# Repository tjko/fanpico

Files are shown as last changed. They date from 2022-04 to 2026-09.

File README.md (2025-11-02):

# Fanpico: Programmable PWM (PC) Fan Controller




<p><a href="https://certification.oshwa.org/us002599.html" title="Open Source Hardware Association Certificate">[OSHW] US002599 | Certified open source hardware | oshwa.org/cert</a></p>

Fanpico is a smart PWM (PC) fan controller based around [Raspberry Pi Pico](https://www.raspberrypi.com/documentation/microcontrollers/raspberry-pi-pico.html) (RP2040 MCU). Fanpico operates as standalone controller that can be configured and left running. It does not require any drivers and doesn't care what OS is being used. FanPico is an Open-source hardware (OSHW) project.

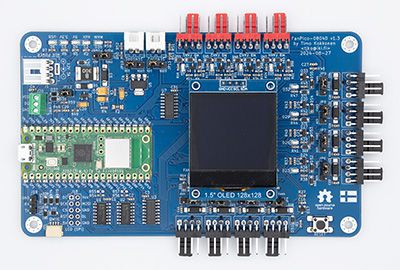
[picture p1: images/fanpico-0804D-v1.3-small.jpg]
FanPico-0804D

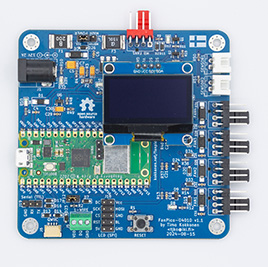
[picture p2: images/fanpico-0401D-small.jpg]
FanPico-0401D


## What is it for?
* Fanpico is for customizing fan "curves" to fine tune how your motherboard controlled fans run.
* Fine tuning fan speeds to easily balance airflow.
* Controlling fan based on temperature sensor input.
* Monitoring fan speeds and behaviour as well as monitoring what exactly motherboard is doing.
* Fanpico works also as standalong controller for other things than a PC, it's been used  controlling fans on 3D printers and on enclosed network equipment racks, etc..

## Features
* Controls up to 8 fans.
* Connect up to 4 motherboard fan outputs.
* Connect up to 2 remote temperature probes (plus onboard "ambient" temperature sensor).
* Support for [1-Wire Temperature sensors](https://github.com/tjko/fanpico/wiki/1%E2%80%90Wire-Temperature-Sensors-with-FanPico) (up to 8 sensors)
* Support for [I2C Temperature sensors](https://github.com/tjko/fanpico/wiki/I2C-Temperature-Sensors-with-FanPico) (up to 8 sensors)
* [OLED](https://github.com/tjko/fanpico/wiki/OLED-(I2C)-Display-Support) and [LCD](https://github.com/tjko/fanpico/wiki/LCD-(SPI)-Panel-Connection) display support (boards where model name ends with "D").
* Can be powered from motherboard fan outputs or using auxiliary power connector (4-Pin Floppy or DC Barrel jack connector).
* Ability to define custom fan "curves" for each fan.
* Ability to provide custom tachometer (fan RPM) output signal back to motherboard.
* Support for Locked Rotor (Alarm) signal fans (allows using regular tachometer fans with system expecting Locked Rotor Alarm fans and vice versa).
* Control fans from any motherboard PWM signal or from temperature sensors.
* OS Independent, no drivers or software needed.
* Configuration stored on the device itself (in the flash memory).
* SCPI "like" programming interface (see [Command Reference](commands.md))
* Monitor each fan and motherboard output signals as well as temperatures.
* [WiFi support](https://github.com/tjko/fanpico/wiki/FanPico-Network-Interface) if opting to mount Pico W on the board.
  * [HTTP server](https://github.com/tjko/fanpico/wiki/Fanpico-HTTP-Server) with TLS (HTTPS) support.
  * [MQTT client](https://github.com/tjko/fanpico/wiki/FanPico-MQTT-Tutorial) with TLS support for logging data and to receive commands.
  * [Home Assistant](https://github.com/tjko/fanpico/wiki/FanPico-Home-Assistant-(MQTT-Discovery)-Support) support using MQTT Discovery feature.
  * Telnet server for configuration and monitoring.
  * [SSH server](https://github.com/tjko/fanpico/wiki/Fanpico-Using-SSH-Server) for configuration and monitoring (experimental).
  * [SNMP Agent](https://github.com/tjko/fanpico/wiki/SNMP-Agent-Usage) for monitoring.

### Interfaces

* Serial "Console". Primary method for configuring/monitoring FanPico units is via (USB) Serial console (some units also have 3.3V TTL Serial connection).
* Desktop application (that polls FanPico using SCPI commands over the console connection): [FanPico Monitor](https://github.com/tjko/fanpico-monitor)
* Web Interface (available when using _Pico W_) over WiFi

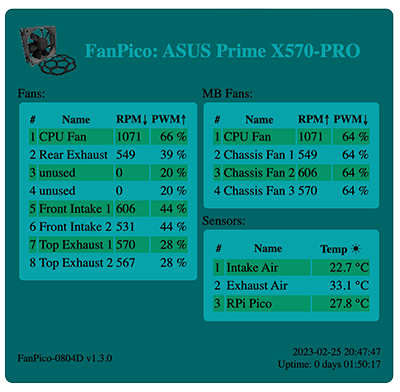
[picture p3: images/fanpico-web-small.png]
FanPico
   

For more documentation check [FanPico Wiki](https://github.com/tjko/fanpico/wiki)

## Sponsors
I would like to thank following sponsors, who have helped FanPico project:

* PCBWay

## Where can I get one?
Currently Fanpico is available as a DIY project.
Check discussion forums for places to purchase Kits or PCBs: [Places to Purchase FanPico](https://github.com/tjko/fanpico/discussions/12)

(Instructions for building the kit are in [FanPico Wiki](https://github.com/tjko/fanpico/wiki))

However, if there is sufficient interest, then ready-made units may be made available for sale.
If you'd be interested in purchasing FanPico pease indicate your interest here: [FanPico Forum](https://github.com/tjko/fanpico/discussions/9)

### DIY Option
You can upload the Kerber files (found under boards directory) to your favorite PCB maker website and get your boards produced in matter of days.
Component list (BOM or bill of materials) is found under boards directory as well along with the electrical schematics.

NOTE, check [discussions forum](https://github.com/tjko/fanpico/discussions/) for giveaways for free PCBs.

### Review Units
If you are member of press (or YouTuber) and would like to review/test Fanpico. Please contact me via email.

## How Can I help?
* Build your own FanPico and provide feedback, suggestions (see discussion forums).
* If you're into electronics new/improved board designs are most welcome.
* If you're into programming:
  - Create cool (desktop) program that allows easily configuring FanPico boards (with ability to "draw" fan curves, etc..) and to monitor Fan statuses.
  - Help improve the firmware.
* If you're into graphics (or web) design:
  - Help create cool (but lightweight) web interface
  - Create better logo for FanPico
* As this is Open (Source) Hardware Project, if you like to build (and sell) assembled boards or DIY kits, you'd be most welcome...
* You can always donate (and get your name added to the Sponsors section, if you so wish).

## Hardware
Fanpico is Open Source Hardware, reference design is provided for the "0804" model (8 fan outputs and 4 motherboard fan inputs), and "0804D" model that adds OLED display support (hence the "D" suffix).

Additional models with different combinations of fan inputs/outputs could be easily designed (takining into account limitations of Raspberry Pi Pico I/O limits). New and improved PCB models/designs are most welcome.

Model "0840D" with (with right-angle connectors and DC power connector):

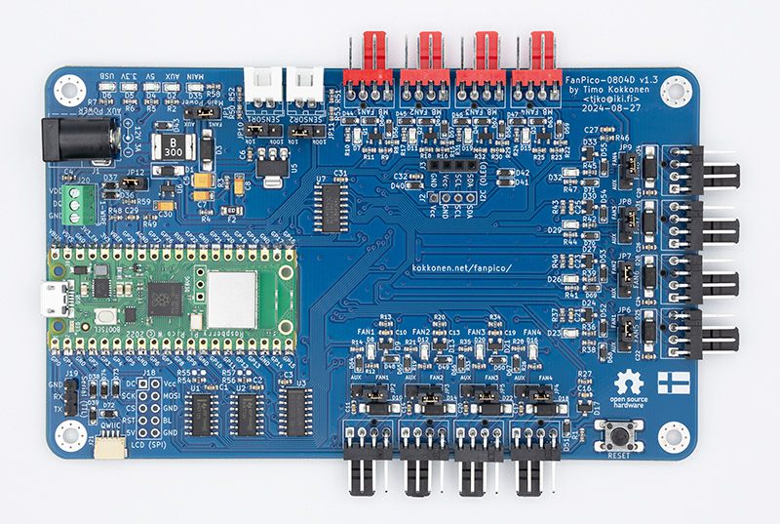
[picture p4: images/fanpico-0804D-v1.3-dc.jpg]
Fanpico-0804D


Model "0804" without display (with straight connectors):

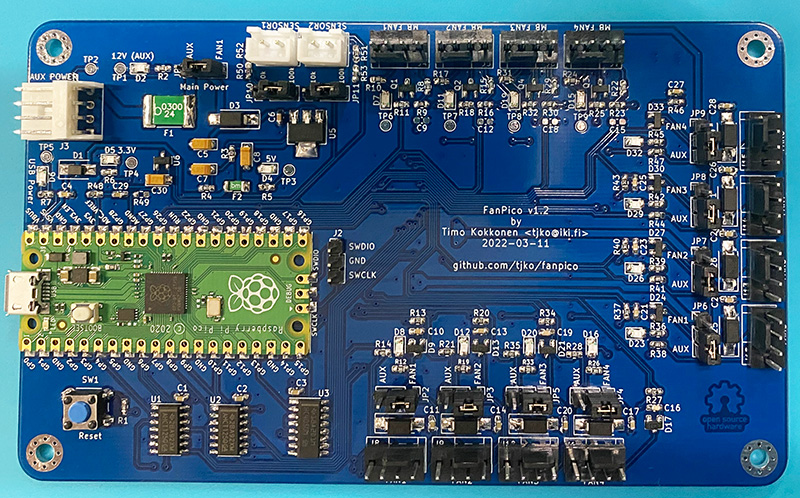
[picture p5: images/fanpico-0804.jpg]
Fanpico-0804


### Hardware Design
Fanpico (reference design) utilizes all available I/O pins on a Raspberry Pi Pico.
* Fan PWM outputs are driven by the Pico's PWM hardware.
* Motherboard Fan PWM inputs are read using Pico's PWM hardware.
* Tacho signal output (for motherboard connectors) is generated using Pico's PIO hardware, providing extremely stable tachometer signal.
* Tacho signal inputs (from fans) are read differently in model 0804 and 0804D:
  - 0804: signals are read using GPIO interrupts, measuring all fans simultaneously by counting number of pulses received over a period of time.
  - 0804D: signals are read through multiplexer measuring one fan at a time, by measuring pulse length.
* Temperature readings are done using ADC, with help of a accurrate 3V voltage reference (LM4040). Any NTC (10k or 100k) thermistors can be used as themperature sensors.
* Each FAN output has jumper to select whether fan gets its power from associated MBFAN connector or from the AUX connector
* There is a jumper to select whether power the Fanpico itself from MBFAN1 or AUX connector.

To help design and test Fanpico couple other projects were born:
* [Tiny PicoProbe](https://github.com/tjko/tiny-picoprobe/) - tiny PicoProbe implementation.
* [Fan Test Adapter](https://github.com/tjko/fan-test-adapter/) - adapter to help simulate motherboard fan outputs.

Projects based on FanPico firmware:
* [BrickPico](https://github.com/tjko/brickpico/) - (LEGO) LED Light Kit Controller.

### Models (PCB designs)
Currently following models are available:

|Model|Fans (Outputs)|MB Fan (Inputs)|External Temperature Sensors|Display|Notes|
|-----|---|---|---|---|-----|
|[FANPICO-0804](boards/fanpico-0804/)|8|4|2|N|First publicly available board (reference design).|
|[FANPICO-0804D](boards/fanpico-0804D/)|8|4|2|Y|Support for OLED (128x64 or 128x128) displays|
|[FANPICO-0401D](boards/fanpico-0401D/)|4|1|2|Y|Adds QWIIC and 1-Wire connectors.|
|[FANPICO-0200](boards/fanpico-0200/)|2|0|2|Y|OLED display supported via QWIIC connector. PCB under development.

(all boards have one additional 'on-board' temperature sensor on the RP2040 MCU itself)

Models ending with "D" have connector to attach OLED display module to see 'real-time' status of fans and temperatures.

OLED panel directly mounted on the PCB:

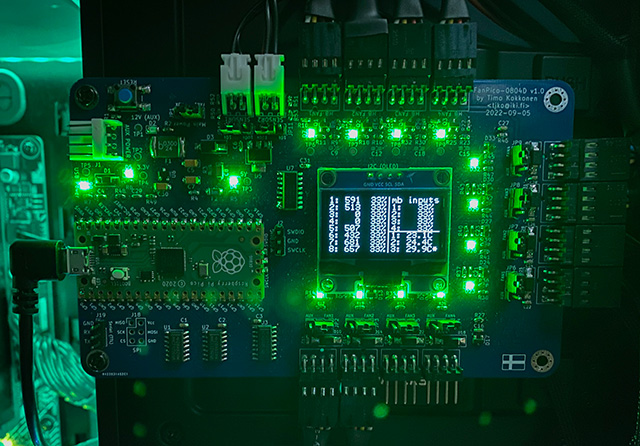
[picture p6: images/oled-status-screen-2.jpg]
FanPico OLED Display


LCD Panel attached via a short cable:

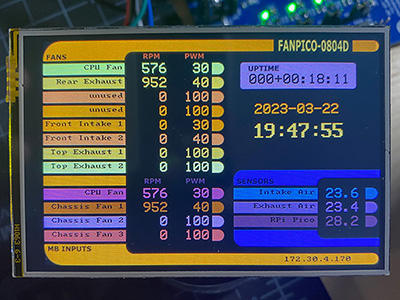
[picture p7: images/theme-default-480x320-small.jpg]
FanPico LCD Display


#### Accessory Boards (PCB designs)
Following accessories are available:

|Model|Info|
|-----|----|
|[OLED-Adapter](boards/oled-adapter/)|Mounting adapter for OLED boards with different pinouts.|
|[Power-Board](boards/power-board/)|Adapter for using high-power fans with FanPico.|

## Firmware
Firmware is developed in C using the Pico SDK. Pre-compiled firmware is released when there is new major features or bug fixes.

Latest pre-compiled firmware image can be found here: [Releases](https://github.com/tjko/fanpico/releases)

To get latest firmware with latest updates/fixes you must compile the firmware from the sources.

### Installing firmware image
Firmware can be installed via the built-in UF2 bootloader on the Raspberry Pi Pico or using the debug header with Picoprobe, etc...

#### Selecting Right Firmware to use
Each release (zip file) contains multiple different firmware files.
Make sure to select firmware for the board you're using and for the pico model ("pico_w" if using Pico W).

Firmware file names have format: fanpico-<board_model>-<pico_model>.uf2
```
fanpico-0401D-pico.uf2
fanpico-0401D-pico_w.uf2
fanpico-0804-pico.uf2
fanpico-0804-pico_w.uf2
fanpico-0804D-pico.uf2
fanpico-0804D-pico_w.uf2
```

#### Upgrading Firmware
Firmware upgrade steps:
* Boot Pico into UF2 bootloader. This can be done in two ways:
  1)  Press and hold "bootsel" button and then press and release "reset" button.
  2)  Issue command: SYS:UPGRADE
* Copy firmware file to the USB mass storage device that appears.
* As soon as firmware copy is complete, Pico will reboot and run the fanpico firmware.

### Building Firmware Images

Raspberry Pi Pico C/C++ SDK is required for compiling the firmware:

#### Requirements / Dependencies
* [Raspberry Pi Pico C/C++ SDK](https://www.raspberrypi.com/documentation/microcontrollers/c_sdk.html)
* [cJSON](https://github.com/DaveGamble/cJSON)
* [pico-lfs](https://github.com/tjko/pico-lfs)
* [ss_oled-lib](https://github.com/tjko/ss_oled-lib)
* [bb_spi_lcd-lib](https://github.com/tjko/bb_spi_lcd-lib)
* [libb64](https://github.com/libb64/libb64)
* [pico-telnetd](https://github.com/tjko/pico-telnetd)
* [pico-1wire-lib](https://github.com/tjko/pico-1wire-lib)
* [pico-sensor-lib](https://github.com/tjko/pico-sensor-lib)
* [wolfSSL](https://github.com/wolfSSL/wolfssl)
* [wolfSSH](https://github.com/wolfSSL/wolfssh)
* [pico-sshd](https://github.com/tjko/pico-sshd)

##### Install Pico SDK
Pico SDK must be installed working before you can compile fanpico.

Instructions on installing Pico SDK see: [Getting started with Raspberry Pi Pico](https://datasheets.raspberrypi.com/pico/getting-started-with-pico.pdf)

(Make sure PICO_SDK_PATH environment variable is set)

##### Downloading sources

Create some directory for building fanpico ('src' used in this example):
```
$ mkdir src
$ cd src
$ git clone https://github.com/tjko/fanpico.git
$ git submodule update --init --recursive
```

##### Building fanpico firmware

To build fanpico firmware, first create a build directory:
```
$ cd fanpico
$ mkdir build
```

Select which board to build firmware for (default is "0804") and which Pico is to be used (default is "pico"):
```
$ cd build
$ cmake -DFANPICO_BOARD=0804D -DPICO_BOARD=pico_w ..
```

Then compile fanpico:
```
$ make -j
```

After successful compile you should see firmware binary in the build directory:
subdirectory:

```
$ ls *.uf2
fanpico.uf2
```

If you have picotool installed you can check the firmware image information:
```
$ picotool info -a fanpico.uf2
File fanpico.uf2 family ID 'rp2040':

Program Information
 name:              fanpico
 version:           1.7.6
 web site:          https://kokkonen.net/fanpico/
 description:       FanPico-0804D - Smart PWM Fan Controller
 features:          USB stdin / stdout
 boot settings:     bootdelay = 0
                    safemode = 0
 binary start:      0x10000000
 binary end:        0x1012edc0
 embedded drive:    0x101c0000-0x10200000 (256K): littlefs

Fixed Pin Information
 0:                 TX (Serial) / MISO (SPI)
 1:                 RX (Serial) / CS (SPI)
 2:                 SDA (I2C) / SCK (SPI)
 3:                 SCL (I2C) / MOSI (SPI)
 4:                 Fan1 PWM signal (output)
 5:                 Fan2 PWM signal (output)
 6:                 Fan3 PWM signal (output)
 7:                 Fan4 PWM signal (output)
 8:                 Fan5 PWM signal (output)
 9:                 Fan6 PWM signal (output)
 10:                Fan7 PWM signal (output)
 11:                Fan8 PWM signal (output)
 12:                MB Fan1 tacho signal (output)
 13:                MB Fan1 PWM signal (input)
 14:                MB Fan2 tacho signal (output)
 15:                MB Fan2 PWM signal (input)
 16:                MB Fan3 tacho signal (output)
 17:                MB Fan3 PWM signal (input)
 18:                MB Fan4 tacho signal (output)
 19:                MB Fan4 PWM signal (input)
 20:                Multiplexer S2 (output)
 21:                Multiplexer S1 (output)
 22:                Multiplexer S0 (output)
 26:                Multiplexer A [tacho signal] (input)
 27:                Temperature Sensor1 (input)
 28:                Temperature Sensor2 (input)

Build Information
 sdk version:       2.1.1
 pico_board:        pico_w
 boot2_name:        boot2_w25q080
 build date:        Jul 10 2025
 build attributes:  Release

Metadata Blocks
 none
```

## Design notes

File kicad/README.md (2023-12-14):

# KiCad Symbols and Footprints used in FanPico PCBs

Non-standard symbols and footprints used in FanPico and BrickPico PCB designs:

- Symbols: fanpico.kicad_sym
- Footprints: FanPico.pretty

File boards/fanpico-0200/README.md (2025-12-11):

# FANPICO-0200 PCB

PCB Size: 81.0mm x 60.0mm

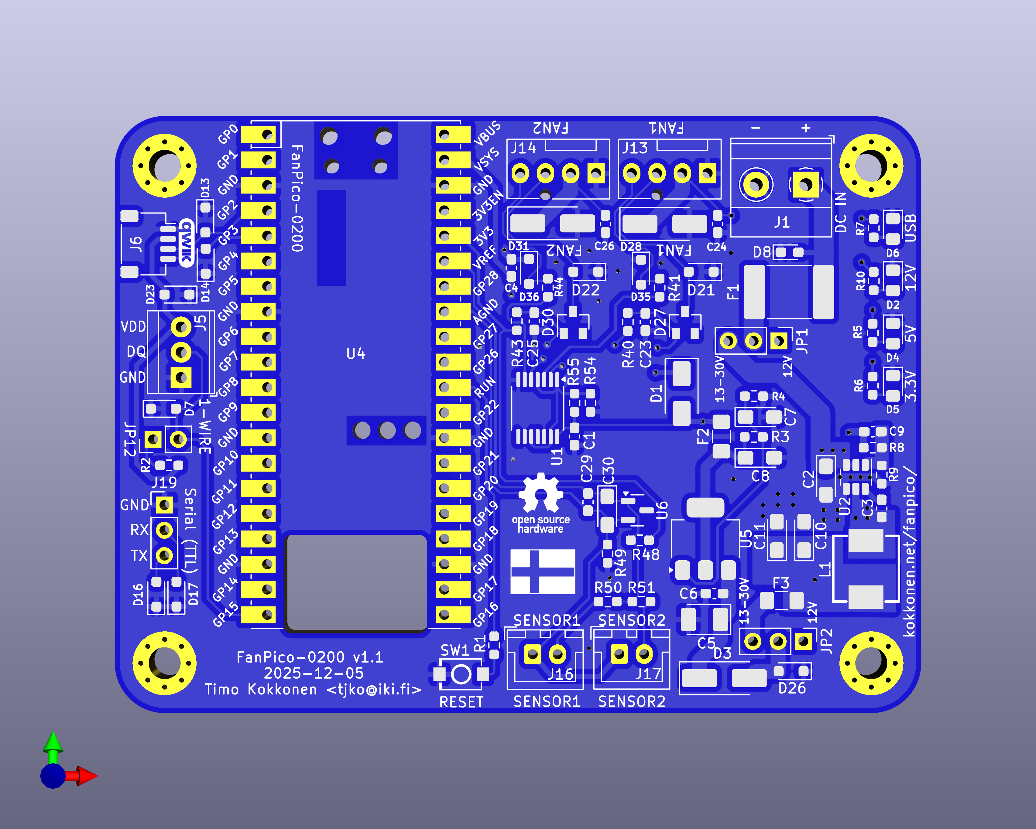
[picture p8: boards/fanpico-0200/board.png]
PCB Render


## Change Log

v1.1
- Add fuse (F3) to prevent pulling too much current through the buck regulator.
- Move sensor connectors footprints (J16 & J17) slightly away from board edge
  to allow better fitment of right angle connectors.

v1.0
- First Prototye

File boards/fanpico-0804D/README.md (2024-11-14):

# FANPICO-0804D PCB

PCB Size: 135mm x 81.5mm

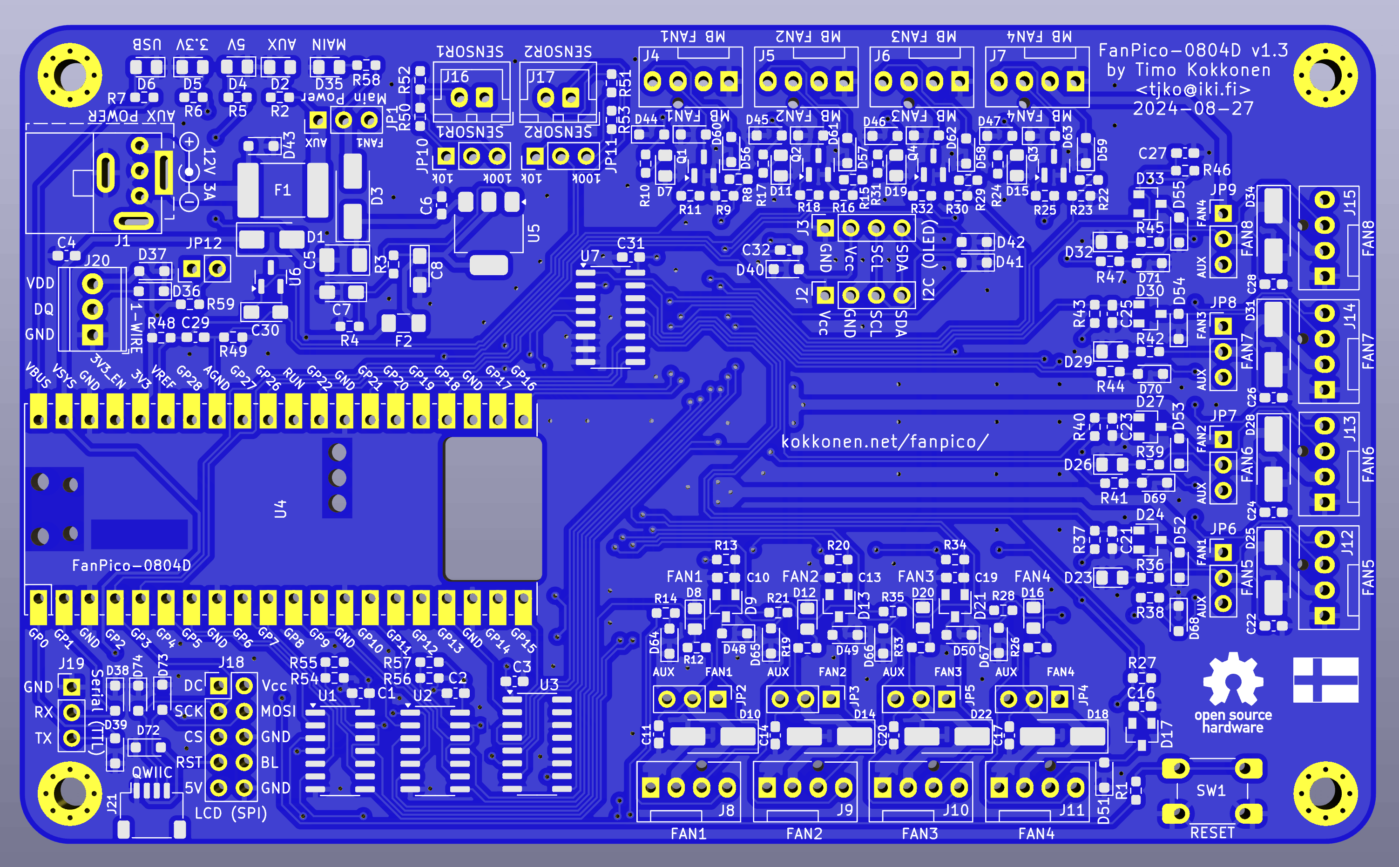
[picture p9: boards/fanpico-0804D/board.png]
PCB Render


## Change Log

v1.3
- Add QWIIC connector (to simplify connecting I2C sensors).
- Add 1-Wire connector
- Change J1 to a combination footprint (allows mounting either Floppy or DC connector).
- Slightly improved ESD protection (TVS diodes added for most connectors)

v1.2c
- Add support for using either SN74AHCT125 or SN74AHCT126 (as U1 and U2).

v1.2b
- C5 was not derated correctly. Replace with 25V part for proper derating.

v1.2
- Add alternate OLED display header with alternate pinout (J2)
- Change J18 header to 2x5 pins (with extra pins often needed for SPI displays)
- Change pull-ups to pull-downs on PWM signal pins on MBFAN inputs.

v1.1
- Add support for direct mounting either Pico or Pico W
- Remove unused footprints
- Fix errata from v1.0
- Errata:
  - JP11 Silkscreen incorrect: 10K and 100K labels should be the otherway around.

v1.0 
- First Prototye
- Based on 0804 v1.3, with added OLED (I2c) display module support
- Errata:
  - U7 pin 7 (VEE) should be grounded.
    Workaround: add solder bridge between pins 7 & 8.

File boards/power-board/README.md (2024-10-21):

# FanPico PowerBoard

PCB Size: 65mm x 65mm

This is a small power injector board for powering high-power fans, that require
too much current to be connected directly into Fan ports on FanPico boards.

Board is meant to sit in between FanPico Fan ports and the high-power fans.

Fan Power Supply (12V) should be connected into one of the power inputs (only on input
should be used at a time). Fans should be connected into "FAN" ports on the board, and
cables connected from "FANCTRL" ports into FanPico (FAN ports) for fan control/monitoring.

Note, "FANCTRL" ports do not have voltage pin connected, so no power is drawn from the fan controller.

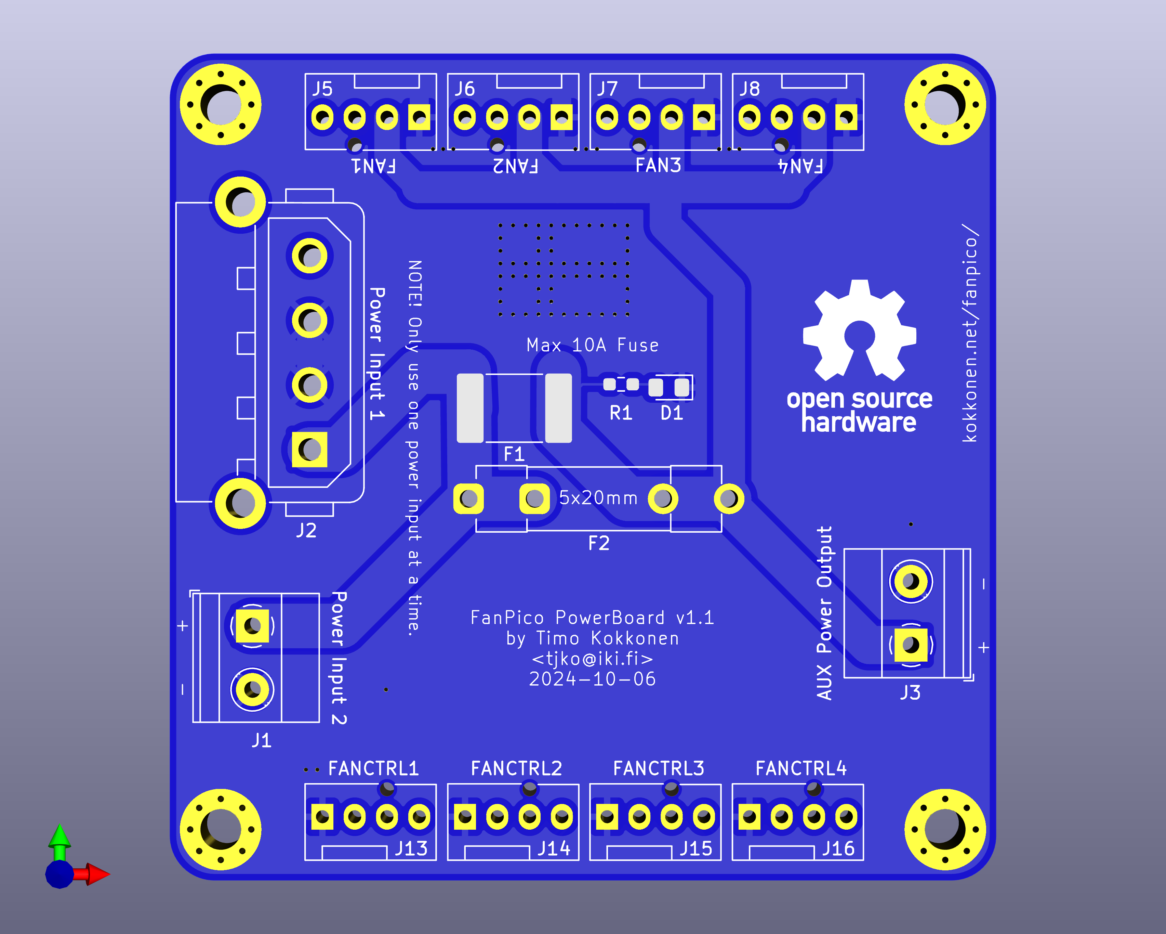
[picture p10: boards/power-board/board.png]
PCB Render


## Assembly note
Install either F1 (polyfuse) or F2 (fuse holder for 5x20mm fuses), not both.

## Manufacturing note
PCB should have at least 2oz copper thickness for adequate current carrying capacity.

## Change Log

- v1.1
  - Make tracks thicker for ground pins on power connectors.
- v1.0 
  - Initial revision.

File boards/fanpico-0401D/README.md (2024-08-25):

# FANPICO-0401D PCB

PCB Size: 82.5mm x 81.5mm

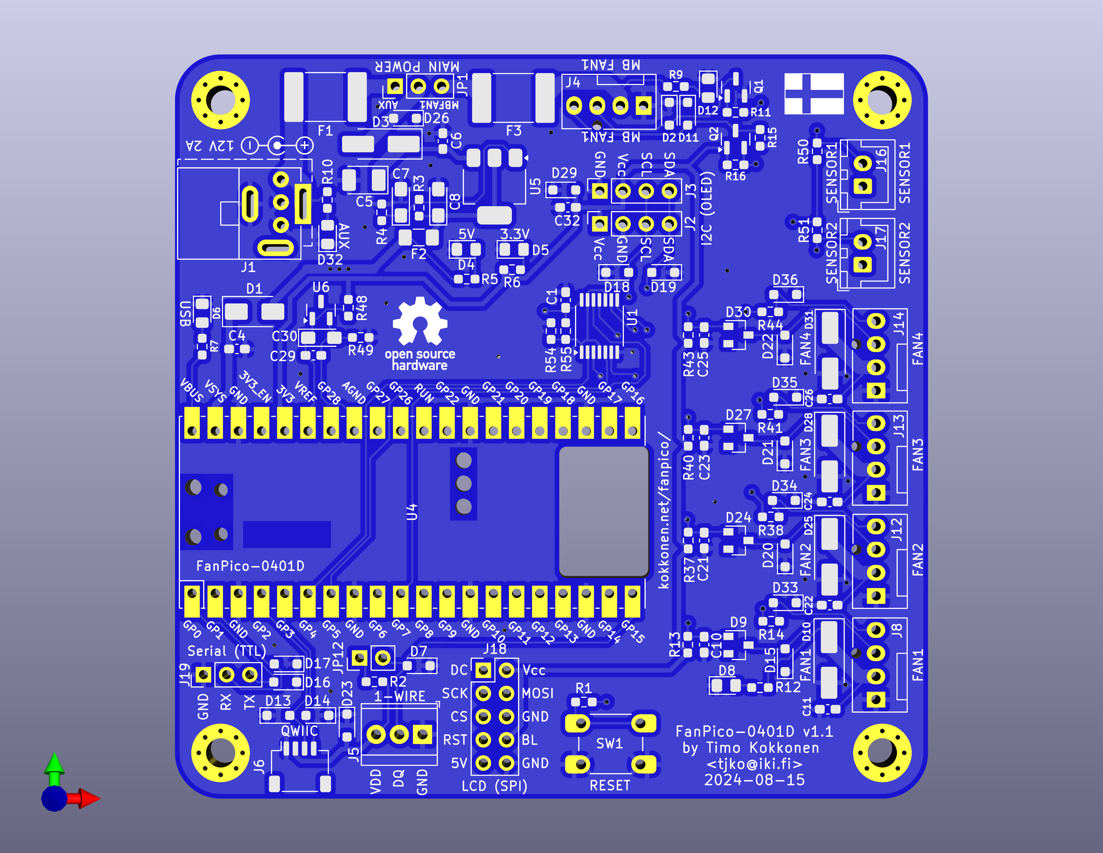
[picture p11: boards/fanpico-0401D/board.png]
PCB Render


## Change Log

v1.1
- Add built-in pull-up for 1-Wire bus (selectable with jumper J12)
- Improved ESD protection
- Change MBFAN1 tachometer input to have pull-down (instead of pull-up)
- Other minor updates

v1.0
- First Prototye
- Based on 0804D v1.2c
- Combination footprint for AUX power connector (4-Pin Floppy and DC Barrel connector)
- New connectors: QWIIC, 1-Wire
- Errata:
  - R8 resistor had incorrect value, use 0 ohm (instead of originally specified 1k ohm).

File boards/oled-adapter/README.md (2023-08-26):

# FanPico-OLED-Adapter

PCB Size: 25mm x 14.5mm

This is small adapter for making it easier to mount larger 1.5" 128x128 pixel OLED modules.

J1 is meant to be connected to FanPico J3 connector, then connecting OLED module to J2 (or J3).

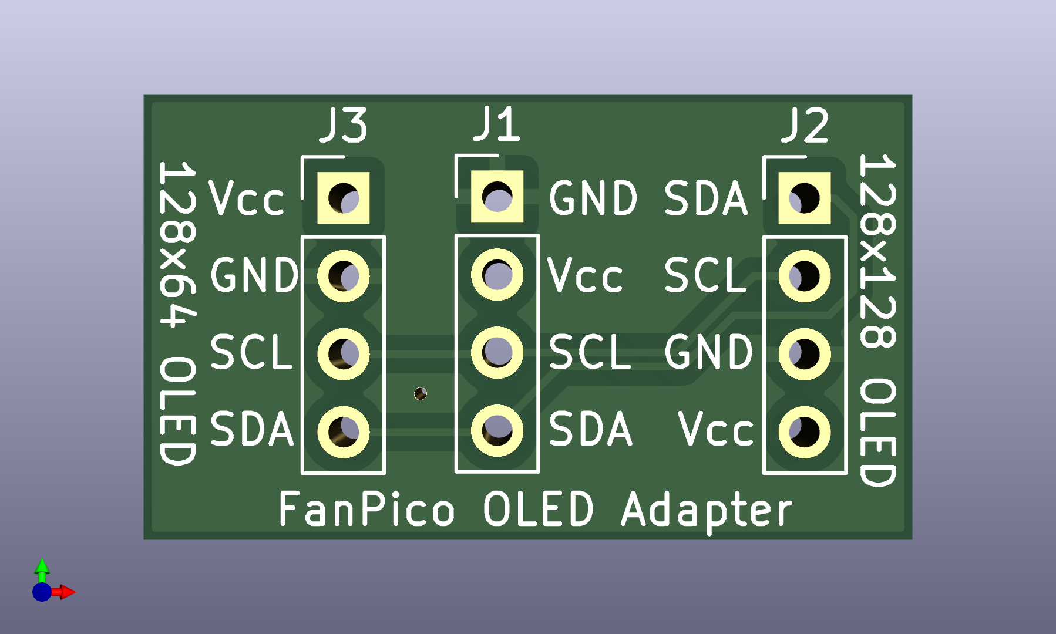
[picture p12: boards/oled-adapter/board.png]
PCB Render


## Change Log

v1.0 
- Initial revision.

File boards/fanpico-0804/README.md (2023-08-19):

# FANPICO-0804 PCB

PCB Size: 135mm x 81.5mm

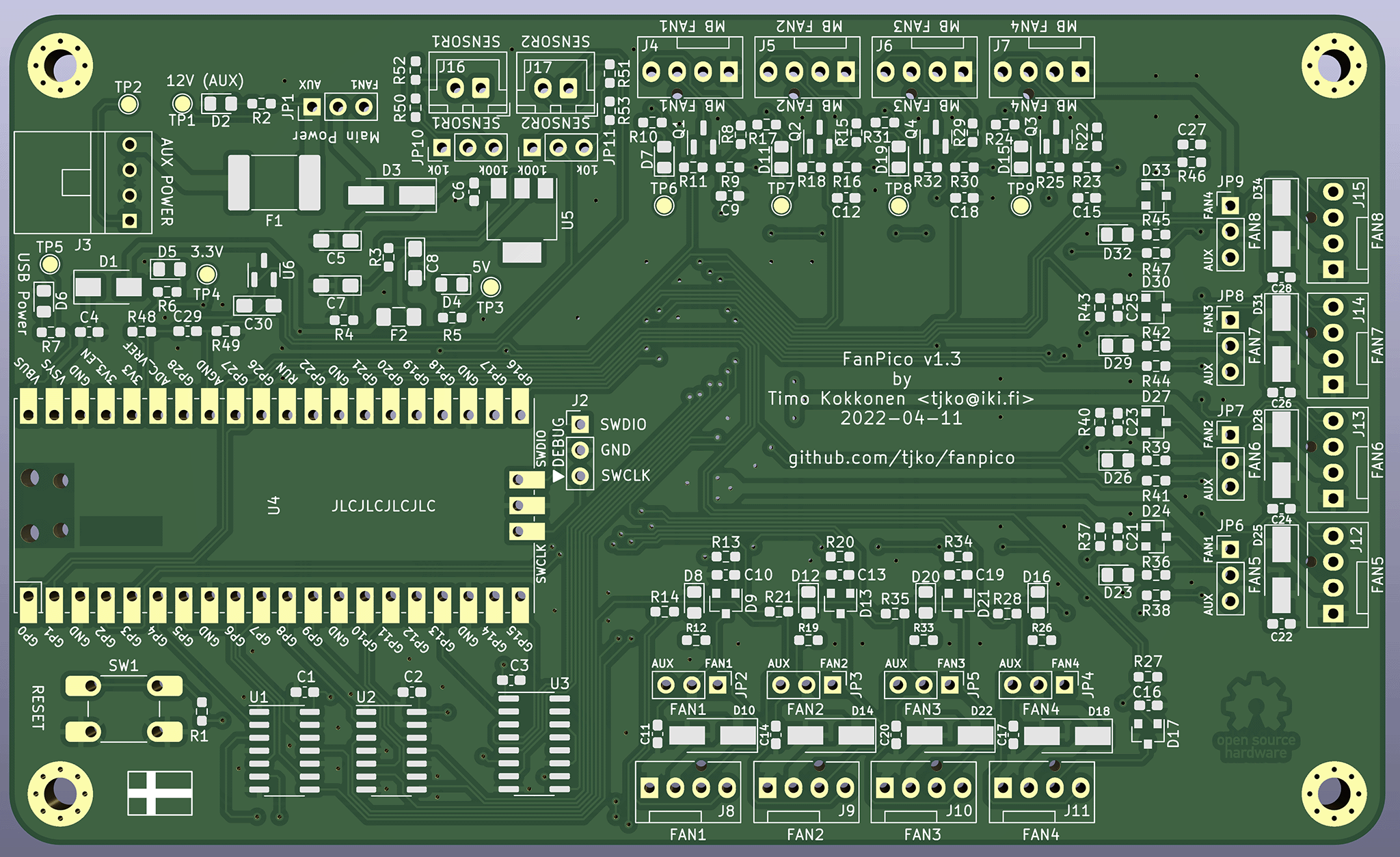
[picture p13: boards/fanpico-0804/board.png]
PCB Render


## Change Log

v1.3
- Rotate fan and temperature sensor connectors 180 degrees to allow use of right-angle connectors
- Fix silksreen labels for JP11 (SENSOR2)
- Update SW1 pad to support both SMD and through-hole 6mm switches.
- Errata:
  - C5 incorrectly derated. Use 25V (or higher) rated tantalum.

v1.2
- Change sensor connectors to JST XH (2.5mm)
- Add jumper to select between 10k / 100k NTC thermistor
- Errata:
  - JP11 (SENSOR2 Thermistor type jumper) silk screen wrong. Workaround is to swap R51 and R53 during assembly.

v1.1
- Add two connectors for Temperature Sensors
- Fixed Floppy Connector pinout
- Remove TTL Serial output

v1.0 
- First Prototye

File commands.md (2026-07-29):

# Fanpico: Command Reference
Fanpico uses "SCPI like" command set. Command syntax should be mostly SCPI and IEE488.2 compliant,
to make it easier to control and configure Fanpico units.

## Command Set
Fanpico supports following commands:

* [*IDN?](#idn)
* [*RST](#rst)
* [CONFigure?](#configure)
* [CONFigure:SAVe](#configuresave)
* [CONFigure:Read?](#configureread)
* [CONFigure:UPLOAD](#configureupload)
* [CONFigure:DELete](#configuredelete)
* [CONFigure:FANx:NAME](#configurefanxname)
* [CONFigure:FANx:NAME?](#configurefanxname-1)
* [CONFigure:FANx:MINpwm](#configurefanxminpwm)
* [CONFigure:FANx:MINpwm?](#configurefanxminpwm-1)
* [CONFigure:FANx:MAXpwm](#configurefanxmaxpwm)
* [CONFigure:FANx:MAXpwm?](#configurefanxmaxpwm-1)
* [CONFigure:FANx:PWMCoeff](#configurefanxpwmcoeff)
* [CONFigure:FANx:PWMCoeff?](#configurefanxpwmcoeff-1)
* [CONFigure:FANx:RPMFactor](#configurefanxrpmfactor)
* [CONFigure:FANx:RPMFactor?](#configurefanxrpmfactor-1)
* [CONFigure:FANx:RPMMOde](#configurefanxrpmmode)
* [CONFigure:FANx:RPMMOde?](#configurefanxrpmmode-1)
* [CONFigure:FANx:SOUrce](#configurefanxsource)
* [CONFigure:FANx:SOUrce?](#configurefanxsource-1)
* [CONFigure:FANx:PWMMap](#configurefanxpwmmap)
* [CONFigure:FANx:PWMMap?](#configurefanxpwmmap-1)
* [CONFigure:FANx:FILTER](#configurefanxfilter)
* [CONFigure:FANx:FILTER?](#configurefanxfilter-1)
* [CONFigure:FANx:HYSTeresis:TACho](#configurefanxhysteresistacho)
* [CONFigure:FANx:HYSTeresis:TACho?](#configurefanxhysteresistacho-1)
* [CONFigure:FANx:HYSTeresis:PWM](#configurefanxhysteresispwm)
* [CONFigure:FANx:HYSTeresis:PWM?](#configurefanxhysteresispwm-1)
* [CONFigure:MBFANx:NAME](#configurembfanxname)
* [CONFigure:MBFANx:NAME?](#configurembfanxname-1)
* [CONFigure:MBFANx:MINrpm](#configurembfanxminrpm)
* [CONFigure:MBFANx:MINrpm?](#configurembfanxminrpm-1)
* [CONFigure:MBFANx:MAXrpm](#configurembfanxmaxrpm)
* [CONFigure:MBFANx:MAXrpm?](#configurembfanxmaxrpm-1)
* [CONFigure:MBFANx:RPMCoeff](#configurembfanxrpmcoeff)
* [CONFigure:MBFANx:RPMCoeff?](#configurembfanxrpmcoeff-1)
* [CONFigure:MBFANx:RPMFactor](#configurembfanxrpmfactor)
* [CONFigure:MBFANx:RPMFactor?](#configurembfanxrpmfactor-1)
* [CONFigure:MBFANx:RPMMOde](#configurembfanxrpmmode)
* [CONFigure:MBFANx:RPMMOde?](#configurembfanxrpmmode-1)
* [CONFigure:MBFANx:SOUrce](#configurembfanxsource)
* [CONFigure:MBFANx:SOUrce?](#configurembfanxsource-1)
* [CONFigure:MBFANx:RPMMap](#configurembfanxrpmmap)
* [CONFigure:MBFANx:RPMMap?](#configurembfanxrpmmap-1)
* [CONFigure:MBFANx:FILTER](#configurembfanxfilter)
* [CONFigure:MBFANx:FILTER?](#configurembfanxfilter-1)
* [CONFigure:SENSORx:NAME](#configuresensorxname)
* [CONFigure:SENSORx:NAME?](#configuresensorxname-1)
* [CONFigure:SENSORx:TEMPOffset](#configuresensorxtempoffset)
* [CONFigure:SENSORx:TEMPOffset?](#configuresensorxtempoffset-1)
* [CONFigure:SENSORx:TEMPCoeff](#configuresensorxtempcoeff)
* [CONFigure:SENSORx:TEMPCoeff?](#configuresensorxtempcoeff-1)
* [CONFigure:SENSORx:TEMPMap](#configuresensorxtempmap)
* [CONFigure:SENSORx:TEMPMap?](#configuresensorxtempmap-1)
* [CONFigure:SENSORx:BETAcoeff](#configuresensorxbetacoeff)
* [CONFigure:SENSORx:BETAcoeff?](#configuresensorxbetacoeff-1)
* [CONFigure:SENSORx:THERmistor](#configuresensorxthermistor)
* [CONFigure:SENSORx:THERmistor?](#configuresensorxthermistor-1)
* [CONFigure:SENSORx:TEMPNominal](#configuresensorxtempnominal)
* [CONFigure:SENSORx:TEMPNominal?](#configuresensorxtempnominal-1)
* [CONFigure:SENSORx:FILTER](#configuresensorxfilter)
* [CONFigure:SENSORx:FILTER?](#configuresensorxfilter-1)
* [CONFigure:VSENSORS?](#configurevsensors)
* [CONFigure:VSENSORS:SOUrces?](#configurevsensorssources)
* [CONFigure:VSENSORx:NAME](#configurevsensorxname)
* [CONFigure:VSENSORx:NAME?](#configurevsensorxname-1)
* [CONFigure:VSENSORx:SOUrce](#configurevsensorxsource)
* [CONFigure:VSENSORx:SOUrce?](#configurevsensorxsource-1)
* [CONFigure:VSENSORx:TEMPMap](#configurevsensorxtempmap)
* [CONFigure:VSENSORx:TEMPMap?](#configurevsensorxtempmap-1)
* [CONFigure:VSENSORx:FILTER](#configurevsensorxfilter)
* [CONFigure:VSENSORx:FILTER?](#configurevsensorxfilter-1)
* [EXIT](#exit)
* [MEASure:Read?](#measureread)
* [MEASure:FANx?](#measurefanx)
* [MEASure:FANx:Read?](#measurefanxread)
* [MEASure:FANx:RPM?](#measurefanxrpm)
* [MEASure:FANx:PWM?](#measurefanxpwm)
* [MEASure:FANx:TACho?](#measurefanxtacho)
* [MEASure:MBFANx?](#measurembfanx)
* [MEASure:MBFANx:Read?](#measurembfanxread)
* [MEASure:MBFANx:RPM?](#measurembfanxrpm)
* [MEASure:MBFANx:PWM?](#measurembfanxpwm)
* [MEASure:MBFANx:TACho?](#measurembfanxtacho)
* [MEASure:SENSORx?](#measuresensorx)
* [MEASure:SENSORx:Read?](#measuresensorxread)
* [MEASure:SENSORx:TEMP?](#measuresensorxtemp)
* [MEASure:VSENSORS?](#measurevsensors)
* [MEASure:VSENSORx?](#measurevsensorx)
* [MEASure:VSENSORx:HUMidity?](#measurevsensorxhumidity)
* [MEASure:VSENSORx:PREssure?](#measurevsensorxpressure)
* [MEASure:VSENSORx:Read?](#measurevsensorxread)
* [MEASure:VSENSORx:TEMP?](#measurevsensorxtemp)
* [Read?](#read)
* [SYStem:ERRor?](#systemerror)
* [SYStem:BOARD?](#systemboard)
* [SYStem:DEBug](#systemdebug)
* [SYStem:DEBug?](#systemdebug-1)
* [SYStem:LOG](#systemlog)
* [SYStem:LOG?](#systemlog-1)
* [SYStem:SYSLOG](#systemsyslog)
* [SYStem:SYSLOG?](#systemsyslog-1)
* [SYStem:DISPlay](#systemdisplay)
* [SYStem:DISPlay?](#systemdisplay)
* [SYStem:DISPlay:LAYOUTR](#systemdisplaylayoutr)
* [SYStem:DISPlay:LAYOUTR?](#systemdisplaylayoutr-1)
* [SYStem:DISPlay:LOGO](#systemdisplaylogo)
* [SYStem:DISPlay:LOGO?](#systemdisplaylogo-1)
* [SYStem:DISPlay:THEMe](#systemdisplaytheme)
* [SYStem:DISPlay:THEMe?](#systemdisplaytheme-1)
* [SYStem:ECHO](#systemecho)
* [SYStem:ECHO?](#systemecho)
* [SYStem:FANS?](#systemfans)
* [SYStem:FLASH?](#systemflash)
* [SYStem:HTTP:SERVer](#systemhttpserver)
* [SYStem:HTTP:SERVer?](#systemhttpserver-1)
* [SYStem:HTTP:PORT](#systemhttpport)
* [SYStem:HTTP:PORT?](#systemhttpport-1)
* [SYStem:HTTP:TLSPORT](#systemhttptlsport)
* [SYStem:HTTP:TLSPORT?](#systemhttptlsport-1)
* [SYStem:HTTP:MASK:FAN](#systemmqttmaskfan)
* [SYStem:HTTP:MASK:FAN?](#systemmqttmaskfan-1)
* [SYStem:HTTP:MASK:MBFAN](#systemmqttmaskmbfan)
* [SYStem:HTTP:MASK:MBFAN?](#systemmqttmaskmbfan-1)
* [SYStem:HTTP:MASK:SENSOR](#systemmqttmasksensor)
* [SYStem:HTTP:MASK:SENSOR?](#systemmqttmasksensor-1)
* [SYStem:HTTP:MASK:VSENSOR](#systemmqttmaskvsensor)
* [SYStem:HTTP:MASK:VSENSOR?](#systemmqttmaskvsensor-1)
* [SYStem:I2C?](#systemi2c)
* [SYStem:I2C:SCAN?](#systemi2cscan)
* [SYStem:I2C:SPEED](#systemi2cspeed)
* [SYStem:I2C:SPEED?](#systemi2cspeed?)
* [SYStem:IFCONFIG?](#systemifconfig)
* [SYStem:LED](#systemled)
* [SYStem:LED?](#systemled-1)
* [SYStem:LFS?](#systemlfs)
* [SYStem:LFS:COPY](#systemlfscopy)
* [SYStem:LFS:DELete](#systemlfsdelete)
* [SYStem:LFS:DIR?](#systemlfsdir)
* [SYStem:LFS:FORMAT](#systemlfsformat)
* [SYStem:LFS:REName](#systemlfsrename)
* [SYStem:MBFANS?](#systemmbfans)
* [SYStem:MEM](#systemmem)
* [SYStem:MEM?](#systemmem-1)
* [SYStem:MQTT:SERVer](#systemmqttserver)
* [SYStem:MQTT:SERVer?](#systemmqttserver-1)
* [SYStem:MQTT:PORT](#systemmqttport)
* [SYStem:MQTT:PORT?](#systemmqttport-1)
* [SYStem:MQTT:USER](#systemmqttuser)
* [SYStem:MQTT:USER?](#systemmqttuser-1)
* [SYStem:MQTT:PASSword](#systemmqttpassword)
* [SYStem:MQTT:PASSword?](#systemmqttpassword-1)
* [SYStem:MQTT:SCPI](#systemmqttscpi)
* [SYStem:MQTT:SCPI?](#systemmqttscpi-1)
* [SYStem:MQTT:TLS](#systemmqtttls)
* [SYStem:MQTT:TLS?](#systemmqtttls-1)
* [SYStem:MQTT:HA:DISCovery](#systemmqtthadiscovery)
* [SYStem:MQTT:HA:DISCcovery?](#systemmqtthadiscovery-1)
* [SYStem:MQTT:INTerval:STATUS](#systemmqttintervalstatus)
* [SYStem:MQTT:INTerval:STATUS?](#systemmqttintervalstatus-1)
* [SYStem:MQTT:INTerval:TEMP](#systemmqttintervaltemp)
* [SYStem:MQTT:INTerval:TEMP?](#systemmqttintervaltemp-1)
* [SYStem:MQTT:INTerval:VSENsor](#systemmqttintervalvsensor)
* [SYStem:MQTT:INTerval:VSENsor?](#systemmqttintervalvsensor-1)
* [SYStem:MQTT:INTerval:RPM](#systemmqttintervalrpm)
* [SYStem:MQTT:INTerval:RPM?](#systemmqttintervalrpm-1)
* [SYStem:MQTT:INTerval:PWM](#systemmqttintervalpwm)
* [SYStem:MQTT:INTerval:PWM?](#systemmqttintervalpwm-1)
* [SYStem:MQTT:MASK:TEMP](#systemmqttmasktemp)
* [SYStem:MQTT:MASK:TEMP?](#systemmqttmasktemp-1)
* [SYStem:MQTT:MASK:VTEMP](#systemmqttmaskvtemp)
* [SYStem:MQTT:MASK:VTEMP?](#systemmqttmaskvtemp-1)
* [SYStem:MQTT:MASK:VHUMidity](#systemmqttmaskvhumidity)
* [SYStem:MQTT:MASK:VHUMidity?](#systemmqttmaskvhumidity-1)
* [SYStem:MQTT:MASK:VPREssure](#systemmqttmaskvpressure)
* [SYStem:MQTT:MASK:VPREssure?](#systemmqttmaskvpressure-1)
* [SYStem:MQTT:MASK:FANRPM](#systemmqttmaskfanrpm)
* [SYStem:MQTT:MASK:FANRPM?](#systemmqttmaskfanrpm-1)
* [SYStem:MQTT:MASK:FANPWM](#systemmqttmaskfanpwm)
* [SYStem:MQTT:MASK:FANPWM?](#systemmqttmaskfanpwm-1)
* [SYStem:MQTT:MASK:MBFANRPM](#systemmqttmaskmbfanrpm)
* [SYStem:MQTT:MASK:MBFANRPM?](#systemmqttmaskmbfanrpm-1)
* [SYStem:MQTT:MASK:MBFANPWM](#systemmqttmaskmbfanpwm)
* [SYStem:MQTT:MASK:MBFANPWM?](#systemmqttmaskmbfanpwm-1)
* [SYStem:MQTT:TOPIC:STATus](#systemmqtttopicstatus)
* [SYStem:MQTT:TOPIC:STATus?](#systemmqtttopicstatus-1)
* [SYStem:MQTT:TOPIC:COMMand](#systemmqtttopiccommand)
* [SYStem:MQTT:TOPIC:COMMand?](#systemmqtttopiccommand-1)
* [SYStem:MQTT:TOPIC:RESPonse](#systemmqtttopicresponse)
* [SYStem:MQTT:TOPIC:RESPonse?](#systemmqttopicresponse-1)
* [SYStem:MQTT:TOPIC:TEMP](#systemmqtttopictemp)
* [SYStem:MQTT:TOPIC:TEMP?](#systemmqttopictemp-1)
* [SYStem:MQTT:TOPIC:VTEMP](#systemmqtttopicvtemp)
* [SYStem:MQTT:TOPIC:VTEMP?](#systemmqttopicvtemp-1)
* [SYStem:MQTT:TOPIC:VHUMidity](#systemmqtttopicvhumidity)
* [SYStem:MQTT:TOPIC:VHUMidity?](#systemmqttopicvhumidity-1)
* [SYStem:MQTT:TOPIC:VPREssure](#systemmqtttopicvpressure)
* [SYStem:MQTT:TOPIC:VPREssure?](#systemmqttopicvpressure-1)
* [SYStem:MQTT:TOPIC:FANRPM](#systemmqtttopicfanrpm)
* [SYStem:MQTT:TOPIC:FANRPM?](#systemmqttopicfanrpm-1)
* [SYStem:MQTT:TOPIC:FANPWM](#systemmqtttopicfanpwm)
* [SYStem:MQTT:TOPIC:FANPWM?](#systemmqttopicfanpwm-1)
* [SYStem:MQTT:TOPIC:MBFANRPM](#systemmqtttopicmbfanrpm)
* [SYStem:MQTT:TOPIC:MBFANRPM?](#systemmqttopicmbfanrpm-1)
* [SYStem:MQTT:TOPIC:MBFANPWM](#systemmqtttopicmbfanpwm)
* [SYStem:MQTT:TOPIC:MBFANPWM?](#systemmqttopicmbfanpwm-1)
* [SYStem:NAME](#systemname)
* [SYStem:NAME?](#systemname-1)
* [SYStem:ONEWIRE](#systemonewire)
* [SYStem:ONEWIRE?](#systemonewire-1)
* [SYStem:ONEWIRE:SENSORS?](#systemonewiresensors)
* [SYStem:SENSORS?](#systemsensors)
* [SYStem:SERIAL](#systemserial)
* [SYStem:SERIAL?](#systemserial-1)
* [SYStem:SNMP:AGENT](#systemsnmpagent)
* [SYStem:SNMP:AGENT?](#systemsnmpagent-1)
* [SYStem:SNMP:COMmunity](#systemsnmpcommunity)
* [SYStem:SNMP:COMmunity?](#systemsnmpcommunity-1)
* [SYStem:SNMP:CONTact](#systemsnmpcontact)
* [SYStem:SNMP:CONTact?](#systemsnmpcontact-1)
* [SYStem:SNMP:LOCAtion](#systemsnmplocation)
* [SYStem:SNMP:LOCAtion?](#systemsnmplocation-1)
* [SYStem:SNMP:WRITecommunity](#systemsnmpwritecommunity)
* [SYStem:SNMP:WRITecommunity?](#systemsnmpwritecommunity-1)
* [SYStem:SNMP:TRAPs:AUTH](#systemsnmptrapsauth)
* [SYStem:SNMP:TRAPs:AUTH?](#systemsnmptrapsauth-1)
* [SYStem:SNMP:TRAPs:COMMunity](#systemsnmptrapscommunity)
* [SYStem:SNMP:TRAPs:COMMunity?](#systemsnmptrapscommunity-1)
* [SYStem:SNMP:TRAPs:DESTination](#systemsnmptrapsdestination)
* [SYStem:SNMP:TRAPs:DESTination?](#systemsnmptrapsdestination-1)
* [SYStem:SPI](#systemspi)
* [SYStem:SPI?](#systemspi-1)
* [SYStem:SSH:SERVer](#systemsshserver)
* [SYStem:SSH:SERVer?](#systemsshserver-1)
* [SYStem:SSH:ACLs](#systemsshacls)
* [SYStem:SSH:ACLs?](#systemsshacls-1)
* [SYStem:SSH:AUTH](#systemsshauth)
* [SYStem:SSH:AUTH?](#systemsshauth-1)
* [SYStem:SSH:PORT](#systemsshport)
* [SYStem:SSH:PORT?](#systemsshport-1)
* [SYStem:SSH:USER](#systemsshuser)
* [SYStem:SSH:USER?](#systemsshuser-1)
* [SYStem:SSH:PASSword](#systemsshpassword)
* [SYStem:SSH:PASSword?](#systemsshpassword-1)
* [SYStem:SSH:KEY?](#systemsshkey)
* [SYStem:SSH:KEY:CREate](#systemsshkeycreate)
* [SYStem:SSH:KEY:DELete](#systemsshkeydelete)
* [SYStem:SSH:KEY:LIST?](#systemsshkeylist)
* [SYStem:SSH:PUBKEY?](#systemsshpubkey)
* [SYStem:SSH:PUBKEY:ADD](#systemsshpubkeyadd)
* [SYStem:SSH:PUBKEY:DELete](#systemsshpubkeydelete)
* [SYStem:SSH:PUBKEY:LIST?](#systemsshpubkeylist)
* [SYStem:TELNET:SERVer](#systemtelnetserver)
* [SYStem:TELNET:SERVer?](#systemtelnetserver-1)
* [SYStem:TELNET:ACLs](#systemtelnetacls)
* [SYStem:TELNET:ACLs?](#systemtelnetacls-1)
* [SYStem:TELNET:AUTH](#systemtelnetauth)
* [SYStem:TELNET:AUTH?](#systemtelnetauth-1)
* [SYStem:TELNET:PORT](#systemtelnetport)
* [SYStem:TELNET:PORT?](#systemtelnetport-1)
* [SYStem:TELNET:RAWmode](#systemtelnetrawmode)
* [SYStem:TELNET:RAWmode?](#systemtelnetrawmode-1)
* [SYStem:TELNET:USER](#systemtelnetuser)
* [SYStem:TELNET:USER?](#systemtelnetuser-1)
* [SYStem:TELNET:PASSword](#systemtelnetpassword)
* [SYStem:TELNET:PASSword?](#systemtelnetpassword-1)
* [SYStem:TIME](#systemtime)
* [SYStem:TIME?](#systemtime-1)
* [SYStem:TIMEZONE](#systemtimezone)
* [SYStem:TIMEZONE?](#systemtimezone-1)
* [SYStem:TLS:CERT](#systemtlscert)
* [SYStem:TLS:CERT?](#systemtlscert-1)
* [SYStem:TLS:PKEY](#systemtlspkey)
* [SYStem:TLS:PKEY?](#systemtlspkey-1)
* [SYStem:UPTIme?](#systemuptime)
* [SYStem:UPGRADE](#systemupgrade)
* [SYStem:VERsion?](#systemversion)
* [SYStem:VREFadc](#systemvrefadc)
* [SYStem:VREFadc?](#systemvrefadc-1)
* [SYStem:VSENSORS?](#systemvsensors)
* [SYStem:WIFI?](#systemwifi)
* [SYStem:WIFI:AUTHmode](#systemwifiauthmode)
* [SYStem:WIFI:AUTHmode?](#systemwifiauthmode-1)
* [SYStem:WIFI:COUntry](#systemwificountry)
* [SYStem:WIFI:COUntry?](#systemwificountry-1)
* [SYStem:WIFI:HOSTname](#systemwifihostname)
* [SYStem:WIFI:HOSTname?](#systemwifihostname-1)
* [SYStem:WIFI:INFO?](#systemwifiinfo)
* [SYStem:WIFI:IPaddress](#systemwifiipaddress)
* [SYStem:WIFI:IPaddress?](#systemwifiipaddress-1)
* [SYStem:WIFI:MODE](#systemwifimode)
* [SYStem:WIFI:MODE?](#systemwifimode-1)
* [SYStem:WIFI:NETMASK](#systemwifinetmask)
* [SYStem:WIFI:NETMASK?](#systemwifinetmask-1)
* [SYStem:WIFI:GATEWAY](#systemwifigateway)
* [SYStem:WIFI:GATEWAY?](#systemwifigateway-1)
* [SYStem:WIFI:DNS](#systemwifidns)
* [SYStem:WIFI:DNS?](#systemwifidns-1)
* [SYStem:WIFI:NTPClient](#systemwifintpclient)
* [SYStem:WIFI:NTPClient?](#systemwifintpclient-1)
* [SYStem:WIFI:NTP](#systemwifintp)
* [SYStem:WIFI:NTP?](#systemwifintp-1)
* [SYStem:WIFI:SYSLOGClient](#systemwifisyslogclient)
* [SYStem:WIFI:SYSLOGClient?](#systemwifisyslogclient-1)
* [SYStem:WIFI:SYSLOG](#systemwifisyslog)
* [SYStem:WIFI:SYSLOG?](#systemwifisyslog-1)
* [SYStem:WIFI:MAC?](#systemwifimac)
* [SYStem:WIFI:REJOIN](#systemwifirejoin)
* [SYStem:WIFI:SSID](#systemwifissid)
* [SYStem:WIFI:SSID?](#systemwifissid-1)
* [SYStem:WIFI:STATus?](#systemwifistatus)
* [SYStem:WIFI:STATS?](#systemwifistats)
* [SYStem:WIFI:PASSword](#systemwifipassword)
* [SYStem:WIFI:PASSword?](#systemwifipassword-1)
* [WHO?](#who)
* [WRIte:VSENSORx](#writevsensorx)

Additionally unit will respond to following standard SCPI commands to provide compatibility in case some program
unconditionally will send these:
* *CLS
* *ESE
* *ESE?
* *ESR?
* *OPC
* *OPC?
* *SRE
* *SRE?
* *STB?
* *TST?
* *WAI

### Common Commands

#### *IDN?
Identify device. This returns string that contains following fields:
```
<manufacturer>,<model number>,<serial number>,<firmware version>
```

Example:
```
*IDN?
TJKO Industries,FANPICO-0804,e660c0d1c768a330,1.0
```

#### *RST
Reset unit. This triggers Fanpico to perform (warm) reboot.

```
*RST
```

### CONFigure:
Commands for configuring the device settings.

#### CONFigure?
  Display current configuration in JSON format.
  Same as CONFigure:Read?

  Example:
  ```
  CONF?
  ```

#### CONFigure:SAVe
Save current configuration into flash memory.

Example:
```
CONF:SAVE
```

#### CONFigure:Read?
Display (backup) current configuration in JSON format.

Example:
```
CONF:READ?
```

#### CONFigure:UPLOAD?
Upload (previous backed up) configuration in JSON format.
This command waits up to 10 seconds for the configuration to be uploaded.

End of configuration is signified by empty line (after end of configuration).
(To cancel uploading configuration, two empty lines can be sent.)

Example:
```
CONF:UPLOAD
Paste FanPico configuration in JSON format:
[Received 5937 bytes]

Clearing config...
Loading config...
[   112.487339][0] Config version: fanpico-config-v1
Configuration successfully loaded.
```

#### CONFigure:DELete
Delete current configuration saved into flash. After unit has been reset it will be using default configuration.

Example:
```
CONF:DEL
*RST
```

### CONFigure:FANx Commands
FANx commands are used to configure specific fan output port.
Where x is a number from 1 to 8.

For example:
```
CONFIGURE:FAN8:NAME Exhaust Fan 2
```

#### CONFigure:FANx:NAME
Set name for fan (output) port.

For example:
```
CONF:FAN1:NAME CPU Fan 1
```

#### CONFigure:FANx:NAME?
Query name of a fan (output) port.

For example:
```
CONF:FAN1:NAME?
CPU Fan 1
```

#### CONFigure:FANx:HYSTeresis:TACho
<mark>new: release v1.6.4</mark>  \
Set the hysteresis threshold for a given tacho fan (output) port. 

For example:
```
CONF:FAN1:HYST:TACHO 1.5
```

#### CONFigure:FANx:HYSTeresis:TACho?
<mark>new: release v1.6.4</mark>  \
Query the hysteresis threshold for a given tacho fan (output) port.

For example:
```
CONF:FAN1:HYST:TACHO?
1.500000
```

#### CONFigure:FANx:HYSTeresis:PWM
<mark>new: release v1.6.4</mark>  \
Set the hysteresis threshold for a given tacho PWM (output) port.

For example:
```
CONF:FAN1:HYST:PWM 2.0
```

#### CONFigure:FANx:HYSTereris:PWM?
<mark>new: release v1.6.4</mark>  \
Query the hysteresis threshold for a given PWM fan (output) port.

For example:
```
CONF:FAN1:HYST:PWM?
2.000000
```

#### CONFigure:FANx:MINpwm
Set absolute minimum PWM duty cycle (%) for given fan port.
This can be used to make sure that fan always sees a minimum
duty cycle (overriding the normal fan signal).

Default: 0 %

Example: Set minimum PWM duty cycle to 20% for FAN1
```
CONF:FAN1:MIN 20
```

#### CONFigure:FANx:MINpwm?
Query current minimum PWM duty cycle (%) configured on a fan port.

Example:
```
CONF:FAN1:MIN?
20
```

#### CONFigure:FANx:MAXpwm
Set absolute maximum PWM duty cycle (%) for given fan port.
This can be used to make sure that fan never sees higher duty cycle
than given value (overriding the normal fan signal).

Default: 100 %

Example: Set maximum PWM duty cycle to 95% for FAN1
```
CONF:FAN1:MAX 95
```

#### CONFigure:FANx:MAXpwm?
Query current maximum PWM duty cycle (%) configured on a fan port.

Example:
```
CONF:FAN1:MAX?
95
```

#### CONFigure:FANx:PWMCoeff
Set scaling factor for the fan PWM (output) signal.
This is applied to the PWM duty cycle before MAXpwm and MINpwm limits are applied.

Default: 1.0

Example: Set FAN6 to run 20% slower than signal its configured to follow.
```
CONF:FAN6:PWMC 0.8
```

#### CONFigure:FANx:PWMCoeff?
Query current PWM duty cycle (%) scaling factor configured on a fan port.

Example:
```
CONF:FAN6:PWMC?
0.8
```

#### CONFigure:FANx:RPMFactor
Set number of pulses fan generates per one revolution.
This is used to calculate RPM measurement based on the Tachometer
signal from the fan.

PC Fans typically send 2 pulses per revolution (per Intel specifications).

Default: 2

Example: Adjust factor for a fan that produces 4 pulses per revolution
```
CONF:FAN1:RPMF 4
```

#### CONFigure:FANx:RPMFactor?
Query current RPM conversion factor configured on a fan port.

Example:
```
CONF:FAN1:RPMF?
4
```

#### CONFigure:FANx:RPMMOde
Configure what type tachometer signal fan is sending.

Supported signal types:

Signal Type|Setting|Notes
-----------|-------|-----
Tachometer|TACHO|Fan is sending normal tachometer pulses to indicate rotation speed.
Locked Rotor (Alarm)|LRA,low_rpm,high_rpm|Parameters indicate mapping from LRA to RPM speeds (corresponding to LOW and HIGH signal received from the fan).

Default: TACHO  (fan sends standard tachometer pulses to indicate rotation speed)

Example: Fan is not sending tachometer signal but Locked Rotor Alam signal (LRA) on tachometer pin (we map HIGH signal to mean 0 RPM and LOW signal to mean 2000 RPM)
```
CONF:FAN1:RPMMODE LRA,2000,0
```

Example: Fan is sending Locked Rotor (Alarm) signal (LRA), where polarity in reversed (LOW signal indicates lockup/failure):
```
CONF:FAN2:RPMMODE LRA,0,2000
```

#### CONFigure:FANx:RPMMOde?
Query current RPM tachometer signal settings for a fan.

Example:
```
CONF:FAN1:RPMMODE?
TACHO
CONF:FAN2:RPMMODE?
LRA,0,2000
```

#### CONFigure:FANx:SOUrce
Configure source for the PWM signal of a fan.

Source types:
* MBFAN (set fan to follow duty cycle from motherboard fan port)
* SENSOR (set fan to follow temperature based duty cycle)
* VSENSOR (set fan to follow temperature based duty cycle)
* FAN (set fan to follow another FAN output duty cycle)
* FIXED (set fan to run on fixed duty cycle)

Defaults:
FAN|SOURCE
---|------
1|MBFAN,1
2|MBFAN,2
3|MBFAN,3
4|MBFAN,4
5|MBFAN,1
6|MBFAN,2
7|MBFAN,3
8|MBFAN,4

Example: Set FAN 5 to follow temperature sensor 2
```
CONF:FAN5:SOURCE SENSOR,2
```

Example: Set FAN 6 to run always at fixed 50% duty cycle (speed)
```
CONF:FAN6:SOURCE FIXED,50
```

#### CONFigure:FANx:SOUrce?
Query current signal source for a fan.

Command returns response in following format:
```
source_type,source_no
```

Example:
```
CONF:FAN1:SOU?
mbfan,1
```

#### CONFigure:FANx:PWMMap
Set mapping (curve) for the PWM duty cycle signal.
This can be used to customize how fan will respond to input signal it receives.

Mapping is specified with up to 32 points (that can be plotted as a curve)
that map the relation of the input signal (x value) to output signal (y value).
Mapping should at minimum include that start and end points of the expected input signal
(typically 0 and 100).

Default mapping is linear (1:1) mapping:
x|y
-|-
0|0
100|100

Example: Configure Fan to run at 20% duty cycle between 0-20% input signal then scale
linearly to 100% by the time input signal reaches 100%
```
CONF:FAN1:PWMMAP 0,20,20,20,100,100
```

Example: Assuming we have "fancy" PWM fan that actually stops spinning on 0% duty cycle.
And we want fan not run until input PWM signal duty cycle is over 30%, and we want fan to reach
full speed by the time 90% duty signal is received.
```
CONF:FAN1:PWMMAP 0,0,30,0,90,100
```

#### CONFigure:FANx:PWMMap?
Display currently active mapping (curve) for the PWM duty signal.

Mapping is displayed as comma separated list of values:
```
x_1,y_1,x_2,y_2,...,x_n,y_n
```

For example:
```
CONF:FAN1:PWMMAP?
0,0,100,100
```

#### CONFigure:FANx:FILTER
Configure filter to be applied for the PWM signal controlling the fan.

Filter|Description|Arguments|Argument Descriptions|Example|Notes
------|-----------|---------|---------------------|-------|-------
none|No Filter|||
lossypeak|Lossy Peak Detector|decay_rate,decay_start_delay|* decay rate [points per second] (valid values: > 0.0)<br>* decay start delay [seconds] (valid values: >= 0.0)|CONF:FAN1:FILTER lossypeak,1.5,15|This can be useful for smoothing out erratic (CPU Fan) PWM signal from motherboard.
sma|Simple Moving Average|window_size|* window size [points] (valid range: 2..32)<br>|CONF:FAN1:FILTER sma,10|This can be useful for filtering temperature sensor signal.

For example:
```
CONF:FAN1:FILTER lossypeak,1.0,30
```

#### CONFigure:FANx:FILTER?
Display currently active (PWM) filter for the fan.

Format: filter,arg_1,arg_2,...arg_n

For example:
```
CONF:FAN1:FILTER?
lossypeak,1.0,30.0
```

### CONFigure:MBFANx Commands
MBFANx commands are used to configure specific motherboard fan input port.
Where x is a number from 1 to 4.

For example:
```
CONF:MBFAN4:NAME Water Pump
```

#### CONFigure:MBFANx:NAME
Set name for motherboard fan (input) port.

For example:
```
CONF:MBFAN1:NAME CPU Fan
```

#### CONFigure:MBFANx:NAME?
Query name of a motherboard fan (input) port.

For example:
```
CONF:MBFAN1:NAME?
CPU Fan
```

#### CONFigure:MBFANx:MINrpm
Set absolute minimum RPM value for given motherboard fan port.
This can be used to make sure motherboard never sees "fan"
running slower than this value (even if fan is not running at all).

Default: 0

Example: Set minimum RPM (sent to motheboard) to be at least 500
```
CONF:MBFAN1:MIN 500
```

#### CONFigure:MBFANx:MINrpm?
Query current minimum RPM value configured on a motherboard fan port.

Example:
```
CONF:MBFAN1:MIN?
500
```

#### CONFigure:MBFANx:MAXrpm
Set absolute maximum value for given motherboard fan port.
This can be used to make sure motherboard never sees "fan"
running ffaster than this value.

Default: 10000

Example: Set maximum RPM value motheboard can see to 3000
```
CONF:MBFAN1:MAX 3000
```

#### CONFigure:MBFANx:MAXrpm?
Query current maximum RPM value configured on a motherboard fan port.

Example:
```
CONF:MBFAN1:MAX?
3000
```

#### CONFigure:MBFANx:RPMCoeff
Set scaling factor for the motherboard fan Tachometer (output) signal.
This is applied to adjust the output RPM (and tachometer signal frequency).

Default: 1.0

Example: Scale the MBFAN4 port Tachometer (RPM) values to be 20% higher than input.
```
CONF:MBFAN4:RPMC 1.2
```

#### CONFigure:MBFANx:RPMCoeff?
Query current TAchometer (RPM) scaling factor configured on a motherboard fan port.

Example:
```
CONF:MBFAN6:RPMC?
1.2
```

#### CONFigure:MBFANx:RPMFactor
Set number of pulses per one revolution in the generated tachometer signal (going out to motherboard).
This is mainly only needed if using Fanpico with something else than PC motherboard, that expects
to see tachometer signal from Fans that produce other than the default 2 pulses per revolution.

Default: 2

Example: Adjust factor for (emulating fan that produces 4 pulses per revolution
```
CONF:MBFAN1:RPMF 4
```

#### CONFigure:MBFANx:RPMFactor?
Query current RPM conversion factor configured on a motherboard fan port.

Example:
```
CONF:MBFAN1:RPMF?
4
```

#### CONFigure:MBFANx:RPMMOde
Configure what type tachometer signal is sent (out) to motherboard.

Supported signal types:

Signal Type|Setting|Notes
-----------|-------|-----
Tachometer|TACHO|Send normal tachometer pulses to indicate rotation speed.
Locked Rotor (Alarm)|LRA,threshold_rpm,locked_signal_level|Send Locked Rotor Alarm signal, when RPM is below threshold RPM speed send the indicated signal (HIGH or LOW).

*NOTE!* When changing RPM Mode for a mbfan (output), system must be reset before change takes effect.

Default: TACHO  (standard tachometer pulses to indicate rotation speed)

Example: Send 'HIGH' Locked Rotor (Alarm) signal (when RPM drops below 200 RPM)
```
CONF:MBFAN1:RPMMODE LRA,200,HIGH
```

Example: Send 'LOW' Locked Rotor (Alarm) signal (when RPM drops below 500 RPM)
```
CONF:MBFAN2:RPMMODE LRA,500,LOW
```

#### CONFigure:FANx:RPMMOde?
Query current RPM tachometer signal settings for a fan.

Example:
```
CONF:FAN1:RPMMODE?
TACHO
CONF:FAN2:RPMMODE?
LRA,0,2000
```

#### CONFigure:MBFANx:SOUrce
Configure source for the Tachometer (RPM) signal for a motheboard fan (output) port.

Source types:

Type|Parameters|Description|Example
----|----------|-----------|------
FAN|n|Return tachometer signal of a specified fan|FAN,1
FIXED|rpm|Return static tachometer signal at specified rpm|FIXED,1500
MIN|n1,n2,...|Return slowest FAN speed acros specified fans|MIN,2,7,8
MAX|n1,n2,...|Return fastest FAN speed acros specified fans|MAX,2,7,8
AVG|n1,n2,...|Return average FAN speed acros specified fans|AVG,2,7,8

Defaults:
MBFAN|SOURCE
---|------
1|FAN,1
2|FAN,2
3|FAN,3
4|FAN,4

Example: Set MBFAN 2 to follow Tachometer signal from FAN8
```
CONF:MBFAN2:SOURCE FAN,8
```

Example: Set MBFAN 4 to see fixed 1500 RPM tachometer signal
```
CONF:MBFAN4:SOURCE FIXED,1500
```

Example: Set MBFAN 1 to return slowest fan speed from FAN1, FAN2, and FAN3
```
CONF:MBFAN1:SOURCE MIN,1,2,3
```

#### CONFigure:MBFANx:SOUrce?
Query current signal source for a motherboar fan (Tachometer output).

Command returns response in following format:
```
source_type,source_no
```

Example:
```
CONF:MBFAN1:SOU?
fan,1
```

#### CONFigure:MBFANx:RPMMap
Set mapping (curve) for the Tachometer (RPM) output signal to motherboard.
This can be used to customize what motherboard sees as the "fan" RPM.

Mapping is specified with up to 32 points (that can be plotted as a curve)
that map the relation of the input signal (x value) to output signal (y value).
Mapping should at minimum include that start and end points of the expected input signal
(typically 0 and 100).

Default mapping is linear (1:1) mapping:
x|y
-|-
0|0
10000|10000

Example: Assuming we have configured FAN1 to only run above 30% PWM signal, but our
motherboard sets alarm when it doesn't detect fan running, we can provide 'fake' 500RPM
speed to the motherboard until fan is actually running at least 500 RPM...
```
CONF:MBFAN1:RPMMAP 0,500,500,500,10000,10000
```

#### CONFigure:MBFANx:RPMMap?
Display currently active mapping (curve) for the tachometer signal sent to motherboard
fan port.

Mapping is displayed as comma separated list of values:
```
x_1,y_1,x_2,y_2,...,x_n,y_n
```

For example:
```
CONF:MBFAN1:RPMMAP?
0,0,10000,10000
```

#### CONFigure:MBFANx:FILTER
Configure filter to be applied to the PWM signal received (from motheboard, etc.)

List of available filters can be found here: [Available Filters](#configurefanfilter)

By default, no filter is applied (filter is set to "none").

Example: Set filter for the input signal to "Lossy Peak Detector", that is often useful
with erratic PWM signals (like CPU Fan control signal on many motherboards).

```
CONF:MBFAN1:FILTER lossypeak,1.5,10
```

#### CONFigure:MBFANx:FILTER?
Display currently active filter for the input PWM signal.

Format: filter,arg_1,arg_2,...arg_n

For example:
```
CONF:MBFAN1:FILTER?
none,
```

### CONFigure:SENSORx Commands
SENSORx commands are used to configure specific (temperature) sensor.
Where x is a number from 1 to 3.

Sensor|Description
------|-----------
1|Thermistor connected to SENSOR1 connector.
2|Thermistor connected to SENSOR2 connector.
3|Internal temperature sensor on RP2040 (can be used for "Ambient" temperature measurementes as RP2040 doesn't heat up significantly).

For example:
```
CONF:SENSOR1:NAME Air Intake
```

#### CONFigure:SENSORx:NAME
Set name for temperature sensor.

For example:
```
CONF:SENSOR1:NAME Air Intake
```

#### CONFigure:SENSORx:NAME?
Query name of a temperature sensor.

For example:
```
CONF:SENSOR1:NAME?
Air Intake
```

#### CONFigure:SENSORx:TEMPOffset
Set offset that is applied to measured temperature.
This can be used as a grude calibration method by setting offset to
the difference of actual temperature vs. what sensor is reporting.

Default: 0.0

For example: Sensor is reporting 2.5 degrees "high", so set offset to -2.5:
```
CONF:SENSOR1:TEMPO -2.5
```

#### CONFigure:SENSORx:TEMPOffset?
Get the current temperature offset configured for the sensor.

For example:
```
CONF:SENSOR1:TEMPO?
-2.5
```

#### CONFigure:SENSORx:TEMPCoeff
Set coefficient that is used to multiply the (raw) temperature sensor reports.
This can be used to correct error in temperature measurements.

Default: 1.0

For example: Sensor is consistently reading 10% higher than actual temperature
```
CONF:SENSOR1:TEMPC 0.9
```

#### CONFigure:SENSORx:TEMPCoeff?
Get the current temperature coefficient configured for the sensor.

For example:
```
CONF:SENSOR1:TEMPC?
0.9
```

#### CONFigure:SENSORx:TEMPMap
Set mapping (curve) for converting temperature to PWM signal duty cycle (%).
This can be used to customize how temperature affects fan speed.

Mapping is specified with up to 32 points (that can be plotted as a curve)
that map the relation of the temperature (x value) to output PWM signal (y value).
Mapping should at minimum include that start and end points of the expected input signal.

Default mapping:
x (Temperature in C)|y (Fan Duty Cycle in %)
-|-
20|0
50|100

Example: Set Fan to start running at 20% duty cycle at 25C and to be full speed at 50C
```
CONF:SENSOR1:TEMPMAP 25,20,50,100
```

#### CONFigure:SENSORx:TEMPMap?
Display currently active mapping (curve) for convertin measured temperature
to PWM duty cycle (%) for the fan output signal.

Mapping is displayed as comma separated list of values:
```
x_1,y_1,x_2,y_2,...,x_n,y_n
```

For example:
```
CONF:SENSOR1:TEMPMAP?
20,0,50,10000
```

#### CONFigure:SENSORx:BETAcoeff
Set beta coefficient of thermistor used to measure temperature.
Typically thermistor beta coefficient is in the range 3000-4000.

Default: 3950

For example:
```
CONF:SENSOR1:BETA 3950
```

#### CONFigure:SENSORx:BETAcoeff?
Get the configured beta coefficient of the thermistor used to measure temperature.

For example:
```
CONF:SENSOR1:BETA?
3950
```

#### CONFigure:SENSORx:THERmistor
Set thermistor nominal resistance at nominal (room) temperature.
Typically this is either 10000 (for 10k thermistors) or 100000 (for 100k thermistors).

Default: 10000

For example: configure 100k thermistor
```
CONF:SENSOR1:THER 100000
```

#### CONFigure:SENSORx:THERmistor?
Get the thermistor nominal resistance at nominal (room) temperature.

For example:
```
CONF:SENSOR1:THER?
100000
```

#### CONFigure:SENSORx:TEMPNominal
Set nominal temperature of the thermistor (in C).
Typically nominal temperature is around room temperature.

Default: 25.0

For example:
```
CONF:SENSOR1:TEMPN 25.0
```

#### CONFigure:SENSORx:TEMPNominal?
Get nominal temperature of the thermistor (in C).

For example:
```
CONF:SENSOR1:TEMPN?
25.0
```

#### CONFigure:SENSORx:FILTER
Configure filter to be applied to the temperature signal received from the sensor.

List of available filters can be found here: [Available Filters](#configurefanfilter)

By default, no filter is applied (filter is set to "none").

Example: Set filter for the input signal to "Simple Moving Average", that can
be useful with noisy readings from temperature sensors.

```
CONF:SENSOR1:FILTER sma,10
```

#### CONFigure:SENSORx:FILTER?
Display currently active filter for the temperature signal received from the sensor.

Format: filter,arg_1,arg_2,...arg_n

For example:
```
CONF:SENSOR1:FILTER?
sma,10
```

#### CONFigure:VSENSORS?

This is same as CONFigure::VSENSORS:SOUrces? command.

#### CONFigure:VSENSORS:SOUrces?
Return virtual sensor (source) configuration information for all
virtual sensors in CSV format.

Format: <vsensor>,<type>,<parameter1>,<parameter2>,...

Example:
```
CONF:VSENSORS:SOURCES?
vsensor1,onewire,22cd991800000020
vsensor2,i2c,0x48,TMP117
vsensor3,i2c,0x37,PCT2075
vsensor4,i2c,0x77,DPS310
vsensor5,i2c,0x76,BMP280
vsensor6,i2c,0x49,ADT7410
vsensor7,i2c,0x38,AHT2x
vsensor8,manual,0.00,30
```

### CONFigure:VSENSORx Commands
VSENSORx (where x is the sensor number) commands are used to configure virtual temperature sensors.
These can be "sensors" that are updated by software, like "CPU Temperature" of host system.
Or these can be be virtual sensors that report value of multiple physical sensors fed through a mathematical formula.

Where x is a number from 1 to 8.

Virtual Sensor Mode|Description
------|-----------
manual|Manually updated (by software) sensor values. For example host CPU Temperature.
max|Maximum temperature of configured source sensors.
min|Minimum temperature of configured source sensors.
avg|Average temperature of configured source sensors.
delta|Temperature delta between readings from two source sensors.
onewire|Reading from digital 1-Wire sensor

#### CONFigure:VSENSORx:NAME
Set name for virtual temperature sensor.

For example:
```
CONF:VSENSOR1:NAME CPU Temperature
```

#### CONFigure:VSENSORx:NAME?
Query name of a virtual temperature sensor.

For example:
```
CONF:VSENSOR1:NAME?
CPU Temperature
```

#### CONFigure:VSENSORx:SOUrce
Configure source for the virtual temperature sensor.

Source types:

MODE|Description|No of Parameters|Parameters
----|-----------|----------------|----------
MANUAL|Temperature updated by external program/driver|2|default_temperature_C,timeout
MAX|Maximum temperatore between source sensors|2+|sensor_a,sensor_b, ...
MIN|Minimum temperature between source sensors|2+|sensor_a,sensor_b, ...
AVG|Average temperature between source sensors|2+|sensor_a,sensor_b, ...
DELTA|Temperature delta between to source sensors|2|sensor_a,sensor_b
ONEWIRE|Temperature reading from digital 1-Wire sensor|1|onewire_address
I2C|Temperature reading from digital I2C sensor|2|i2c_address,sensor_type_or_alias

Note, in "manual" mode if timeout_ms is set to zero, then sensor's temperature reading
will never revert back to default value (if no updates are being received).

Sensor numbering:
 - SENSORS: 1, 2, ...
 - VSENSORS: 101, 102, ...

Supported I2C sensors:

Sensor Type|Aliases|Possible Addresses|Description|Notes
-----------|-------|------------------|-----------|-----
ADT7410||0x48, 0x49, 0x4a, 0x4b|16bit Digital Temperature Sensor, 0.5C accuracy
AHT1x|||AHT1x Series Temperature and Humidity sensors (AHT10, AHT11 ,...)
AHT2x|||AHT2x Series Temperature and Humidity sensors (AHT20, AHT21 ,...)
AM2320||0x5c|Temperature and Humidity Sensor, 0.5C accuracy|Not found when scanning bus. May not work above 100kHz bus speeds.
AS621x|AS6212, AS6214, AS6218||AS621x Series sensors: AS6212 (0.2C), AS6214 (0.4C), AC6218 (0.8C)
BMP180|||16bit, 0.5C accuracy
BMP280||0x76, 0x77|20bit, 0.5C accuracy
DPS310||0x77, 0x76|24bit, 0.5C accuracy
HDC302x|HDC3022, HDC3021, HDC3020|0x44, 0x45, 0x46, 0x47|HDC302x Series Temperature and Humiditysensors
HTS221||0x5f|Temperature and Humidity Sensor
HTU21D||0x40|Temperature and Humidity Sensor, 0.4C accuracy|Not found when scanning bus (SYS:I2C:SCAN?)
HTU31D||0x40, 0x41|Temperature and Humidity Sensor, 0.3C accuracy
LPSxx|LPS22, LPS25, LPS28, LPS33, LPS35|0x5d, 0x5c|LPSxx Series Temperature and Pressure sensors
MCP9808|||Digital Temperature Sensor, 0.5C accuracy
MPL115A2||0x60|Digital Barometer|Temperature sensor not calibrated.
MPL3115A2||0x60|Temperature and Pressure sensor with Altimetry, 1C accuracy
MS5611||0x76, 0x77|Temperature and Pressure Sensor|Not found when scanning bus (SYS:I2C:SCAN?)
MS8607||0x76 and 0x40|Temperature, Humidity and Pressure Sensor|Not found when scanning bus (SYS:I2C:SCAN?), appears as two seprate devices.
PCT2075|||Digital Temperature Sensor, 1C accuracy
SHT3x|SHT30, SHT31, SHT35|0x44, 0x34|SHT3x Series Temperature and Humidity sensors|Not always found when scanning bus (SYS:I2C:SCAN?)
SHT4x|SHT40, SHT41, SHT43, SHT45|0x44|SHT4x Series Temperature and Humidity sensors|Not always found when scanning bus (SYS:I2C:SCAN?)
SHTC3||0x70|Temperature and Humidity sensor, 0.2C accuracy
SI7021||0x40|Temperature and Humidity sensor, 0.4C accuracy
STTS22H||0x38, 0x3c, 0x3e, 0x3f|Temperature Sensor, 0.5C accuracy
TC74|TC74A0|0x48 - 0x4f|Digital Thermal Sensor, 2C accuracy
TMP102||0x48, 0x49, 0x4a, 0x4b|Temperature Sensor, 2C accuracy
TMP117||0x48, 0x49, 0x4a, 0x4b|Temperature Sensor, 0.1C accuracy

Defaults:

Default for all virtual sensors is to be in "MANUAL" mode and revert automatically to 0C
if no temperature update has been received within 30 seconds.

VSENSOR|SOURCE
---|------
1|MANUAL,0,30
...|...

Example: Set VSENSOR1 to report temperature that is updated by external program. And to sensor reading to revert to default value of 99C if no update has been received within 5 seconds.
```
CONF:VSENSOR2:SOURCE manual,99,5
```

Example: Set VSENSOR2 to follow report temperature delta between SENSOR1 and SENSOR2.
```
CONF:VSENSOR2:SOURCE delta,1,2
```

Example: Set VSENSOR3 to report average temperature between SENSOR1, SENSOR2, and VSENSOR1
```
CONF:VSENSOR3:SOURCE avg,1,2,101
```

Example: Set VSENSOR4 to report temperature from 1-Wire sensor with address 2871d86a0000005a:
```
CONF:VSENSOR4:SOURCE onewire,2871d86a0000005a
```

(to get list of currently active 1-Wire sensors use: SYS:ONEWIRE:SENSORS?)

Example: Set VSENSOR5 to report temperature from TMP117 (I2C) sensor with address 0x48:
```
CONF:VSENSOR5:SOURCE i2c,0x48,tmp117
```

(to get list of currently active I2C sensor addresses, use: SYS:I2C:SCAN?)

#### CONFigure:VSENSORx:SOUrce?
Query a virtual temperature sensor configuration (temperature reading source).

Command returns response in following format:
```
mode,parameter,parameter,...
```

Example:
```
CONF:VSENSOR1:SOU?
manual,99.0,5
```

#### CONFigure:VSENSORx:TEMPMap
Set mapping (curve) for converting temperature to PWM signal duty cycle (%).
This can be used to customize how temperature affects fan speed.

Mapping is specified with up to 32 points (that can be plotted as a curve)
that map the relation of the temperature (x value) to output PWM signal (y value).
Mapping should at minimum include that start and end points of the expected input signal.

Default mapping:
x (Temperature in C)|y (Fan Duty Cycle in %)
-|-
20|0
50|100

Example: Set Fan to start running at 20% duty cycle at 25C and to be full speed at 50C
```
CONF:VSENSOR1:TEMPMAP 25,20,50,100
```

#### CONFigure:VSENSORx:TEMPMap?
Display currently active mapping (curve) for convertin measured temperature
to PWM duty cycle (%) for the fan output signal.

Mapping is displayed as comma separated list of values:
```
x_1,y_1,x_2,y_2,...,x_n,y_n
```

For example:
```
CONF:VSENSOR1:TEMPMAP?
20,0,50,10000
```

#### CONFigure:VSENSORx:FILTER
Configure filter to be applied to the temperature signal received from the sensor.

List of available filters can be found here: [Available Filters](#configurefanfilter)

By default, no filter is applied (filter is set to "none").

Example: Set filter for the input signal to "Simple Moving Average", that can
be useful with noisy readings from temperature sensors.

```
CONF:VSENSOR1:FILTER sma,10
```

#### CONFigure:VSENSORx:FILTER?
Display currently active filter for the temperature signal received from the sensor.

Format: filter,arg_1,arg_2,...arg_n

For example:
```
CONF:VENSOR1:FILTER?
sma,10
```

#### EXIT
Disconnect remote connection. This will disconnect active telnet connection.

```
EXIT
```

### MEASure Commands
These commands are for reading (measuring) the current input/output values on Fan and Motherboard Fan ports.

#### MEASure:Read?
This command returns all measurements for all FAN and MBFAN, and SENSOR ports.
(This is same as: Read?)

Response format:
```
mbfan<n>,"<name>",<output rpm>,<output tacho frequency>,<input pwm duty cycle>
...
fan<n>,"<name>",<input rpm>,<input tacho frequency>,<output pwm duty cycle>
...
sensor<n>,"<name>",<temperature>,<pwm duty cycle>
...
vsensor<n>,"<name>",<temperature>,<pwm duty cycle>
```

Example:
```
MEAS:READ?
mbfan1,"CPU Fan",1020,34.00,63.0
mbfan2,"Chassis Fan 1",468,15.60,63.0
mbfan3,"Chassis Fan 2",534,17.80,63.0
mbfan4,"Chassis Fan 3",417,13.90,63.0
fan1,"CPU Fan",1020,34.00,63.0
fan2,"Rear Exhaust",468,15.60,31.5
fan3,"unused",0,0.00,20.0
fan4,"unused",0,0.00,20.0
fan5,"Front Intake 1",534,17.80,35.0
fan6,"Front Intake 2",420,14.00,35.0
fan7,"Top Exhaust 1",417,13.90,22.8
fan8,"Top Exhaust 2",462,15.40,22.8
sensor1,"Intake Air",22.4,7.9
sensor2,"Exhaust Air",30.5,35.0
sensor3,"RPi Pico",26.5,21.8
vsensor1,"CPU Temp",55.0,60.5
vsensor2,"unused",0.0,20.0
vsensor3,"unused",0.0,20.0
vsensor4,"unused",0.0,20.0
vsensor5,"unused",0.0,20.0
vsensor6,"unused",0.0,20.0
vsensor7,"unused",0.0,20.0
vsensor8,"unused",0.0,20.0
```

### MEASure:FANx Commands

#### MEASure:FANx?
Return current fan speed (RPM), tacho meter frequency (Hz), and output PWM signal duty cycle (%) for a fan.

Response format:
```
<duty_cycle>,<frequency>,<rpm>
```

Example:
```
MEAS:FAN1?
42,34.4,1032
```

#### MEASure:FANx:Read?
Return current fan speed (RPM), tacho meter frequency (Hz), and output PWM signal duty cycle (%) for a fan.

This is same as: MEASure:FANx?

Response format:
```
<duty_cycle>,<frequency>,<rpm>
```

Example:
```
MEAS:FAN1:R?
42,34.4,1032
```

#### MEASure:FANx:RPM?
Return current fan speed (RPM).

Example:
```
MEAS:FAN1:RPM?
1032
```

#### MEASure:FANx:PWM?
Return current fan (output) PWM signal duty cycle (%).

Example:
```
MEAS:FAN1:PWM?
42
```

#### MEASure:FANx:TACHo?
Return current fan tachometer (speed) signal frequency (Hz).

Example:
```
MEAS:FAN1:TACH?
34.4
```

### MEASure:MBFANx Commands

#### MEASure:MBFANx?
Return current motherboard fan connector signals. Output fan speed speed (RPM), output tacho meter frequency (Hz), and input PWM signal duty cycle (%) for a mbfan.

Response format:
```
<duty_cycle>,<frequency>,<rpm>
```

Example:
```
MEAS:MBFAN1?
49,34.4,1032
```

#### MEASure:MBFANx:Read?
Return current fan speed (RPM), tacho meter frequency (Hz), and output PWM signal duty cycle (%) for a fan.

This is same as: MEASure:MBFANx?

Response format:
```
<duty_cycle>,<frequency>,<rpm>
```

Example:
```
MEAS:MBFAN1:R?
49,34.4,1032
```

#### MEASure:MBFANx:RPM?
Return current fan speed (RPM) reported out to motherboard.

Example:
```
MEAS:MBFAN1:RPM?
1032
```

#### MEASure:MBFANx:PWM?
Return current fan (input) PWM signal duty cycle (%) received from motherboard.

Example:
```
MEAS:MBFAN1:PWM?
49
```

#### MEASure:MBFANx:TACHo?
Return current fan tachometer (speed) signal frequency (Hz) reported out to motherboard.

Example:
```
MEAS:MBFAN1:TACH?
34.4
```

### MEASure:SENSORx Commands

#### MEASure:SENSORx?
Return current temperature (C) measured by the sensor.

Example:
```
MEAS:SENSOR1?
25
```

#### MEASure:SENSORx:Read?
Return current temperature (C) measured by the sensor.

This is same as: MEASure:SENSORx?

Example:
```
MEAS:SENSOR1:R?
25
```

#### MEASure:SENSORx:TEMP?
Return current temperature (C) measured by the sensor.

This is same as: MEASure:SENSORx?

Example:
```
MEAS:SENSOR1:TEMP?
25
```

#### MEASure:VSENSORS?
Return all measurements for all virtual sensors.

Format: sensor,temperature_C,humidity_%,pressure_hPa

Example:
```
MEAS:VSENSORS?
vsensor1,"vsensor1",24.4,0,0
vsensor2,"vsensor2",24.9,0,0
vsensor3,"vsensor3",24.8,43,0
vsensor4,"vsensor4",26.5,0,997
vsensor5,"vsensor5",25.1,0,991
vsensor6,"vsensor6",0.0,0,0
vsensor7,"vsensor7",0.0,0,0
vsensor8,"vsensor8",0.0,0,0
```

#### MEASure:VENSORx?
Return current temperature (C) measured by the sensor.

Example:
```
MEAS:VSENSOR1?
25
```

#### MEASure:VSENSORx:HUMidity?
Return current humidity (%) measured by the sensor.

Example:
```
MEAS:VSENSOR1:HUM?
45
```

#### MEASure:VSENSORx:PREssure?
Return current pressure (hPa) measured by the sensor.

Example:
```
MEAS:VSENSOR1:PRE?
1013
```

#### MEASure:VSENSORx:Read?
Return current temperature (C) measured by the sensor.

This is same as: MEASure:VSENSORx?

Example:
```
MEAS:VSENSOR1:R?
25
```

#### MEASure:VSENSORx:TEMP?
Return current temperature (C) measured by the sensor.

This is same as: MEASure:VSENSORx?

Example:
```
MEAS:VSENSOR1:TEMP?
25
```

### Read Commands

#### Read?
This command returns all measurements for all FAN and MBFAN, and SENSOR ports.
(This is same as: MEASure:Read?)

Response format:
```
mbfan<n>,"<name>",<output rpm>,<output tacho frequency>,<input pwm duty cycle>
...
fan<n>,"<name>",<input rpm>,<input tacho frequency>,<output pwm duty cycle>
...
sensor<n>,"<name>",<temperature>,<pwm duty cycle>
...
vsensor<n>,"<name>",<temperature>,<pwm duty cycle>
```

Example:
```
mbfan1,"CPU Fan",1020,34.00,63.0
mbfan2,"Chassis Fan 1",468,15.60,63.0
mbfan3,"Chassis Fan 2",534,17.80,63.0
mbfan4,"Chassis Fan 3",417,13.90,63.0
fan1,"CPU Fan",1020,34.00,63.0
fan2,"Rear Exhaust",468,15.60,31.5
fan3,"unused",0,0.00,20.0
fan4,"unused",0,0.00,20.0
fan5,"Front Intake 1",534,17.80,35.0
fan6,"Front Intake 2",420,14.00,35.0
fan7,"Top Exhaust 1",417,13.90,22.8
fan8,"Top Exhaust 2",462,15.40,22.8
sensor1,"Intake Air",22.4,7.9
sensor2,"Exhaust Air",30.5,35.0
sensor3,"RPi Pico",26.5,21.8
vsensor1,"CPU Temp",55.0,60.5
vsensor2,"unused",0.0,20.0
vsensor3,"unused",0.0,20.0
vsensor4,"unused",0.0,20.0
vsensor5,"unused",0.0,20.0
vsensor6,"unused",0.0,20.0
vsensor7,"unused",0.0,20.0
vsensor8,"unused",0.0,20.0
```

### SYStem Commands

#### SYStem:ERRor?
Display status from last command.

Example:
```
SYS:ERR?
0,"No Error"
```

#### SYStem:BOARD?
Display information about FanPico board in use and the Pico module attached.

Example:
```
SYS:BOARD?
Hardware Model: FANPICO-0804D
         Board: pico_w
           MCU: RP2040-B2 @ 200MHz
           RAM: 264KB
         Flash: 2048KB @ 100MHz
 Serial Number: e6614c311b7ca431
```

#### SYStem:DEBug
Set the system debug level. This controls the logging to the console.

Default: 0   (do not log any debug messages)

Example: Enable verbose debug output
```
SYS:DEBUG 2
```

#### SYStem:DEBug?
Display current system debug level.

Example:
```
SYS:DEBUG?
0
```

#### SYStem:LOG
Set the system logging level. This controls the level of logging to the console.

Default: WARNING

Log Levels:

Level|Name
-----|----
0|EMERG
1|ALERT
2|CRIT
3|ERR
4|WARNING
5|NOTICE
6|INFO
7|DEBUG

Example: Enable verbose debug output
```
SYS:LOG DEBUG
```

#### SYStem:LOG?
Display current system logging level.

Example:
```
SYS:LOG?
NOTICE
```

#### SYStem:SYSLOG
Set the syslog logging level. This controls the level of logging to a remote
syslog server.

Default: ERR

Log Levels:

Level|Name
-----|----
0|EMERG
1|ALERT
2|CRIT
3|ERR
4|WARNING
5|NOTICE
6|INFO
7|DEBUG

Example: Enable logging of NOTICE (and lower level) message:
```
SYS:LOG NOTICE
```

#### SYStem:SYSLOG?
Display current syslog logging level.

Example:
```
SYS:SYSLOG?
ERR
```

#### SYStem:DISPlay
Set display (module) parameters as a comma separated list.

This can be used to set display module type if cannot be automatically detected.
Additionally this can be used to set some display parameters like brightness.

Default: default

Currently supported values:

Value|Description|Notes
-----|-----------|-----
default|Use default settings (auto-detect).
none|Disable OLED support|Skips scanning for OLED panel.
128x64|OLED 128x64 module installed.|OLED
128x128|OLED 128x128 module installed.|OLED
132x64|OLED 132x64 installed (some 1.3" 128x64 modules need this setting!)|OLED
flip|Flip display (upside down)|OLED and LCD
invert|Invert display|OLED and LCD
brightness=n|Set display brightness (%) to n (where n=0..100) [default: 50]|OLED
rotate=n|Rotate display n degrees (where n=0, 90, 180, 270) [default: 90]|LCD only
swapcolors|Swap Red and Blue colors (use if colors dont show up correctly)|LCD only
spifreq=n|Set SPI Bus frequency (values < 1000 assumed to be in MHz, values >1000 assumed to be in Hz)  [default: 48 (MHz)]|LCD only
16bit|Use 16bit SPI bus transfers only (needed often for display modules made for Raspberry Pi)|LCD only

Example: 1.3" (SH1106) module installed that doesn't get detected correctly
```
SYS:DISP 132x64
```

Example: Invert display and set brightnes to 30%
```
SYS:DISP default,invert,brightness=30
```

#### SYStem:DISPlay?
Display current display module setting.

Example:
```
SYS:DISP?
132x64,flip,invert,brightness=75
```

#### SYStem:DISPlay:LAYOUTR
Configure (OLED) Display layout for the right side of the screen.

Layout is specified as a comma delimited string describing what to
display on each row (8 rows available if using 128x64 OLEd module, 10 rows available with 128x128 pixel modules).

Syntax: <R1>,<R2>,...<R8>

Where tow specifications can be one of the following:

Type|Description|Notes
----|-----------|-----
Mn|MBFan input n|n=1..4
Sn|Sensor input n|n=1..3
Vn|Virtual Sensor input n|n=1..8
-|Horizontal Line|
Ltext|Line with "text"|Max length 9 characters.

Default: <not set>

When this setting is not set following defaults are used based
on the OLED module size:

Screen Size|Available Rows|Default Configuration
-----------|--------------|---------------------
128x64|8|M1,M2,M3,M4,-,S1,S2,S3
128x128|10|LMB Inputs,M1,M2,M3,M4,-,LSensors,S1,S2,S3

Example: configure custom theme (for 128x64 display):
```
SYS:DISP:LAYOUTR M1,M2,-,S1,S2,S3,V1,V2
```

#### SYStem:DISPlay:LAYOUTR?
Display currently configured (OLED) Display layout for the right side of the screen.

Example:
```
SYS:DISP:THEME?
M1,M2,-,S1,S2,S3,V1,V2
```

#### SYStem:DISPlay:LOGO
Configure (LCD) Display boot logo.

Currently available logos:

Name|Description
----|-----------
default|Default FanPico boot logo.
custom|Custom boot logo (only available if firmware has been compiled with custom logo included).

Example: configure custom logo
```
SYS:DISP:LOGO custom
```

#### SYStem:DISPlay:LOGO?
Display currently configured (LCD) Display boot logo.

Example:
```
SYS:DISP:LOGO?
default
```

#### SYStem:DISPlay:THEMe
Configure (LCD) Display theme to use.

Default: default

Example: configure custom theme
```
SYS:DISP:THEME custom
```

#### SYStem:DISPlay:THEMe?
Display currently configured (LCD) display theme name.

Example:
```
SYS:DISP:THEME?
default
```

#### SYStem:ECHO
Enable or disaple local echo on the console.
This can be useful if interactively programming Fanpico.

Value|Status
-----|------
0|Local Echo disabled.
1|Local Echo enabled.

Default: 0

Example: enable local echo
```
SYS:ECHO 1
```

Example: disable local echo
```
SYS:ECHO 0
```

#### SYStem:ECHO?
Display local echo status:

Example:
```
SYS:ECHO?
0
```

#### SYStem:FANS?
Display number of FAN output ports available.

Example:
```
SYS:FANS?
8
```

### SYStem:FLASH?
Returns information about Pico flash memory usage.

Example:
```
SYS:FLASH?
Flash memory size:                     2097152
Binary size:                           683520
LittleFS size:                         262144
Unused flash memory:                   1151488
```

#### SYStem:HTTP:SERVer
Enable or disable built-in HTTP server that displays status information
about the unit.

Default: ON

Example (disable HTTP server):
```
SYS:HTTP:SERVER OFF
```

#### SYStem:HTTP:SERVer?
Query currently status of HTTP server.

Example:
```
SYS:HTTP:SERVER?
ON
```

#### SYStem:HTTP:PORT
Set web server HTTP port.

Default: 0  (use default HTTP port tcp/80)

Example:
```
SYS:HTTP:PORT 8080
```

#### SYStem:HTTP:PORT?
Query currently set web server (HTTP) port.

If return value is zero (0), then default HTTP port is being used.

Example:
```
SYS:HTTP:PORT?
0
```

#### SYStem:HTTP:TLSPORT
Set web server HTTPS port use for TLS/SSL connections.

Default: 0  (use default HTTPS port tcp/443)

Example:
```
SYS:HTTP:TLSPORT 8443
```

#### SYStem:HTTP:TLSPORT?
Query currently set web server HTTPS port.

If return value is zero (0), then default HTTPS port is being used.

Example:
```
SYS:HTTP:TLSPORT?
0
```

#### SYStem:HTTP:MASK:FAN
Configure which fan ports should be displayed on HTTP server.

Fans can be specified as comma separated list (2,3) or as range (1-3)
or as combination of both.

Default: 1-8    (display all fans)

Example:
```
SYS:HTTP:MASK:FAN 1-4,8
```

#### SYStem:HTTP:MASK:FAN?
Query which fan ports are configured to be displayed on HTTP server.

Example:
```
SYS:HTTP:MASK:FAN?
1-8
```

#### SYStem:HTTP:MASK:MBFAN
Configure which mbfan ports should be displayed on HTTP server.

Fans can be specified as comma separated list (2,3) or as range (1-3)
or as combination of both.

Default: 1-4    (display all mbfans)

Example:
```
SYS:HTTP:MASK:MBFAN 1,3,4
```

#### SYStem:HTTP:MASK:MBFAN?
Query which mbfan ports are configured to be displayed on HTTP server.

Example:
```
SYS:HTTP:MASK:MBFAN?
1,3-4
```

#### SYStem:HTTP:MASK:SENSOR
Configure which temperature sensors should be displayed on HTTP server.

Sensors can be specified as comma separated list (2,3) or as range (1-3)
or as combination of both.

Default: 1-3    (display all sensors)

Example:
```
SYS:HTTP:MASK:SENSOR 1,3
```

#### SYStem:HTTP:MASK:SENSOR?
Query which sensors are configured to be displayed on HTTP server.

Example:
```
SYS:HTTP:MASK:SENSOR?
1,3
```

#### SYStem:HTTP:MASK:VSENSOR
Configure which virtual sensors should be displayed on HTTP server.

Sensors can be specified as comma separated list (1,3,7) or as range (1-3)
or as combination of both.

Default: 1-8    (display all virtual sensors)

Example:
```
SYS:HTTP:MASK:VSENSOR 1-4
```

#### SYStem:HTTP:MASK:VSENSOR?
Query which virtual sensors are configured to be displayed on HTTP server.

Example:
```
SYS:HTTP:MASK:VSENSOR?
1-4
```

### SYStem:I2C?
Returns status if I2C bus is active (available) currently.
Depending on board model I2C may not be available at all
or may only be available if SPI is not active.

Returns:

status|description
------|-----------
0|I2C Bus not available
1|I2C Bus available

Example:
```
SYS:I2C?
1
```

### SYStem:I2C:SCAN?
Scan I2C Bus for active devices.
This returns addresses of any devices found on I2C bus.

Example:
```
SYS:I2C:SCAN??
Scanning I2C Bus... 0x3c
Device(s) found: 1
```

### SYStem:I2C:SPEED
Set speed that I2C bus operates.
Note, change won't take effect until unit is rebooted.

Speed range: 10000 - 3400000
(speeds over 1000000 may not work reliably)

Default: 1000000  (1000 kHz or 1000 kbit/s)

Example:
```
SYS:I2C:SPEED 1000000
CONF:SAVE
```

### SYStem:I2C:SPEED?
Return currently configured I2C bus speed (Hz or bit/s).

Example:
```
SYS:I2C:SPEED?
1000000
```

#### SYStem:IFCONFIG?
Same as [SYStem:WIFI:INFO?](#systemwifiinfo)

#### SYStem:LED
Set system indicator LED operating mode.

Supported modes:

mode|description
----|-----------
0   | LED blinking slowly  [default]
1   | LED on (continuously)
2   | LED off

Default: 0

Example to set LED to be on continuously:
```
SYS:LED 1
```

#### SYStem:LED?
Query current system LED operating mode.

Example:
```
SYS:LED?
0
```

#### SYStem:LFS?
Display information about the LittleFS filesystem in the flash memory.

Example:
```
SYS:LFS?
Filesystem size:                       262144
Filesystem used:                       24576
Filesystem free:                       237568
Number of files:                       3
Number of subdirectories:              0
```

#### SYStem:LFS:COPY
Copy a file on the flash filesystem (littlefs).
If destination file already exists copy will fail.

Parameters: <sourcefile> <destinationfile>

Example:
```
SYS:LFS:COPY fanpico.cfg fanpico-backup.cfg
```

#### SYStem:LFS:DELete
Delete file from the flash filesystem (littlefs).

parameters: <filename>

Example (delete TLS certificate and private key):
```
SYS:LFS:DEL cert.pem
SYS:LFS:DEL key.pem
```

#### SYStem:LFS:DIR?
List contents of the flash filesystem (littlefs).

Example:
```
SYS:LFS:DIR?
Directory: /

.                                                       <DIR>
..                                                      <DIR>
cert.pem                                                 1286
fanpico.cfg                                              7012
key.pem                                                  1709

```

#### SYStem:LFS:FORMAT
Format flash filesystem. This will erase current configuration (including any TLS certificates saved in flash).

Example (format filesystem and save current configuration):
```
SYS:LFS:FORMAT
CONF:SAVE
```

#### SYStem:LFS:REName
Rename a file on the flash filesystem (littlefs).

Parameters: <oldname> <newname>

Example:
```
SYS:LFS:REN fanpico-backup.cfg fanpico.cfg
```

#### SYStem:MBFANS?
Display number of MBFAN input ports available.

Example:
```
SYS:MBFANS?
4
```

### SYStem:MEM
Test how much available (heap) memory system currently has.
This does simple test to try to determine what is the largest
block of heap memory that is currently available as well as
try allocating as many as possible small block of memory to determine
roughly the total available heap memory.

This command takes optional 'blocksize' parameter to specify the memory
block size to use in the tests. Default is 1024 bytes.

Example:
```
SYS:MEM 512
Largest available memory block:        114688 bytes
Total available memory:                111104 bytes (217 x 512bytes)
```

### SYStem:MEM?
Returns information about heap and stack size. As well as information
about current (heap) memory usage as returned by _mallinfo()_ system call.

Note,  _mallinfo()_ does not always "see" all of the available heap memory, unless ```SYS:MEM``` command
has been run first.

Example:
```
SYS:MEM?
Core0 stack size:                      8192
Core1 stack size:                      4096
Heap size:                             136604
mallinfo:
Total non-mmapped bytes (arena):       136604
# of free chunks (ordblks):            2
# of free fastbin blocks (smblks):     0
# of mapped regions (hblks):           0
Bytes in mapped regions (hblkhd):      0
Max. total allocated space (usmblks):  0
Free bytes held in fastbins (fsmblks): 0
Total allocated space (uordblks):      21044
Total free space (fordblks):           115560
Topmost releasable block (keepcost):   114808
```

### SYStem:MQTT Commands
FanPico has MQTT Client that can be configured to publish (send) periodic status
updates to a topic.
Additionally MQTT Client support subscribing to a "command" topic to listen for commands.
This allows remotely controlling BrickPico.

To enable MQTT at minimum server and user must be configured. To explicitly disbable MQTT set server
to empty string.

#### SYStem:MQTT:SERVer
Set MQTT server to connect to. This parameter expects a DNS name as argument.

Default: <empty>   (when this setting is empty string, MQTT is explicitly disabled)

Example (configure MQTT server name):
```
SYS:MQTT:SERVER io.adafruit.com
```

Example (disable MQTT):
```
SYS:MQTT:SERVER
```

#### SYStem:MQTT:SERVer?
Query currently set MQTT server name.

Example:
```
SYS:MQTT:SERVER?
io.adafruit.com
```

#### SYStem:MQTT:PORT
Set MQTT server (TCP) port. This setting is needed when MQTT server is not using standard port.
If this setting is not set (value is left to default "0"), then standard MQTT port is used.

- Secure (TLS) Port = 8883
- Insecure Port = 1883

Default: 0   (when this setting is 0 use default MQTT ports)

Example:
```
SYS:MQTT:PORT 9883
```

#### SYStem:MQTT:PORT?
Query currently set MQTT (TCP) port.

If return value is zero (0), then default MQTT port is being used.

Example:
```
SYS:MQTT:PORT?
0
```

#### SYStem:MQTT:USER
Set MQTT username to use when connecting to MQTT server.

Default: <empty>

Example:
```
SYS:MQTT:USER myusername
```

#### SYStem:MQTT:USER?
Query currently set MQTT username.

Example:
```
SYS:MQTT:USER?
myusername
```

#### SYStem:MQTT:PASS
Set MQTT password to use when connecting to MQTT server.

Default: <empty>

Example:
```
SYS:MQTT:PASS mymqttpassword
```

#### SYStem:MQTT:PASS?
Query currently set MQTT password.

Example:
```
SYS:MQTT:PASS?
mymqttpassword
```

#### SYStem:MQTT:SCPI
Configure if SCPI all commands will be accepted via MQTT.
If this is not enabled then only "WRITE" commands are allowed.

This is potentially "dangerous" feature, so only enable if you understand
the potential risks allowing device to be remotely configured.

Default: OFF

Example:
```
SYS:MQTT:SCPI ON
```

#### SYStem:MQTT:SCPI?
Query whether all SCPI commands are allowed via MQTT.

Example:
```
SYS:MQTT:SCPI?
OFF
```

#### SYStem:MQTT:TLS
Enable/disable use of secure connection mode (TLS/SSL) when connecting to MQTT server.
Default is TLS on to protect MQTT credentials (usename/password).

Default: ON

Example:
```
SYS:MQTT:TLS OFF
```

#### SYStem:MQTT:TLS?
Query whether TLS is enabled or disabled for MQTT.

Example:
```
SYS:MQTT:TLS?
ON
```

#### SYStem:MQTT:HA:DISCovery
Configure Home Assistant MQTT Discovery prefix. This must be set to enable
Home Assistant support/integration in FanPico.

If this is left to empty (string), then Home Assistant support is disabled.

Default: <empty>

Example (enable Home Assistant support using default prefix):
```
SYS:MQTT:HA:DISC homeassistant
```

#### SYStem:MQTT:HA:DISCovery?
Query currently set Home Assistant MQTT Discovery prefix.

Note, if this is empty, then Home Assistant support is disabled.

Example:
```
SYS:MQTT:HA:DISC?
homeassistant
```

#### SYStem:MQTT:INTerval:STATUS
Configure how often unit will publish (send) status message to status topic.
Set this to 0 (seconds) to disable publishing status updates.
Recommended values are 60 (seconds) or higher.

Default: 600  (every 10 minutes)

Example:
```
SYS:MQTT:INT:STATUS 3600
```

#### SYStem:MQTT:INTerval:STATUS?
Query how often unit is setup to publish data to status topic.

Example:
```
SYS:MQTT:INT:STATUS?
3600
```

#### SYStem:MQTT:INTerval:TEMP
Configure how often unit will publish (send) status temperature sensor
status messages.
Set this to 0 (seconds) to disable publishing status updates.
Recommended values are 60 (seconds) or higher.

Default: 0  (disabled)

Example:
```
SYS:MQTT:INT:TEMP 60
```

#### SYStem:MQTT:INTerval:TEMP?
Query how often unit is setup to publish temperature status messages.

Example:
```
SYS:MQTT:INT:TEMP?
60
```

#### SYStem:MQTT:INTerval:VSENsor
Configure how often unit will publish (send) virtual sensor status messages.
Set this to 0 (seconds) to disable publishing status updates.
Recommended values are 60 (seconds) or higher.

Default: 0  (disabled)

Example:
```
SYS:MQTT:INT:VSEN 60
```

#### SYStem:MQTT:INTerval:VSENsor?
Query how often unit is setup to publish virtual sensor status messages.

Example:
```
SYS:MQTT:INT:VSENP?
60
```

#### SYStem:MQTT:INTerval:RPM
Configure how often unit will publish (send) RPM status updates for
fans (and mbfans).

Set this to 0 (seconds) to disable publishing status updates.
Recommended values are 60 (seconds) or higher.

Default: 0  (disabled)

Example:
```
SYS:MQTT:INT:RPM 60
```

#### SYStem:MQTT:INTerval:RPM?
Query how often unit is setup to publish fan/mbfan RPM status messages.

Example:
```
SYS:MQTT:INT:RPM?
60
```

#### SYStem:MQTT:INTerval:PWM
Configure how often unit will publish (send) PWM (duty cycle) status updates for
fans/mbfans.

Set this to 0 (seconds) to disable publishing status updates.
Recommended values are 60 (seconds) or higher.

Default: 0  (disabled)

Example:
```
SYS:MQTT:INT:PWM 60
```

#### SYStem:MQTT:INTerval:PWM?
Query how often unit is setup to publish fan/mbfan PWM (duty cycle) status messages.

Example:
```
SYS:MQTT:INT:PWM?
60
```

#### SYStem:MQTT:MASK:TEMP
Configure which temperature sensors should publish (send) data to MQTT server.

Sensors can be specified as comma separated list (2,3) or as range (1-3)
or as combination of both.

Default: <empty>   (do not publish data from any sensor)

Example:
```
SYS:MQTT:MASK:TEMP 1,3
```

#### SYStem:MQTT:MASK:TEMP?
Query which sensors are configured to publish (send) data to MQTT server.

Example:
```
SYS:MQTT:MASK:TEMP?
1,3
```

#### SYStem:MQTT:MASK:VTEMP
Configure which virtual sensors should publish (send) temperature data to MQTT server.

Sensors can be specified as comma separated list (2,3) or as range (1-3)
or as combination of both.

Default: <empty>   (do not publish data from any sensor)

Example:
```
SYS:MQTT:MASK:VTEMP 1,2,3,4
```

#### SYStem:MQTT:MASK:VTEMP?
Query which virtual sensors are configured to publish (send) temperature data to MQTT server.

Example:
```
SYS:MQTT:MASK:VTEMP?
1-4
```

#### SYStem:MQTT:MASK:VHUMidity
Configure which virtual sensors should publish (send) humidity data to MQTT server.

Sensors can be specified as comma separated list (2,3) or as range (1-3)
or as combination of both.

Default: <empty>   (do not publish data from any sensor)

Example:
```
SYS:MQTT:MASK:VHUM 1,2
```

#### SYStem:MQTT:MASK:VHUMidity?
Query which virtual sensors are configured to publish (send) humidity data to MQTT server.

Example:
```
SYS:MQTT:MASK:VHUM?
1-2
```

#### SYStem:MQTT:MASK:VPREssure
Configure which virtual sensors should publish (send) pressure data to MQTT server.

Sensors can be specified as comma separated list (2,3) or as range (1-3)
or as combination of both.

Default: <empty>   (do not publish data from any sensor)

Example:
```
SYS:MQTT:MASK:VPRE 1,2
```

#### SYStem:MQTT:MASK:VPREssure?
Query which virtual sensors are configured to publish (send) pressure data to MQTT server.

Example:
```
SYS:MQTT:MASK:VPRE?
1-2
```

#### SYStem:MQTT:MASK:FANRPM
Configure which fan ports should publish (send) RPM data to MQTT server.

Ports can be specified as comma separated list (2,3) or as range (1-3)
or as combination of both.

Default: <empty>   (do not publish data from any port)

Example:
```
SYS:MQTT:MASK:FANRPM 1,3,5-8
```

#### SYStem:MQTT:MASK:FANRPM?
Query which fans are configured to publish (send) RPM data to MQTT server.

Example:
```
SYS:MQTT:MASK:FANRPM?
1-8
```

#### SYStem:MQTT:MASK:FANPWM
Configure which fan ports should publish (send) PWM data to MQTT server.

Ports can be specified as comma separated list (2,3) or as range (1-3)
or as combination of both.

Default: <empty>   (do not publish data from any port)

Example:
```
SYS:MQTT:MASK:FANPWM 1-4
```

#### SYStem:MQTT:MASK:FANPWM?
Query which fans are configured to publish (send) PWM data to MQTT server.

Example:
```
SYS:MQTT:MASK:FANPWM?
1-4
```

#### SYStem:MQTT:MASK:MBFANRPM
Configure which mbfan ports should publish (send) RPM data to MQTT server.

Ports can be specified as comma separated list (2,3) or as range (1-3)
or as combination of both.

Default: <empty>   (do not publish data from any port)

Example:
```
SYS:MQTT:MASK:MBFANRPM 1,4
```

#### SYStem:MQTT:MASK:MBFANRPM?
Query which mbfans are configured to publish (send) RPM data to MQTT server.

Example:
```
SYS:MQTT:MASK:MBFANRPM?
1,4
```

#### SYStem:MQTT:MASK:MBFANPWM
Configure which mbfan ports should publish (send) PWM data to MQTT server.

Ports can be specified as comma separated list (2,3) or as range (1-3)
or as combination of both.

Default: <empty>   (do not publish data from any port)

Example:
```
SYS:MQTT:MASK:MBFANPWM 1-2
```

#### SYStem:MQTT:MASK:MBFANPWM?
Query which mbfans are configured to publish (send) PWM data to MQTT server.

Example:
```
SYS:MQTT:MASK:MBFANPWM?
1-2
```

#### SYStem:MQTT:TOPIC:STATus
Configure topic to publish unit status information periodically.
If this is left to empty (string), then no status information is published to MQTT server.

Default: <empty>

Example:
```
SYS:MQTT:TOPIC:STATUS musername/feeds/fanpico1
```

#### SYStem:MQTT:TOPIC:STATus?
Query currently set topic for publishing unit status information to.

Example:
```
SYS:MQTT:TOPIC:STATUS?
myusername/feeds/fanpico1
```

#### SYStem:MQTT:TOPIC:COMMand
Configure topic to subscribe to to wait for commands to control outputs.
If this is left to empty (string), then unit won't subcrible (and accept) any commands from MQTT.

Default: <empty>

Example:
```
SYS:MQTT:TOPIC:COMM musername/feeds/cmd
```

#### SYStem:MQTT:TOPIC:COMMand?
Query currently set topic for subscribing to wait for commands.

Example:
```
SYS:MQTT:TOPIC:COMM?
myusername/feeds/cmd
```

#### SYStem:MQTT:TOPIC:RESPonse
Configure topic to publish responses to commands received from the command topic.
If this is left to empty, then unit won't send response to any commands.

Default: <empty>

Example:
```
SYS:MQTT:TOPIC:RESP musername/feeds/response
```

#### SYStem:MQTT:TOPIC:RESPonse?
Query currently set topic for publishing responses to commands.

Example:
```
SYS:MQTT:TOPIC:RESP?
myusername/feeds/response
```

#### SYStem:MQTT:TOPIC:TEMP
Configure topic template for publishing temperature sensor data to.
If this is left to empty, then unit won't send response to any commands.

This is template string where ```%d``` should be used to mark the port number.

Default: <empty>

Example:
```
SYS:MQTT:TOPIC:TEMP mysername/feeds/temp%d
```

#### SYStem:MQTT:TOPIC:TEMP?
Query currently set topic template for temperature sensor data.

Example:
```
SYS:MQTT:TOPIC:TEMP?
myusername/feeds/temp%d
```

#### SYStem:MQTT:TOPIC:VTEMP
Configure topic template for publishing virtual sensor temperature data to.
If this is left to empty, then unit won't send response to any commands.

This is template string where ```%d``` should be used to mark the port number.

Default: <empty>

Example:
```
SYS:MQTT:TOPIC:VTEMP mysername/feeds/vtemp%d
```

#### SYStem:MQTT:TOPIC:VTEMP?
Query currently set topic template for virtual sensor temperature data.

Example:
```
SYS:MQTT:TOPIC:VTEMP?
myusername/feeds/vtemp%d
```

#### SYStem:MQTT:TOPIC:VHUMidity
Configure topic template for publishing virtual sensor humidity data to.
If this is left to empty, then unit won't send response to any commands.

This is template string where ```%d``` should be used to mark the port number.

Default: <empty>

Example:
```
SYS:MQTT:TOPIC:VHUM mysername/feeds/humidity%d
```

#### SYStem:MQTT:TOPIC:VHUMidity?
Query currently set topic template for virtual sensor humidity data.

Example:
```
SYS:MQTT:TOPIC:VHUM?
myusername/feeds/humidity%d
```

#### SYStem:MQTT:TOPIC:VPREssure
Configure topic template for publishing virtual sensor pressure data to.
If this is left to empty, then unit won't send response to any commands.

This is template string where ```%d``` should be used to mark the port number.

Default: <empty>

Example:
```
SYS:MQTT:TOPIC:VPRE mysername/feeds/pressure%d
```

#### SYStem:MQTT:TOPIC:VPREssure?
Query currently set topic template for virtual sensor pressure data.

Example:
```
SYS:MQTT:TOPIC:VPRE?
myusername/feeds/pressure%d
```

#### SYStem:MQTT:TOPIC:FANRPM
Configure topic template for publishing fan RPM data to.
If this is left to empty, then unit won't send response to any commands.

This is template string where ```%d``` should be used to mark the port number.

Default: <empty>

Example:
```
SYS:MQTT:TOPIC:FANRPM musername/feeds/fanrpm%d
```

#### SYStem:MQTT:TOPIC:FANRPM?
Query currently set topic template for fan RPM data.

Example:
```
SYS:MQTT:TOPIC:FANRPM?
myusername/feeds/fanrpm%d
```

#### SYStem:MQTT:TOPIC:FANPWM
Configure topic template for publishing fan PWM data to.
If this is left to empty, then unit won't send response to any commands.

This is template string where ```%d``` should be used to mark the port number.

Default: <empty>

Example:
```
SYS:MQTT:TOPIC:FANPWM musername/feeds/fanpwm%d
```

#### SYStem:MQTT:TOPIC:FANPWM?
Query currently set topic template for fan PWM data.

Example:
```
SYS:MQTT:TOPIC:FANPWM?
myusername/feeds/fanpwm%d
```

#### SYStem:MQTT:TOPIC:MBFANRPM
Configure topic template for publishing mbfan RPM data to.
If this is left to empty, then unit won't send response to any commands.

This is template string where ```%d``` should be used to mark the port number.

Default: <empty>

Example:
```
SYS:MQTT:TOPIC:MBFANRPM musername/feeds/mbfanrpm%d
```

#### SYStem:MQTT:TOPIC:MBFANRPM?
Query currently set topic template for mbfan RPM data.

Example:
```
SYS:MQTT:TOPIC:MBFANRPM?
myusername/feeds/mbfanrpm%d
```

#### SYStem:MQTT:TOPIC:MBFANPWM
Configure topic template for publishing mbfan PWM data to.
If this is left to empty, then unit won't send response to any commands.

This is template string where ```%d``` should be used to mark the port number.

Default: <empty>

Example:
```
SYS:MQTT:TOPIC:MBFANPWM musername/feeds/mbfanpwm%d
```

#### SYStem:MQTT:TOPIC:MBFANPWM?
Query currently set topic template for mbfan PWM data.

Example:
```
SYS:MQTT:TOPIC:MBFANPWM?
myusername/feeds/mbfanpwm%d
```

#### SYStem:NAME
Set name of the system. (Default: fanpico1)

Example:
```
SYS:NAME HomeServer
```

#### SYStem:NAME?
Get name of the system.

Example:
```
SYS:NAME?
HomeServer
```

#### SYStem:ONEWIRE
<mark>new: release v1.6.4</mark>  \
Enable or disable 1-Wire Bus. This is disabled by default.
Enabling 1-Wire bus allows use of 1-Wire temperature sensors.

Note, unit must be rebooted for the change to take effect.

Example (enable 1-Wire bus):
```
SYS:ONEWIRE ON
```

#### SYStem:ONEWIRE?
<mark>new: release v1.6.4</mark>  \
Return status whether 1-Wire bus is currently enabled or disabled.

Status|Description
------|-----------
ON|Enabled
OFF|Disabled

Example:
```
SYS:ONEWIRE?
OFF
```

#### SYStem:ONEWIRE:SENSORS?
<mark>new: release v1.6.4</mark>  \
Return list of currently active (detected at boot time) 1-Wire bus devices, and last temperature
measurement results.

Output format: <sensor number>,<onewire address>,<temperature>

Example:
```
SYS:ONEWIRE:SENSORS?
1,28821e6a000000cf,23.4
2,2871d86a0000005a,23.0
3,22a275180000003c,23.9
```

#### SYStem:SENSORS?
Display number of (temperature) sensors available.
Last temperature sensor is the internal temperature sensor on the
RP2040.

Example:
```
SYS:SENSORS?
3
```

#### SYStem:SERIAL
Enable or disable TTL Serial Console. This is enabled by default if board has this connector.
Reason to disable this could be to use the second I2C bus that is sharing pins with the UART.

Example (disable serial console):
```
SYS:SERIAL OFF
```

#### SYStem:SERIAL?
Return status of TTL Serial Console.

Status|Description
------|-----------
ON|Enabled
OFF|Disabled

Example:
```
SYS:SERIAL?
ON
```

### SYStem:SNMP Commands

#### SYStem:SNMP:AGENT
Enable or disable SNMP Agent. This is disabled by default.

Example (enable SNMP Agent):
```
SYS:SNMP:AGET ON
CONF:SAVE
*RST
```

#### SYStem:SNMP:AGENT?
Return status of SNMP Agent.

Status|Description
------|-----------
ON|Enabled
OFF|Disabled

Example:
```
SYS:SNMP:AGENT?
ON
```

#### SYStem:SNMP:COMMunity
Set SNMP (read-only) community name. (Default: public)

Example:
```
SYS:SNMP:COMM secret123
```

#### SYStem:SNMP:COMMunity?
Display current SNMP (read-only) community name.

Example:
```
SYS:SNMP:COMM?
public
```

#### SYStem:SNMP:CONTact
Set system contact information (sysContact). (Default is no contact information.)

Example:
```
SYS:SNMP:CONTACT B.O.F.H.
```

#### SYStem:SNMP:CONTact?
Display current SNMP system contact information (sysContact).

Example:
```
SYS:SNMP:CONT?
B.O.F.H.
```

#### SYStem:SNMP:LOCAtion
Set system location information (sysLocation). (Default is no location information.)

Example:
```
SYS:SNMP:LOCA Server Room
```

#### SYStem:SNMP:LOCAtion?
Display current SNMP system location information (sysLocation).

Example:
```
SYS:SNMP:LOCA?
Server Room
```

#### SYStem:SNMP:WRITecommunity
Set SNMP (write) community name. (Default: <empty>)

Note, when this is set to empty value (string), SNMP write access is disabled.

Example:
```
SYS:SNMP:WRIT secret456
```

#### SYStem:SNMP:WRITecommunity?
Display current SNMP (write) community name.

Example:
```
SYS:SNMP:WRIT?
private
```

#### SYStem:SNMP:TRAPs:AUTH
Enable or disable sending authentication traps.

Example:
```
SYS:SNMP:TRAP:AUTH ON
```

#### SYStem:SNMP:TRAPs:AUTH?
Display status of sending of authentication traps.

Example:
```
SYS:SNMP:TRAP:AUTH?
OFF
```

#### SYStem:SNMP:TRAPs:COMMunity
Set SNMP traps community name. (Default: <one>)

To enable SNMP traps both trap community and trap destination (IP) must be set.

Example:
```
SYS:SNMP:TRAP:COMM public
```

#### SYStem:SNMP:TRAPs:COMMunity?
Display current SNMP traps community name.

Example:
```
SYS:SNMP:TRAP:COMM?
public
```

#### SYStem:SNMP:TRAPs:DESTination
Set destination IP address for sending SNMP traps to.

To disable sending traps, set IP to: 0.0.0.0

(Default: 0.0.0.0)

Example:
```
SYS:SNMP:TRAP:DEST 192.168.42.42
```

#### SYStem:SNMP:TRAPs:DESTination?
Display current SNMP trap destination IP?

Example:
```
SYS:SNMP:TRAP:DEST?
192.168.42.42
```

#### SYStem:SPI
Enable or disable SPI bus (on boards that have "SPI" connector).
Reason to enable SPI bus would be to connect LCD panel on the SPI connector.

NOTE! On 0804D boards, when SPI bus is enabled I2C (OLED display) and Serial (TTL) connectors cannot be used
as these share pins with the SPI bus.

Example (enable SPI bus):
```
SYS:SPI 1
```

#### SYStem:SPI?
Return status of SPI bus.

Status|Description
------|-----------
1|Enabled
0|Disabled

Example:
```
SYS:SPI?
0
```

### SSH Server Commands

#### SYStem:SSH:SERVer
Control whether SSH server is enabled or not.
After making change configuration needs to be saved and unit reset.

Default: OFF

Example:
```
SYS:SSH:SERV ON
```

#### SYStem:SSH:SERVer?
Display whether SSH server status.

Example:
```
SYS:SSH:SERV?
OFF
```

#### SYStem:SSH:ACLs
Configure ACL(s) to limit from which subnets (or IPs) connnections
to SSH server is allowed.
If no ACLs have been setup then connections from any (source) IP is allowed.

Default: 0.0.0.0/0  (none)

Example (allow subnet 192.168.1.0/255.255.255.0 and single IP 172.30.1.42):
```
SYS:SSH:ACLS 192.168.1.0/24,172.30.1.42/32
```

Example (remove all ACLs):
```
SYS:SSH:ACLS 0.0.0.0/0
```

#### SYStem:SSH:ACLs?
Display currently configured ACL(s) for the SSH server.
If no ACLs have been setup then connections from any (source) IP is allowed.

Example:
```
SYS:SSH:ACLs?
192.168.1.0/24, 172.30.1.42/32
```

#### SYStem:SSH:AUTH
Toggle SSH server authentication mode. When enabled then SSH server will
require user to authenticate (password or publickey authentication).
When off, no authentication is needed.

Default: ON

Example:
```
SYS:SSH:AUTH OFF
```

#### SYStem:SSH:AUTH?
Display whether SSH server authentication is enabled or not.

Example:
```
SYS:SSH:AUTH?
ON
```

#### SYStem:SSH:PORT
Set TCP port where SSH server will listen on.
If this setting is not set then default port will be used.

Default: 22 (default SSH port)

Example:
```
SYS:SSH:PORT 8022
```

#### SYStem:SSH:PORT?
Display currently configured port for SSH server.

(if port is set to 0, then default Telnet port will be used)

Example:
```
SYS:SSH:PORT?
8022
```

#### SYStem:SSH:USER
Configure username that is allowed to login to this server using SSH.

When no username is set, password authentication is disabled.

Default: <none>

Example (set username):
```
SYS:SSH:USER admin
```

Example (remove username):
```
SYS:SSH:USER
```

#### SYStem:SSH:USER?
Display currently configured SSH user (login) name.

When no username is set, password authentication is disabled.

Example:
```
SYS:SSH:USER?
admin
```

#### SYStem:SSH:PASSword
Configure password for the SSH user. Password is hashed using SHA-512 Crypt algorithm.

Default: <none>

Example (set passwod):
```
SYS:SSH:PASS mypassword
```

Example (remove password):
```
SYS:SSH:PASS
```

#### SYStem:SSH:PASSword?
Display currently configured SSH user password hash.

When no password is set, password authentication is disabled.

Example:
```
SYS:SSH:PASS?
$6$QvD5AkWSuydeH/EB$UsYA0cymsCRSse78fN4bMb5q0hM5B7YUNSFd3zJfMDbTG7DOH8iuMufVjsvqBOxR9YCJYSHno4CFeOhLtTGLx.
```

#### SYStem:SSH:KEY?
Display list of server private keys. Currently there is no support to
extract/export private keys. This command only displays SHA256 checksums for
each key.

Example:
```
SYS:SSH:KEY?
ecdsa                     121 SHA256:bDd9a2FrWRCyGxwgNZzzejEh+0ivXkww6nbM+4cIfSg
ed25519                    82 SHA256:/si832zNTkrxn0MHh8dhwfa6KlDAPcTRHsoqZbeVaSM
```

#### SYStem:SSH:KEY:CREate
Create SSH Server Private Key. Generated key is saved on the filesystem (littlefs) and
is used by the SSH server as its server private key.

Command takes key type as parameter.

Currently supported key types:

 - ECDSA
 - ED25519
 - ALL (create all supported keys)

Example:
```
SYS:SSH:KEY:CREATE ED25519
Generating ed25519 private key...
OK
```

#### SYStem:SSH:KEY:DELete
Delete SSH Server Private key. Key is deleted from the internal filesystem (littlefs).
When rotating server keys, old key must be first removed, before new one can be created.

Command takes key type as parameter.

Example:
```
SYS:SSH:KEY:DEL ECDSA
Deleting ecdsa private key...
Private key deleted.
```

#### SYStem:SSH:KEY:LIST?
Display list of server private keys.
This is same as command SYS:SSH:KEY?

#### SYStem:SSH:PUBKEY?
Display list of user name and public key pairs that can be used to login
using publicky authentication.

Example:
```
SYS:SSH:PUBKEY?
1: admin ssh-ed25519 AAAAC3NzaC1lZDI1NTE5AAAAIOOWu9+yEevReQUXEDgEMAIrs1DERTwZeSRRhIqioC6x admin@ws1
2: testuser ecdsa-sha2-nistp256 AAAAE2VjZHNhLXNoYTItbmlzdHAyNTYAAAAIbmlzdHAyNTYAAABBBH+E8WDRmrU2fKizKDyQXdLj3YGh7w5Wl7F2clpzHvGWIoBAJ/nsyUpMCqujzG7eD0EOKukBcb6vqyf2IQ96GLU= testuser@localhost
```

#### SYStem:SSH:PUBKEY:ADD
Add SSH public key for user to authenticate with.
Command takes two parameters "username", and "public key" (in OpenSSH format).
Currently up to 4 pubic keys can be added.

Parameters: <username> <ssh publickey>

Example:
```
SYS:SSH:PUBKEY ADD amdin ssh-ed25519 AAAAC3NzaC1lZDI1NTE5AAAAIOOWu9+yEevReQUXEDgEMAIrs1DERTwZeSRRhIqioC6x admin@ws1
SSH Public key added: slot 1: ssh-ed25519 (admin)
```

#### SYStem:SSH:PUBKEY:DELete
Delete SSH Public key.

Parameters: <key number>

(Command SYS:SSH:PUBKEY? can be used to find out key numbers.)

Example:
```
SYS:SSH:PUBKEY:DEL 1
SSH Public key deleted: slot 1: admin:ssh-ed25519 (admin@ws1)
```

#### SYStem:SSH:PUBKEY:LIST?
Display list of user name and public key pairs that can be used to login
This is same as SYS:SSH:PUBKEY?

### Telnet Server Commands

#### SYStem:TELNET:SERVer
Control whether Telnet server is enabled or not.
After making change configuration needs to be saved and unit reset.

Default: OFF

Example:
```
SYS:TELNET:SERV ON
```

#### SYStem:TELNET:SERVer?
Display whether Telnet server status.

Example:
```
SYS:TELNET:SERV?
OFF
```

#### SYStem:TELNET:ACLs
Configure ACL(s) to limit from which subnets (or IPs) connnections
to Telnet server is allowed.
If no ACLs have been setup then connections from any (source) IP is allowed.

Default: 0.0.0.0/0 (none)

Example (allow subnet 192.168.1.0/255.255.255.0 and single IP 172.30.1.42):
```
SYS:TELNET:ACLS 192.168.1.0/24,172.30.1.42/32
```

Example (remove all ACLs):
```
SYS:TELNET:ACLS 0.0.0.0/0
```

#### SYStem:TELNET:ACLs?
Display currently configured ACL(s) for the Telnet server.
If no ACLs have been setup then connections from any (source) IP is allowed.

Example:
```
SYS:TELNET:ACLs?
192.168.1.0/24, 172.30.1.42/32
```

#### SYStem:TELNET:AUTH
Toggle Telnet server authentication mode. When enabled then Telnet server will
prompt user for login/password. When off, no authentication is needed.

Default: ON

Example:
```
SYS:TELNET:AUTH OFF
```

#### SYStem:TELNET:AUTH?
Display whether Telnet server authentication is enabled or not.

Example:
```
SYS:TELNET:AUTH?
ON
```

#### SYStem:TELNET:PORT
Set TCP port where Telnet server will listen on.
If this setting is not set then default port will be used.

Default: 23 (default Telnet port)

Example:
```
SYS:TELNET:PORT 8000
```

#### SYStem:TELNET:PORT?
Display currently configured port for Telnet server.

(if port is set to 0, then default Telnet port will be used)

Example:
```
SYS:TELNET:PORT?
8000
```

#### SYStem:TELNET:RAWmode
Configure Telnet server mode. By default Telnet server uses Telnet protocol, but
setting this option causes Telnet protocol to be disabled. And server uses "raw TCP" mode.

Default: OFF

Example:
```
SYS:TELNET:RAW ON
```

#### SYStem:TELNET:RAWmode?
Display if "raw TCP" mode is enabled or not.

Example:
```
SYS:TELNET:RAW?
OFF
```

#### SYStem:TELNET:USER
Configure username that is allowed to login to this server using Telnet.

Default: <none>

Example:
```
SYS:TELNET:USER admin
```

#### SYStem:TELNET:USER?
Display currently configured telnet user (login) name.

Example:
```
SYS:TELNET:USER?
admin
```

#### SYStem:TELNET:PASSword
Configure password for the telnet user. Password is hashed using SHA-512 Crypt algorithm.

Default: <none>

Example:
```
SYS:TELNET:PASS mypassword
```

#### SYStem:TELNET:PASSword?
Display currently configured telnet user password hash.

Example:
```
SYS:TELNET:PASS?
$6$QvD5AkWSuydeH/EB$UsYA0cymsCRSse78fN4bMb5q0hM5B7YUNSFd3zJfMDbTG7DOH8iuMufVjsvqBOxR9YCJYSHno4CFeOhLtTGLx.
```

#### SYStem:TIME
Set system Real-Time Clock (RTC) time.

This command expects time in following format:
  YYYY-MM-DD HH:MM:SS

Example:
```
SYS:TIME 2022-09-19 18:55:42
```

#### SYStem:TIME?
Return current Real-Time Clock (RTC) time.
This is only available if using Pico W and it has successfully
gotten time from a NTP server or RTC has been initialized using
SYStem:TIME command.

Command returns nothing if RTC has not been initialized.

Example:
```
SYS:TIME?
2022-09-19 18:55:42
```

#### SYStem:TIMEZONE
Set POSIX timezone to use when getting time from a NTP server.
If DHCP server does not supply POSIX Timezone (DHCP Option 100), then this
command can be used to specify local timezone.

This command takes POSIX timezone string as argument (or if argument is blank,
then it clears existinh timezone setting).

Example (set Pacific Standard time as local timezone):
```
SYS:TIMEZONE PST8PDT7,M3.2.0/2,M11.1.0/02:00:00
```

Example (clear timezone setting):
```
SYS:TIMEZONE
```

#### SYStem:TIMEZONE?
Return current POSIX timezone setting.

Command returns nothing if no timezone has been set.

Example:
```
SYS:TIMEZONE?
PST8PDT7,M3.2.0/2,M11.1.0/02:00:00
```

#### SYStem:TLS:CERT
Upload or delete TLS certificate for the HTTP server.
Note, both certificate and private key must be installed before HTTPS server will
activate (when system is restarted next time).

When run without arguments this will prompt to paste TLS (X.509) certificate
in PEM format.  When run with "DELETE" argument currently installed certificate
will be deleted.

Example (upload/paste certificate):
```
SYS:TLS:CERT
Paste certificate in PEM format:

```

Example (delete existing certificate from flash memory):
```
SYS:TLS:CERT DELETE
```

#### SYStem:TLS:CERT?
Display currently installed certificate.

Example:
```
SYS:TLS:CERT?
```

#### SYStem:TLS:PKEY
Upload or delete (TLS Certificate) Private key for the HTTP server.
Note, both certificate and private key must be installed before HTTPS server will
activate (when system is restarted next time).

When run without arguments this will prompt to paste private key
in PEM format.  When run with "DELETE" argument currently installed private key
will be deleted.

Example (upload/paste private key):
```
SYS:TLS:PKEY
Paste private key in PEM format:

```

Example (upload/paste EC private key and EC parameters):
```
SYS:TLS:PKEY 2
Paste private key in PEM format:

```

Example (delete existing private key from flash memory):
```
SYS:TLS:PKEY DELETE
```

#### SYStem:TLS:PKEY?
Display currently installed private key.

Example:
```
SYS:TLS:CERT?
```

#### SYStem:UPTIme?
Return time elapsed since unit was last rebooted (soft reset).
Command also returns total time unit has been on since last cold reset
and number of times unit has been soft reset since.

Example:
```
SYS:UPTIME?
10:58:40 up 0 days, 02:32
since cold boot 1 days, 11:39 (soft reset count: 5)
```

#### SYStem:UPGRADE
Reboot unit to USB (BOOTSEL) mode for firmware upgrade.
This command triggers fanpico to reboot and enter USB "mode", where
new firmware can simply be copied to the USB drive that appears.
After file has been copied, fanpico will automatically reboot to new
firmware image.

Example:
```
SYS:VER?
```

#### SYStem:VERsion?
Display software version and copyright information.

Example:
```
SYS:VER?
```

#### SYStem:VSENSORS?
Display number of virtual (temperature) sensors available.

Example:
```
SYS:VSENSORS?
8
```

#### SYStem:VREFadc
<mark>new: release v1.6.4</mark>  \
Set actual (measured with a volt meter) reference voltage (Vref) for ADC.

Example:
```
SYS:VREFADC
3.002
```

#### SYStem:VREFadc?
<mark>new: release v1.6.4</mark>  \
Display currently configured ADC voltage reference voltage.

Example:
```
SYS:VREFADC?
3.0000
```

#### SYStem:WIFI?
Check if the unit support WiFi networking.
This should be used to determine if any other "WIFI"
commands will be available.

Return values:

0 = No WiFi support (Pico).
1 = WiFi supported (Pico W).

Example:
```
SYS:WIFI?
1
```

#### SYStem:WIFI:AUTHmode
Set Wi-Fi Authentication mode.

Following modes are currently supported:

Mode|Description|Notes
----|-----------|-----
default|Use system default|Currently default is WPA2
WPA3_WPA2|Use WPA3/WPA2 (mixed) mode|
WPA3|Use WPA3 only|
WPA2|Use WPA2 only|
WPA2_WPA|Use WPA2/WPA (mixed) mode|Not recommended.
WPA|Use WPA only|Not recommended.
OPEN|Use "Open" mode|No authentication.

Example:
```
SYS:WIFI:AUTH WPA3_WPA2
```

#### SYStem:WIFI:AUTHmode?
Return currently configured Authentication mode for the WiFi interface.

Example:

```
SYS:WIFI:AUTH?
default
```

#### SYStem:WIFI:COUntry
Set Wi-Fi Country code. By default, the country setting for the wireless adapter is unset.
This means driver will use default world-wide safe setting, which can mean that some channels
are unavailable.

Country codes are two letter (ISO 3166) codes. For example, Finland = FI, Great Britain = GB,
United States of Americ = US, ...

Example:
```
SYS:WIFI:COUNTRY US
```

#### SYStem:WIFI:COUntry?
Return currently configured country code for the Wi-Fi interface.

Codes used are the ISO 3166 standard two letter codes ('XX' means unset/worldwide setting).

Example:

```
SYS:WIFI:COUNTRY?
US
```

#### SYStem:WIFI:HOSTname
Set system hostname. This will be used with DHCP and SYSLOG.
If hostname is not defined then system will default to generating
hostname as follows:
  FanPico-xxxxxxxxxxxxxxxx

(where "xxxxxxxxxxxxxxxx" is the FanPico serial number)

Example:
```
SYS:WIFI:HOSTNAME fanpico1
```

#### SYStem:WIFI:HOSTname?
Return currently configured system hostname.

Example:

```
SYS:WIFI:HOSTNAME?
fanpico1
```

#### SYStem:WIFI:IPaddress
Set staticlly configured IP address.

Set address to "0.0.0.0" to enable DHCP.

Example:

```
SYS:WIFI:IP 192.168.1.42
```

#### SYStem:WIFI:IPaddress?
Display currently configured (static) IP address.
If no static address is configured, DHCP will be used.

Set address to "0.0.0.0" to enable DHCP.

Example:

```
SYS:WIFI:IP?
0.0.0.0
```

#### SYStem:WIFI:MODE
Set WiFi connection mode. Normally this setting is not needed with modern APs.

However, if FanPico is failing to connect to WiFi network, this couldbe
due to old firmware on the AP (upgrading to latest firmware typically helps).
If firmware update did not help or there is no updated firmware available, setting
connection mode to synchronous can help (however this could cause FanPico to "hang" for up to 60 seconds
during boot up).

Mode|Description
------|-----------
0|Asynchronous connection mode (default)
1|Synchronous connection mode (

Default: 0

Example:

```
SYS:WIFI:MODE 1
```

#### SYStem:WIFI:MODE?
Display currently configured WiFi connection mode?

Example:

```
SYS:WIFI:MODE?
0

```

#### SYStem:WIFI:NETMASK
Set statically configured netmask.

Example:

```
SYS:WIFI:NETMASK 255.255.255.0
```

#### SYStem:WIFI:NETMASK?
Display currently configured (static) netmask.

Example:

```
SYS:WIFI:NETMASK?
255.255.255.0
```

#### SYStem:WIFI:GATEWAY
Set statically configured default gateway (router).

Example:

```
SYS:WIFI:GATEWAY 192.168.1.1
```

#### SYStem:WIFI:GATEWAY?
Display currently configured default gateway (router).

Example:

```
SYS:WIFI:GATEWAY?
192.168.1.1
```

#### SYStem:WIFI:DNS
Configure (static) DNS Server IP addresses.

Note, set to "0.0.0.0" to use servers provided by DHCP.

Example (configure two DNS servers):

```
SYS:WIFI:DNS 8.8.8.8,8.8.4.4
```

Example (configure one DNS server):
```
SYS:WIFI:DNS 192.168.1.1
```

#### SYStem:WIFI:DNS?
Display currently configured (static) DNS Server IP addresses.

If DHCP is active, it may configure DNS servers. To see currently
active DNS servers see SYS:WIFI:INFO?

Example:

```
SYS:WIFI:DNS?
8.8.8.8, 8.8.4.4
```

#### SYStem:NTPClient
Enable or disable NTP client that sychronizes clock to network time server time.

Default: ON

Example (disable NTP client):
```
SYS:NTPC OFF
```

#### SYStem:NTPClient?
Query currently status of NTP client.

Example:
```
SYS:NTPC?
ON
```

#### SYStem:WIFI:NTPservers
Configure IP for NTP server to use.

Set to "0.0.0.0" to use server provided by DHCP.

Example:

```
SYS:WIFI:NTP 192.168.1.10,192.168.1.11
```

#### SYStem:WIFI:NTPservers?
Display currently configure NTP server.

Note, "0.0.0.0" means to use DHCP.

Example:

```
SYS:WIFI:NTP?
192.168.1.10
```
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

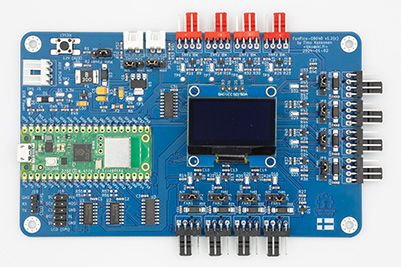
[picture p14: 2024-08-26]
images/fanpico-0804D-v1.2c-small.jpg

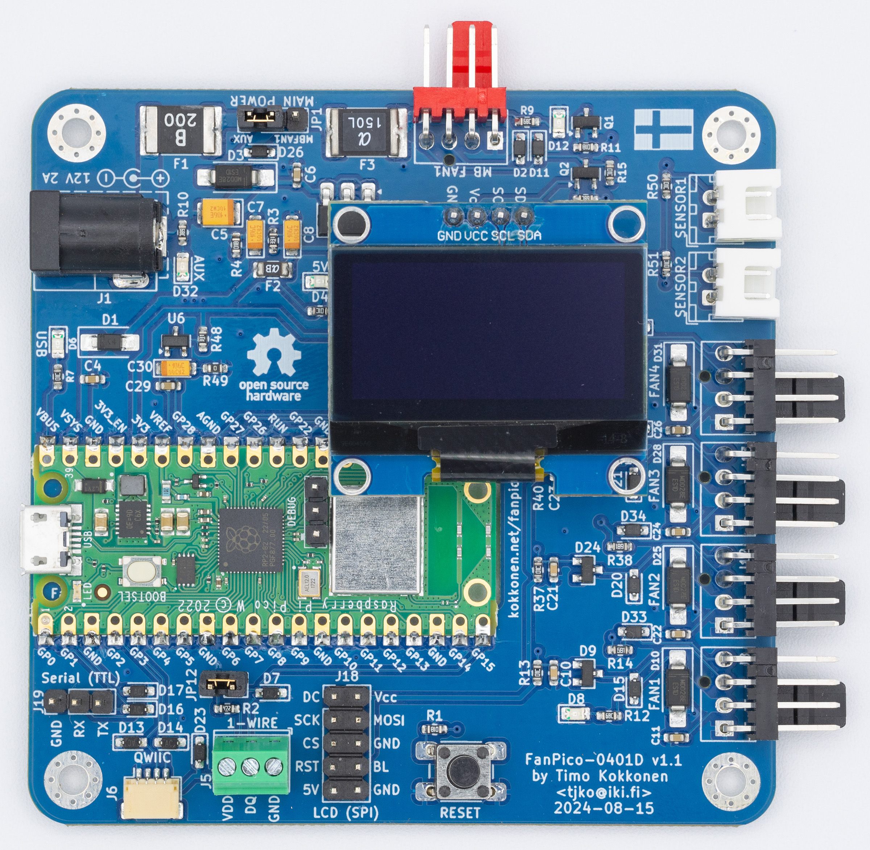
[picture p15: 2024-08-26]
images/fanpico-0401D-large.jpg

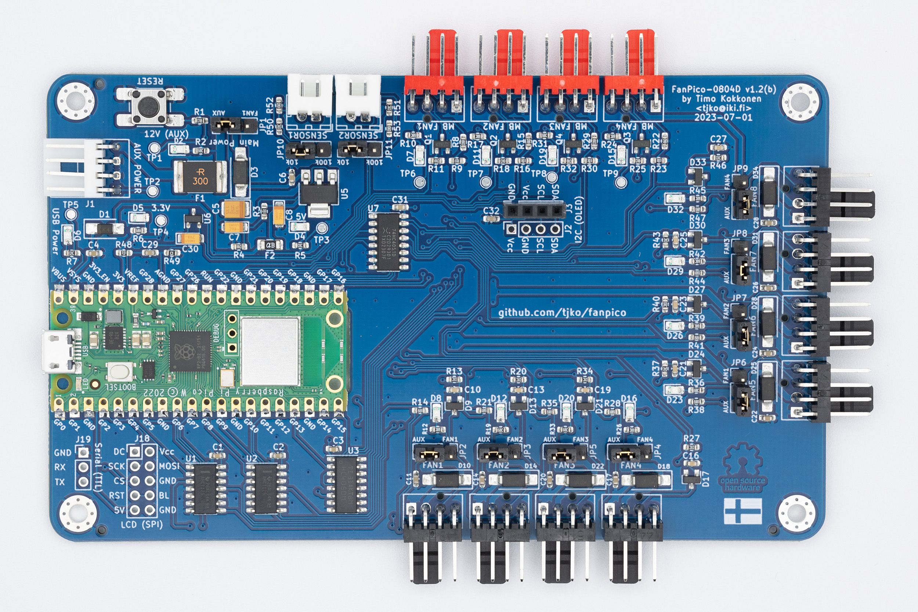
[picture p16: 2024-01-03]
images/fanpico-0804D-v1.2b-large.jpg

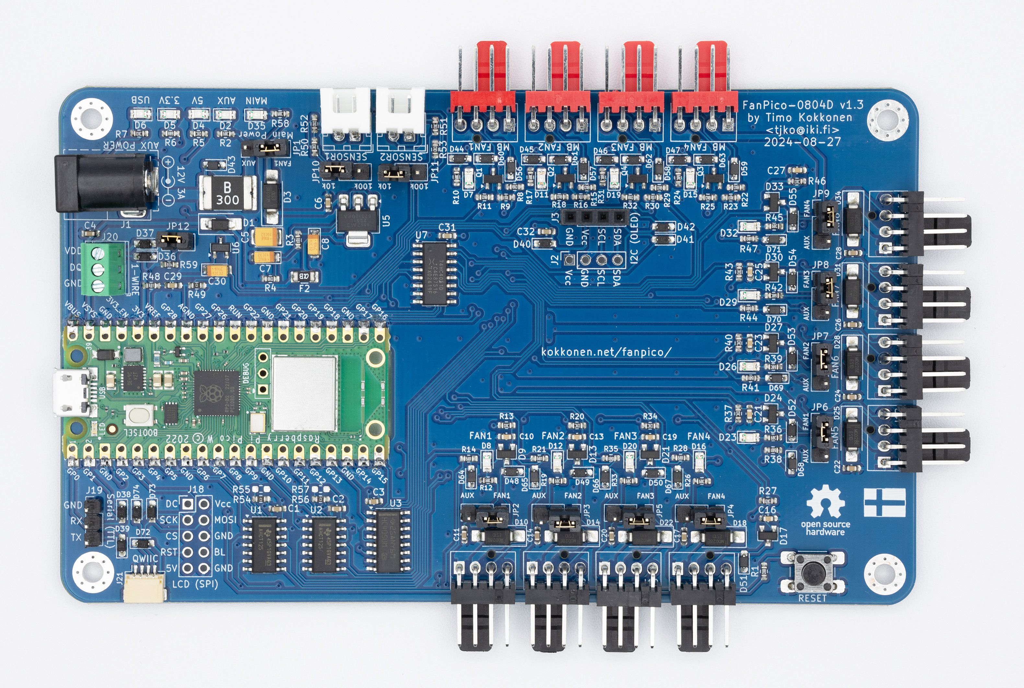
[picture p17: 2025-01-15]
images/fanpico-0804D-v1.3-dc-large.jpg

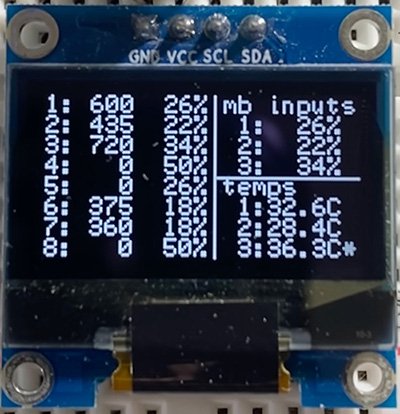
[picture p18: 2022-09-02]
images/oled-status-screen-1.jpg

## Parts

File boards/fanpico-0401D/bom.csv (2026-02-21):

Reference | Value | Datasheet | Footprint | Qty | DNP | Mouser Part Number | LCSC Part Number | Manufacturer | Manufacturer Part Number | Type | Notes
C1,C4,C6,C11,C22,C24,C26,C29,C32 | 0.1uF | ~ | Capacitor_SMD:C_0603_1608Metric_Pad1.08x0.95mm_HandSolder | 9 |  |  | C1591 | Samsung Electro-Mechanics | CL10B104KB8NNNC | SMD
C5 | 10uF 25V | ~ | Capacitor_Tantalum_SMD:CP_EIA-3528-12_Kemet-T_Pad1.50x2.35mm_HandSolder | 1 |  |  | C7194 | Kyocera AVX | TAJB106K025RNJ | SMD
C7,C8,C30 | 10uF 16V | ~ | Capacitor_Tantalum_SMD:CP_EIA-3216-18_Kemet-A_Pad1.58x1.35mm_HandSolder | 3 |  | 80--T491A106K016 | C7171 | Kyocera AVX | TAJA106K016RNJ | SMD
C10,C21,C23,C25 | 1nF | ~ | Capacitor_SMD:C_0603_1608Metric_Pad1.08x0.95mm_HandSolder | 4 |  |  | C1588 | Samsung Electro-Mechanics | CL10B102KB8NNNC | SMD
D1 | SM5819PL 1A 40V | ~ | Diode_SMD:D_SMA | 1 |  | 833-SM5819PL-TP | C669023 | MCC | SM5819PL-TP | SMD
D2,D15,D20,D21,D22,D26 | 12V TVS | ~ | Diode_SMD:D_SOD-323_HandSoldering | 6 |  |  | C502541 or C5199168 | MDD(Microdiode Semiconductor) | GBLC12C | SMD
D3,D10,D25,D28,D31 | ES1D 1A 200V | ~ | Diode_SMD:D_SMA_Handsoldering | 5 |  | 512-ES1D | C445494 | MDD(Microdiode Semiconductor) | ES1D | SMD
D4,D5,D6,D8,D12,D32 | LED 0805 (green) | ~ | LED_SMD:LED_0805_2012Metric_Pad1.15x1.40mm_HandSolder | 6 |  | 710-150080GS75000 | C434432 | Yongyu Photoelectric | SZYY0805G | SMD
D7,D13,D14,D16,D17,D18,D19,D23,D29 | 3.3V TVS | ~ | Diode_SMD:D_SOD-323_HandSoldering | 9 |  |  | C78439 | Brightking | UDD32C03L01 | SMD
D9,D24,D27,D30 | BAT54(C) | ~ | FanPico:D_SOT-23_ANK | 4 |  | 241-BAT54C_R1_00001 | C2844172 | FUXINSEMI | BAT54C | SMD
D11,D33,D34,D35,D36 | 5V TVS | ~ | Diode_SMD:D_SOD-323_HandSoldering | 5 |  |  | C5180216 | ElecSuper | PESD5V0S1BA-ES | SMD
F1 | Polyfuse 2A | ~ | Fuse:Fuse_2920_7451Metric_Pad2.10x5.45mm_HandSolder | 1 |  |  | C910843 | BHFUSE | BSMD2920-200-33V | SMD
F2 | Polyfuse 0.5A | ~ | Fuse:Fuse_1206_3216Metric_Pad1.42x1.75mm_HandSolder | 1 |  | 530-0ZCJ0050AF2E | C70072 | TECHFUSE | nSMD035-16V | SMD
F3 | Polyfuse 1.5A | ~ | Fuse:Fuse_2920_7451Metric_Pad2.10x5.45mm_HandSolder | 1 |  |  | C70138 or C22447157 | TECHFUSE | SMD150L | SMD
G1 | qwiic_Logo |  | sparkfun-qwiic:qwiic_5mm | 1
H1,H2,H3,H4 | MountingHole_Pad | ~ | MountingHole:MountingHole_3.2mm_M3_Pad_Via | 4 | DNP | N/A | N/A
J1 | Floppy / DC Connector | ~ | FanPico:TE 171826-4 Floppy 4-pin Combo | 1 |  |  | C590635 / C720558 | XUNPU | DC-005-A250 | THT
J2 | I2C (OLED ALT) | ~ | Connector_PinSocket_2.54mm:PinSocket_1x04_P2.54mm_Vertical | 1 | DNP |  | C2935975 | DEALON | DM254R-11-04-85 | THT
J3 | I2C (OLED) | ~ | Connector_PinSocket_2.54mm:PinSocket_1x04_P2.54mm_Vertical | 1 |  |  | C2935975 | DEALON | DM254R-11-04-85 | THT
J4 | MB Fan1 Input | ~ | Connector:FanPinHeader_1x04_P2.54mm_Vertical | 1 |  | 538-47053-1000 | C240840 | MOLEX | 470531000 | THT | KF2510-AW 3+1P (Red)
J5 | 1-Wire | ~ | TerminalBlock_TE-Connectivity:TerminalBlock_TE_282834-3_1x03_P2.54mm_Horizontal | 1 |  |  | C68305 or C5188443 | BOOMELE(Boom Precision Elec) | 2.54-3P | THT
J6 | QWIIC | ~ | Connector_JST:JST_SH_SM04B-SRSS-TB_1x04-1MP_P1.00mm_Horizontal | 1 |  |  | C160404 | JST | SM04B-SRSS-TB(LF)(SN) | SMD
J8 | Fan1 Output | ~ | Connector:FanPinHeader_1x04_P2.54mm_Vertical | 1 |  | 538-47053-1000 | C240840 | MOLEX | 470531000 | THT | KF2510-AW 3+1P (Black)
J12 | Fan2 Output | ~ | Connector:FanPinHeader_1x04_P2.54mm_Vertical | 1 |  | 538-47053-1000 | C240840 | MOLEX | 470531000 | THT | KF2510-AW 3+1P (Black)
J13 | Fan3 Output | ~ | Connector:FanPinHeader_1x04_P2.54mm_Vertical | 1 |  | 538-47053-1000 | C240840 | MOLEX | 470531000 | THT | KF2510-AW 3+1P (Black)
J14 | Fan4 Output | ~ | Connector:FanPinHeader_1x04_P2.54mm_Vertical | 1 |  | 538-47053-1000 | C240840 | MOLEX | 470531000 | THT | KF2510-AW 3+1P (Black)
J16 | Sensor1 | ~ | Connector_JST:JST_XH_B2B-XH-A_1x02_P2.50mm_Vertical | 1 |  |  | C158012 | JST | B2B-XH-A(LF)(SN) | THT
J17 | Sensor2 | ~ | Connector_JST:JST_XH_B2B-XH-A_1x02_P2.50mm_Vertical | 1 |  |  | C158012 | JST | B2B-XH-A(LF)(SN) | THT
J18 | LCD (SPI) | ~ | Connector_PinHeader_2.54mm:PinHeader_2x05_P2.54mm_Vertical | 1 |  |  | C492422 | XFCN | PZ254V-12-10P | THT
J19 | Serial Console (TTL) | ~ | Connector_PinHeader_2.54mm:PinHeader_1x03_P2.54mm_Vertical | 1 |  |  | C2937625 | XFCN | PZ254V-11-03P | THT
JP1 | Power Selector | ~ | Connector_PinHeader_2.54mm:PinHeader_1x03_P2.54mm_Vertical | 1 |  |  | C2937625 | XFCN | PZ254V-11-03P | THT
JP12 | 1-Wire PullUp Enable | ~ | Connector_PinHeader_2.54mm:PinHeader_1x02_P2.54mm_Vertical | 1 |  |  | C492401 | XFCN | PZ254V-11-02P | THT
Q1,Q2 | 2N7002K | https://www.diodes.com/assets/Datasheets/2N7002K.pdf | Package_TO_SOT_SMD:SOT-23 | 2 |  | 512-2N7002K | C85047 | DIODES | 2N7002K-7 | SMD
R1,R4,R11 | 1k | ~ | Resistor_SMD:R_0603_1608Metric_Pad0.98x0.95mm_HandSolder | 3 |  |  | C22548 | YAGEO | RC0603FR-071KL | SMD
R2 | 4.7k | ~ | Resistor_SMD:R_0603_1608Metric_Pad0.98x0.95mm_HandSolder | 1 |  |  | C99782 | YAGEO | RC0603FR-074K7L | SMD
R3,R48 | 330 | ~ | Resistor_SMD:R_0603_1608Metric_Pad0.98x0.95mm_HandSolder | 2 |  |  | C105881 | YAGEO | RC0603FR-07330RL | SMD
R5,R7,R13,R15,R37,R40,R43,R50,R51 | 10k | ~ | Resistor_SMD:R_0603_1608Metric_Pad0.98x0.95mm_HandSolder | 9 |  |  | C98220 | YAGEO | RC0603FR-0710KL | SMD
R6 | 4.99k | ~ | Resistor_SMD:R_0603_1608Metric_Pad0.98x0.95mm_HandSolder | 1 |  |  | C114621 | YAGEO | RC0603FR-074K99L | SMD
R9,R10,R12,R16 | 49.9k | ~ | Resistor_SMD:R_0603_1608Metric_Pad0.98x0.95mm_HandSolder | 4 |  |  | C114624 | YAGEO | RC0603FR-0749K9L | SMD
R14,R38,R41,R44 | 680 | ~ | Resistor_SMD:R_0603_1608Metric_Pad0.98x0.95mm_HandSolder | 4 |  |  | C115415 | YAGEO | RC0603JR-07680RL | SMD
R49,R55 | 0 | ~ | Resistor_SMD:R_0603_1608Metric_Pad0.98x0.95mm_HandSolder | 2 |  |  | C100044 / C21189 | YAGEO | RC0603FR-070RL | SMD
R54 | 0 | ~ | Resistor_SMD:R_0603_1608Metric_Pad0.98x0.95mm_HandSolder | 1 | DNP |  | C100044 / C21189 | YAGEO | RC0603FR-070RL | SMD
SW1 | SW_Push | ~ | FanPico:SW_PUSH_6mm_SMD_2 | 1 |  |  | C221880 | C&K | PTS645SM43SMTR92LFS | THT
U1 | SN74AHCT126 | (AHCT125 = C36365, AHCT126 = C155177) | Package_SO:TSSOP-14_4.4x5mm_P0.65mm | 1 |  |  | C155177 | TI | SN74AHCT126PWR | SMD
U4 | Pico W |  | FanPico:RPi_Pico_PicoW_SMD_TH | 1 |  |  |  | Raspberry Pi | Pico W | SMD
U5 | SPX1117-ADJ | http://www.diodes.com/datasheets/AP1117.pdf | Package_TO_SOT_SMD:SOT-223-3_TabPin2 | 1 |  |  | C67402 | MaxLinear | SPX1117M3-L/TR | SMD
U6 | LM4040DBZ-3 | http://www.ti.com/lit/ds/symlink/lm4040-n.pdf | Package_TO_SOT_SMD:SOT-23 | 1 |  |  | C143326 | MAXIM | LM4040AIM3-3.0+T | SMD

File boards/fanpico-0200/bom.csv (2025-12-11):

Reference | Value | Datasheet | Footprint | Qty | DNP | Mouser Part Number | LCSC Part Number | Manufacturer | Manufacturer Part Number | Type | Notes
C1,C3,C4,C6,C24,C26,C29 | 0.1uF 50V | ~ | Capacitor_SMD:C_0603_1608Metric_Pad1.08x0.95mm_HandSolder | 7 |  |  | C1591 | Samsung Electro-Mechanics | CL10B104KB8NNNC | SMD
C2 | 10uF 50V | ~ | Capacitor_Tantalum_SMD:CP_EIA-3216-18_Kemet-A_Pad1.58x1.35mm_HandSolder | 1 |  |  | C89632 | Samsung Electro-Mechanics | CL31B106KBHNNNE | SMD
C5 | 10uF 25V | ~ | Capacitor_Tantalum_SMD:CP_EIA-3528-12_Kemet-T_Pad1.50x2.35mm_HandSolder | 1 |  |  | C7194 | Kyocera AVX | TAJB106K025RNJ | SMD
C7,C8,C30 | 10uF 16V | ~ | Capacitor_Tantalum_SMD:CP_EIA-3216-18_Kemet-A_Pad1.58x1.35mm_HandSolder | 3 |  | 80--T491A106K016 | C7171 | Kyocera AVX | TAJA106K016RNJ | SMD
C9 | 12pF 50V | ~ | Capacitor_SMD:C_0603_1608Metric_Pad1.08x0.95mm_HandSolder | 1 |  |  | C38523 | Samsung Electro-Mechanics | CL10C120JB8NNNC | SMD
C10,C11 | 22uF 25V | ~ | Capacitor_Tantalum_SMD:CP_EIA-3216-18_Kemet-A_Pad1.58x1.35mm_HandSolder | 2 |  |  | C12891 | Samsung Electro-Mechanics | CL31A226KAHNNNE | SMD
C23,C25 | 1nF 50V | ~ | Capacitor_SMD:C_0603_1608Metric_Pad1.08x0.95mm_HandSolder | 2 |  |  | C1588 | Samsung Electro-Mechanics | CL10B102KB8NNNC | SMD
D1 | SM5819PL 1A 40V | ~ | Diode_SMD:D_SMA | 1 |  | 833-SM5819PL-TP | C669023 | MCC | SM5819PL-TP | SMD
D2,D4,D5,D6 | LED 0805 (green) | ~ | LED_SMD:LED_0805_2012Metric_Pad1.15x1.40mm_HandSolder | 4 |  | 710-150080GS75000 | C434432 | Yongyu Photoelectric | SZYY0805G | SMD
D3,D28,D31 | ES1D 1A 200V | ~ | Diode_SMD:D_SMA_Handsoldering | 3 |  | 512-ES1D | C445494 | MDD(Microdiode Semiconductor) | ES1D | SMD
D7,D13,D14,D16,D17,D23 | 3.3V TVS | ~ | Diode_SMD:D_SOD-323_HandSoldering | 6 |  |  | C78439 | Brightking | UDD32C03L01 | SMD
D8 | 30V TVS | ~ | Diode_SMD:D_0603_1608Metric_Pad1.05x0.95mm_HandSolder | 1 |  |  | C7473181 | MSKSEMI | PESD0603MS30-MS | SMD
D21,D22,D26 | 12V TVS | ~ | Diode_SMD:D_SOD-323_HandSoldering | 3 |  |  | C5199168 | ElecSuper | UDD32C12L01-ES | SMD | C502541
D27,D30 | BAT54(C) | ~ | FanPico:D_SOT-23_ANK | 2 |  | 241-BAT54C_R1_00001 | C2844172 | FUXINSEMI | BAT54C | SMD
D35,D36 | 5V TVS | ~ | Diode_SMD:D_SOD-323_HandSoldering | 2 |  |  | C5180216 | ElecSuper | PESD5V0S1BA-ES | SMD
F1 | Polyfuse 2A (48V) | ~ | Fuse:Fuse_2920_7451Metric_Pad2.10x5.45mm_HandSolder | 1 |  |  | C22399926 | BHFUSE | BSMD2920-200-48V | SMD
F2 | Polyfuse 0.5A | ~ | Fuse:Fuse_1206_3216Metric_Pad1.42x1.75mm_HandSolder | 1 |  | 530-0ZCJ0050AF2E | C70072 | TECHFUSE | nSMD035-16V | SMD
F3 | Polyfuse 1A | ~ | Fuse:Fuse_1206_3216Metric_Pad1.42x1.75mm_HandSolder | 1 |  |  | C7542958 | LUTE | 1206L100/30NR | SMD
G1 | qwiic_Logo |  | sparkfun-qwiic:qwiic_5mm | 1
G2 | Logo_Open_Hardware_Small | ~ | Symbol:OSHW-Logo_5.7x6mm_SilkScreen | 1
H1,H2,H3,H4 | MountingHole_Pad | ~ | MountingHole:MountingHole_3.2mm_M3_Pad_Via | 4 | DNP
J1 | DC Power Input | ~ | TerminalBlock_Phoenix:TerminalBlock_Phoenix_MKDS-1,5-2_1x02_P5.00mm_Horizontal | 1 |  | 651-1715022 | C1509679 | JILN | JL301-50002U04 | THT
J5 | 1-Wire | ~ | TerminalBlock_TE-Connectivity:TerminalBlock_TE_282834-3_1x03_P2.54mm_Horizontal | 1 |  |  | C68305 | BOOMELE(Boom Precision Elec) | 2.54-3P | THT | C5188443
J6 | QWIIC | ~ | Connector_JST:JST_SH_SM04B-SRSS-TB_1x04-1MP_P1.00mm_Horizontal | 1 |  |  | C160404 | JST | SM04B-SRSS-TB(LF)(SN) | SMD
J13 | Fan1 Output | ~ | Connector:FanPinHeader_1x04_P2.54mm_Vertical | 1 |  | 538-47053-1000 | C240840 | MOLEX | 470531000 | THT | KF2510-AW 3+1P
J14 | Fan2 Output | ~ | Connector:FanPinHeader_1x04_P2.54mm_Vertical | 1 |  | 538-47053-1000 | C240840 | MOLEX | 470531000 | THT | KF2510-AW 3+1P
J16 | Sensor1 | ~ | Connector_JST:JST_XH_B2B-XH-A_1x02_P2.50mm_Vertical | 1 |  |  | C20079 | BOOMELE(Boom Precision Elec) | XH-2A | THT | C33132 (Right-Angle)
J17 | Sensor2 | ~ | Connector_JST:JST_XH_B2B-XH-A_1x02_P2.50mm_Vertical | 1 |  |  | C20079 | BOOMELE(Boom Precision Elec) | XH-2A | THT | C33132 (Right-Angle)
J19 | Serial Console (TTL) | ~ | Connector_PinHeader_2.54mm:PinHeader_1x03_P2.54mm_Vertical | 1 |  |  | C2937625 | XFCN | PZ254V-11-03P | THT
JP12 | 1-Wire PullUp Enable | ~ | Connector_PinHeader_2.54mm:PinHeader_1x02_P2.54mm_Vertical | 1 |  |  | C492401 | XFCN | PZ254V-11-02P | THT
L1 | 10uH | ~ | FanPico:IND-SMD_L7.2-W6.6_GPSR07X0 | 1 |  |  | C5189958 | SHOU HAN | CYA0630-10UH | SMD
R1,R4 | 1k | ~ | Resistor_SMD:R_0603_1608Metric_Pad0.98x0.95mm_HandSolder | 2 |  |  | C22548 | YAGEO | RC0603FR-071KL | SMD
R2 | 4.7k | ~ | Resistor_SMD:R_0603_1608Metric_Pad0.98x0.95mm_HandSolder | 1 |  |  | C99782 | YAGEO | RC0603FR-074K7L | SMD
R3,R48 | 330 | ~ | Resistor_SMD:R_0603_1608Metric_Pad0.98x0.95mm_HandSolder | 2 |  |  | C105881 | YAGEO | RC0603FR-07330RL | SMD
R5,R7,R40,R43,R50,R51 | 10k | ~ | Resistor_SMD:R_0603_1608Metric_Pad0.98x0.95mm_HandSolder | 6 |  |  | C98220 | YAGEO | RC0603FR-0710KL | SMD
R6 | 4.99k | ~ | Resistor_SMD:R_0603_1608Metric_Pad0.98x0.95mm_HandSolder | 1 |  |  | C114621 | YAGEO | RC0603FR-074K99L | SMD
R8 | 422k | ~ | Resistor_SMD:R_0603_1608Metric_Pad0.98x0.95mm_HandSolder | 1 |  |  | C245966 | YAGEO | RC0603FR-07422KL | SMD
R9 | 30.1k | ~ | Resistor_SMD:R_0603_1608Metric_Pad0.98x0.95mm_HandSolder | 1 |  |  | C23000 | UNI-ROYAL | 0603WAF3012T5E | SMD
R10 | 49.9k | ~ | Resistor_SMD:R_0603_1608Metric_Pad0.98x0.95mm_HandSolder | 1 |  |  | C114624 | YAGEO | RC0603FR-0749K9L | SMD
R41,R44 | 680 | ~ | Resistor_SMD:R_0603_1608Metric_Pad0.98x0.95mm_HandSolder | 2 |  |  | C115415 | YAGEO | RC0603JR-07680RL | SMD
R49,R55 | 0 | ~ | Resistor_SMD:R_0603_1608Metric_Pad0.98x0.95mm_HandSolder | 2 |  |  | C21189 | UNI-ROYAL | 0603WAF0000T5E | SMD
R54 | DNF | ~ | Resistor_SMD:R_0603_1608Metric_Pad0.98x0.95mm_HandSolder | 1 | DNP |  | C21189 | UNI-ROYAL | 0603WAF0000T5E | SMD
SW1 | SW_Push | ~ | FanPico:SW-SMD_L3.9-W3.0-P4.45 | 1 |  |  | C720477 | XUNPU | TS-1088-AR02016 | SMD
U1 | SN74AHCT126 | (AHCT125 = C36365, AHCT126 = C155177) | Package_SO:TSSOP-14_4.4x5mm_P0.65mm | 1 |  |  | C155177 | TI | SN74AHCT126PWR | SMD
U2 | AP63301 |  | FanPico:TSOT-26 | 1 |  |  | C2158003 | DIODES | AP63301WU-7 | SMD
U4 | Pico W |  | FanPico:RPi_Pico_PicoW_SMD_TH | 1 |  |  |  | RaspberryPi | Pico W / Pico 2 W | SMD
U5 | SPX1117-ADJ | http://www.diodes.com/datasheets/AP1117.pdf | Package_TO_SOT_SMD:SOT-223-3_TabPin2 | 1 |  |  | C67402 | MaxLinear | SPX1117M3-L/TR | SMD
U6 | LM4040DBZ-3 | http://www.ti.com/lit/ds/symlink/lm4040-n.pdf | Package_TO_SOT_SMD:SOT-23 | 1 |  |  | C143326 | MAXIM | LM4040AIM3-3.0+T | SMD

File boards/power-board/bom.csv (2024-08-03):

Reference | Value | Datasheet | Footprint | Qty | DNP | LCSC Part Number | Mouser Part Number
D1 | LED | ~ | Diode_SMD:D_0805_2012Metric_Pad1.15x1.40mm_HandSolder | 1 |  | C434432 | 710-150080GS75000
F1 | Polyfuse 10A | ~ | Fuse:Fuse_2920_7451Metric_Pad2.10x5.45mm_HandSolder | 1 |  | C22446882
F2 | 10A | ~ | FanPico:Fuseholder_Clip-5x20mm_Littelfuse_445-030_Inline_P20.50x5.20mm_D1.30mm_Horizontal | 1 |  | C717027
J1 | Power Input 2 | ~ | TerminalBlock_Phoenix:TerminalBlock_Phoenix_MKDS-1,5-2_1x02_P5.00mm_Horizontal | 1 |  | C1509679
J2 | Power Input 1 | ~ | FanPico:TE_MATE-N-LOK_350211-1_1x04_P5.08mm_Vertical_and_RightAngle | 1 |  | C305826 or C7461144 | 571-3502111 / 571-1748041
J3 | AUX Power Output | ~ | TerminalBlock_Phoenix:TerminalBlock_Phoenix_MKDS-1,5-2_1x02_P5.00mm_Horizontal | 1 |  | C1509679
J5 | FAN1 | ~ | Connector:FanPinHeader_1x04_P2.54mm_Vertical | 1 |  | C240840 | 538-47053-1000
J6 | FAN2 | ~ | Connector:FanPinHeader_1x04_P2.54mm_Vertical | 1 |  | C240840 | 538-47053-1000
J7 | FAN3 | ~ | Connector:FanPinHeader_1x04_P2.54mm_Vertical | 1 |  | C240840 | 538-47053-1000
J8 | FAN4 | ~ | Connector:FanPinHeader_1x04_P2.54mm_Vertical | 1 |  | C240840 | 538-47053-1000
J13 | FANCTRL1 | ~ | Connector:FanPinHeader_1x04_P2.54mm_Vertical | 1 |  | C240840 | 538-47053-1000
J14 | FANCTRL2 | ~ | Connector:FanPinHeader_1x04_P2.54mm_Vertical | 1 |  | C240840 | 538-47053-1000
J15 | FANCTRL3 | ~ | Connector:FanPinHeader_1x04_P2.54mm_Vertical | 1 |  | C240840 | 538-47053-1000
J16 | FANCTRL4 | ~ | Connector:FanPinHeader_1x04_P2.54mm_Vertical | 1 |  | C240840 | 538-47053-1000
R1 | 49.9K | ~ | Resistor_SMD:R_0603_1608Metric_Pad0.98x0.95mm_HandSolder | 1 |  | C114624

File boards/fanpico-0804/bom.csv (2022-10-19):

Ref | Qnty | Value | Cmp name | Footprint | Description | Vendor | Mouser P/N | LCSC P/N
C1, C2, C3, C4, C6, C11, C14, C17, C20, C22, C24, C26, C28, C29 | 14 | 0.1uF | C | Capacitor_SMD:C_0603_1608Metric_Pad1.08x0.95mm_HandSolder | Unpolarized capacitor |  |  | C1591
C5, | 1 | 10uF 20V | C Tantalum | Capacitor_SMD:C_1206_3216Metric_Pad1.33x1.80mm_HandSolder | Polarized capacitor, small symbol |  |  | C117023
C7, C8, C30 | 3 | 10uF 16V | C Tantalum | Capacitor_SMD:C_1206_3216Metric_Pad1.33x1.80mm_HandSolder | Polarized capacitor, small symbol |  | 80-T491A106K016 | C2798061
C10, C13, C16, C19, C21, C23, C25, C27, | 8 | 1nF | C | Capacitor_SMD:C_0603_1608Metric_Pad1.08x0.95mm_HandSolder | Unpolarized capacitor |  |  | C1588
D1, | 1 | SM5819PL | D_Schottky (1A 40V) | Diode_SMD:D_SMA_Handsoldering | Schottky diode |  | 833-SM5819PL-TP | C669023
D2, D4, D5, D6, D7, D8, D11, D12, D15, D16, D19, D20, D23, D26, D29, D32, | 16 | SMD LED (green) | LED 0805 | LED_SMD:LED_0805_2012Metric_Pad1.15x1.40mm_HandSolder | Light emitting diode |  | 710-150080GS75000 | C434432
D3, D10, D14, D18, D22, D25, D28, D31, D34, | 9 | ES1D | D 1A 200V | Diode_SMD:D_SMA_Handsoldering | Diode |  | 512-ES1D | C445494
D9, D13, D17, D21, D24, D27, D30, D33, | 8 | BAT54C | D | Diode_SMD:D_SOT-23_ANK | Diode |  | 241-BAT54C_R1_00001 | C2992451
F1, | 1 | Polyfuse 3A | Polyfuse | Fuse:Fuse_2920_7451Metric_Pad2.10x5.45mm_HandSolder | Resettable fuse, polymeric positive temperature coefficient |  | 530-0ZCF0300BF2C | C20829
F2, | 1 | Polyfuse 500mA / 350mA | Polyfuse | Fuse:Fuse_1206_3216Metric_Pad1.42x1.75mm_HandSolder | Resettable fuse, polymeric positive temperature coefficient |  | 530-0ZCJ0050AF2E | C70072
J3, | 1 | 171826-4 | Berg Connector | Berg connector:TE_171826-4 | Floppy Power Connector | TE | 571-1718264 | C590635
J4 - J15 | 12 | 47053-1000 | 4-pin Fan Connector | Connector:FanPinHeader_1x04_P2.54mm_Vertical | PC 4-pin (PWM) fan connector | Molex | 538-47053-1000 | C240840
J16 - J17 | 2 | JST-XH | 2-pin JST XH 2.5mm | Connector_JST:JST_XH_B2B-XH-A_1x02_P2.50mm_Vertical | 2-pin connector |  |  | C158012
J2, JP1 - JP11 | 12 | Header | Header | Connector_PinHeader_2.54mm:PinHeader_1x03_P2.54mm_Vertical | Header 2.54mm |  |  | C124376
JP1 - JP11 | 11 | Jumper | Jumper_3_Bridged12 | Connector_PinHeader_2.54mm:PinHeader_1x03_P2.54mm_Vertical | Jumper 2.54mm |  |  | C5305
Q1, Q2, Q3, Q4, | 4 | 2N7002K | MOSFET | Package_TO_SOT_SMD:SOT-23 | 0.38A Id, 60V Vds, N-Channel MOSFET, SOT-23 |  | 512-2N7002K | C85047
R1, R4, R8, R11, R15, R18, R22, R25, R29, R32, | 10 | 1k | R | Resistor_SMD:R_0603_1608Metric_Pad0.98x0.95mm_HandSolder | Resistor |  |  | C22548
R2, R10, R12, R17, R19, R24, R26, R31, R33, R36, R39, R42, R45, | 13 | 49.9k | R | Resistor_SMD:R_0603_1608Metric_Pad0.98x0.95mm_HandSolder | Resistor |  |  | C114624
R3, R48 | 2 | 330 | R | Resistor_SMD:R_0603_1608Metric_Pad0.98x0.95mm_HandSolder | Resistor |  |  | C105881
R5, R7, R13, R20, R27, R34, R37, R40, R43, R46, R50, R51 | 12 | 10k | R | Resistor_SMD:R_0603_1608Metric_Pad0.98x0.95mm_HandSolder | Resistor |  |  | C98220
R6, | 1 | 4.99k | R | Resistor_SMD:R_0603_1608Metric_Pad0.98x0.95mm_HandSolder | Resistor |  |  | C114621
R9, R16, R23, R30, | 4 | 30k | R | Resistor_SMD:R_0603_1608Metric_Pad0.98x0.95mm_HandSolder | Resistor |  |  | C100001
R14, R21, R28, R35, R38, R41, R44, R47, | 8 | 680 | R | Resistor_SMD:R_0603_1608Metric_Pad0.98x0.95mm_HandSolder | Resistor |  |  | C115415
R49 | 1 | 0 | R | Resistor_SMD:R_0603_1608Metric_Pad0.98x0.95mm_HandSolder | Resistor |  |  | C100044
R52, R53 | 2 | 100k | R | Resistor_SMD:R_0603_1608Metric_Pad0.98x0.95mm_HandSolder | Resistor |  |  | C14675
SW1, | 1 | SW_Push | SW_Push | Button_Switch_THT:SW_PUSH_6mm | Push button switch, generic, two pins |  |  | C221880
U1, U2, | 2 | SN74AHCT125QDRQ1 | SN74AHCT125 | Package_SO:SOIC-14_3.9x8.7mm_P1.27mm | Low (3.3V) to High (5V) TTL level converter | TI |  | C155176
U3, | 1 | CD74HC4050NSR | CD74HC4050 | Package_SO:SOIC-16_3.9x9.9mm_P1.27mm | High (5-12V) to Low (3.3V) TTL level converter | TI |  | C131932
U4, | 1 | Pico / Pico W | Pico | MCU_RaspberryPi_and_Boards:RPi_Pico_SMD_TH | Raspberry Pi Pico | RPi | 474-DEV-17829
U5, | 1 | SPX1117-ADJ | LM1117-ADJ | Package_TO_SOT_SMD:SOT-223 | 800mA Low-Dropout Linear Regulator, adjustable output, TO-220/TO-252/TO-263/SOT-223 | Maxim | 701-SPX1117M3-L/TR | C67402
U6, | 1 | LM4040BIM3-3.0 | LM4040 3.0V | Package_TO_SOT_SMD:SOT-23 | 3.000V Precision Micropower Shunt Voltage Reference, SOT-23 |  | 926-LM4040BIM330NOPB | C143326

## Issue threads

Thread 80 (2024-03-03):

"Corrupted dir pair at {0x0, 0x1}" with version 1.61

shawnshekari, 2024-03-03:
Thanks for such an awesome product.  I bought my kit (0804D) back at the end of Jan and just got it soldered up today.

Of course, I went right for the latest firmware and ran into an issue.  The previous couple version (1.60 & 1.50) didn't have any issues.

But I noticed another serial message that made me think that perhaps the older version had corrected the directory issue and sure enough now the 1.61 version also runs without an error.  The two messages in Putty below.  The first was by flashing 1.61 (and I did that a couple times with the same results.) And the second was when I tried 1.5.  After that the three versions I have tried all worked.

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

I haven't tried any fan control yet but so far I am so impressed with the project.
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

tjko, 2024-03-03:
Interesting, so did I understand correctly that this happened when installing v1.6.1 firmware on a "blank" Pico?  And after 'downgrading' to earlier firmware that seemed to fix the issue?

Probably something to do with v1.6.1 using newer version of LittleFS library... I'll see if I can replicate the issue you saw...

tjko, 2024-03-04:
Thanks for pointing this out. It was indeed a bug that was introduced when switching to use latest LittleFS version in fanpico.

Fix is now checked in 65f9d447e4fc8ecb60d4e0e5a42c76343d032586

tjko, 2024-03-04:
New firmware release v1.6.2 now contains this fix: https://github.com/tjko/fanpico/releases/tag/v1.6.2

Closed 2024-03-05.

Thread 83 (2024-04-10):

More temperature inputs

kiler129, 2024-04-10:
## Thank you
First of all, this project is an amazing gem, pretty much exactly what I was thinking about designing and building! Thank you for that. I poked around the code and I see it's very high quality and with a great level of flexibility built-in. This is what prompted this issue.

## Scope
How feasible/desire would be to expand the temperature sensing capabilities of fanpico? I have precisely two things in mind:
1. More temperature sensors via ADC, potentially external one via I2C/SPI to limit hardware changes and prevent scope creep
2. External temperature sensors with value published from an outside source (MQTT/HTTP/UART/whatever)

Dynamically-created sensors are imo out of scope and non-goal. Looking at the code making `SENSOR_COUNT` dynamic would be a nightmare.

## Usecase
The usecase for such a change is to have a complete control over the system that contains multiple heat-generating components. For example if we take even a small NAS as an example, we have:
- **multiple disks**, where usage pattern can create big temperature gradient warranting fan ramping up even if CPU temperature is low
- **network cards/DPUs**, with 10/25/40Gb ones creating quite a bit of heat
- **SAS controllers**, that during e.g. RAID rebuild can produce substantial amount of heat
- **GPU-only activity** like transcoding or AI training, requiring overall increased airflow

My original idea steems from HDDs itself: high-capacity 7.2k RPM enterprise units can very quickly heat up under load. As they're split into multiple pools I would realistically need one sensor per disk.

## Future possibilities
With more sensors implementing something similar to HP 3D Sea would be feasible. As I have some experience with lightweight web interfaces I could help with that.

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

Interface like that greatly improves "glanceability" of system state, as list of raw temperature and fan speed values requires more effort to interpret at a glance.

### WDYT?

tjko, 2024-04-11:
Adding support for additional temperature sensors is something that has come up. One way to easily support 8 (or 16) would be to add one (or two) analog multiplexers that are driven by same signals as the existing analog multiplexer (74HC4051) for tachometer input.

As you suggested another way could be some analog switch (multiplexer) that can be controller over I2C to "multiplex" temperature inputs.

For external temperature inputs current firmware has initial support for virtual sensors (VSENSORS), that were meant to allow using things like HDD or CPU temperature as input (and to be displayed on OLED or LCD panel).
(https://github.com/tjko/fanpico/blob/main/commands.md#configurevsensorxname)

Idea for "VSENSORS" was that there would be some software/script that would issue SCPI commands to update their values over the Console/UART connection. MQTT can be used currently as well (there is simple control to only allow "WRITE" commands if want to block other SCPI commands over MQTT).

I'd gladly accept contributions to improve the current web interface as its very primitive at the moment...

tjko, 2024-05-25:
@kiler129, current batch of 0804D boards is starting to run low.  I was thinking of minor revision by adding "QWIIC" (or "STEMMA QT") connector to make it easier to add/daisy-chain external sensors.  Any preference on the connector type?

Adding more inputs (connectors) for thermistors read by ADC, might be something for a new board model. Since seems like not many users actually use all "MBFAN" inputs from motherboard/fancontroller, so reducing inputs would allow adding other features as well (or increase FAN outputs).

jamesRericha, 2024-05-30:
We have ben purchasing several boards 30+  We currently mount a daughter board above the temperature inputs and have written code to read the ds18b20 serial one-wire sensor. These are addressable and have a higher accuracy.  were using screw down TE Connectivity AMP Connectors. May be we could collaborate. The one-wire sensor allow multiple sensors to be added on the same buss.  We also utilize a 12v barrel connector instead of the 4 pin aux on a daughter board.

tjko, 2024-05-30:
@jamesRericha, those DS18B20 sensors look really nice.  Have you been using them in the "external supply" mode (when only 1 pin seems to be needed) or in "parasite-powered" mode (when it seems like 2 pins are needed)?

Should be able to squeeze support for these on current PCB design without too much trouble. And this shouldn't really need more than a pull-up resistor and perhaps protection (TVS) diode(s) ?   (I was just thinking, that a long string of sensors connected, probably raise risk of ESD damage to the micro noticeably...)

If you don't mind sharing how you've been doing things, that would help.

Oh, and a 12V DC jack sounds like good idea. I'll see if can add footprint for one as alternate to the current "floppy" power connector.

jamesRericha, 2024-05-31:
Please forgive me I am very new to Kicad and github. I am sure there is a better way for me to share these and I will have to figure out how.

We use a 2" wave share screen with a 10 pos ribbon cable over about 5 feet distance.  3d printed housing and a face plate sticker.
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

This is the adaptor board.
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
We had a few issues with noise on the spi for the screen and the sensor.  We now don't pass the 5v pin from the main board to the daughter board, we don't pass the power select jumpers up but instead solder a jumper to the main board selecting the aux power.  We use the 12v barrel connector.

Then over at the temperature sensors we pass both of the current jst pins to the daughter board and the slightly too large pull up resistor 10k is bonded to the existing voltage reference source. Creating a signal wire with a pull up resistor about 2x the size recommended size.  We have a ground, signal, and power.  One wire setup is cool for some situations but more code implementation and slower read times.

We measure temperatures and needed the greater accuracy offered by the ds18b20, we then display the temperatures and run fans on a curve.  No computers involved so we never use the MB Fans or MB power.  Currently we use 4 fans but may expand.  We want to port from micropython to C++ to increase display options and add the Bluetooth and wifi settings page.

tjko, 2024-06-05:
@jamesRericha, thanks for the details. I'll see if I can incorporate these features on the next PCB revision.

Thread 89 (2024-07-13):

Minimal version with smaller footprint and minimal additional components?

BioSehnsucht, 2024-07-13:
I was looking for a solution for controlling a fan cooling a repurposed Nvidia Tesla GPU (which are intended for specific server cases, depending on airflow being force fed into them), to control a regular PC fan. Ducting the fan into the card's air inlet isn't an issue, but rather than just having the fan running at 100% all the time, I was looking for an easy solution to control the fan based on outlet temperature from the GPU.

This project would work perfectly, but be totally overkill.

I am wondering how feasible a minimal board design (and corresponding flavor of code) would be if I started with the 8404 design (directly reading tech signals) and start ditching things I didn't need, i.e.:

- I only need a single fan channel, though depending on resulting board size of all the other changes, maybe fitting 2 is doable without growing the board much
- I only need a single temp sensor, though if a second fan channel is provided, a second sensor would be good (perhaps someone can use it to run two Tesla GPUs)
- I don't care about test points or debug header, if getting rid of them helps simplify the layout
- I don't care about MB I/O, so I can ditch the 5-12V to 3.3V level shifter circuit and related tach output
- Power everything from the "aux" (now only power input besides the USB on pico) connector, since we've eliminated the MB inputs at this point

Starting with 8404 rather than 8404D I also don't have serial or display headers, which is fine.

Is there any other obvious simplification I'm missing for such a minimalist use case?

When creating the new minimal board header file, what would I need to change besides changing the fan counts? I assume I can just configure it at run time to ignore the missing inputs, rather than specifically code around them?

tjko, 2024-07-15:
If you only have one fan channel,  you might also be able to ditch the IC for handling PWM output level shifting and implement single level shifter with a transistor (something like: https://cdn.sparkfun.com/datasheets/BreakoutBoards/Logic_Level_Bidirectional.pdf).

Ideally you should just need to create new header file your board (under src/board/) and update the counts in the beginning (FAN_COUNT, MBFAN_COUNT, SENSOR_COUNT), and then set any of the pins unused to "-1".

In practice, there may be issues that needs to be 'fixed' if setting any of the counts 0, since I don't think that edge case was always in mind when creating the initial firmware.  Also, changing SENSOR_COUNT might not yet work 'out of the box', since I seem to recall I haven't yet gotten around to make the code properly configurable via the board header files.

I've started working on smaller variant of FanPico "0401D", etc, that has 4 fan outputs and one (mbfan) input from motherboard.  So I should soon be testing new board variant, and I'll try to remember to look fixing if there is any obvious problems with 'edge cases' like board where FAN (or MBFAN) count is 0...

tjko, 2024-08-02:
@BioSehnsucht , I have initial prototype in testing for "0401D", that might be better starting point than the old 0804 board:
https://github.com/tjko/fanpico/tree/main/boards/fanpico-0401D

Implementing only one fan output is probably not worth it? Since adding a second port does not really require much additional space on the PCB.
For PWM output to Fans, doing 3.3V to 5V level shifting is probably easiest with the SN74AHCT125/SN74AHCT126 IC as with just two components (IC and bypass capacitor) it gives up to 4 level shifters (with ESD protection built-in)...

If only one level shifter is needed, then implementing one with discrete components likely would require about same space, but would require more components (2 resistors, small MOSFET, TVS diode, etc...)

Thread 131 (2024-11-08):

5V fan compatibility

hunordori, 2024-11-08:
Hi, Is there an easy way to use with 5V (Noctua) fans? I know most of the PC fans are 12 V.
I have 3-4 Noctua fans in my rack and I want to control them, independently from my Home Assistant.

tjko, 2024-11-09:
FanPico "power-board" was created to allow running high-current fans. But it also works for running fans that use different voltage (5V to 24V), as long as Fan accepts 5V PWM signal to control fan speed.

https://github.com/tjko/fanpico/tree/main/boards/power-board

(I have some PCBs for these and plan on making handful of "kits" available in coming weeks...)

tjko, 2024-11-12:
@hunordori,  kits for powerboard should now be available on eBay (direct link can be found
 here: https://github.com/tjko/fanpico/discussions/12)

hunordori, 2024-11-21:
@tjko Thank you! I received it yesterday. If I understand supplying 5V to the 8404D is not a good idea. I should do 12V for the board and a separate 5V with the "power-board".

tjko, 2024-11-21:
@hunordori, yes FanPico board was designed to take 12V (it likely won't function correctly at 5V).  You can connect the 5V power supply for the fans into the power input (J1) on the 'power-board'.

Then FAN output from FanPico would be connected to FANCTRL connector on the power-board and the fan would be connected to the corresponding FAN connector on the power-board.

```
Fan (5V) <-----> [FAN1]PowerBoard[FANCTRL1] <-----> [FAN1]FanPico
```

hunordori, 2025-01-04:
https://github.com/hunordori/rackpico

Thank you again for the support! I created a 1U case for the board. It is installed in my home lab rack.

tjko, 2025-01-04:
@hunordori, I added link to your case in the Wiki page. Thanks!

https://github.com/tjko/fanpico/wiki/FanPico-Enclosures-(3D%E2%80%90Printed)

Closed 2025-01-04.

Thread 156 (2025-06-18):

PANIC: community string is too long!

washley, 2025-06-18:
(This was all done with a built of the latest commit as of the time I write this.)

I set the write community to a random sha1. Reading it back suggests it had been truncated, which I didn't care about. So I saved and rebooted.
```
SYS:SNMP:WRIT f849412f40df7d41b203f3f705bfc011a0b4958e
SYS:SNMP:WRIT?
f849412f40df7d41b203f3f705bfc011
CONF:SAVE
*RST
[   246.318923][0] Initiating reboot...
```

But then there was no blinking light and I could not connect. I found this in the serial output:
```
Hardware Model: FANPICO-0401D
         Board: pico2_w
           MCU: RP2350-A2 @ 150MHz
Initializing persistent memory block...

[     1.581444][0] No OLED Display Connected!

*** PANIC ***

community string is too long!
```

It appears that community strings being too long is a poison-pill for the firmware at the moment.

tjko, 2025-06-18:
Thanks, looks like lwIP doesn't like "long" SNMP community strings by default.

```
lib/lwip/src/apps/snmp/snmp_msg.c:  LWIP_ASSERT("community string is too long!", strlen(community) <= SNMP_MAX_COMMUNITY_STR_LEN);
```

Seems like need to set SNMP_MAX_COMMUNITY_STR_LEN to value that aligns with maximum string length FanPico supports...

Btw, looks like currently firmware support up to 32 character community strings. Do you have need to use longer strings than that?

washley, 2025-06-18:
No need at all, just wanted to throw something random in there to disable writes. In hindsight, I should have checked whether setting that to empty would have accomplished what I wanted.

tjko, 2025-06-18:
> Speaking of the panic, is there any watchdog that could be utilized so that panics like this don't permanently hang the pico?
>
> Or does that already exist, but this panic is located before watchdog configuration?

Hardware watchdog is in use, but it won't get enabled until bit later in the boot process...  (if you set ```SYS:LOG INFO```, then you should see it getting enabled during boot...)

tjko, 2025-06-19:
This should now be fixed via https://github.com/tjko/fanpico/pull/157

Beta firmware with this change can be found here: https://github.com/tjko/fanpico/actions/runs/15746907140

Closed 2025-06-19.

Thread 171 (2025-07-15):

missing cpl file for fabricating

nwgat, 2025-07-15:
when i tried to get a few boards fabricated at jclpcb with assembly they ask for cpl (pick and place) ile

tjko, 2025-07-22:
I found file for 0401D that I had used, its added to the thread mentioned above.

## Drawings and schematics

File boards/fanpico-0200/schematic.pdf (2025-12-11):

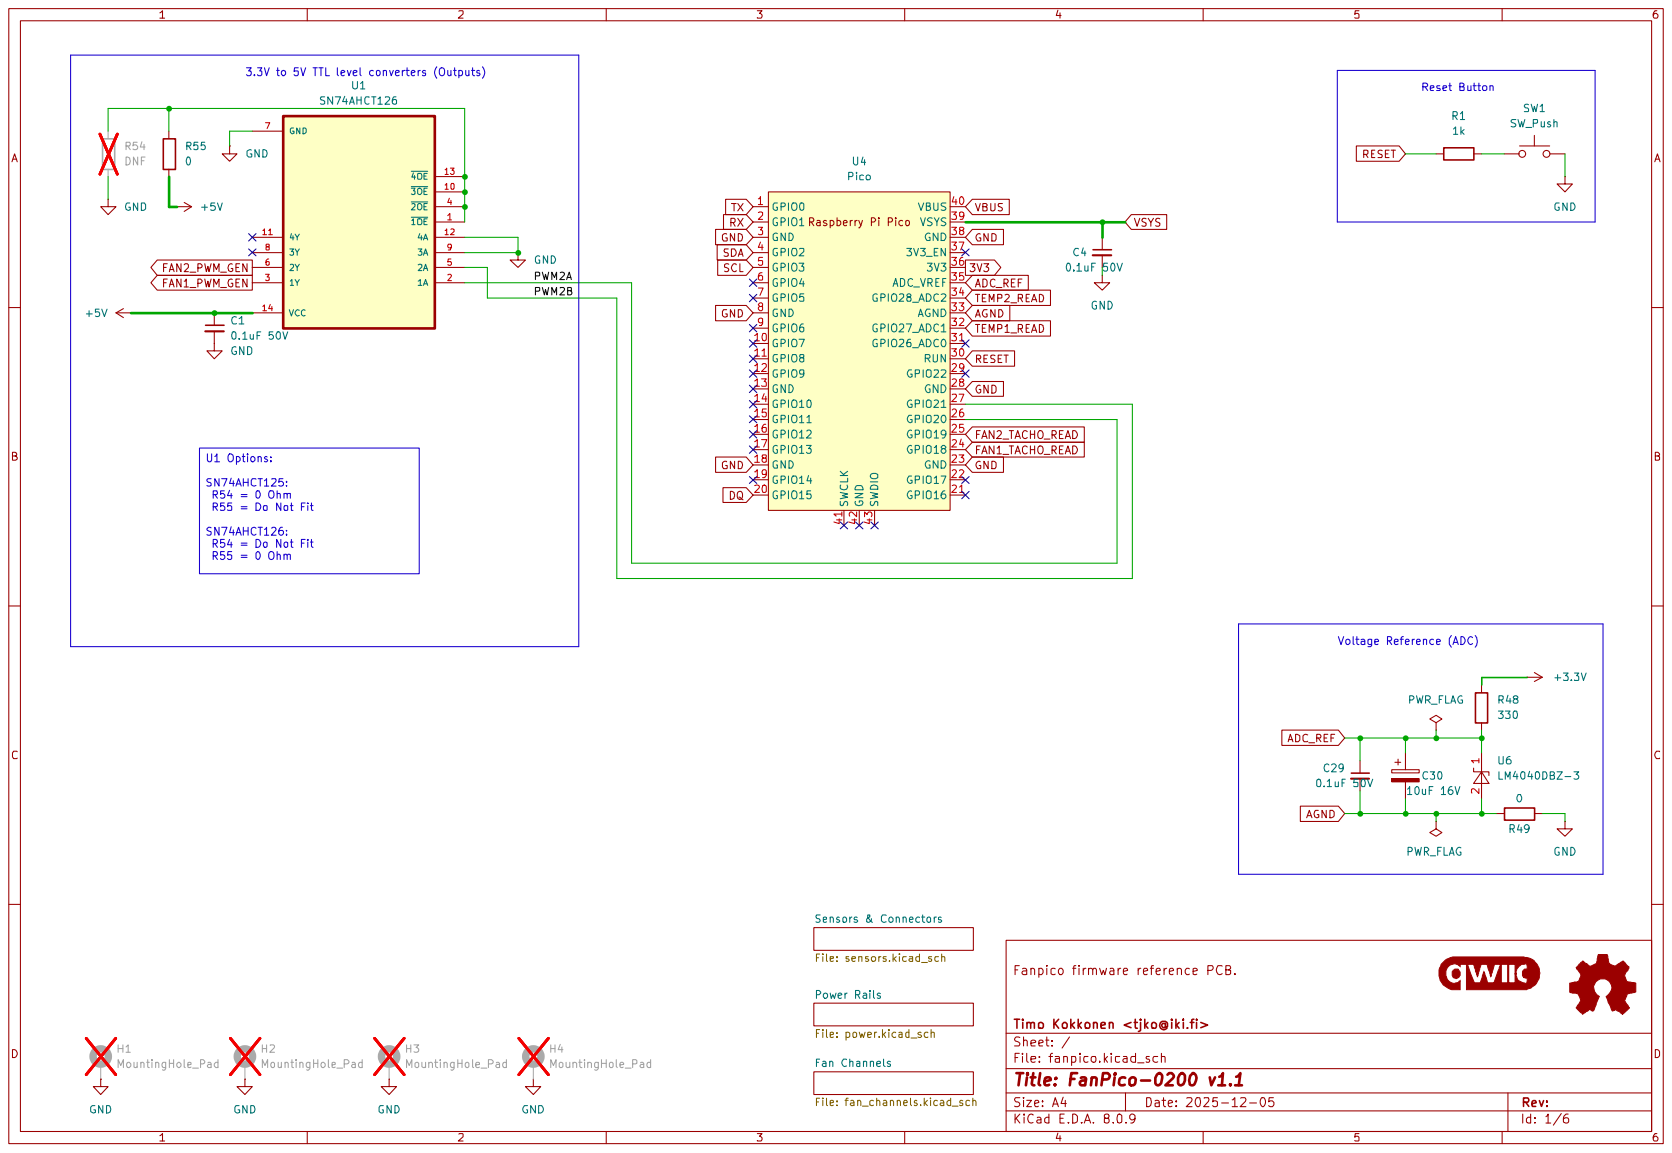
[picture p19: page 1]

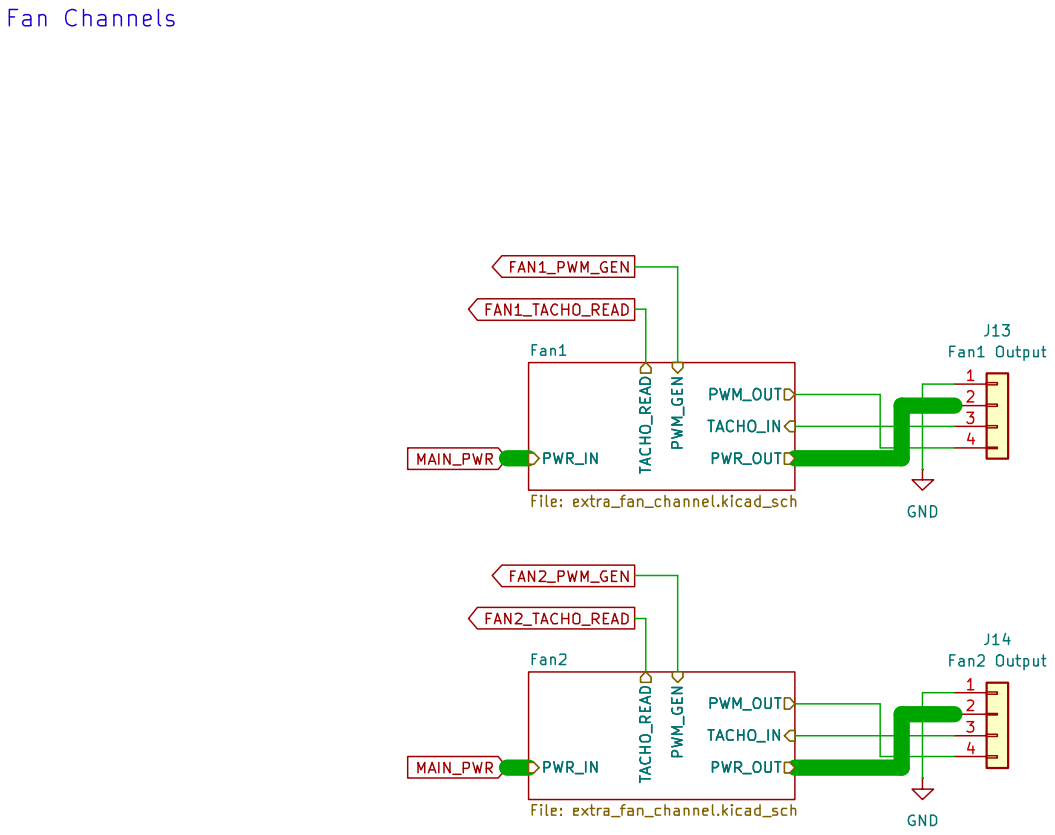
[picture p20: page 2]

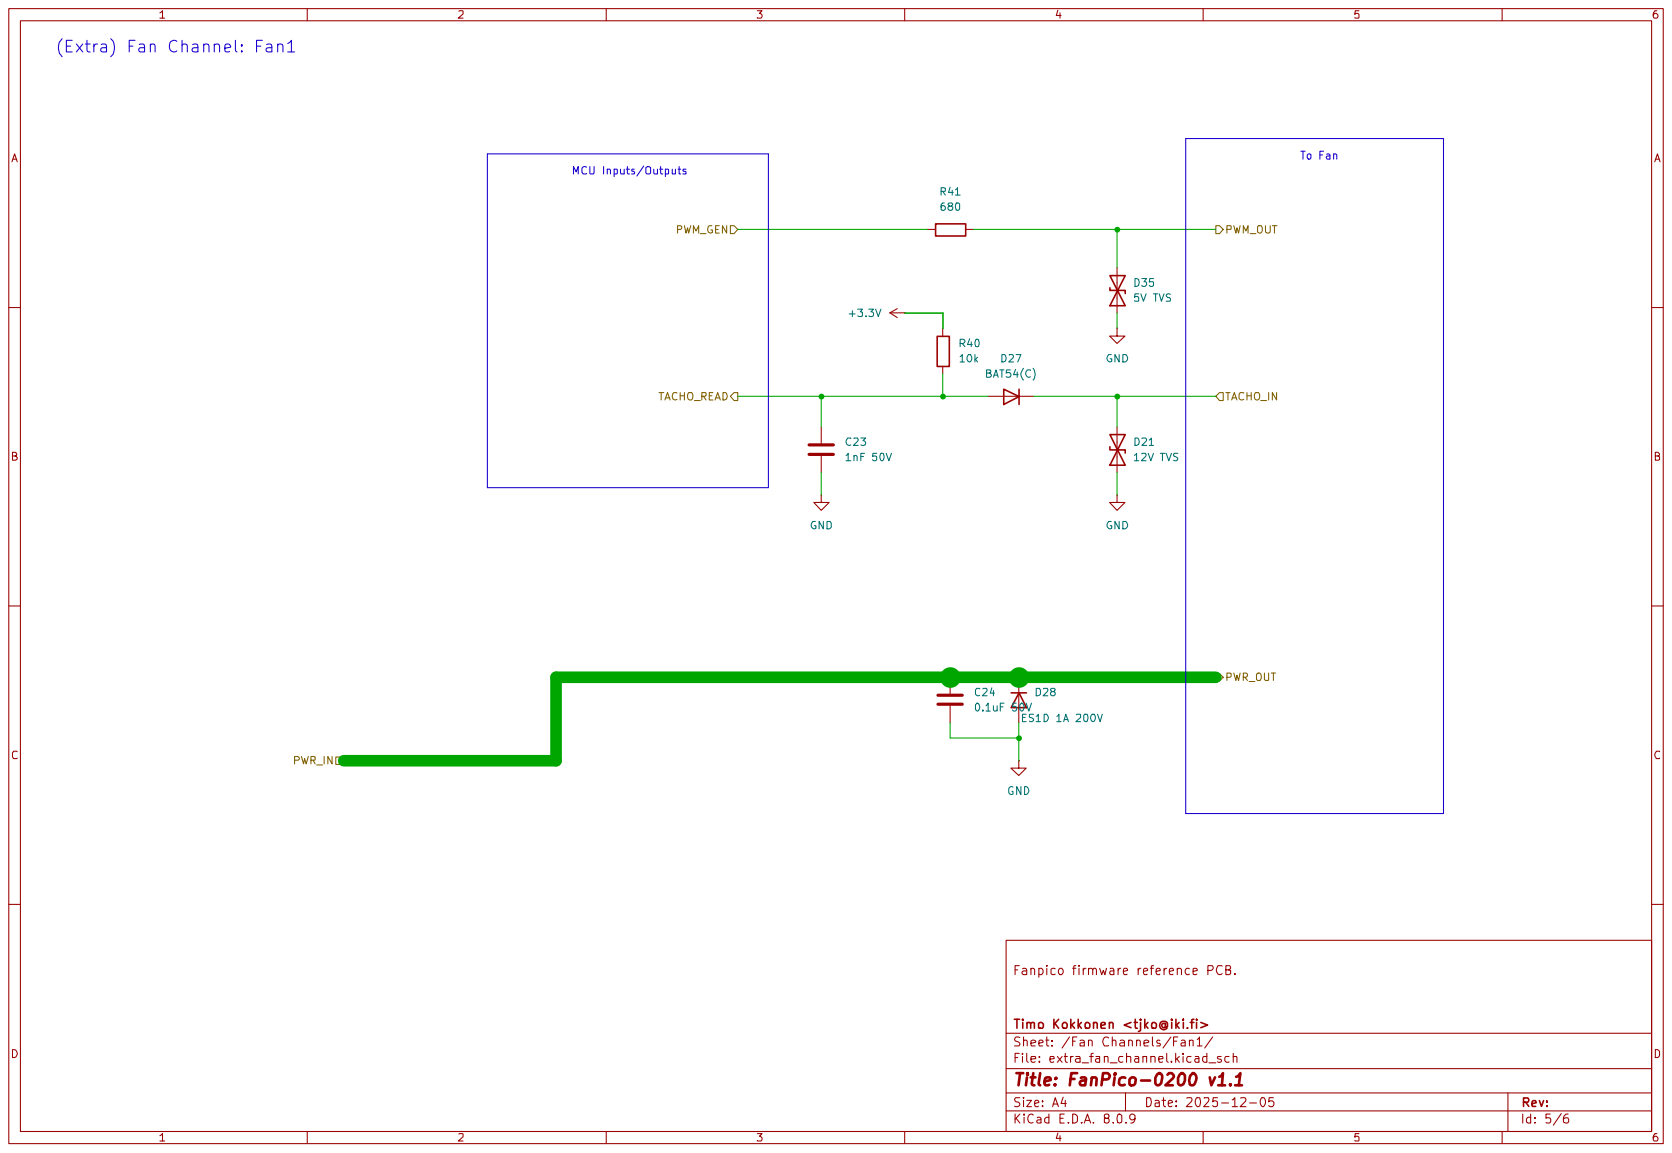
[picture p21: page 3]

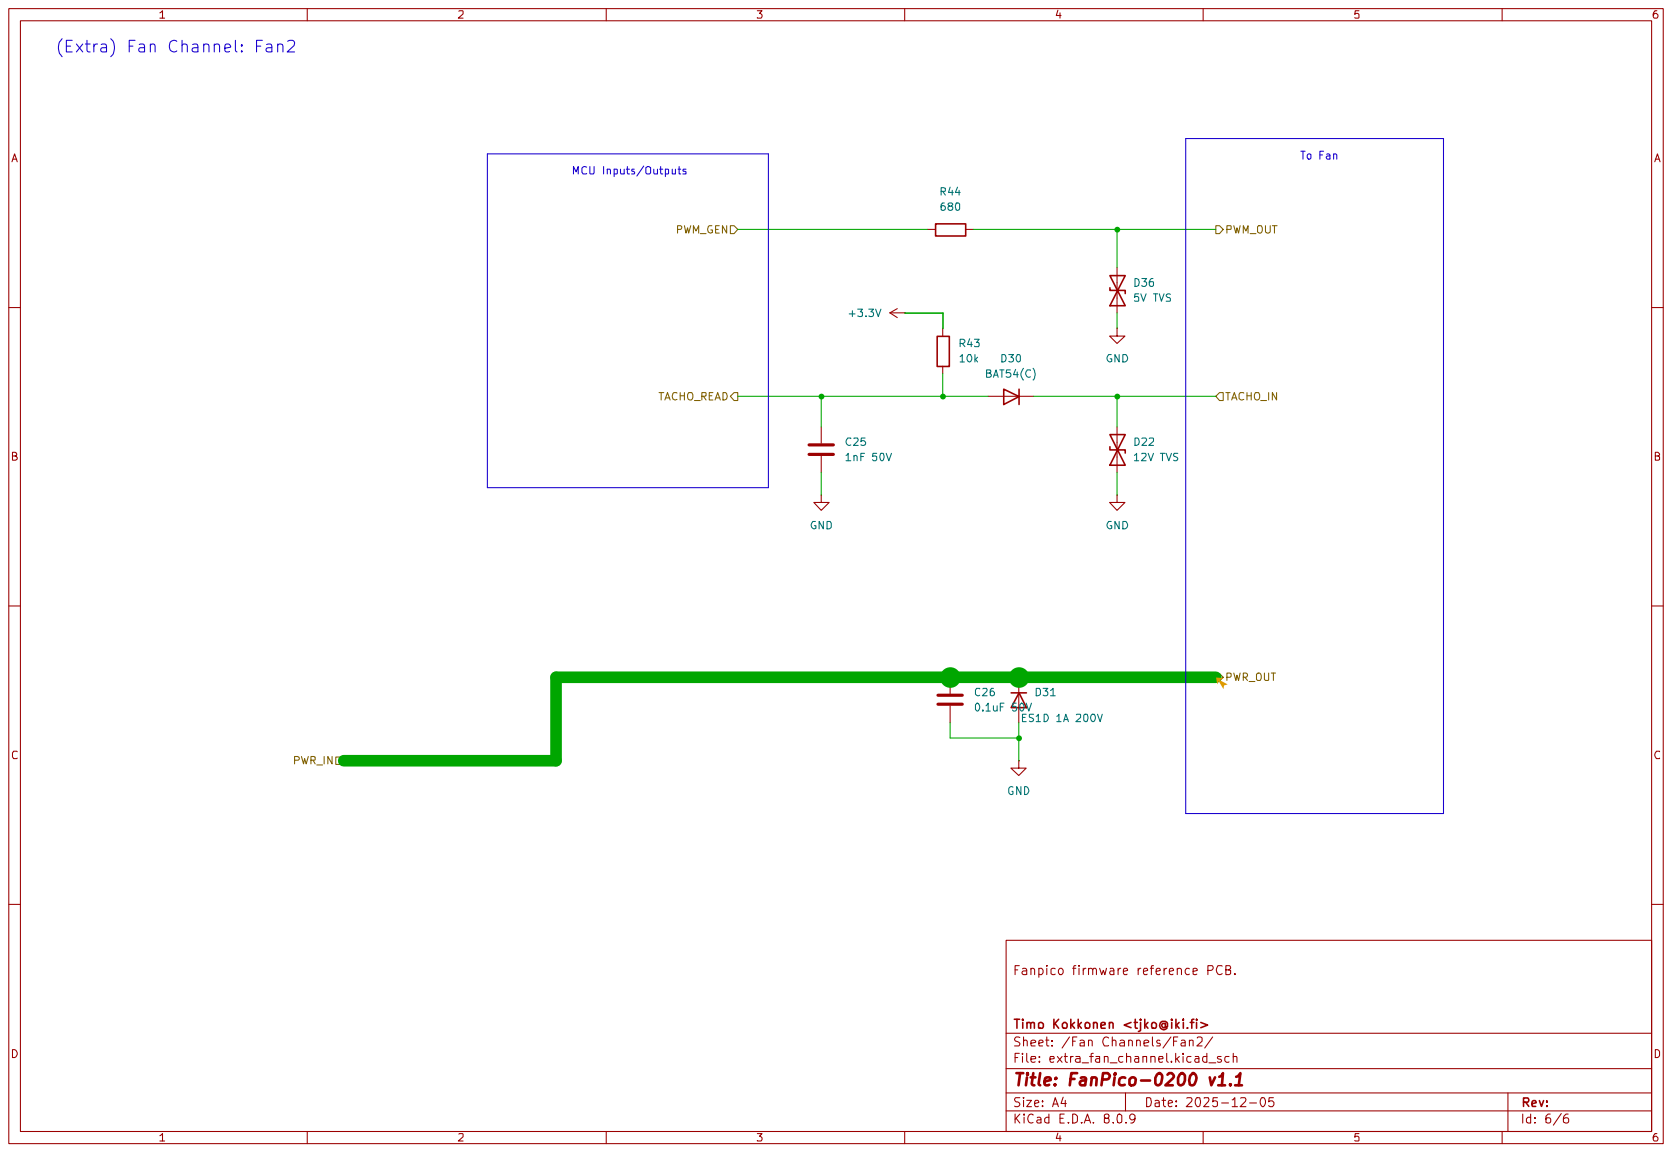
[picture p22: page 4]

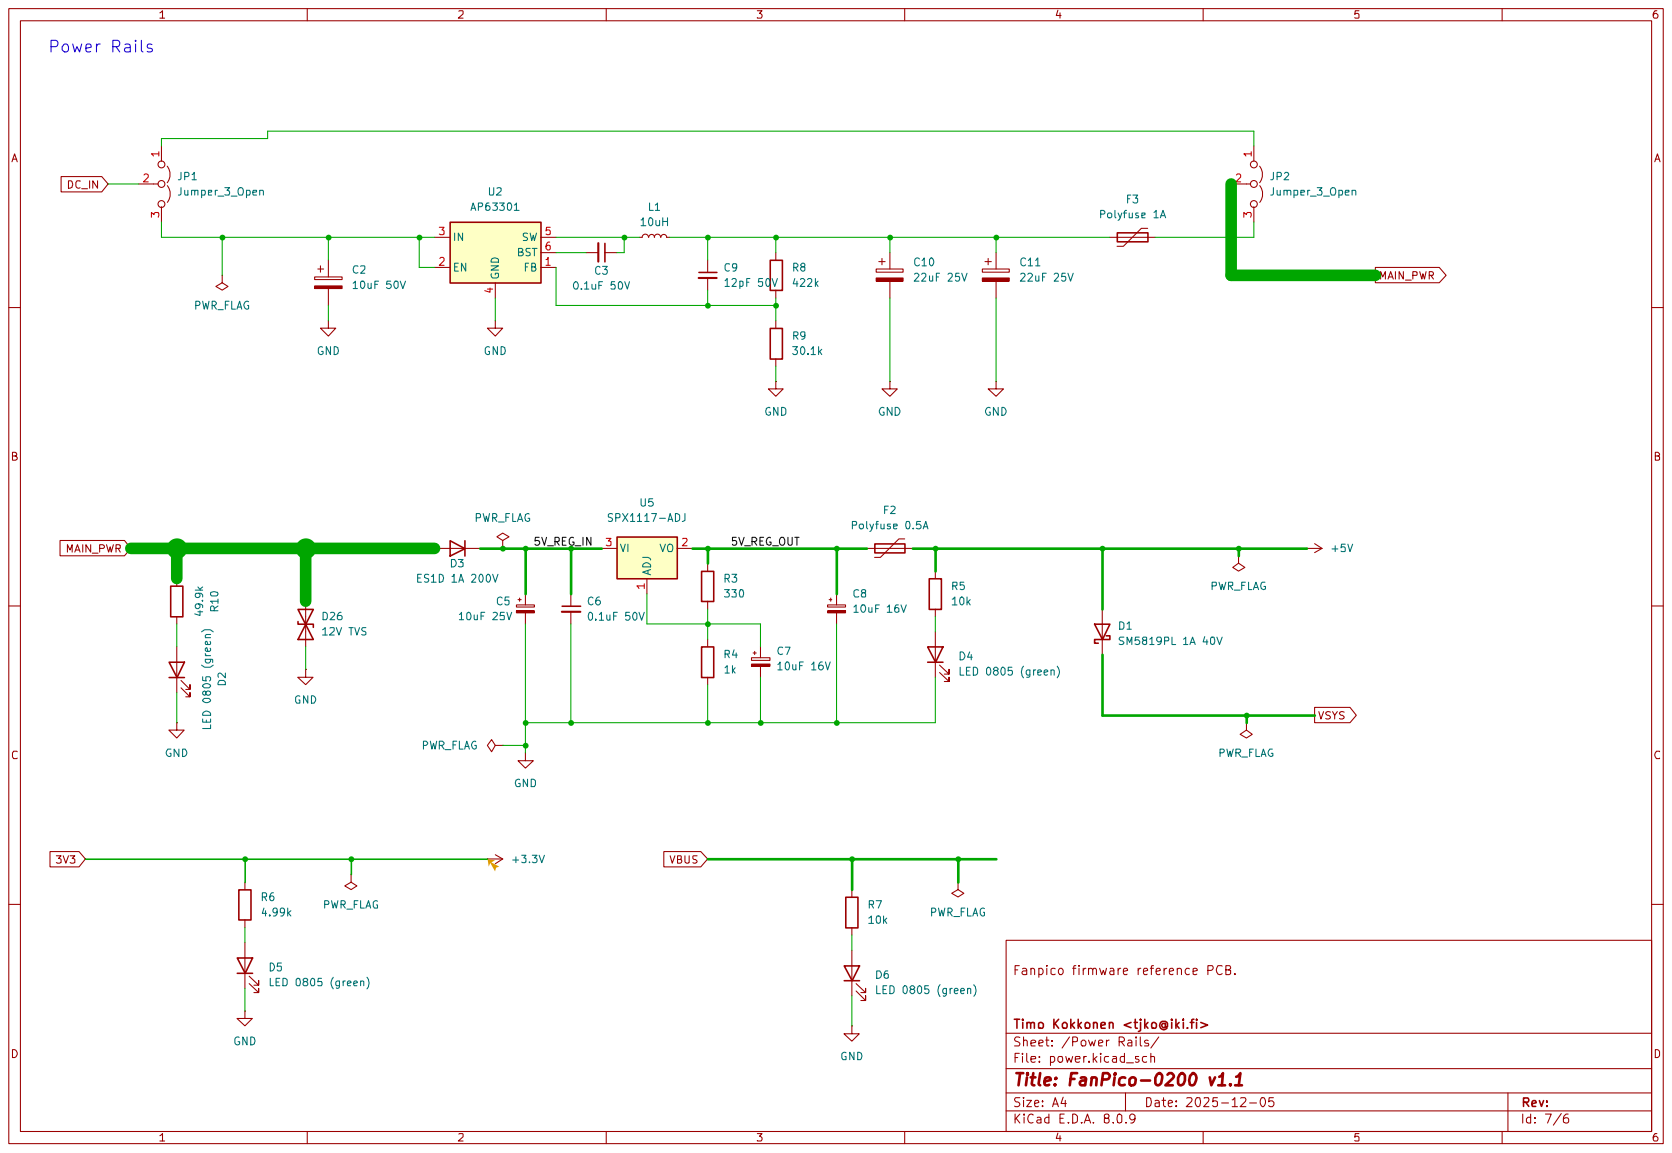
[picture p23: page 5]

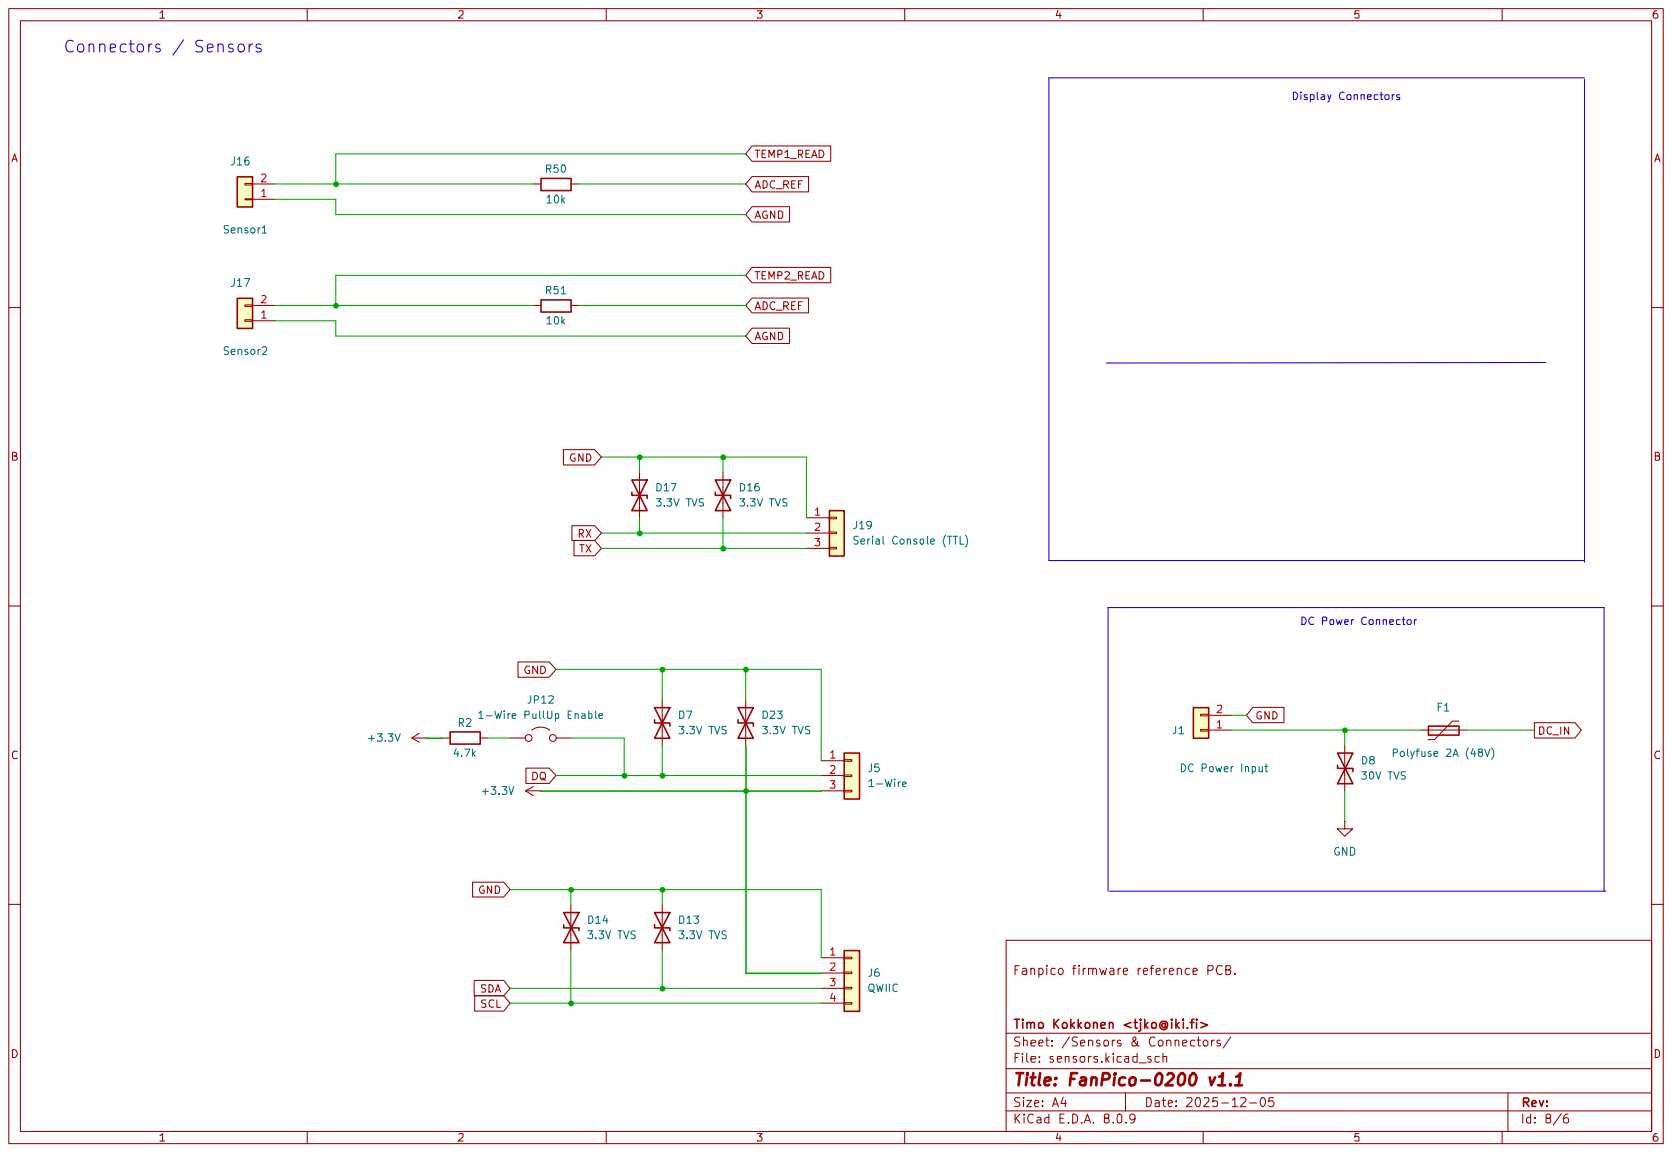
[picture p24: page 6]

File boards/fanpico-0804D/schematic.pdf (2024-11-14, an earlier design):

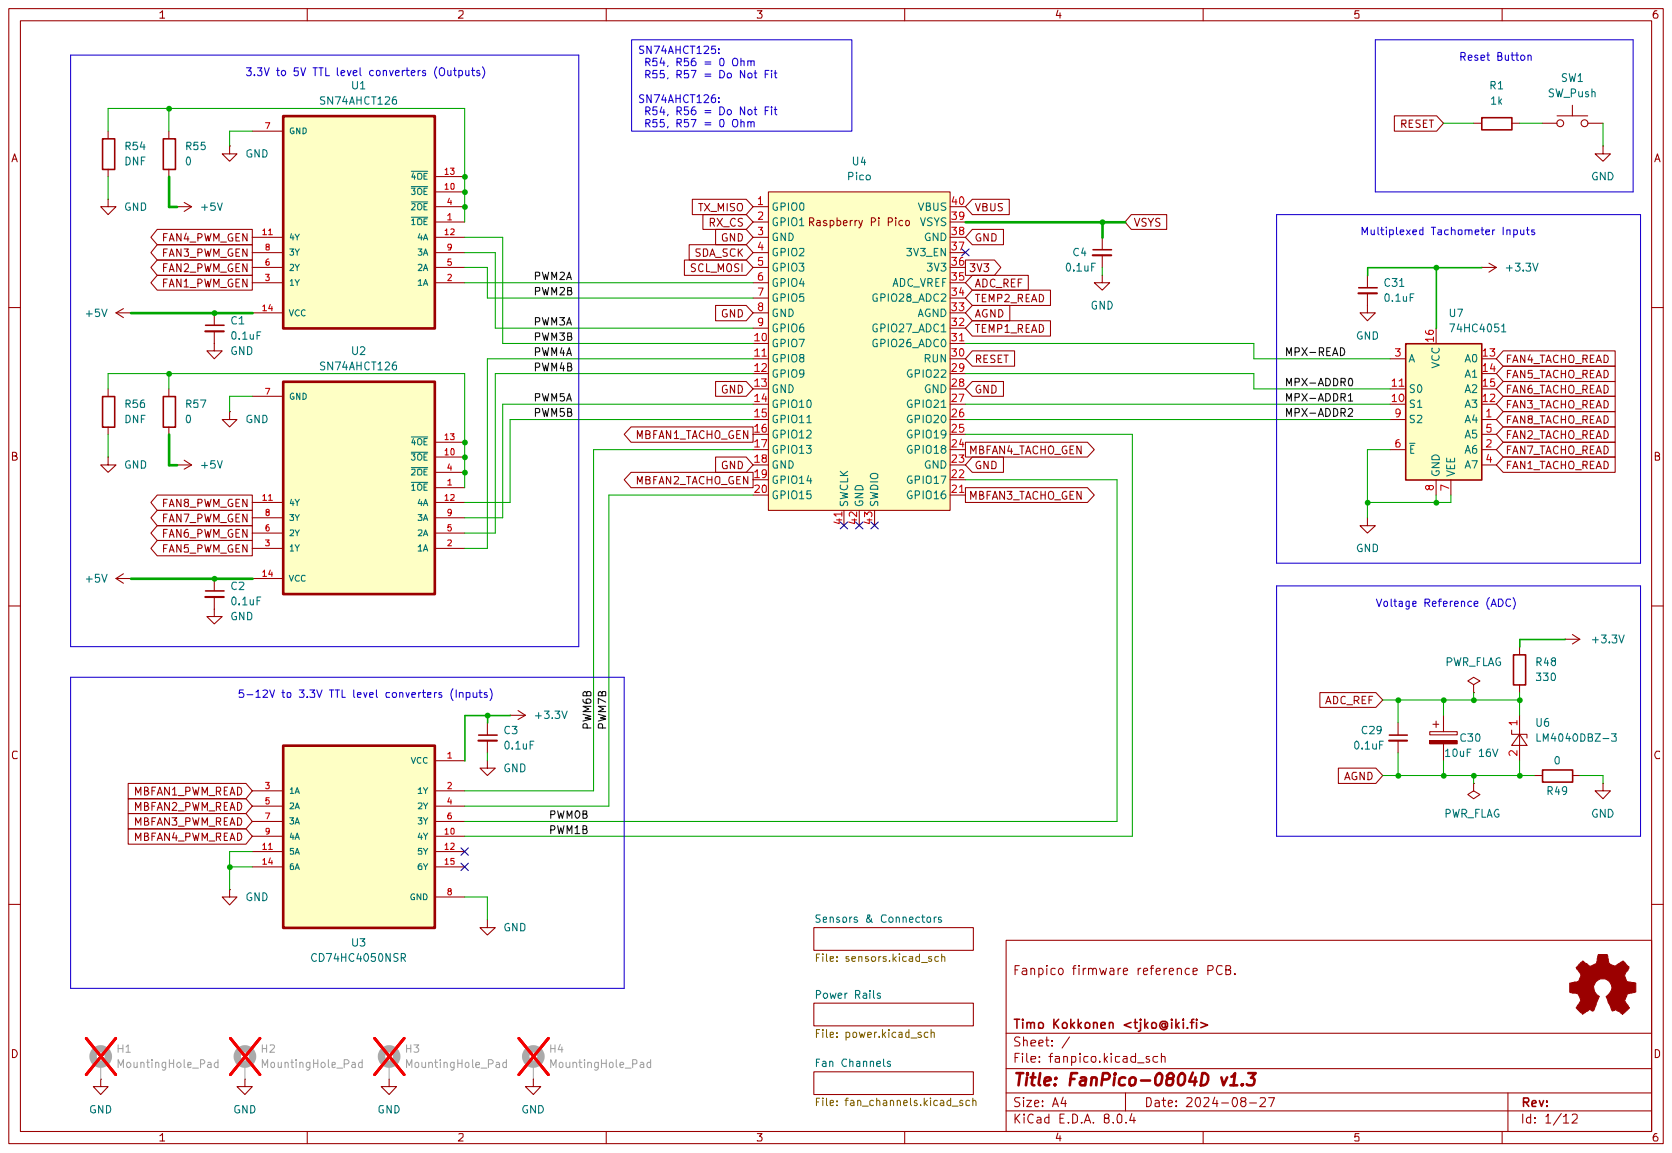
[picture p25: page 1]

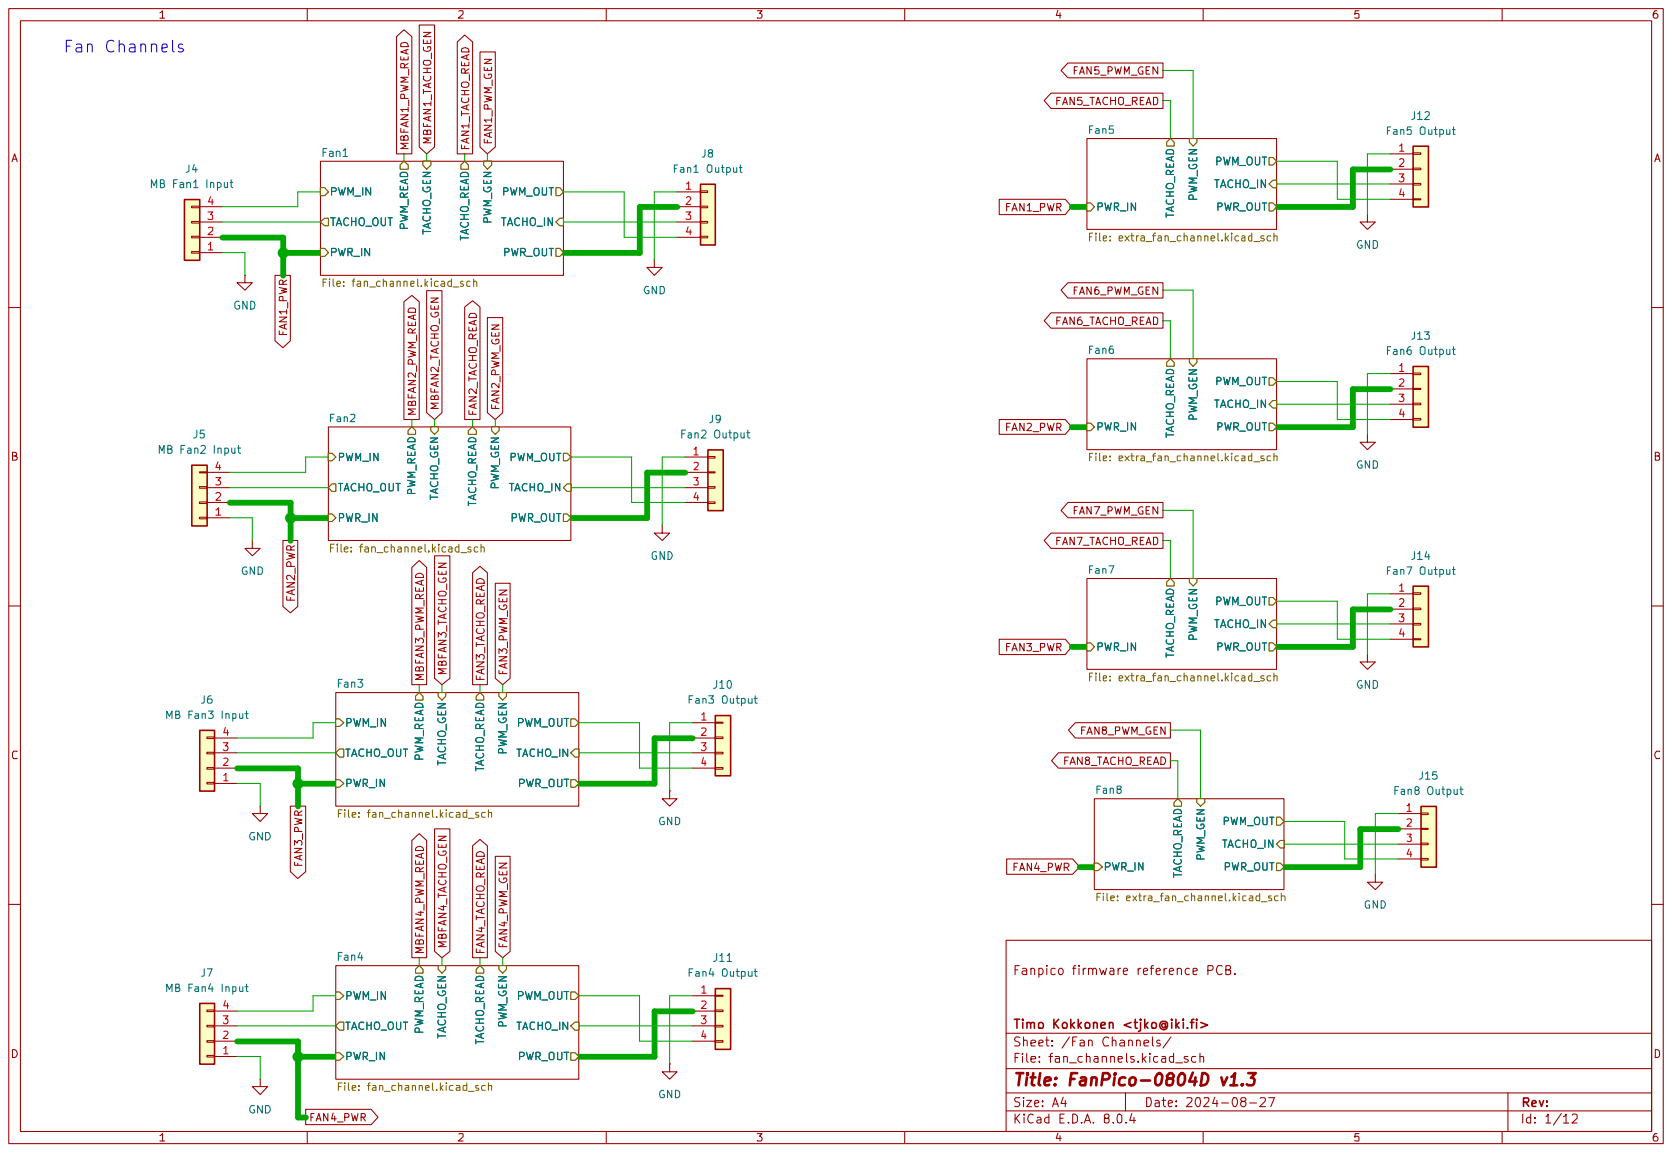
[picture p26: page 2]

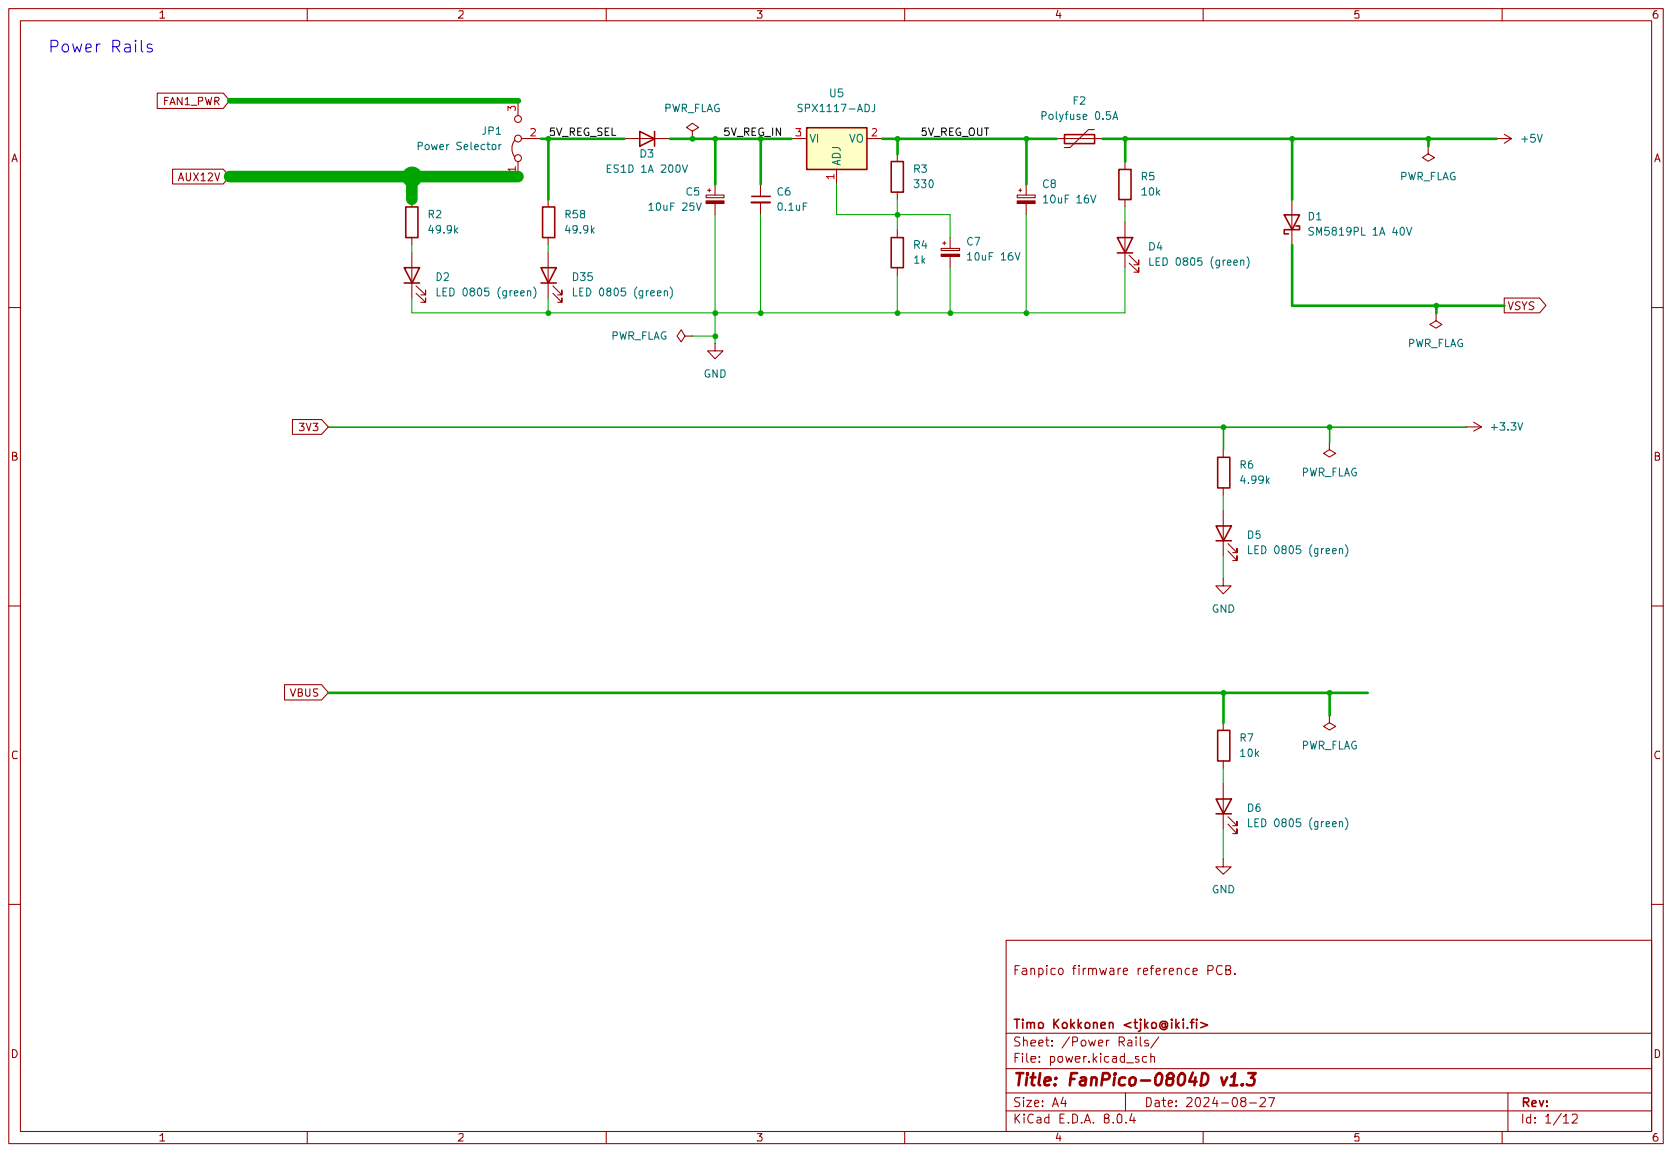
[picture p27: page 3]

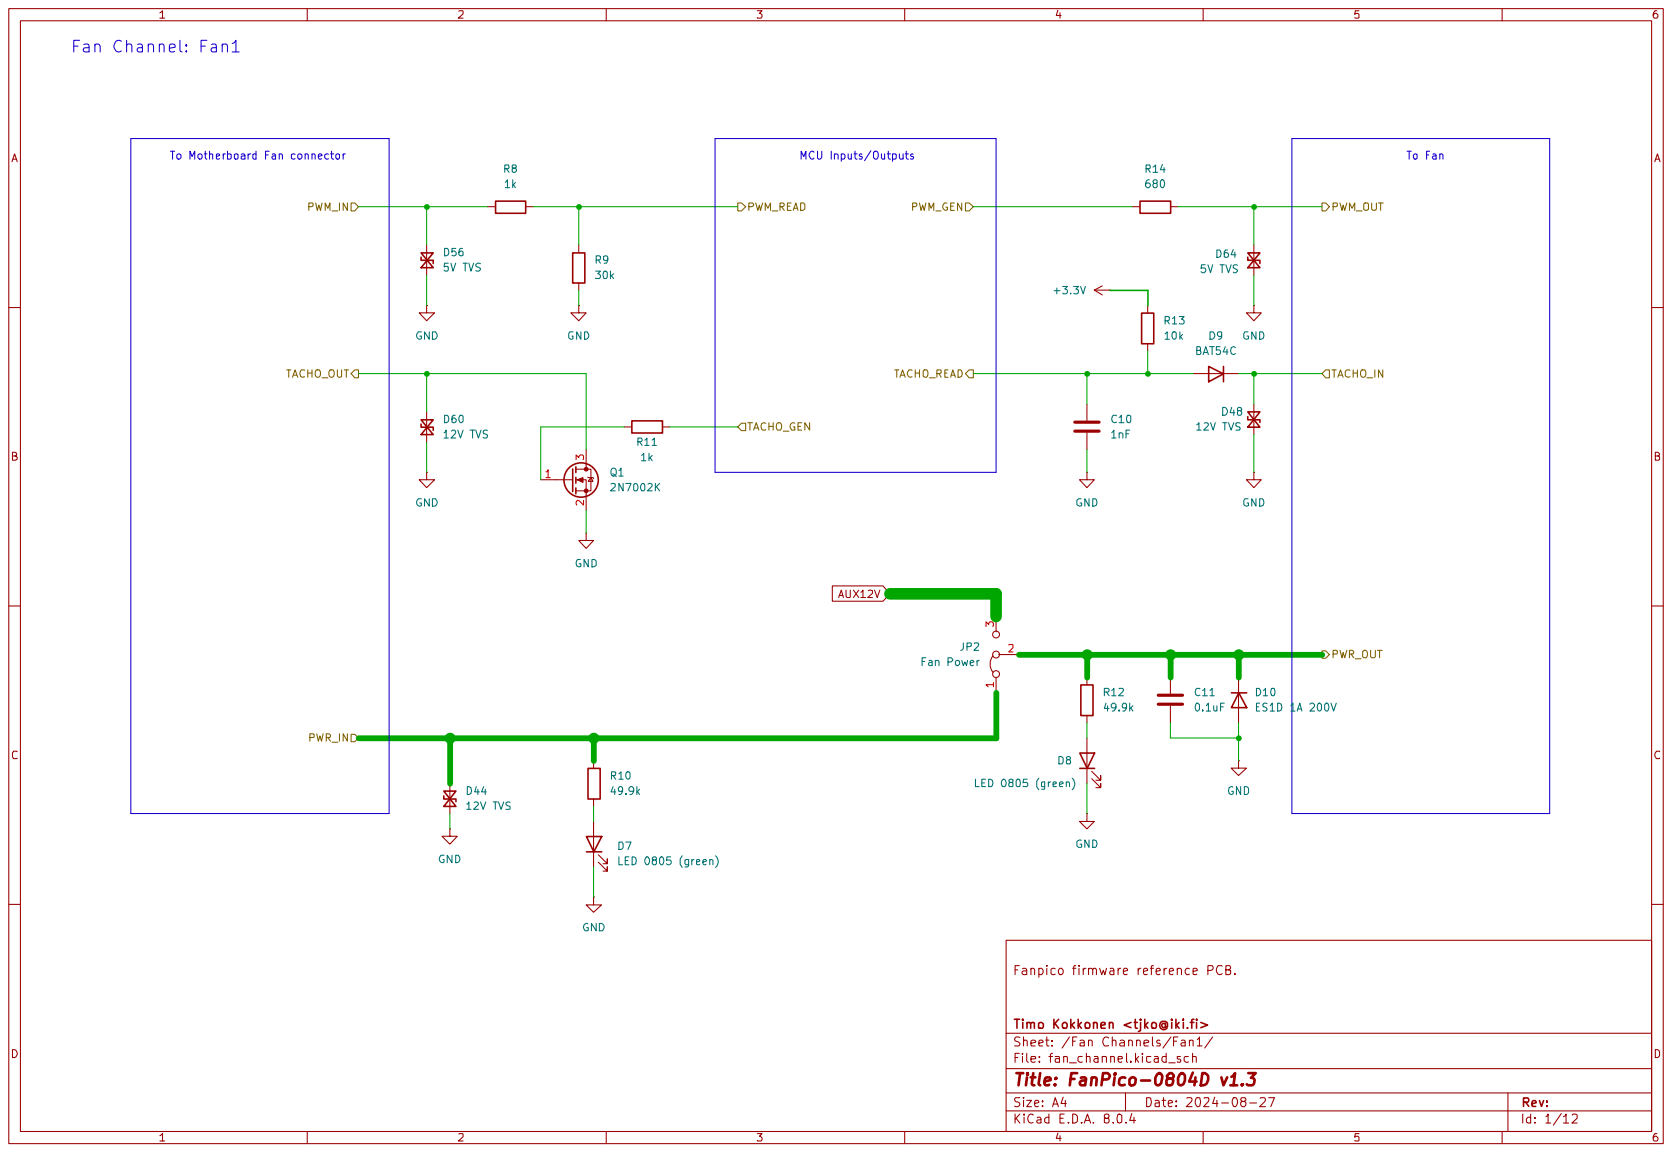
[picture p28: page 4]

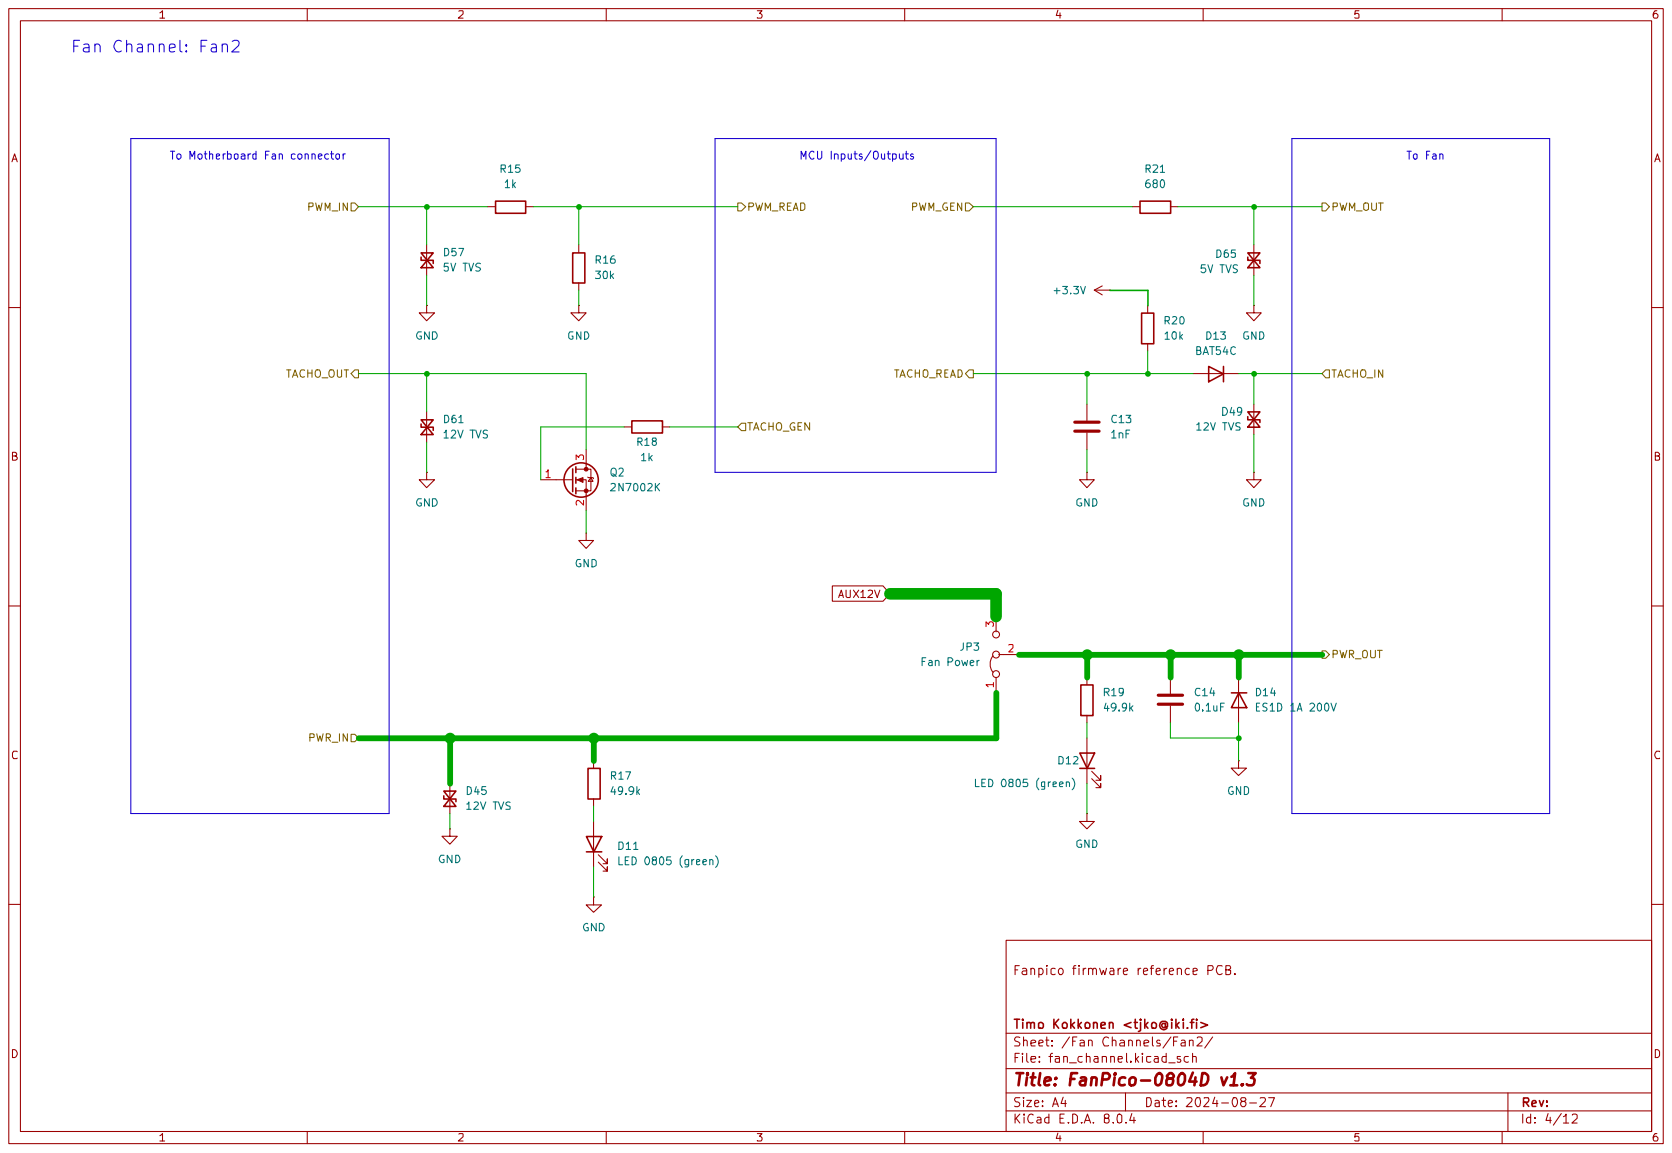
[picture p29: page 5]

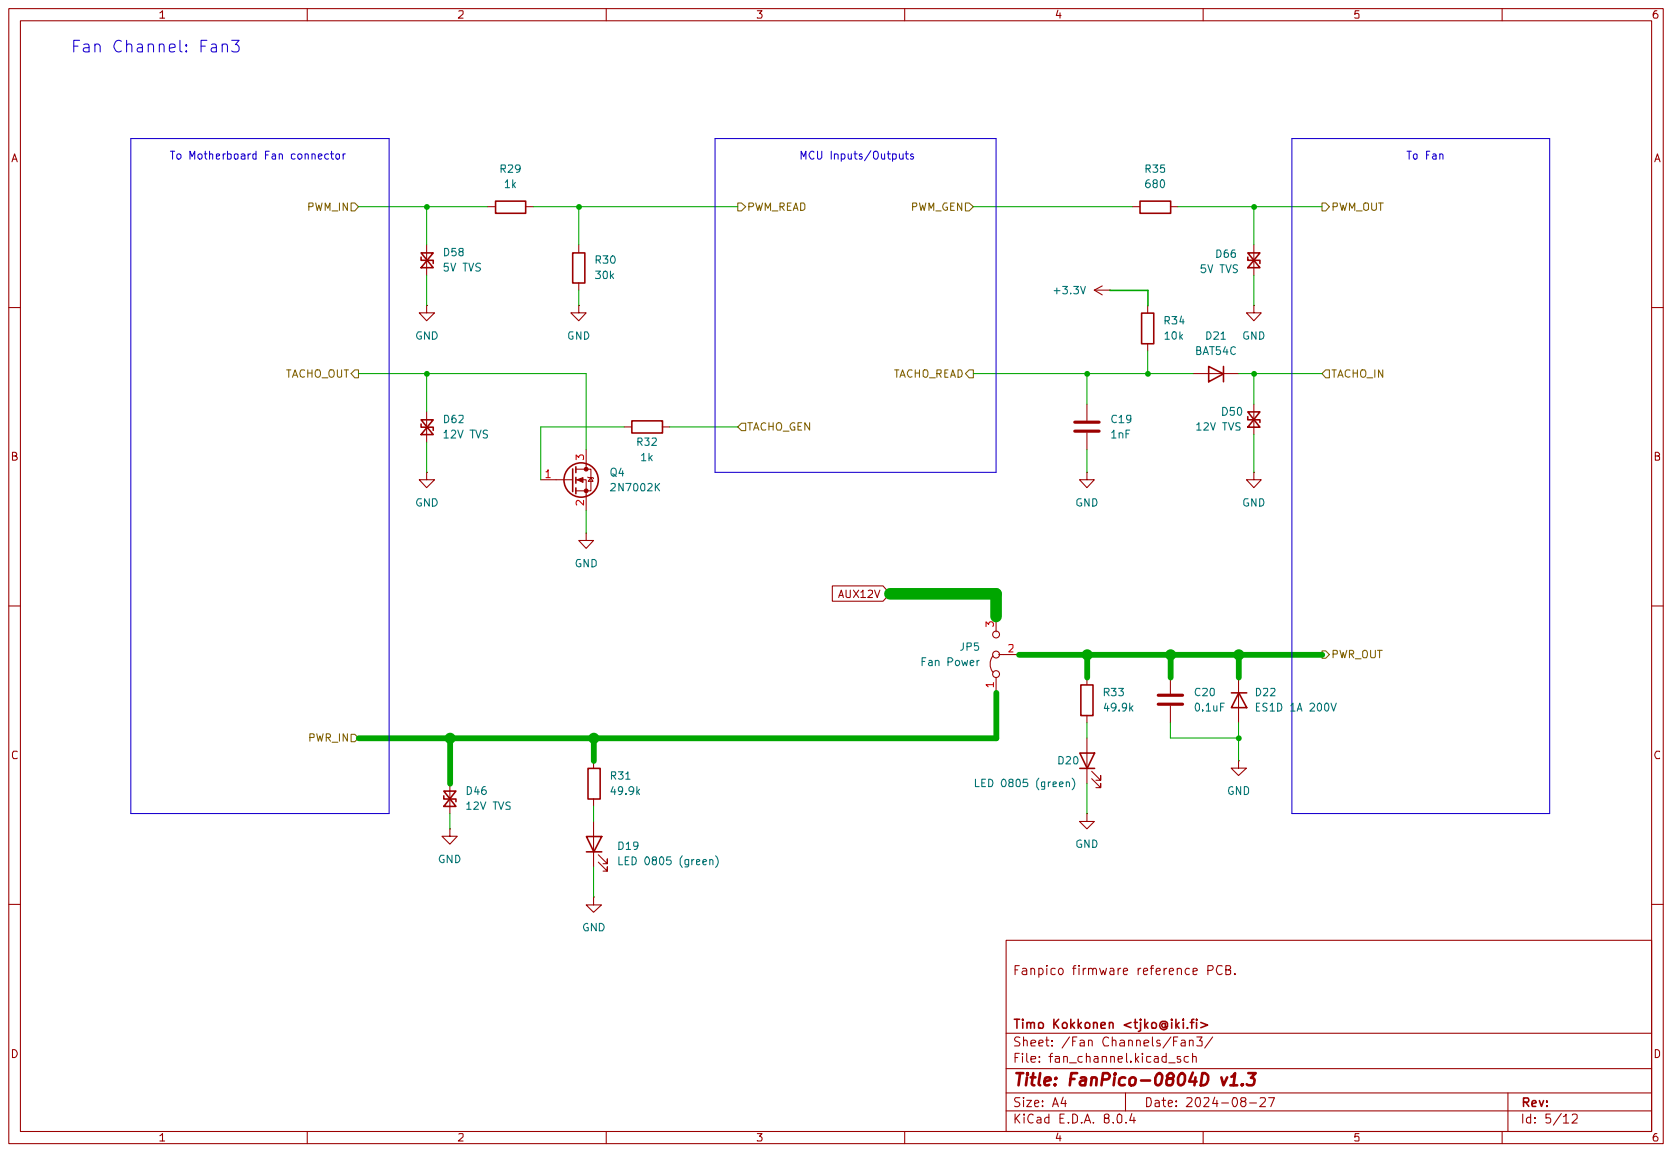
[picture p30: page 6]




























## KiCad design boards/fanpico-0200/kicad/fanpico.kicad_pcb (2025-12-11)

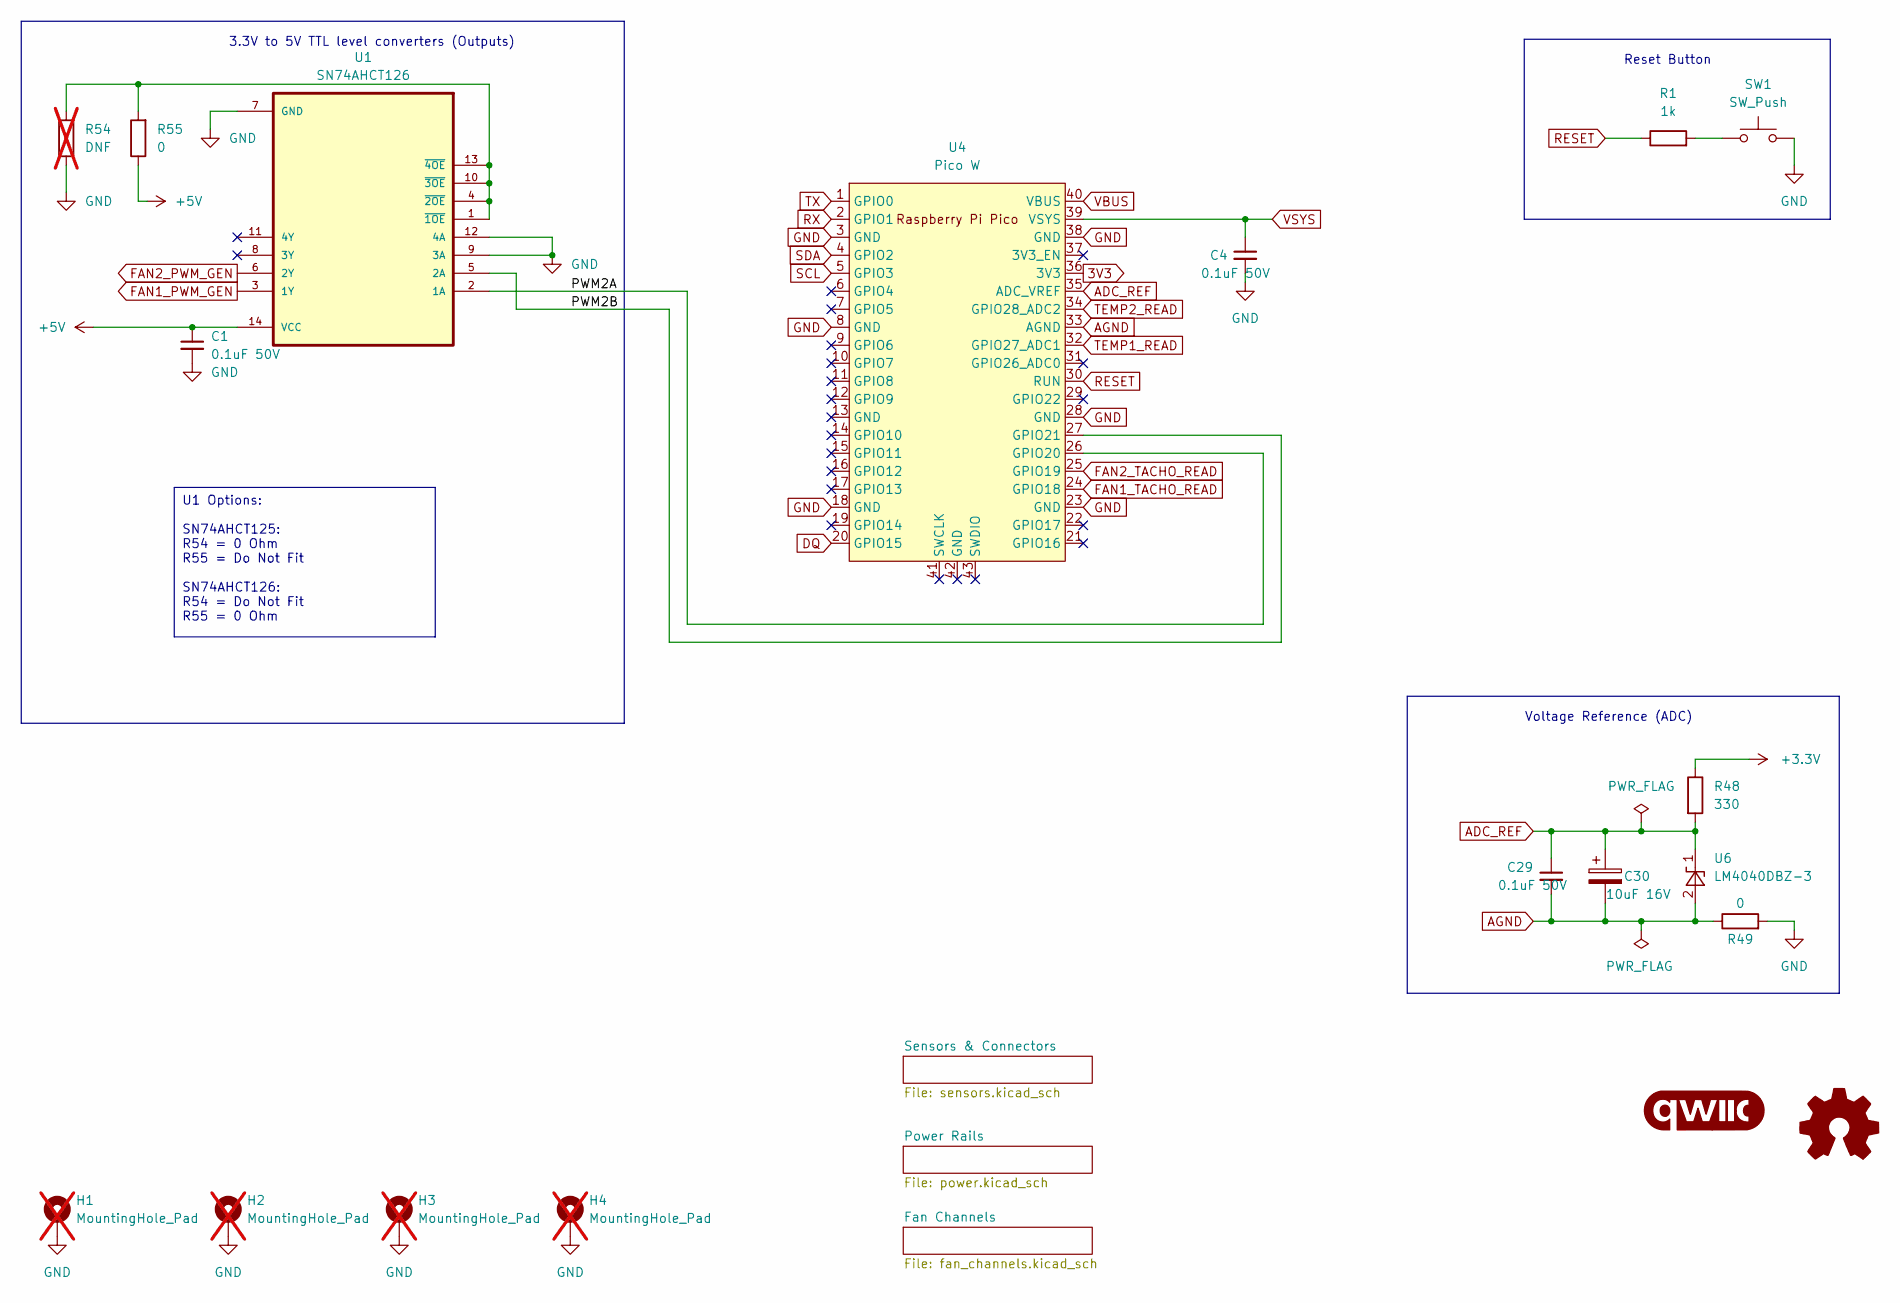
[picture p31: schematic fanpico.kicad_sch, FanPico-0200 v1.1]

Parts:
C1, C4, C29: 0.1uF 50V; C_0603_1608Metric_Pad1.08x0.95mm_HandSolder; Manufacturer Part Number CL10B104KB8NNNC; LCSC Part Number C1591
C30: 10uF 16V; CP_EIA-3216-18_Kemet-A_Pad1.58x1.35mm_HandSolder; Mouser Part Number 80--T491A106K016; LCSC Part Number C7171
G1: qwiic_Logo; qwiic_5mm
G2: Logo_Open_Hardware_Small; OSHW-Logo_5.7x6mm_SilkScreen
H1, H2, H3, H4: MountingHole_Pad; MountingHole_3.2mm_M3_Pad_Via; not fitted
R1: 1k; R_0603_1608Metric_Pad0.98x0.95mm_HandSolder; Manufacturer Part Number RC0603FR-071KL; LCSC Part Number C22548
R48: 330; R_0603_1608Metric_Pad0.98x0.95mm_HandSolder; Manufacturer Part Number RC0603FR-07330RL; LCSC Part Number C105881
R49, R55: 0; R_0603_1608Metric_Pad0.98x0.95mm_HandSolder; Manufacturer Part Number 0603WAF0000T5E; LCSC Part Number C21189
R54: DNF; R_0603_1608Metric_Pad0.98x0.95mm_HandSolder; Manufacturer Part Number 0603WAF0000T5E; LCSC Part Number C21189; not fitted
SW1: SW_Push; SW-SMD_L3.9-W3.0-P4.45; Manufacturer Part Number TS-1088-AR02016; LCSC Part Number C720477
U1: SN74AHCT126; TSSOP-14_4.4x5mm_P0.65mm; Manufacturer Part Number SN74AHCT126PWR; LCSC Part Number C155177
U4: Pico W; RPi_Pico_PicoW_SMD_TH; Manufacturer Part Number Pico W / Pico 2 W
U6: LM4040DBZ-3; SOT-23; Manufacturer Part Number LM4040AIM3-3.0+T; LCSC Part Number C143326

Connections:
3V3: R48.1, U4.36 (3V3); also elsewhere on the board
+5V: C1.1, R55.1, U1.14 (VCC); also elsewhere on the board
/PWM2A: U1.2 (1A), U4.26 (GPIO20)
/PWM2B: U1.5 (2A), U4.27 (GPIO21)
ADC_REF: C29.1, C30.1, R48.2, U4.35 (ADC_VREF), U6.1 (K); also elsewhere on the board
AGND: C29.2, C30.2, R49.1, U4.33 (AGND), U6.2 (A); also elsewhere on the board
DQ: U4.20 (GPIO15); also elsewhere on the board
FAN1_PWM_GEN: U1.3 (1Y); also elsewhere on the board
FAN1_TACHO_READ: U4.24 (GPIO18); also elsewhere on the board
FAN2_PWM_GEN: U1.6 (2Y); also elsewhere on the board
FAN2_TACHO_READ: U4.25 (GPIO19); also elsewhere on the board
GND: C1.2, C4.2, H1.1, H2.1, H3.1, H4.1, R49.2, R54.1, SW1.2, U1.7 (GND), U1.9 (3A), U1.12 (4A), U4.3 (GND), U4.8 (GND), U4.18 (GND), U4.23 (GND), U4.28 (GND), U4.38 (GND); also elsewhere on the board
unnamed: R1.2, SW1.1
unnamed: R54.2, R55.2, U1.1 (~1OE), U1.4 (~2OE), U1.10 (~3OE), U1.13 (~4OE)
RESET: R1.1, U4.30 (RUN)
RX: U4.2 (GPIO1); also elsewhere on the board
SCL: U4.5 (GPIO3); also elsewhere on the board
SDA: U4.4 (GPIO2); also elsewhere on the board
TEMP1_READ: U4.32 (GPIO27_ADC1); also elsewhere on the board
TEMP2_READ: U4.34 (GPIO28_ADC2); also elsewhere on the board
TX: U4.1 (GPIO0); also elsewhere on the board
VBUS: U4.40 (VBUS); also elsewhere on the board
VSYS: C4.1, U4.39 (VSYS); also elsewhere on the board

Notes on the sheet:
U1 Options: SN74AHCT125: R54 = 0 Ohm R55 = Do Not Fit SN74AHCT126: R54 = Do Not Fit R55 = 0 Ohm
Reset Button
3.3V to 5V TTL level converters (Outputs)
Voltage Reference (ADC)

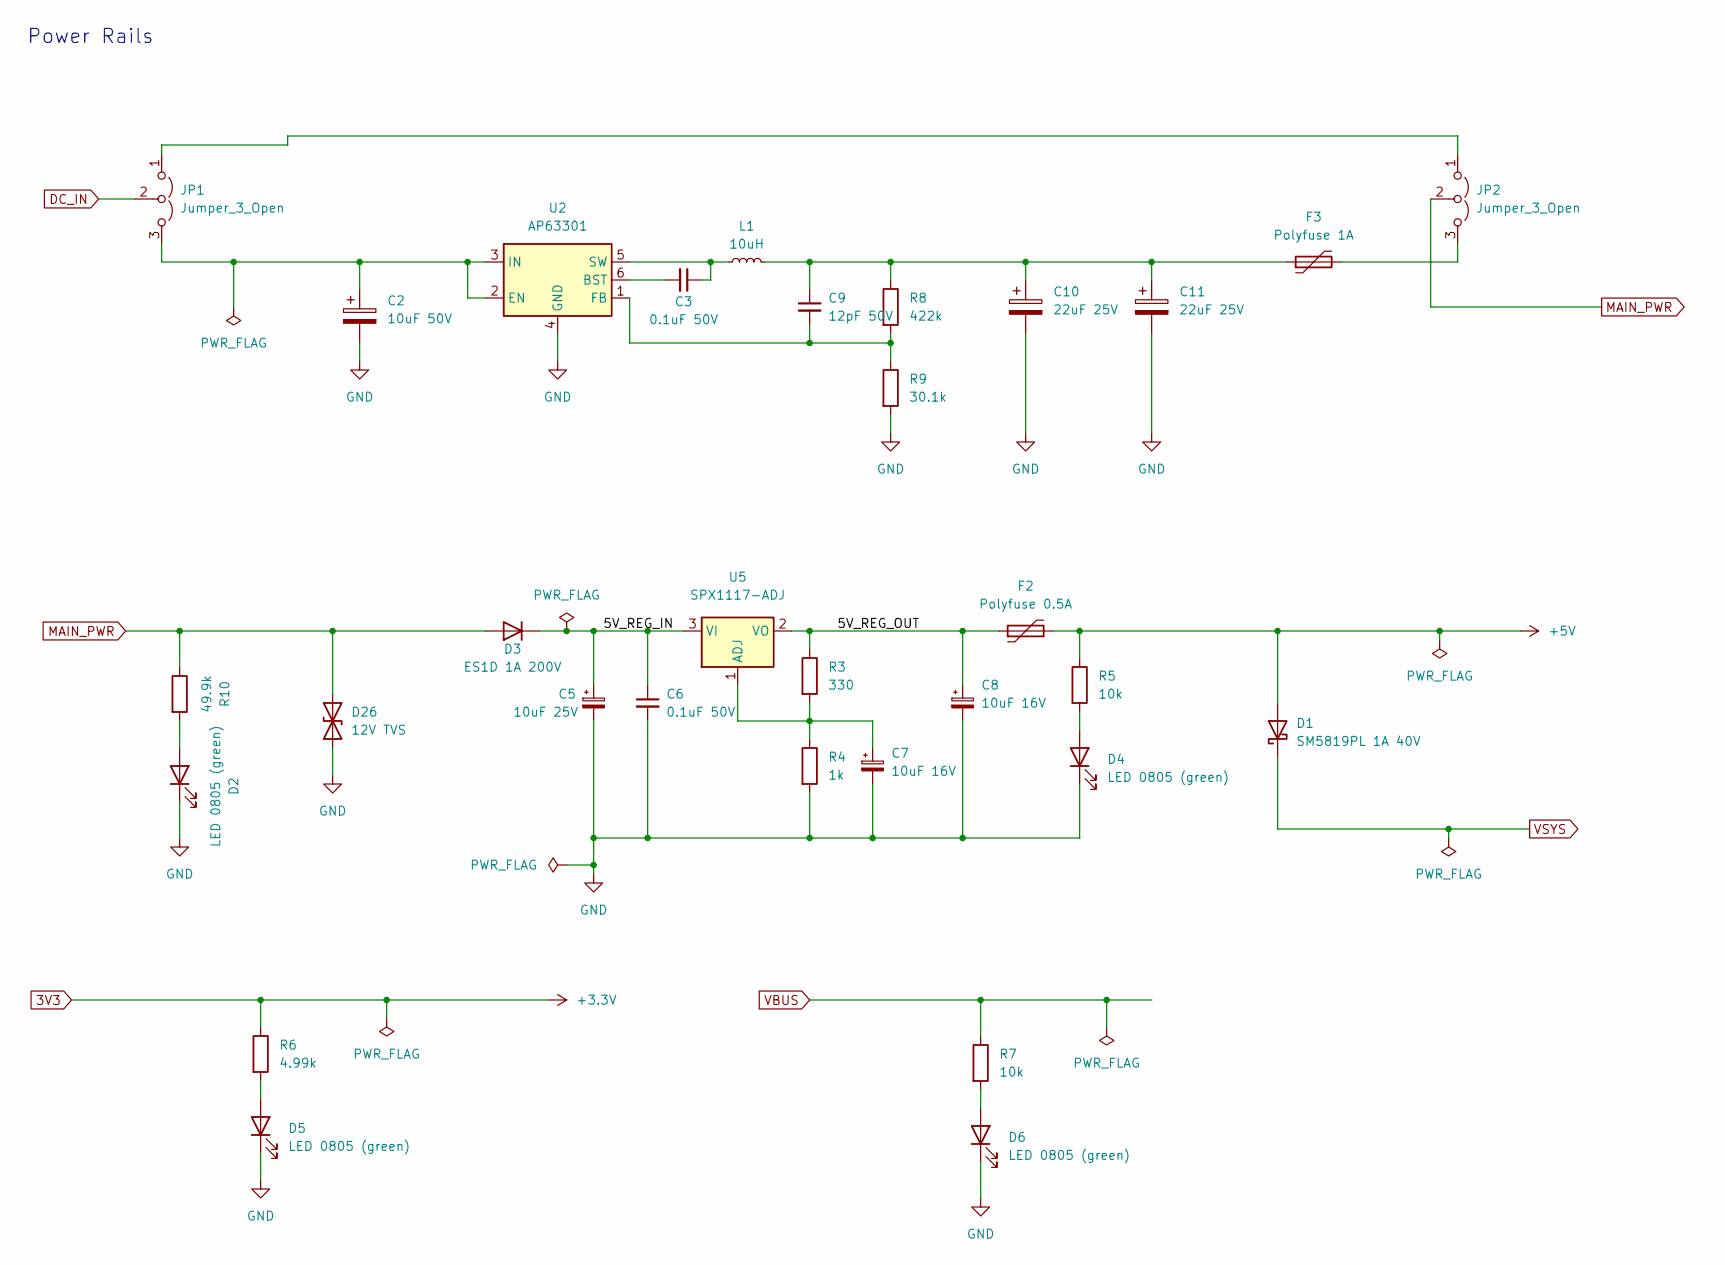
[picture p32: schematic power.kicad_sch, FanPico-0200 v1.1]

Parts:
C2: 10uF 50V; CP_EIA-3216-18_Kemet-A_Pad1.58x1.35mm_HandSolder; Manufacturer Part Number CL31B106KBHNNNE; LCSC Part Number C89632
C3, C6: 0.1uF 50V; C_0603_1608Metric_Pad1.08x0.95mm_HandSolder; Manufacturer Part Number CL10B104KB8NNNC; LCSC Part Number C1591
C5: 10uF 25V; CP_EIA-3528-12_Kemet-T_Pad1.50x2.35mm_HandSolder; Manufacturer Part Number TAJB106K025RNJ; LCSC Part Number C7194
C7, C8: 10uF 16V; CP_EIA-3216-18_Kemet-A_Pad1.58x1.35mm_HandSolder; Mouser Part Number 80--T491A106K016; LCSC Part Number C7171
C9: 12pF 50V; C_0603_1608Metric_Pad1.08x0.95mm_HandSolder; Manufacturer Part Number CL10C120JB8NNNC; LCSC Part Number C38523
C10, C11: 22uF 25V; CP_EIA-3216-18_Kemet-A_Pad1.58x1.35mm_HandSolder; Manufacturer Part Number CL31A226KAHNNNE; LCSC Part Number C12891
D1: SM5819PL 1A 40V; D_SMA; Mouser Part Number 833-SM5819PL-TP; LCSC Part Number C669023
D2, D4, D5, D6: LED 0805 (green); LED_0805_2012Metric_Pad1.15x1.40mm_HandSolder; Mouser Part Number 710-150080GS75000; LCSC Part Number C434432
D3: ES1D 1A 200V; D_SMA_Handsoldering; Mouser Part Number 512-ES1D; LCSC Part Number C445494
D26: 12V TVS; D_SOD-323_HandSoldering; Manufacturer Part Number UDD32C12L01-ES; LCSC Part Number C5199168
F2: Polyfuse 0.5A; Fuse_1206_3216Metric_Pad1.42x1.75mm_HandSolder; Mouser Part Number 530-0ZCJ0050AF2E; LCSC Part Number C70072
F3: Polyfuse 1A; Fuse_1206_3216Metric_Pad1.42x1.75mm_HandSolder; Manufacturer Part Number 1206L100/30NR; LCSC Part Number C7542958
JP1, JP2: Jumper_3_Open; PinHeader_1x03_P2.54mm_Vertical; Manufacturer Part Number PZ254V-11-03P; LCSC Part Number C2937625
L1: 10uH; IND-SMD_L7.2-W6.6_GPSR07X0; Manufacturer Part Number CYA0630-10UH; LCSC Part Number C5189958
R3: 330; R_0603_1608Metric_Pad0.98x0.95mm_HandSolder; Manufacturer Part Number RC0603FR-07330RL; LCSC Part Number C105881
R4: 1k; R_0603_1608Metric_Pad0.98x0.95mm_HandSolder; Manufacturer Part Number RC0603FR-071KL; LCSC Part Number C22548
R5, R7: 10k; R_0603_1608Metric_Pad0.98x0.95mm_HandSolder; Manufacturer Part Number RC0603FR-0710KL; LCSC Part Number C98220
R6: 4.99k; R_0603_1608Metric_Pad0.98x0.95mm_HandSolder; Manufacturer Part Number RC0603FR-074K99L; LCSC Part Number C114621
R8: 422k; R_0603_1608Metric_Pad0.98x0.95mm_HandSolder; Manufacturer Part Number RC0603FR-07422KL; LCSC Part Number C245966
R9: 30.1k; R_0603_1608Metric_Pad0.98x0.95mm_HandSolder; Manufacturer Part Number 0603WAF3012T5E; LCSC Part Number C23000
R10: 49.9k; R_0603_1608Metric_Pad0.98x0.95mm_HandSolder; Manufacturer Part Number RC0603FR-0749K9L; LCSC Part Number C114624
U2: AP63301; TSOT-26; Manufacturer Part Number AP63301WU-7; LCSC Part Number C2158003
U5: SPX1117-ADJ; SOT-223-3_TabPin2; Manufacturer Part Number SPX1117M3-L/TR; LCSC Part Number C67402

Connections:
3V3: R6.1; also elsewhere on the board
+5V: D1.2 (A), F2.2, R5.1; also elsewhere on the board
/Power Rails/5V_REG_IN: C5.1, C6.1, D3.1 (K), U5.3 (VI)
/Power Rails/5V_REG_OUT: C8.1, F2.1, R3.1, U5.2 (VO)
DC_IN: JP1.2 (C); also elsewhere on the board
GND: C2.2, C5.2, C6.2, C7.2, C8.2, C10.2, C11.2, D2.1 (K), D4.1 (K), D5.1 (K), D6.1 (K), D26.1 (A1), R4.2, R9.2, U2.4 (GND); also elsewhere on the board
MAIN_PWR: D3.2 (A), D26.2 (A2), JP2.2 (C), R10.1; also elsewhere on the board
unnamed: C9.1, C10.1, C11.1, F3.1, L1.2, R8.1
unnamed: D2.2 (A), R10.2
unnamed: D4.2 (A), R5.2
unnamed: D5.2 (A), R6.2
unnamed: D6.2 (A), R7.2
unnamed: JP1.1 (A), JP2.1 (A)
unnamed: C2.1, JP1.3 (B), U2.2 (EN), U2.3 (IN)
unnamed: F3.2, JP2.3 (B)
unnamed: C3.2, U2.6 (BST)
unnamed: C9.2, R8.2, R9.1, U2.1 (FB)
unnamed: C3.1, L1.1, U2.5 (SW)
unnamed: C7.1, R3.2, R4.1, U5.1 (ADJ)
VBUS: R7.1; also elsewhere on the board
VSYS: D1.1 (K); also elsewhere on the board

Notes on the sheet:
Power Rails

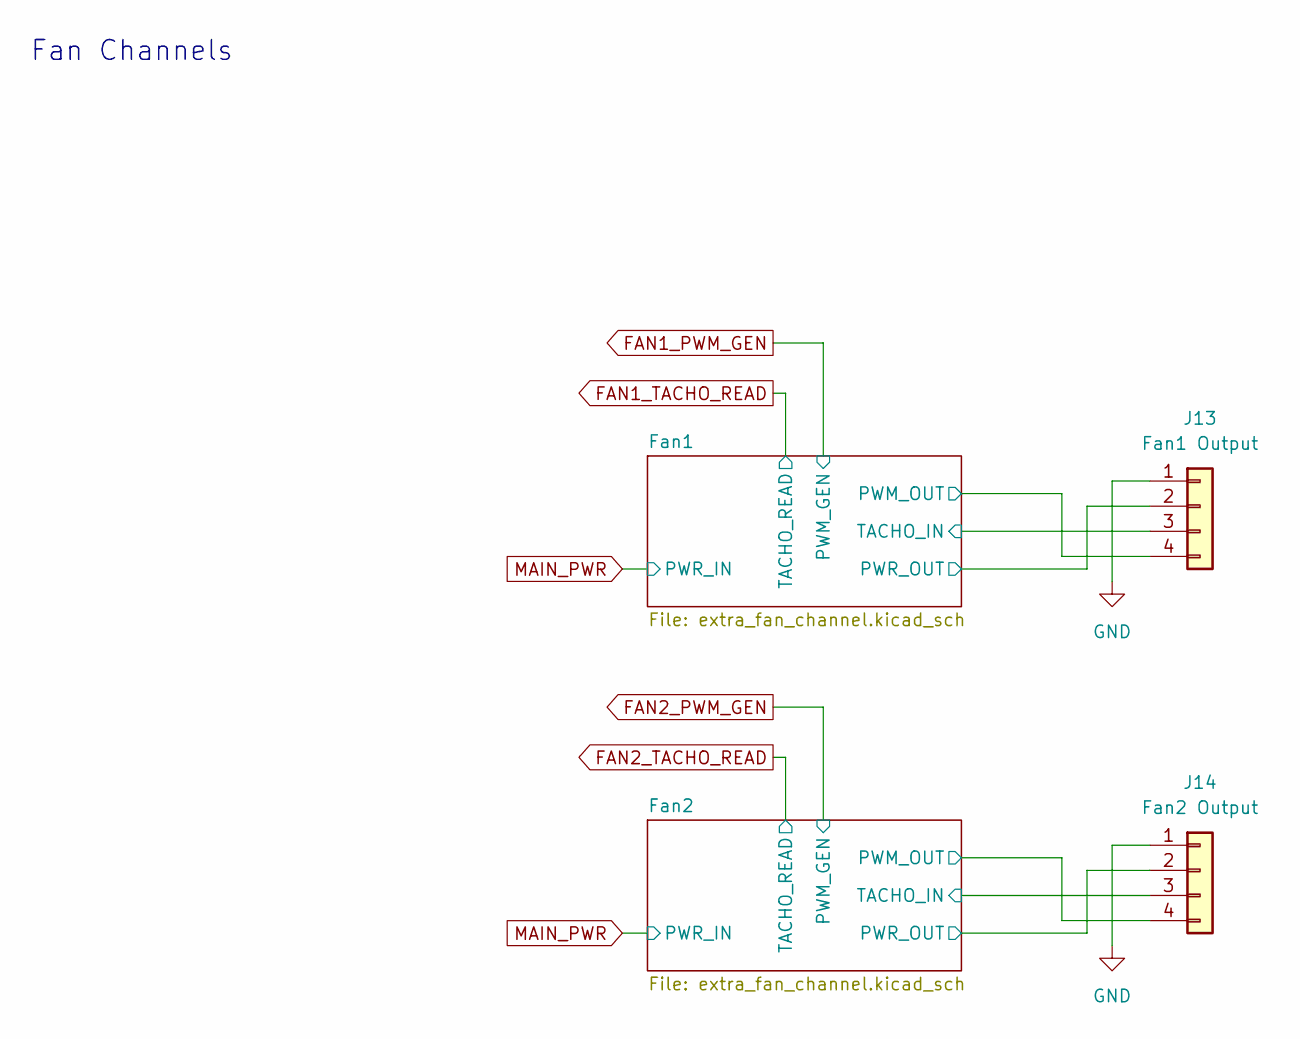
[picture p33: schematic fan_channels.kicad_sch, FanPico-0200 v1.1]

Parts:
J13: Fan1 Output; FanPinHeader_1x04_P2.54mm_Vertical; Mouser Part Number 538-47053-1000; LCSC Part Number C240840
J14: Fan2 Output; FanPinHeader_1x04_P2.54mm_Vertical; Mouser Part Number 538-47053-1000; LCSC Part Number C240840

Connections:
/Fan Channels/Fan1/PWM_OUT: J13.4; also elsewhere on the board
/Fan Channels/Fan1/TACHO_IN: J13.3; also elsewhere on the board
/Fan Channels/Fan2/PWM_OUT: J14.4; also elsewhere on the board
/Fan Channels/Fan2/TACHO_IN: J14.3; also elsewhere on the board
GND: J13.1, J14.1; also elsewhere on the board
MAIN_PWR: J13.2, J14.2; also elsewhere on the board

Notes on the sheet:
Fan Channels

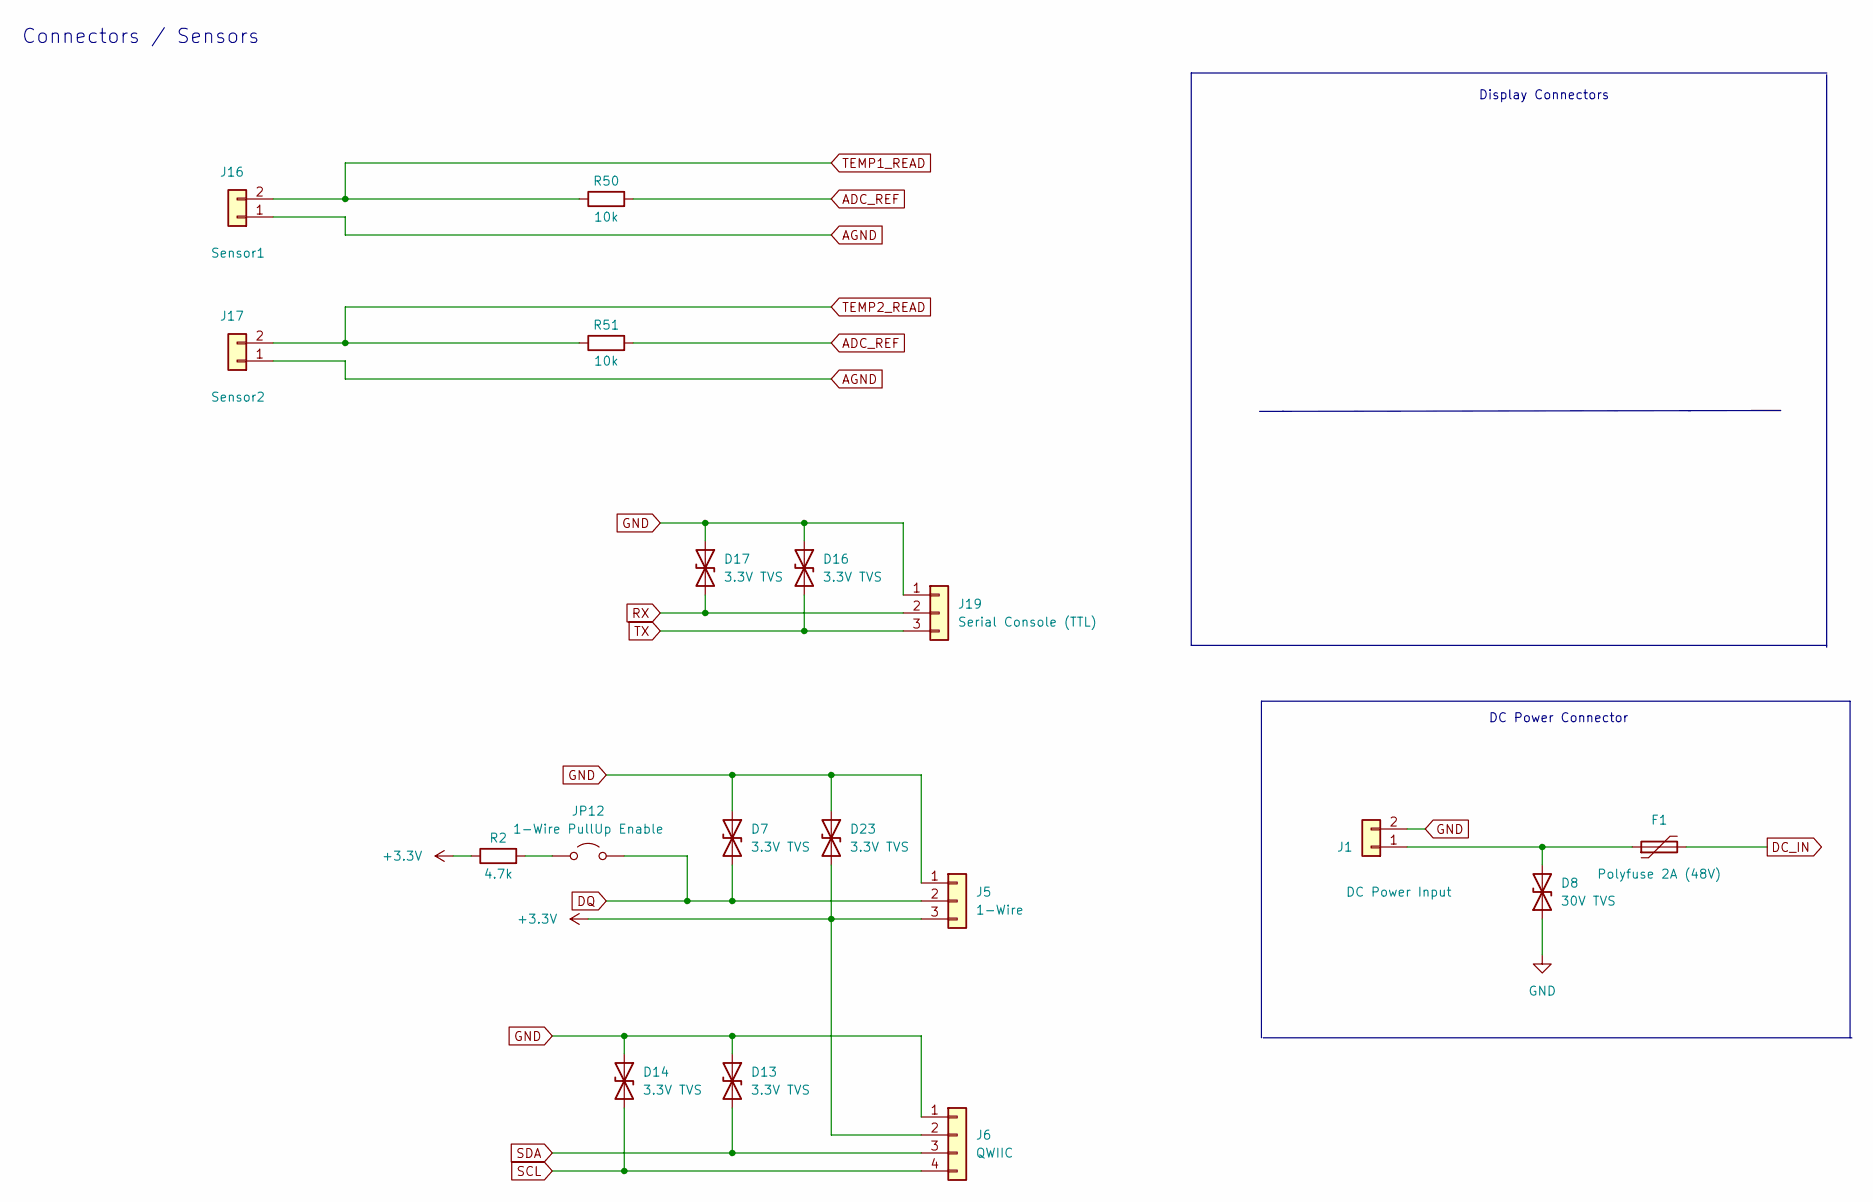
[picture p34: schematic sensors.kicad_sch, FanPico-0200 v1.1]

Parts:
D7, D13, D14, D16, D17, D23: 3.3V TVS; D_SOD-323_HandSoldering; Manufacturer Part Number UDD32C03L01; LCSC Part Number C78439
D8: 30V TVS; D_0603_1608Metric_Pad1.05x0.95mm_HandSolder; Manufacturer Part Number PESD0603MS30-MS; LCSC Part Number C7473181
F1: Polyfuse 2A (48V); Fuse_2920_7451Metric_Pad2.10x5.45mm_HandSolder; Manufacturer Part Number BSMD2920-200-48V; LCSC Part Number C22399926
J1: DC Power Input; TerminalBlock_Phoenix_MKDS-1,5-2_1x02_P5.00mm_Horizontal; Mouser Part Number 651-1715022; LCSC Part Number C1509679
J5: 1-Wire; TerminalBlock_TE_282834-3_1x03_P2.54mm_Horizontal; Manufacturer Part Number 2.54-3P; LCSC Part Number C68305
J6: QWIIC; JST_SH_SM04B-SRSS-TB_1x04-1MP_P1.00mm_Horizontal; Manufacturer Part Number SM04B-SRSS-TB(LF)(SN); LCSC Part Number C160404
J16: Sensor1; JST_XH_B2B-XH-A_1x02_P2.50mm_Vertical; Manufacturer Part Number XH-2A; LCSC Part Number C20079
J17: Sensor2; JST_XH_B2B-XH-A_1x02_P2.50mm_Vertical; Manufacturer Part Number XH-2A; LCSC Part Number C20079
J19: Serial Console (TTL); PinHeader_1x03_P2.54mm_Vertical; Manufacturer Part Number PZ254V-11-03P; LCSC Part Number C2937625
JP12: 1-Wire PullUp Enable; PinHeader_1x02_P2.54mm_Vertical; Manufacturer Part Number PZ254V-11-02P; LCSC Part Number C492401
R2: 4.7k; R_0603_1608Metric_Pad0.98x0.95mm_HandSolder; Manufacturer Part Number RC0603FR-074K7L; LCSC Part Number C99782
R50, R51: 10k; R_0603_1608Metric_Pad0.98x0.95mm_HandSolder; Manufacturer Part Number RC0603FR-0710KL; LCSC Part Number C98220

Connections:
3V3: D23.2 (A2), J5.3, J6.2, R2.1; also elsewhere on the board
ADC_REF: R50.2, R51.2; also elsewhere on the board
AGND: J16.1, J17.1; also elsewhere on the board
DC_IN: F1.2; also elsewhere on the board
DQ: D7.2 (A2), J5.2, JP12.2 (B); also elsewhere on the board
GND: D7.1 (A1), D8.1 (A1), D13.1 (A1), D14.1 (A1), D16.1 (A1), D17.1 (A1), D23.1 (A1), J1.2, J5.1, J6.1, J19.1; also elsewhere on the board
unnamed: D8.2 (A2), F1.1, J1.1
unnamed: JP12.1 (A), R2.2
RX: D17.2 (A2), J19.2; also elsewhere on the board
SCL: D14.2 (A2), J6.4; also elsewhere on the board
SDA: D13.2 (A2), J6.3; also elsewhere on the board
TEMP1_READ: J16.2, R50.1; also elsewhere on the board
TEMP2_READ: J17.2, R51.1; also elsewhere on the board
TX: D16.2 (A2), J19.3; also elsewhere on the board

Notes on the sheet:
Connectors / Sensors
DC Power Connector
Display Connectors

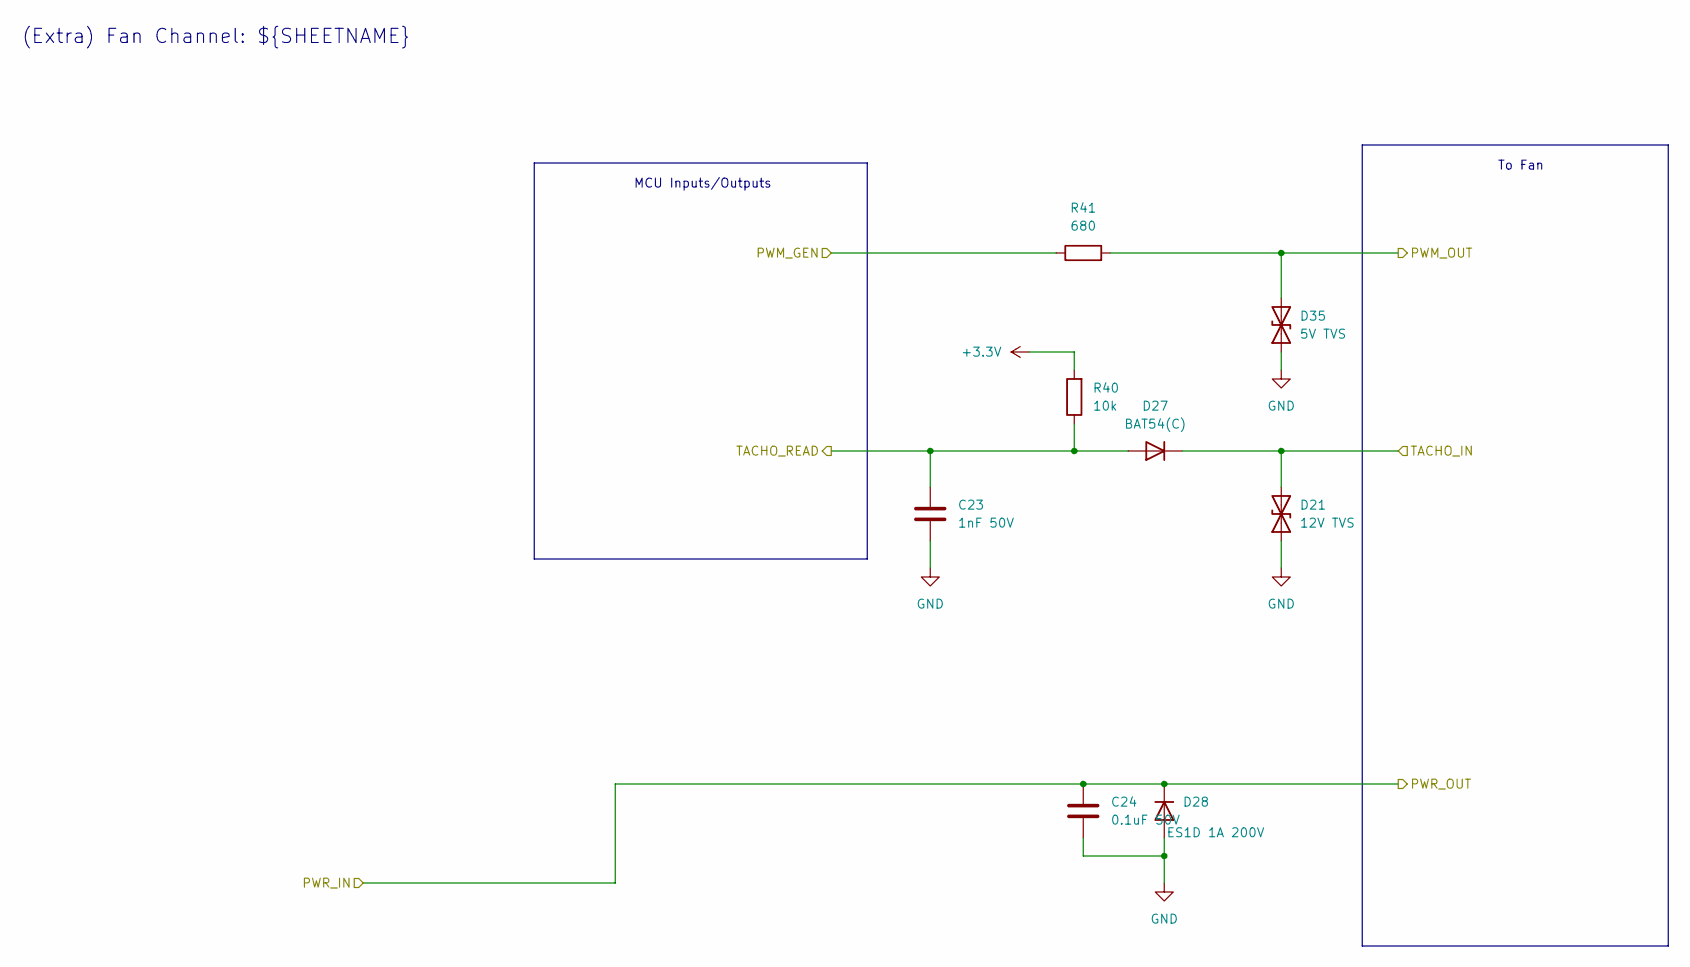
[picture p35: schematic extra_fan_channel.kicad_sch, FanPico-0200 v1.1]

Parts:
C23: 1nF 50V; C_0603_1608Metric_Pad1.08x0.95mm_HandSolder; Manufacturer Part Number CL10B102KB8NNNC; LCSC Part Number C1588
C24: 0.1uF 50V; C_0603_1608Metric_Pad1.08x0.95mm_HandSolder; Manufacturer Part Number CL10B104KB8NNNC; LCSC Part Number C1591
D21: 12V TVS; D_SOD-323_HandSoldering; Manufacturer Part Number UDD32C12L01-ES; LCSC Part Number C5199168
D27: BAT54(C); D_SOT-23_ANK; Mouser Part Number 241-BAT54C_R1_00001; LCSC Part Number C2844172
D28: ES1D 1A 200V; D_SMA_Handsoldering; Mouser Part Number 512-ES1D; LCSC Part Number C445494
D35: 5V TVS; D_SOD-323_HandSoldering; Manufacturer Part Number PESD5V0S1BA-ES; LCSC Part Number C5180216
R40: 10k; R_0603_1608Metric_Pad0.98x0.95mm_HandSolder; Manufacturer Part Number RC0603FR-0710KL; LCSC Part Number C98220
R41: 680; R_0603_1608Metric_Pad0.98x0.95mm_HandSolder; Manufacturer Part Number RC0603JR-07680RL; LCSC Part Number C115415

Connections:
3V3: R40.2; also elsewhere on the board
/Fan Channels/Fan1/PWM_OUT: D35.2 (A2), R41.2; also elsewhere on the board
/Fan Channels/Fan1/TACHO_IN: D21.2 (A2), D27.1 (K); also elsewhere on the board
FAN1_PWM_GEN: R41.1; also elsewhere on the board
FAN1_TACHO_READ: C23.1, D27.2 (A), R40.1; also elsewhere on the board
GND: C23.2, C24.2, D21.1 (A1), D28.2 (A), D35.1 (A1); also elsewhere on the board
MAIN_PWR: C24.1, D28.1 (K); also elsewhere on the board

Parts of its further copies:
C25: 1nF 50V; C_0603_1608Metric_Pad1.08x0.95mm_HandSolder; Manufacturer Part Number CL10B102KB8NNNC; LCSC Part Number C1588
C26: 0.1uF 50V; C_0603_1608Metric_Pad1.08x0.95mm_HandSolder; Manufacturer Part Number CL10B104KB8NNNC; LCSC Part Number C1591
D22: 12V TVS; D_SOD-323_HandSoldering; Manufacturer Part Number UDD32C12L01-ES; LCSC Part Number C5199168
D30: BAT54(C); D_SOT-23_ANK; Mouser Part Number 241-BAT54C_R1_00001; LCSC Part Number C2844172
D31: ES1D 1A 200V; D_SMA_Handsoldering; Mouser Part Number 512-ES1D; LCSC Part Number C445494
D36: 5V TVS; D_SOD-323_HandSoldering; Manufacturer Part Number PESD5V0S1BA-ES; LCSC Part Number C5180216
R43: 10k; R_0603_1608Metric_Pad0.98x0.95mm_HandSolder; Manufacturer Part Number RC0603FR-0710KL; LCSC Part Number C98220
R44: 680; R_0603_1608Metric_Pad0.98x0.95mm_HandSolder; Manufacturer Part Number RC0603JR-07680RL; LCSC Part Number C115415

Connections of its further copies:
3V3: R43.2; also elsewhere on the board
/Fan Channels/Fan2/PWM_OUT: D36.2 (A2), R44.2; also elsewhere on the board
/Fan Channels/Fan2/TACHO_IN: D22.2 (A2), D30.1 (K); also elsewhere on the board
FAN2_PWM_GEN: R44.1; also elsewhere on the board
FAN2_TACHO_READ: C25.1, D30.2 (A), R43.1; also elsewhere on the board
GND: C25.2, C26.2, D22.1 (A1), D31.2 (A), D36.1 (A1); also elsewhere on the board
MAIN_PWR: C26.1, D31.1 (K); also elsewhere on the board

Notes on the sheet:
MCU Inputs/Outputs
(Extra) Fan Channel: ${SHEETNAME}
To Fan

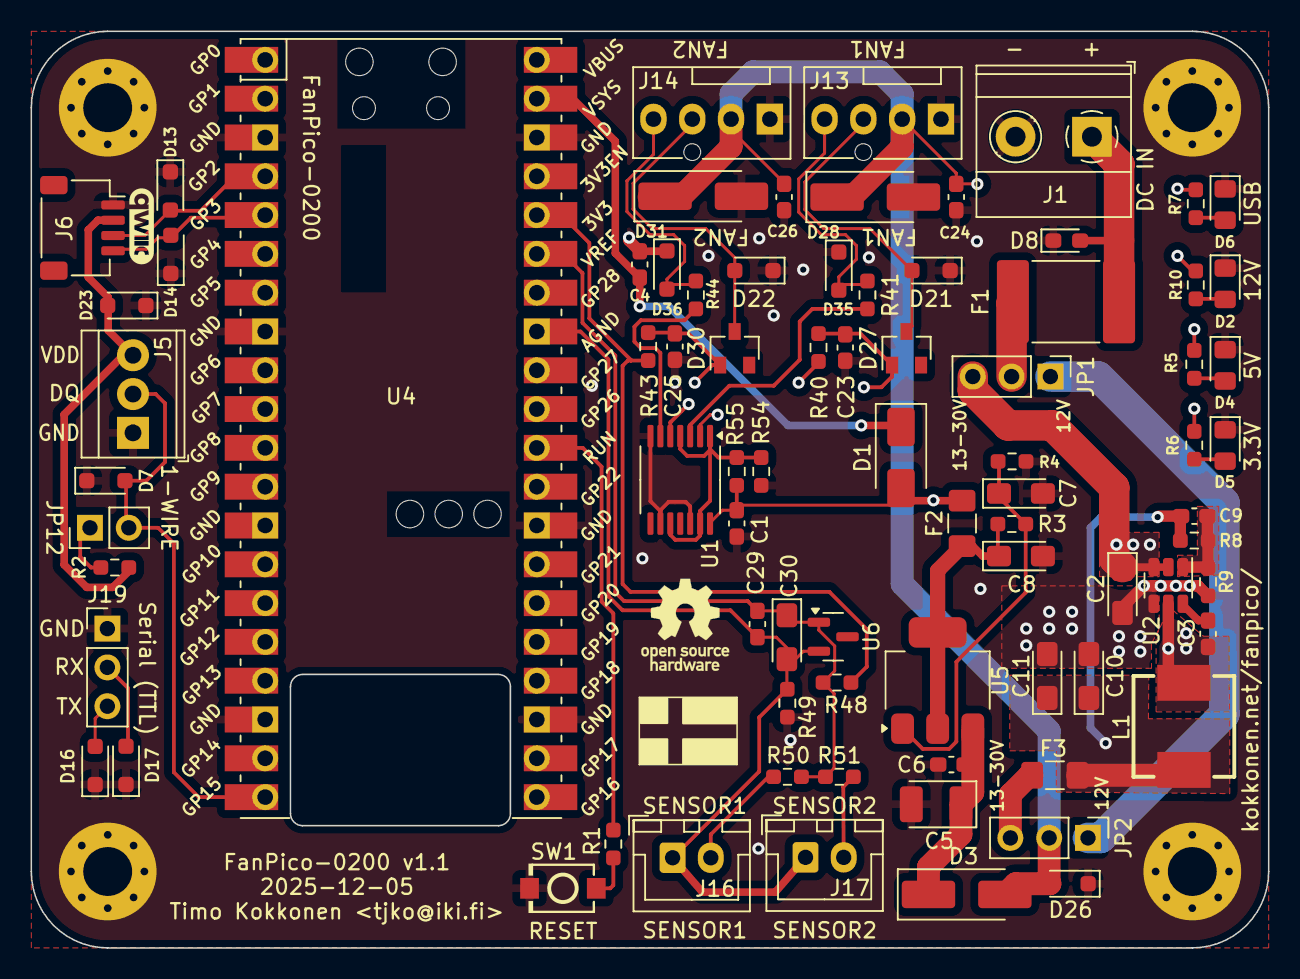
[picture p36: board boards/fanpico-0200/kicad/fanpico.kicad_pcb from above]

Board: 4 copper layers, 81.0 x 60.0 mm, 86 parts (0 on the bottom side), 45 nets.

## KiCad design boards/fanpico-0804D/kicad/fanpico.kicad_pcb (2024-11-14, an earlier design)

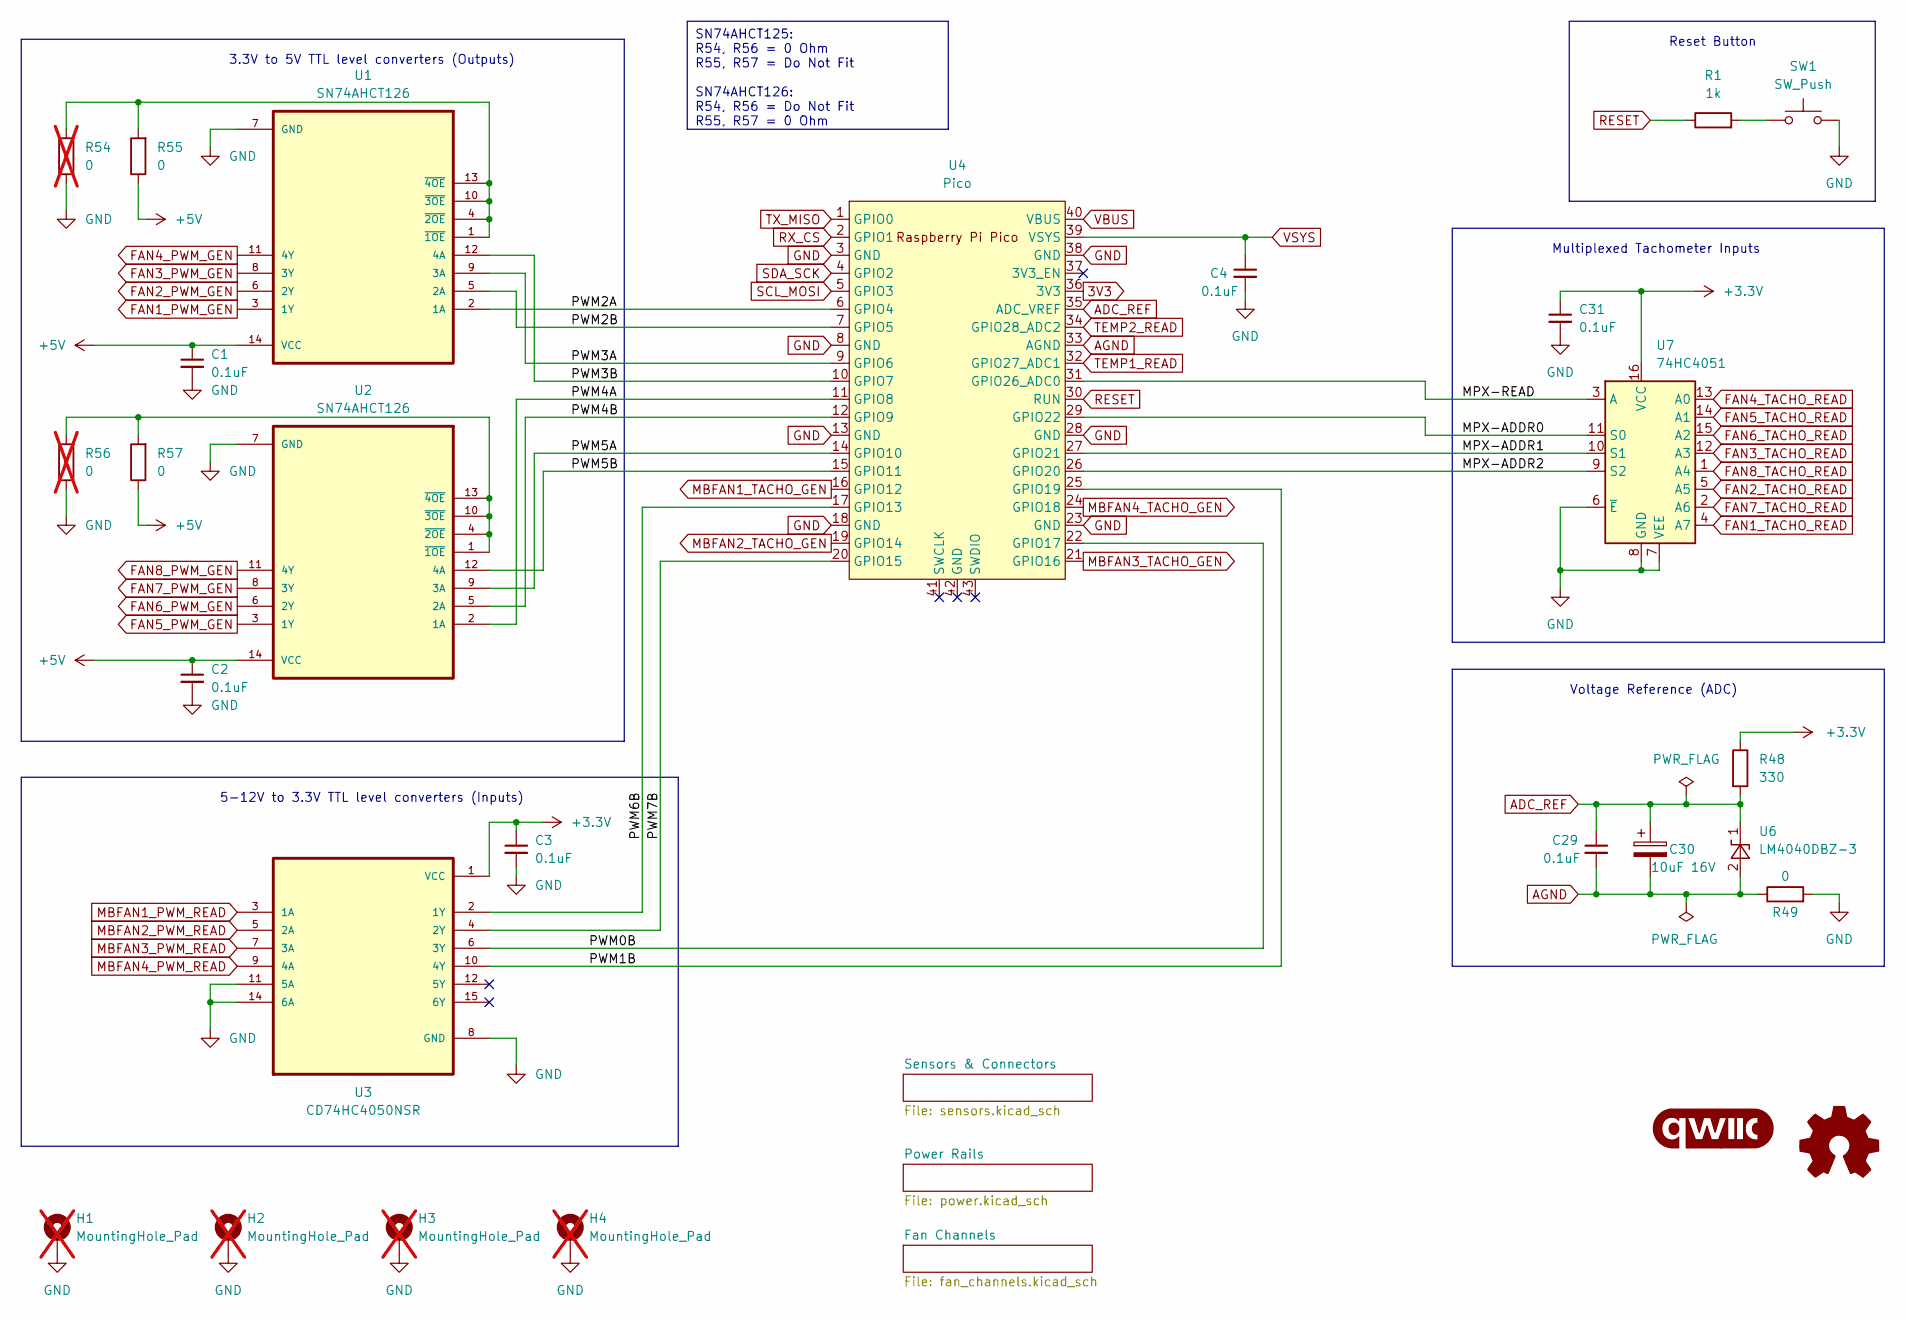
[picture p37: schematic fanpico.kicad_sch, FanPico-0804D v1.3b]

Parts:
C1, C2, C3, C4, C29, C31: 0.1uF; C_0603_1608Metric_Pad1.08x0.95mm_HandSolder; LCSC Part Number C1591
C30: 10uF 16V; CP_EIA-3216-18_Kemet-A_Pad1.58x1.35mm_HandSolder; LCSC Part Number C7171
G1: qwiic_Logo; qwiic_5mm
H1, H2, H3, H4: MountingHole_Pad; MountingHole_3.2mm_M3_Pad_Via; not fitted
R1: 1k; R_0603_1608Metric_Pad0.98x0.95mm_HandSolder; LCSC Part Number C22548
R48: 330; R_0603_1608Metric_Pad0.98x0.95mm_HandSolder; LCSC Part Number C105881
R49, R55, R57: 0; R_0603_1608Metric_Pad0.98x0.95mm_HandSolder; LCSC Part Number C21189
R54, R56: 0; R_0603_1608Metric_Pad0.98x0.95mm_HandSolder; LCSC Part Number C21189; not fitted
SW1: SW_Push; SW_PUSH_6mm_SMD_2; LCSC Part Number C221880
U1, U2: SN74AHCT126; SOIC-14_3.9x8.7mm_P1.27mm; LCSC Part Number C163728
U3: CD74HC4050NSR; SOIC-16_3.9x9.9mm_P1.27mm; LCSC Part Number C131932
U4: Pico; RPi_Pico_PicoW_SMD_TH
U6: LM4040DBZ-3; SOT-23; LCSC Part Number C143326
U7: 74HC4051; SOIC-16_3.9x9.9mm_P1.27mm; LCSC Part Number C9386

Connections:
3V3: C3.1, C31.1, R48.1, U3.1 (VCC), U4.36 (3V3), U7.16 (VCC); also elsewhere on the board
+5V: C1.1, C2.1, R55.1, R57.1, U1.14 (VCC), U2.14 (VCC); also elsewhere on the board
/MPX-ADDR0: U4.29 (GPIO22), U7.11 (S0)
/MPX-ADDR1: U4.27 (GPIO21), U7.10 (S1)
/MPX-ADDR2: U4.26 (GPIO20), U7.9 (S2)
/MPX-READ: U4.31 (GPIO26_ADC0), U7.3 (A)
/PWM0B: U3.6 (3Y), U4.22 (GPIO17)
/PWM1B: U3.10 (4Y), U4.25 (GPIO19)
/PWM2A: U1.2 (1A), U4.6 (GPIO4)
/PWM2B: U1.5 (2A), U4.7 (GPIO5)
/PWM3A: U1.9 (3A), U4.9 (GPIO6)
/PWM3B: U1.12 (4A), U4.10 (GPIO7)
/PWM4A: U2.2 (1A), U4.11 (GPIO8)
/PWM4B: U2.5 (2A), U4.12 (GPIO9)
/PWM5A: U2.9 (3A), U4.14 (GPIO10)
/PWM5B: U2.12 (4A), U4.15 (GPIO11)
/PWM6B: U3.2 (1Y), U4.17 (GPIO13)
/PWM7B: U3.4 (2Y), U4.20 (GPIO15)
ADC_REF: C29.1, C30.1, R48.2, U4.35 (ADC_VREF), U6.1 (K); also elsewhere on the board
AGND: C29.2, C30.2, R49.1, U4.33 (AGND), U6.2 (A); also elsewhere on the board
FAN1_PWM_GEN: U1.3 (1Y); also elsewhere on the board
FAN1_TACHO_READ: U7.4 (A7); also elsewhere on the board
FAN2_PWM_GEN: U1.6 (2Y); also elsewhere on the board
FAN2_TACHO_READ: U7.5 (A5); also elsewhere on the board
FAN3_PWM_GEN: U1.8 (3Y); also elsewhere on the board
FAN3_TACHO_READ: U7.12 (A3); also elsewhere on the board
FAN4_PWM_GEN: U1.11 (4Y); also elsewhere on the board
FAN4_TACHO_READ: U7.13 (A0); also elsewhere on the board
FAN5_PWM_GEN: U2.3 (1Y); also elsewhere on the board
FAN5_TACHO_READ: U7.14 (A1); also elsewhere on the board
FAN6_PWM_GEN: U2.6 (2Y); also elsewhere on the board
FAN6_TACHO_READ: U7.15 (A2); also elsewhere on the board
FAN7_PWM_GEN: U2.8 (3Y); also elsewhere on the board
FAN7_TACHO_READ: U7.2 (A6); also elsewhere on the board
FAN8_PWM_GEN: U2.11 (4Y); also elsewhere on the board
FAN8_TACHO_READ: U7.1 (A4); also elsewhere on the board
GND: C1.2, C2.2, C3.2, C4.2, C31.2, H1.1, H2.1, H3.1, H4.1, R49.2, R54.1, R56.1, SW1.2, U1.7 (GND), U2.7 (GND), U3.8 (GND), U3.11 (5A), U3.14 (6A), U4.3 (GND), U4.8 (GND), U4.13 (GND), U4.18 (GND), U4.23 (GND), U4.28 (GND), U4.38 (GND), U7.6 (~E), U7.7 (VEE), U7.8 (GND); also elsewhere on the board
MBFAN1_PWM_READ: U3.3 (1A); also elsewhere on the board
MBFAN1_TACHO_GEN: U4.16 (GPIO12); also elsewhere on the board
MBFAN2_PWM_READ: U3.5 (2A); also elsewhere on the board
MBFAN2_TACHO_GEN: U4.19 (GPIO14); also elsewhere on the board
MBFAN3_PWM_READ: U3.7 (3A); also elsewhere on the board
MBFAN3_TACHO_GEN: U4.21 (GPIO16); also elsewhere on the board
MBFAN4_PWM_READ: U3.9 (4A); also elsewhere on the board
MBFAN4_TACHO_GEN: U4.24 (GPIO18); also elsewhere on the board
unnamed: R1.2, SW1.1
unnamed: R54.2, R55.2, U1.1 (~1OE), U1.4 (~2OE), U1.10 (~3OE), U1.13 (~4OE)
unnamed: R56.2, R57.2, U2.1 (~1OE), U2.4 (~2OE), U2.10 (~3OE), U2.13 (~4OE)
RESET: R1.1, U4.30 (RUN)
RX_CS: U4.2 (GPIO1); also elsewhere on the board
SCL_MOSI: U4.5 (GPIO3); also elsewhere on the board
SDA_SCK: U4.4 (GPIO2); also elsewhere on the board
TEMP1_READ: U4.32 (GPIO27_ADC1); also elsewhere on the board
TEMP2_READ: U4.34 (GPIO28_ADC2); also elsewhere on the board
TX_MISO: U4.1 (GPIO0); also elsewhere on the board
VBUS: U4.40 (VBUS); also elsewhere on the board
VSYS: C4.1, U4.39 (VSYS); also elsewhere on the board

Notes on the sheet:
SN74AHCT125: R54, R56 = 0 Ohm R55, R57 = Do Not Fit SN74AHCT126: R54, R56 = Do Not Fit R55, R57 = 0 Ohm
Reset Button
3.3V to 5V TTL level converters (Outputs)
Multiplexed Tachometer Inputs
5-12V to 3.3V TTL level converters (Inputs)
Voltage Reference (ADC)

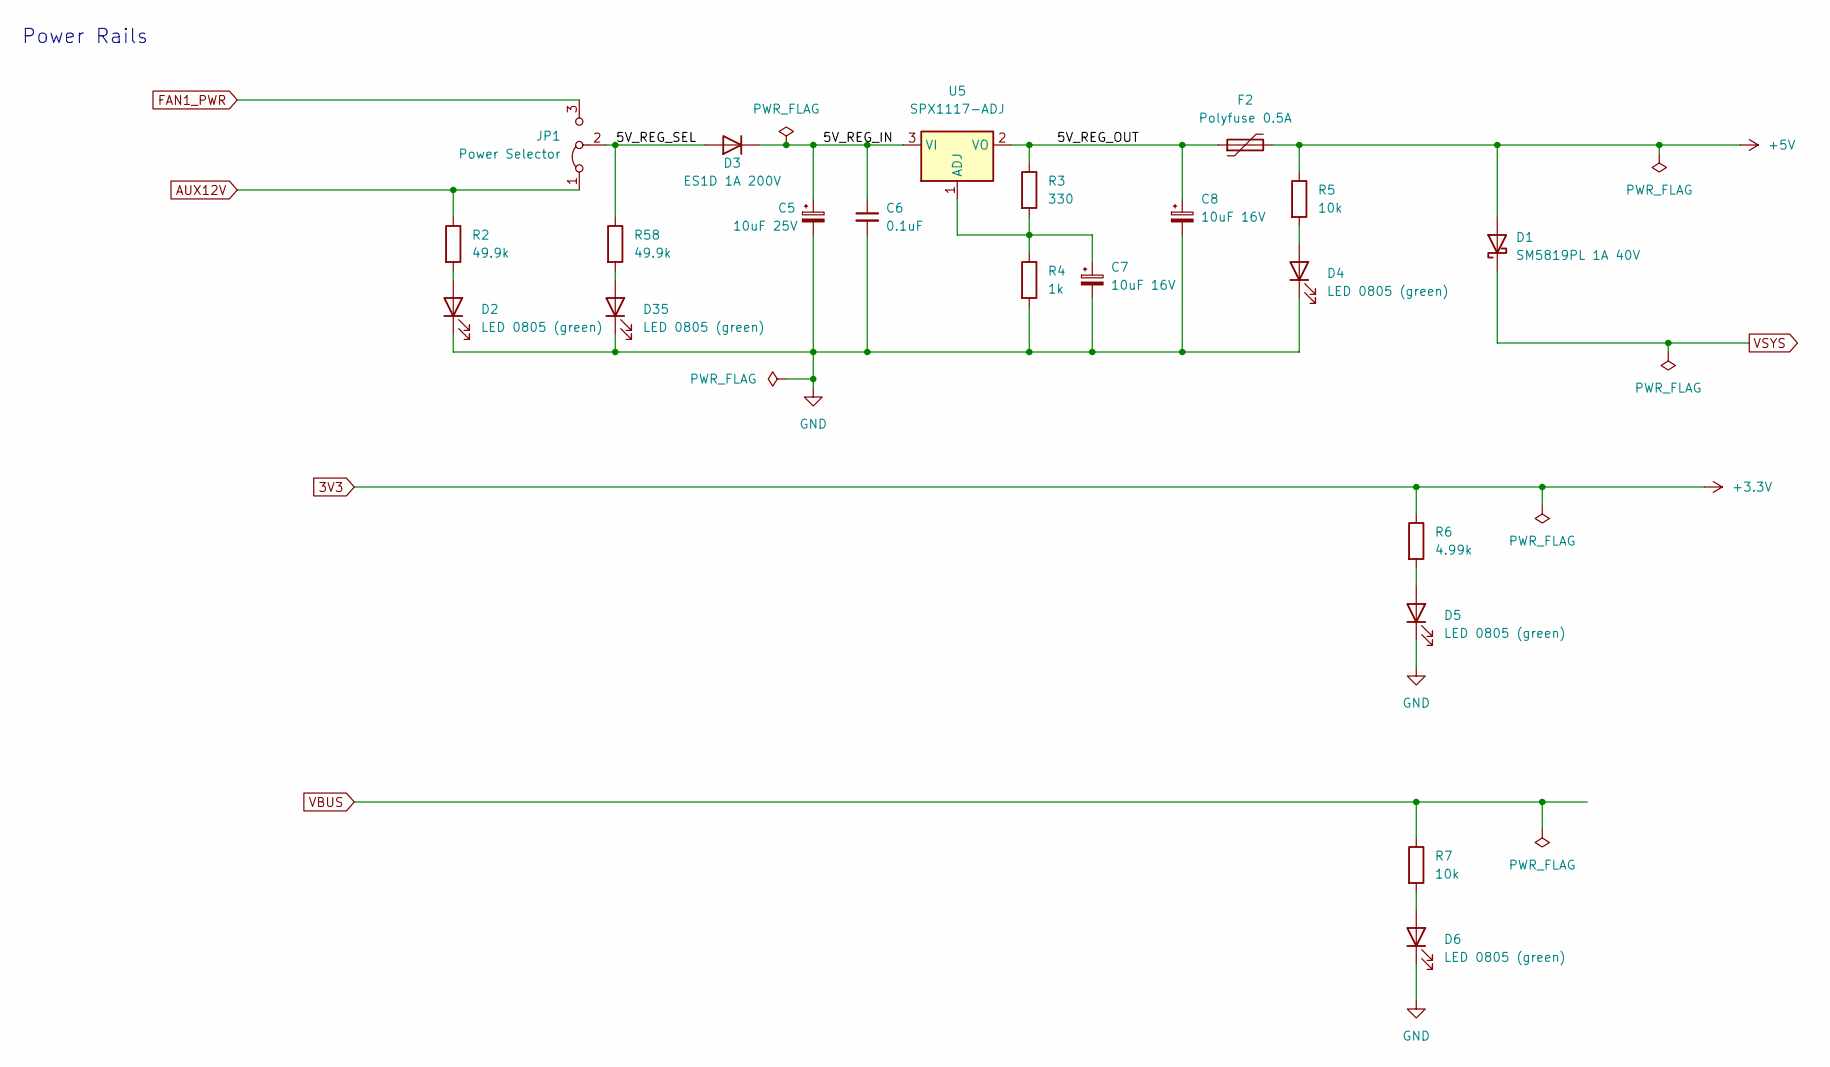
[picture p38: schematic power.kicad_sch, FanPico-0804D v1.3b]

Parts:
C5: 10uF 25V; CP_EIA-3528-12_Kemet-T_Pad1.50x2.35mm_HandSolder; LCSC Part Number C7194
C6: 0.1uF; C_0603_1608Metric_Pad1.08x0.95mm_HandSolder; LCSC Part Number C1591
C7, C8: 10uF 16V; CP_EIA-3216-18_Kemet-A_Pad1.58x1.35mm_HandSolder; LCSC Part Number C7171
D1: SM5819PL 1A 40V; D_SMA; LCSC Part Number C669023 or C19992592
D2, D4, D5, D6, D35: LED 0805 (green); LED_0805_2012Metric_Pad1.15x1.40mm_HandSolder; LCSC Part Number C434432
D3: ES1D 1A 200V; D_SMA_Handsoldering; LCSC Part Number C445494
F2: Polyfuse 0.5A; Fuse_1206_3216Metric_Pad1.42x1.75mm_HandSolder; LCSC Part Number C70072
JP1: Power Selector; PinHeader_1x03_P2.54mm_Vertical
R2, R58: 49.9k; R_0603_1608Metric_Pad0.98x0.95mm_HandSolder; LCSC Part Number C114624
R3: 330; R_0603_1608Metric_Pad0.98x0.95mm_HandSolder; LCSC Part Number C105881
R4: 1k; R_0603_1608Metric_Pad0.98x0.95mm_HandSolder; LCSC Part Number C22548
R5, R7: 10k; R_0603_1608Metric_Pad0.98x0.95mm_HandSolder; LCSC Part Number C98220
R6: 4.99k; R_0603_1608Metric_Pad0.98x0.95mm_HandSolder; LCSC Part Number C114621
U5: SPX1117-ADJ; SOT-223-3_TabPin2; LCSC Part Number C67402

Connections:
3V3: R6.1; also elsewhere on the board
+5V: D1.2 (A), F2.2, R5.1; also elsewhere on the board
/Power Rails/5V_REG_IN: C5.1, C6.1, D3.1 (K), U5.3 (VI)
/Power Rails/5V_REG_OUT: C8.1, F2.1, R3.1, U5.2 (VO)
/Power Rails/5V_REG_SEL: D3.2 (A), JP1.2 (C), R58.1
AUX12V: JP1.1 (A), R2.1; also elsewhere on the board
FAN1_PWR: JP1.3 (B); also elsewhere on the board
GND: C5.2, C6.2, C7.2, C8.2, D2.1 (K), D4.1 (K), D5.1 (K), D6.1 (K), D35.1 (K), R4.2; also elsewhere on the board
unnamed: D2.2 (A), R2.2
unnamed: D4.2 (A), R5.2
unnamed: D5.2 (A), R6.2
unnamed: D6.2 (A), R7.2
unnamed: D35.2 (A), R58.2
unnamed: C7.1, R3.2, R4.1, U5.1 (ADJ)
VBUS: R7.1; also elsewhere on the board
VSYS: D1.1 (K); also elsewhere on the board

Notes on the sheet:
Power Rails

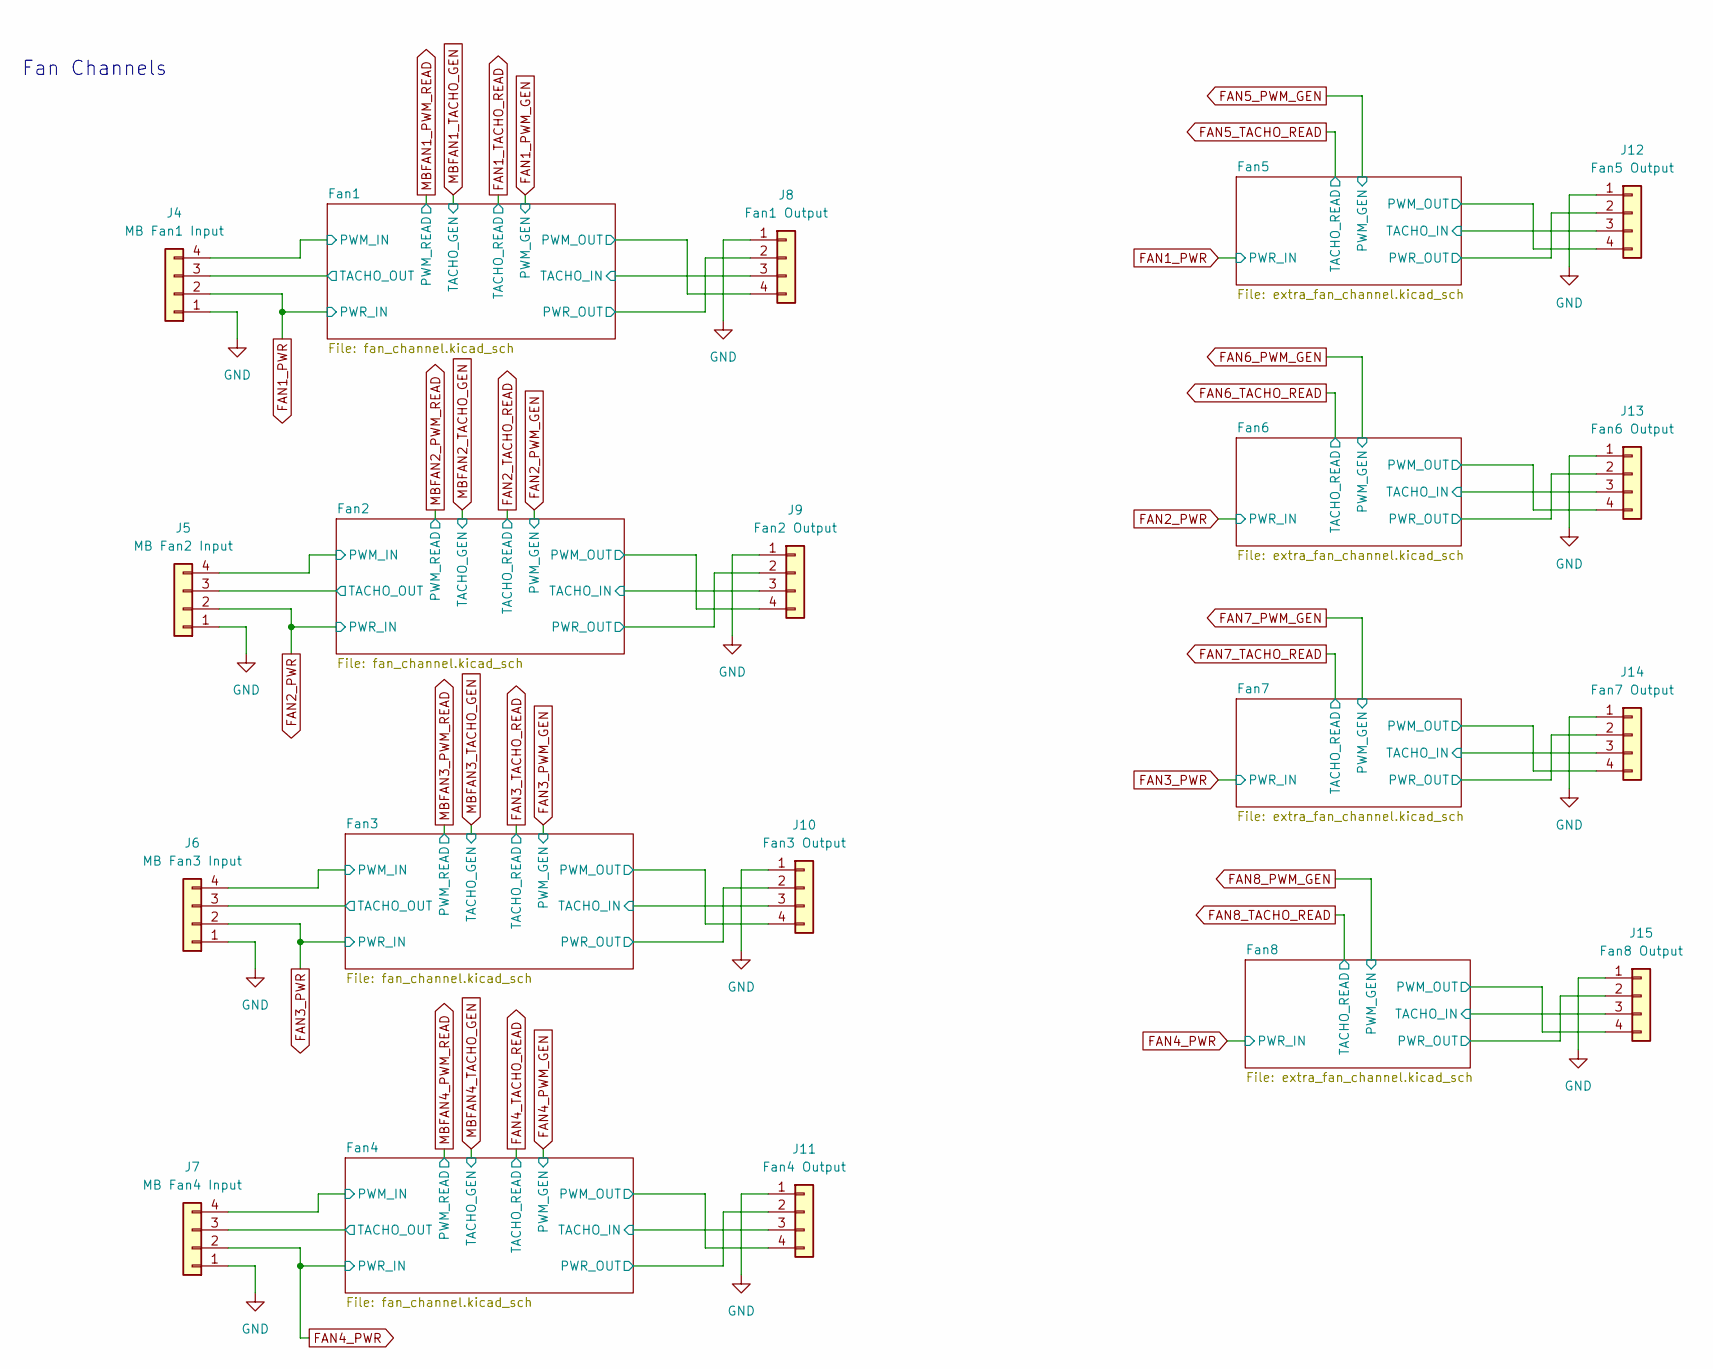
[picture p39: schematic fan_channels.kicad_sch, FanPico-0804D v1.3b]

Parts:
J4: MB Fan1 Input; FanPinHeader_1x04_P2.54mm_Vertical
J5: MB Fan2 Input; FanPinHeader_1x04_P2.54mm_Vertical
J6: MB Fan3 Input; FanPinHeader_1x04_P2.54mm_Vertical
J7: MB Fan4 Input; FanPinHeader_1x04_P2.54mm_Vertical
J8: Fan1 Output; FanPinHeader_1x04_P2.54mm_Vertical
J9: Fan2 Output; FanPinHeader_1x04_P2.54mm_Vertical
J10: Fan3 Output; FanPinHeader_1x04_P2.54mm_Vertical
J11: Fan4 Output; FanPinHeader_1x04_P2.54mm_Vertical
J12: Fan5 Output; FanPinHeader_1x04_P2.54mm_Vertical
J13: Fan6 Output; FanPinHeader_1x04_P2.54mm_Vertical
J14: Fan7 Output; FanPinHeader_1x04_P2.54mm_Vertical
J15: Fan8 Output; FanPinHeader_1x04_P2.54mm_Vertical

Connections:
/Fan Channels/Fan1/PWM_IN: J4.4; also elsewhere on the board
/Fan Channels/Fan1/PWM_OUT: J8.4; also elsewhere on the board
/Fan Channels/Fan1/PWR_OUT: J8.2; also elsewhere on the board
/Fan Channels/Fan1/TACHO_IN: J8.3; also elsewhere on the board
/Fan Channels/Fan1/TACHO_OUT: J4.3; also elsewhere on the board
/Fan Channels/Fan2/PWM_IN: J5.4; also elsewhere on the board
/Fan Channels/Fan2/PWM_OUT: J9.4; also elsewhere on the board
/Fan Channels/Fan2/PWR_OUT: J9.2; also elsewhere on the board
/Fan Channels/Fan2/TACHO_IN: J9.3; also elsewhere on the board
/Fan Channels/Fan2/TACHO_OUT: J5.3; also elsewhere on the board
/Fan Channels/Fan3/PWM_IN: J6.4; also elsewhere on the board
/Fan Channels/Fan3/PWM_OUT: J10.4; also elsewhere on the board
/Fan Channels/Fan3/PWR_OUT: J10.2; also elsewhere on the board
/Fan Channels/Fan3/TACHO_IN: J10.3; also elsewhere on the board
/Fan Channels/Fan3/TACHO_OUT: J6.3; also elsewhere on the board
/Fan Channels/Fan4/PWM_IN: J7.4; also elsewhere on the board
/Fan Channels/Fan4/PWM_OUT: J11.4; also elsewhere on the board
/Fan Channels/Fan4/PWR_OUT: J11.2; also elsewhere on the board
/Fan Channels/Fan4/TACHO_IN: J11.3; also elsewhere on the board
/Fan Channels/Fan4/TACHO_OUT: J7.3; also elsewhere on the board
/Fan Channels/Fan5/PWM_OUT: J12.4; also elsewhere on the board
/Fan Channels/Fan5/PWR_OUT: J12.2; also elsewhere on the board
/Fan Channels/Fan5/TACHO_IN: J12.3; also elsewhere on the board
/Fan Channels/Fan6/PWM_OUT: J13.4; also elsewhere on the board
/Fan Channels/Fan6/PWR_OUT: J13.2; also elsewhere on the board
/Fan Channels/Fan6/TACHO_IN: J13.3; also elsewhere on the board
/Fan Channels/Fan7/PWM_OUT: J14.4; also elsewhere on the board
/Fan Channels/Fan7/PWR_OUT: J14.2; also elsewhere on the board
/Fan Channels/Fan7/TACHO_IN: J14.3; also elsewhere on the board
/Fan Channels/Fan8/PWM_OUT: J15.4; also elsewhere on the board
/Fan Channels/Fan8/PWR_OUT: J15.2; also elsewhere on the board
/Fan Channels/Fan8/TACHO_IN: J15.3; also elsewhere on the board
FAN1_PWR: J4.2; also elsewhere on the board
FAN2_PWR: J5.2; also elsewhere on the board
FAN3_PWR: J6.2; also elsewhere on the board
FAN4_PWR: J7.2; also elsewhere on the board
GND: J4.1, J5.1, J6.1, J7.1, J8.1, J9.1, J10.1, J11.1, J12.1, J13.1, J14.1, J15.1; also elsewhere on the board

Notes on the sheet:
Fan Channels

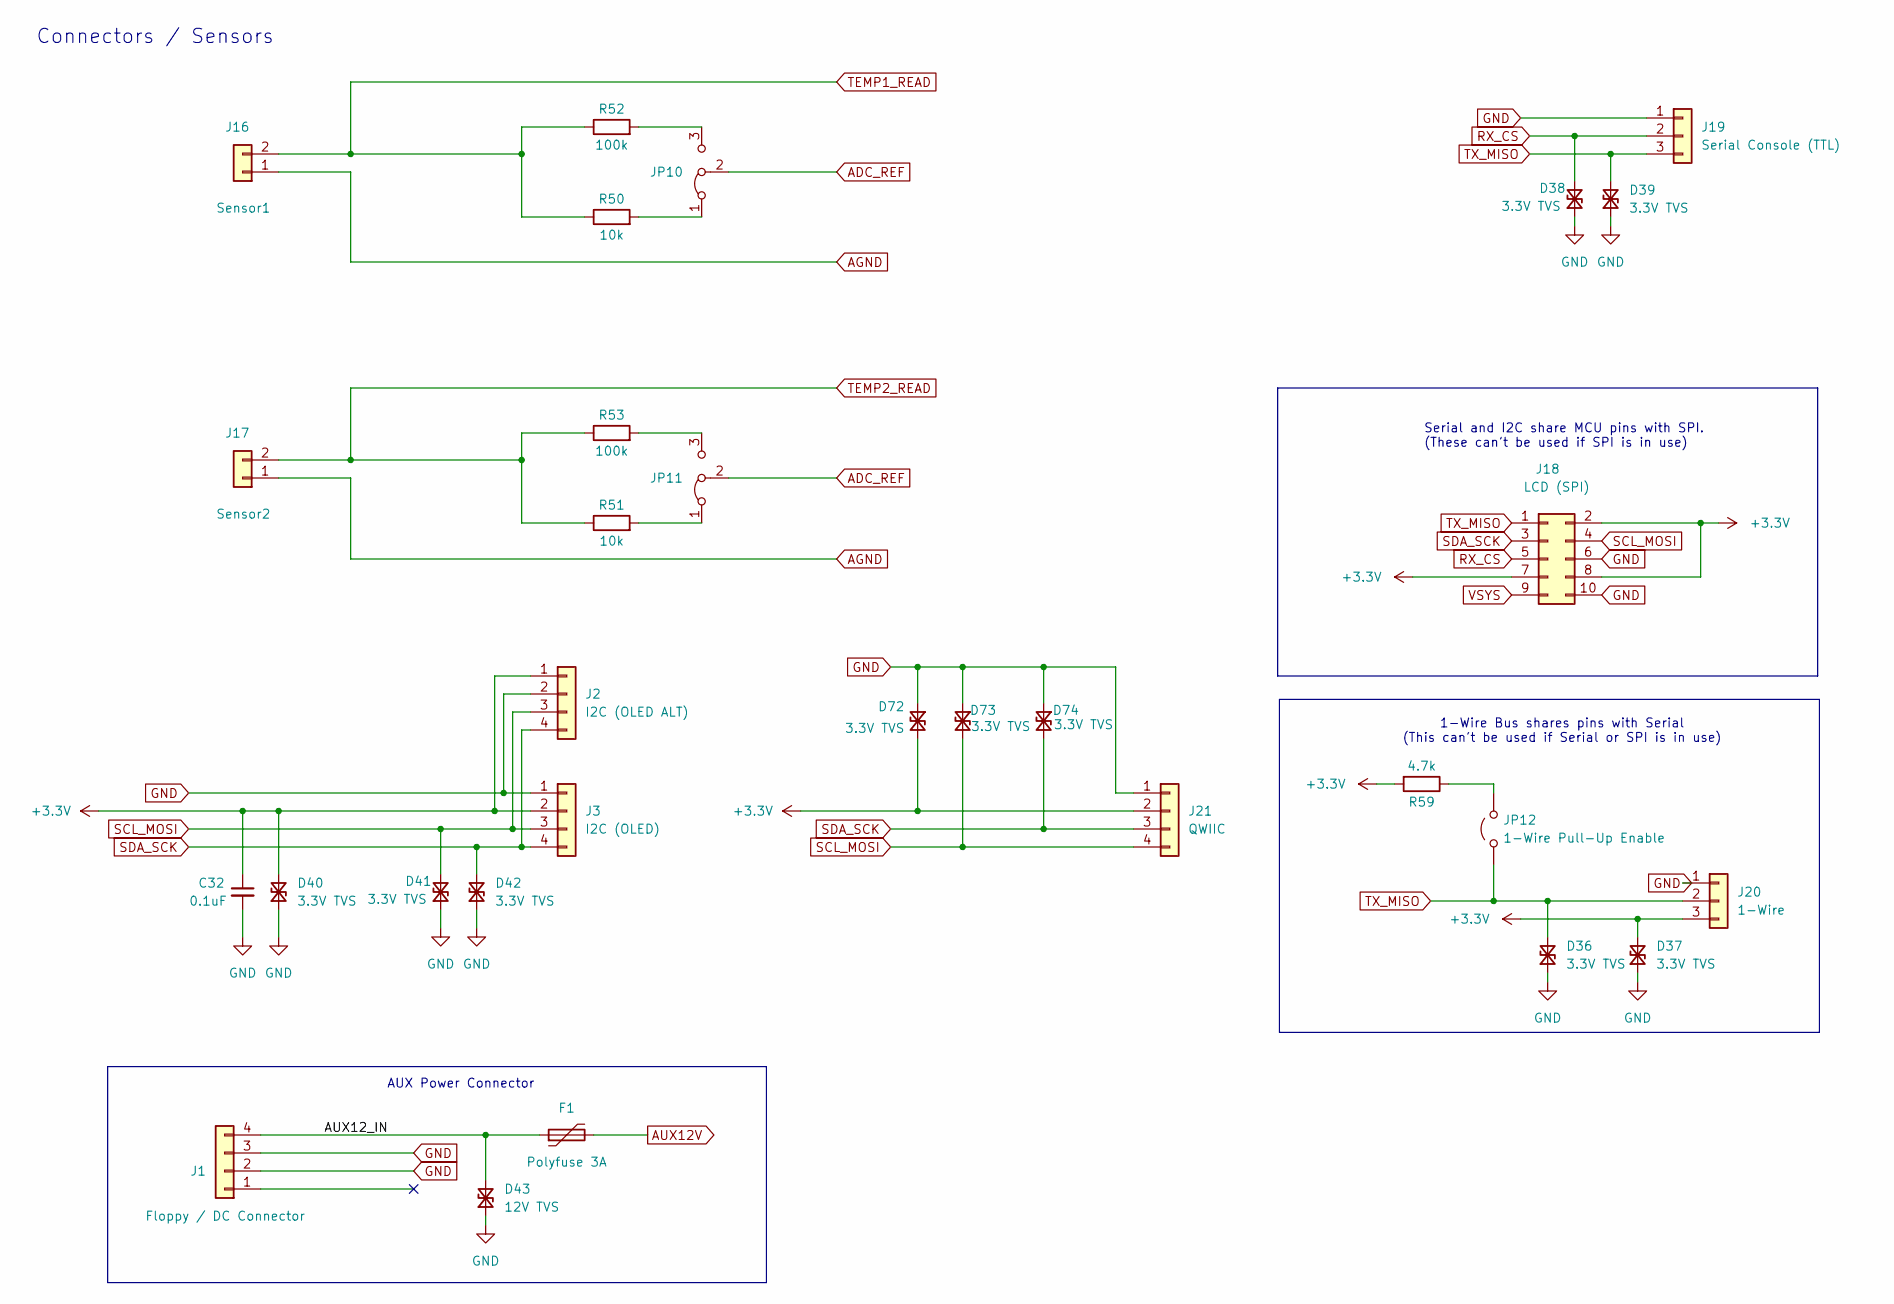
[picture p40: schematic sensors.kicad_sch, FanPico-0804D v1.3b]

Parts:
C32: 0.1uF; C_0603_1608Metric_Pad1.08x0.95mm_HandSolder; LCSC Part Number C1591
D36, D37, D38, D39, D40, D41, D42, D72, D73, D74: 3.3V TVS; D_SOD-323_HandSoldering; LCSC Part Number C78439
D43: 12V TVS; D_SOD-323_HandSoldering; LCSC Part Number C502541 or C5199168
F1: Polyfuse 3A; Fuse_2920_7451Metric_Pad2.10x5.45mm_HandSolder; LCSC Part Number C2977527
J1: Floppy / DC Connector; TE 171826-4 Floppy 4-pin Combo; LCSC Part Number C590635 / C720558
J2: I2C (OLED ALT); PinSocket_1x04_P2.54mm_Vertical
J3: I2C (OLED); PinSocket_1x04_P2.54mm_Vertical
J16: Sensor1; JST_XH_B2B-XH-A_1x02_P2.50mm_Vertical
J17: Sensor2; JST_XH_B2B-XH-A_1x02_P2.50mm_Vertical
J18: LCD (SPI); PinHeader_2x05_P2.54mm_Vertical
J19: Serial Console (TTL); PinHeader_1x03_P2.54mm_Vertical
J20: 1-Wire; TerminalBlock_TE_282834-3_1x03_P2.54mm_Horizontal; LCSC Part Number C68305 or C5188443
J21: QWIIC; JST_SH_SM04B-SRSS-TB_1x04-1MP_P1.00mm_Horizontal; LCSC Part Number C160404
JP10, JP11: NTC Value; PinHeader_1x03_P2.54mm_Vertical
JP12: 1-Wire Pull-Up Enable; PinHeader_1x02_P2.54mm_Vertical
R50, R51: 10k; R_0603_1608Metric_Pad0.98x0.95mm_HandSolder; LCSC Part Number C98220
R52, R53: 100k; R_0603_1608Metric_Pad0.98x0.95mm_HandSolder; LCSC Part Number C14675
R59: 4.7k; R_0603_1608Metric_Pad0.98x0.95mm_HandSolder; LCSC Part Number C99782

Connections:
3V3: C32.1, D37.2 (A2), D40.2 (A2), D72.2 (A2), J2.1, J3.2, J18.2, J18.7, J18.8, J20.3, J21.2, R59.2; also elsewhere on the board
/Sensors & Connectors/AUX12_IN: D43.2 (A2), F1.1, J1.4
ADC_REF: JP10.2 (C), JP11.2 (C); also elsewhere on the board
AGND: J16.1, J17.1; also elsewhere on the board
AUX12V: F1.2; also elsewhere on the board
GND: C32.2, D36.1 (A1), D37.1 (A1), D38.1 (A1), D39.1 (A1), D40.1 (A1), D41.1 (A1), D42.1 (A1), D43.1 (A1), D72.1 (A1), D73.1 (A1), D74.1 (A1), J1.2, J1.3, J2.2, J3.1, J18.6, J18.10, J19.1, J20.1, J21.1; also elsewhere on the board
unnamed: JP10.1 (A), R50.2
unnamed: JP10.3 (B), R52.2
unnamed: JP11.1 (A), R51.2
unnamed: JP11.3 (B), R53.2
unnamed: JP12.2 (B), R59.1
RX_CS: D38.2 (A2), J18.5, J19.2; also elsewhere on the board
SCL_MOSI: D41.2 (A2), D73.2 (A2), J2.3, J3.3, J18.4, J21.4; also elsewhere on the board
SDA_SCK: D42.2 (A2), D74.2 (A2), J2.4, J3.4, J18.3, J21.3; also elsewhere on the board
TEMP1_READ: J16.2, R50.1, R52.1; also elsewhere on the board
TEMP2_READ: J17.2, R51.1, R53.1; also elsewhere on the board
TX_MISO: D36.2 (A2), D39.2 (A2), J18.1, J19.3, J20.2, JP12.1 (A); also elsewhere on the board
VSYS: J18.9; also elsewhere on the board

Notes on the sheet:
Connectors / Sensors
AUX Power Connector
1-Wire Bus shares pins with Serial (This can't be used if Serial or SPI is in use)
Serial and I2C share MCU pins with SPI. (These can't be used if SPI is in use)

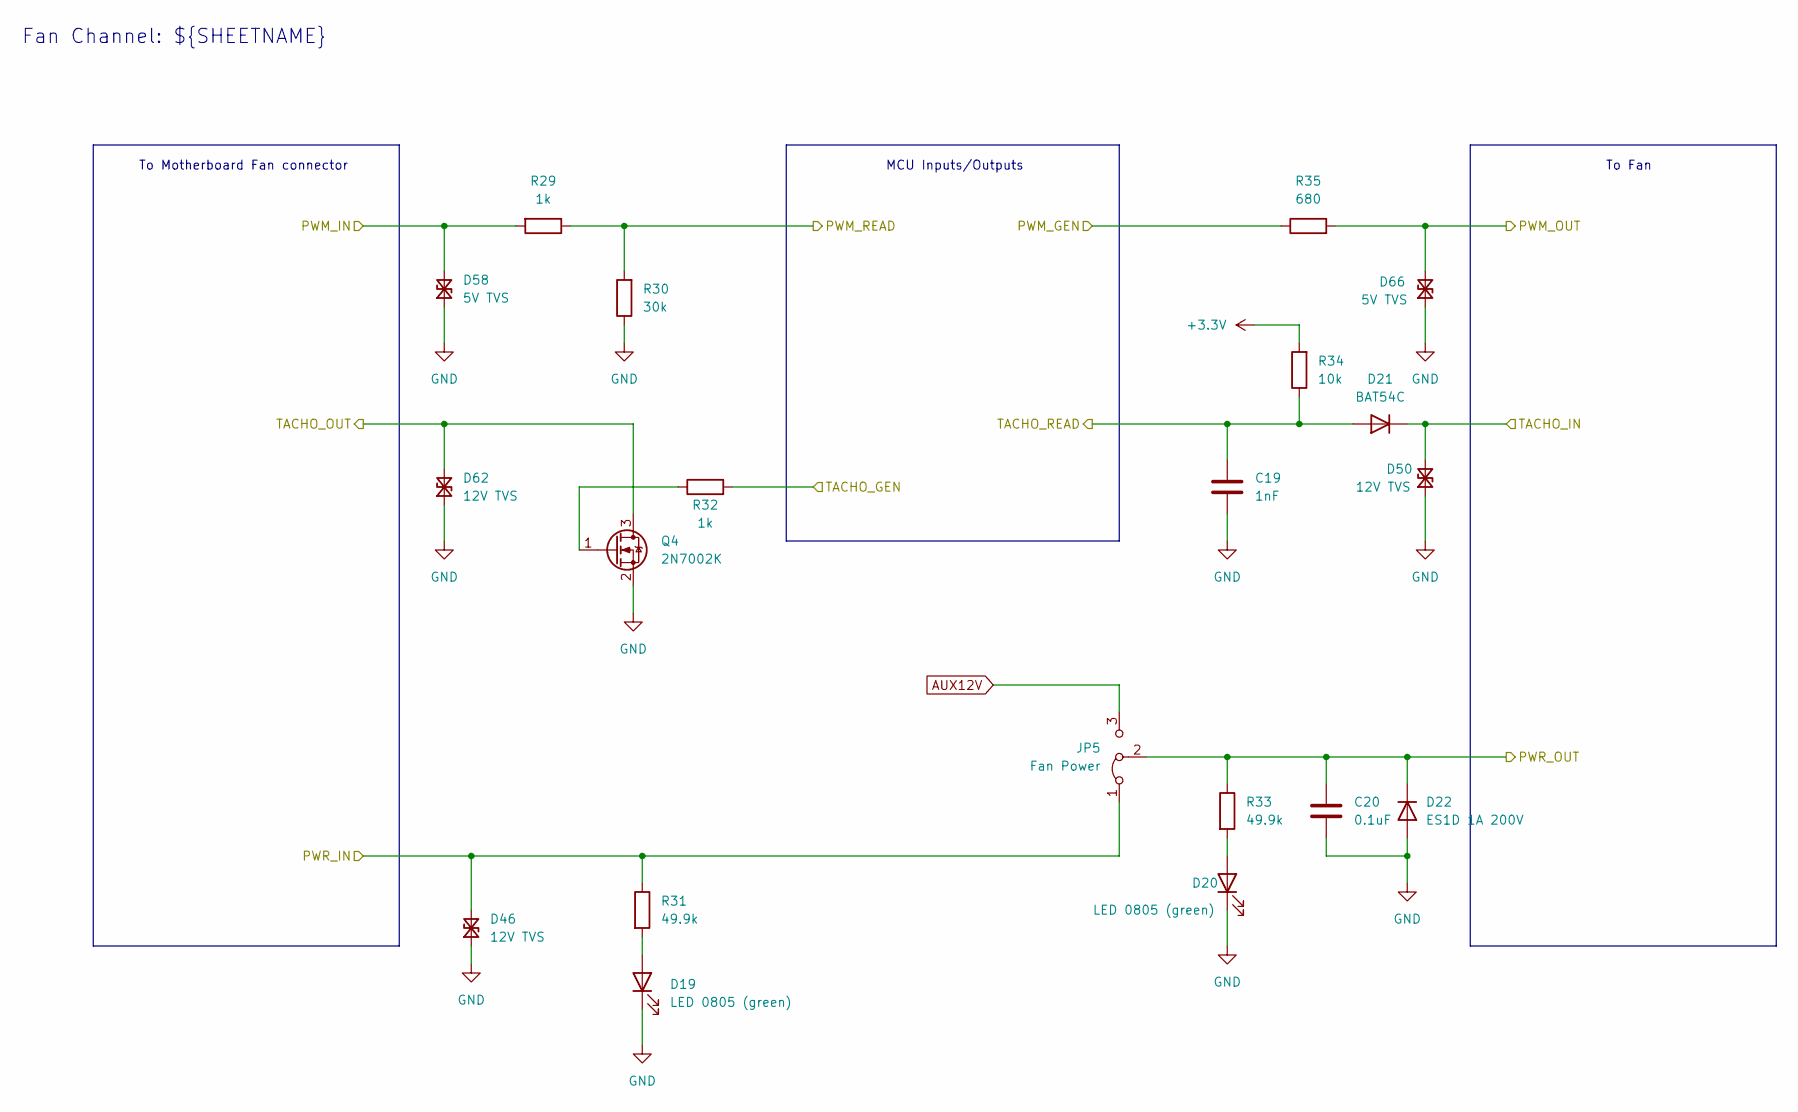
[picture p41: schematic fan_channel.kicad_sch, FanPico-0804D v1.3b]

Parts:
C19: 1nF; C_0603_1608Metric_Pad1.08x0.95mm_HandSolder; LCSC Part Number C1588
C20: 0.1uF; C_0603_1608Metric_Pad1.08x0.95mm_HandSolder; LCSC Part Number C1591
D19, D20: LED 0805 (green); LED_0805_2012Metric_Pad1.15x1.40mm_HandSolder; LCSC Part Number C434432
D21: BAT54C; D_SOT-23_ANK; LCSC Part Number C2844172
D22: ES1D 1A 200V; D_SMA_Handsoldering; LCSC Part Number C445494
D46, D50, D62: 12V TVS; D_SOD-323_HandSoldering; LCSC Part Number C502541 or C5199168
D58, D66: 5V TVS; D_SOD-323_HandSoldering; LCSC Part Number C5180216
JP5: Fan Power; PinHeader_1x03_P2.54mm_Vertical
Q4: 2N7002K; SOT-23; LCSC Part Number C85047
R29, R32: 1k; R_0603_1608Metric_Pad0.98x0.95mm_HandSolder; LCSC Part Number C22548
R30: 30k; R_0603_1608Metric_Pad0.98x0.95mm_HandSolder; LCSC Part Number C100001
R31, R33: 49.9k; R_0603_1608Metric_Pad0.98x0.95mm_HandSolder; LCSC Part Number C114624
R34: 10k; R_0603_1608Metric_Pad0.98x0.95mm_HandSolder; LCSC Part Number C98220
R35: 680; R_0603_1608Metric_Pad0.98x0.95mm_HandSolder; LCSC Part Number C115415

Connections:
3V3: R34.2; also elsewhere on the board
/Fan Channels/Fan3/PWM_IN: D58.2 (A2), R29.2; also elsewhere on the board
/Fan Channels/Fan3/PWM_OUT: D66.2 (A2), R35.2; also elsewhere on the board
/Fan Channels/Fan3/PWR_OUT: C20.1, D22.1 (K), JP5.2 (C), R33.1; also elsewhere on the board
/Fan Channels/Fan3/TACHO_IN: D21.1 (K), D50.2 (A2); also elsewhere on the board
/Fan Channels/Fan3/TACHO_OUT: D62.2 (A2), Q4.3 (D); also elsewhere on the board
AUX12V: JP5.3 (B); also elsewhere on the board
FAN3_PWM_GEN: R35.1; also elsewhere on the board
FAN3_PWR: D46.2 (A2), JP5.1 (A), R31.1; also elsewhere on the board
FAN3_TACHO_READ: C19.1, D21.2 (A), R34.1; also elsewhere on the board
GND: C19.2, C20.2, D19.1 (K), D20.1 (K), D22.2 (A), D46.1 (A1), D50.1 (A1), D58.1 (A1), D62.1 (A1), D66.1 (A1), Q4.2 (S), R30.1; also elsewhere on the board
MBFAN3_PWM_READ: R29.1, R30.2; also elsewhere on the board
MBFAN3_TACHO_GEN: R32.2; also elsewhere on the board
unnamed: D19.2 (A), R31.2
unnamed: D20.2 (A), R33.2
unnamed: Q4.1 (G), R32.1

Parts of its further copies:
C10, C13, C16: 1nF; C_0603_1608Metric_Pad1.08x0.95mm_HandSolder; LCSC Part Number C1588
C11, C14, C17: 0.1uF; C_0603_1608Metric_Pad1.08x0.95mm_HandSolder; LCSC Part Number C1591
D7, D8, D11, D12, D15, D16: LED 0805 (green); LED_0805_2012Metric_Pad1.15x1.40mm_HandSolder; LCSC Part Number C434432
D9, D13, D17: BAT54C; D_SOT-23_ANK; LCSC Part Number C2844172
D10, D14, D18: ES1D 1A 200V; D_SMA_Handsoldering; LCSC Part Number C445494
D44, D45, D47, D48, D49, D51, D60, D61, D63: 12V TVS; D_SOD-323_HandSoldering; LCSC Part Number C502541 or C5199168
D56, D57, D59, D64, D65, D67: 5V TVS; D_SOD-323_HandSoldering; LCSC Part Number C5180216
JP2, JP3, JP4: Fan Power; PinHeader_1x03_P2.54mm_Vertical
Q1, Q2, Q3: 2N7002K; SOT-23; LCSC Part Number C85047
R8, R11, R15, R18, R22, R25: 1k; R_0603_1608Metric_Pad0.98x0.95mm_HandSolder; LCSC Part Number C22548
R9, R16, R23: 30k; R_0603_1608Metric_Pad0.98x0.95mm_HandSolder; LCSC Part Number C100001
R10, R12, R17, R19, R24, R26: 49.9k; R_0603_1608Metric_Pad0.98x0.95mm_HandSolder; LCSC Part Number C114624
R13, R20, R27: 10k; R_0603_1608Metric_Pad0.98x0.95mm_HandSolder; LCSC Part Number C98220
R14, R21, R28: 680; R_0603_1608Metric_Pad0.98x0.95mm_HandSolder; LCSC Part Number C115415

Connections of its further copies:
3V3: R13.2, R20.2, R27.2; also elsewhere on the board
/Fan Channels/Fan1/PWM_IN: D56.2 (A2), R8.2; also elsewhere on the board
/Fan Channels/Fan1/PWM_OUT: D64.2 (A2), R14.2; also elsewhere on the board
/Fan Channels/Fan1/PWR_OUT: C11.1, D10.1 (K), JP2.2 (C), R12.1; also elsewhere on the board
/Fan Channels/Fan1/TACHO_IN: D9.1 (K), D48.2 (A2); also elsewhere on the board
/Fan Channels/Fan1/TACHO_OUT: D60.2 (A2), Q1.3 (D); also elsewhere on the board
/Fan Channels/Fan2/PWM_IN: D57.2 (A2), R15.2; also elsewhere on the board
/Fan Channels/Fan2/PWM_OUT: D65.2 (A2), R21.2; also elsewhere on the board
/Fan Channels/Fan2/PWR_OUT: C14.1, D14.1 (K), JP3.2 (C), R19.1; also elsewhere on the board
/Fan Channels/Fan2/TACHO_IN: D13.1 (K), D49.2 (A2); also elsewhere on the board
/Fan Channels/Fan2/TACHO_OUT: D61.2 (A2), Q2.3 (D); also elsewhere on the board
/Fan Channels/Fan4/PWM_IN: D59.2 (A2), R22.2; also elsewhere on the board
/Fan Channels/Fan4/PWM_OUT: D67.2 (A2), R28.2; also elsewhere on the board
/Fan Channels/Fan4/PWR_OUT: C17.1, D18.1 (K), JP4.2 (C), R26.1; also elsewhere on the board
/Fan Channels/Fan4/TACHO_IN: D17.1 (K), D51.2 (A2); also elsewhere on the board
/Fan Channels/Fan4/TACHO_OUT: D63.2 (A2), Q3.3 (D); also elsewhere on the board
AUX12V: JP2.3 (B), JP3.3 (B), JP4.3 (B); also elsewhere on the board
FAN1_PWM_GEN: R14.1; also elsewhere on the board
FAN1_PWR: D44.2 (A2), JP2.1 (A), R10.1; also elsewhere on the board
FAN1_TACHO_READ: C10.1, D9.2 (A), R13.1; also elsewhere on the board
FAN2_PWM_GEN: R21.1; also elsewhere on the board
FAN2_PWR: D45.2 (A2), JP3.1 (A), R17.1; also elsewhere on the board
FAN2_TACHO_READ: C13.1, D13.2 (A), R20.1; also elsewhere on the board
FAN4_PWM_GEN: R28.1; also elsewhere on the board
FAN4_PWR: D47.2 (A2), JP4.1 (A), R24.1; also elsewhere on the board
FAN4_TACHO_READ: C16.1, D17.2 (A), R27.1; also elsewhere on the board
GND: C10.2, C11.2, C13.2, C14.2, C16.2, C17.2, D7.1 (K), D8.1 (K), D10.2 (A), D11.1 (K), D12.1 (K), D14.2 (A), D15.1 (K), D16.1 (K), D18.2 (A), D44.1 (A1), D45.1 (A1), D47.1 (A1), D48.1 (A1), D49.1 (A1), D51.1 (A1), D56.1 (A1), D57.1 (A1), D59.1 (A1), D60.1 (A1), D61.1 (A1), D63.1 (A1), D64.1 (A1), D65.1 (A1), D67.1 (A1), Q1.2 (S), Q2.2 (S), Q3.2 (S), R9.1, R16.1, R23.1; also elsewhere on the board
MBFAN1_PWM_READ: R8.1, R9.2; also elsewhere on the board
MBFAN1_TACHO_GEN: R11.2; also elsewhere on the board
MBFAN2_PWM_READ: R15.1, R16.2; also elsewhere on the board
MBFAN2_TACHO_GEN: R18.2; also elsewhere on the board
MBFAN4_PWM_READ: R22.1, R23.2; also elsewhere on the board
MBFAN4_TACHO_GEN: R25.2; also elsewhere on the board
unnamed: D7.2 (A), R10.2
unnamed: D8.2 (A), R12.2
unnamed: D11.2 (A), R17.2
unnamed: D12.2 (A), R19.2
unnamed: D15.2 (A), R24.2
unnamed: D16.2 (A), R26.2
unnamed: Q1.1 (G), R11.1
unnamed: Q2.1 (G), R18.1
unnamed: Q3.1 (G), R25.1

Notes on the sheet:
MCU Inputs/Outputs
To Motherboard Fan connector
Fan Channel: ${SHEETNAME}
To Fan

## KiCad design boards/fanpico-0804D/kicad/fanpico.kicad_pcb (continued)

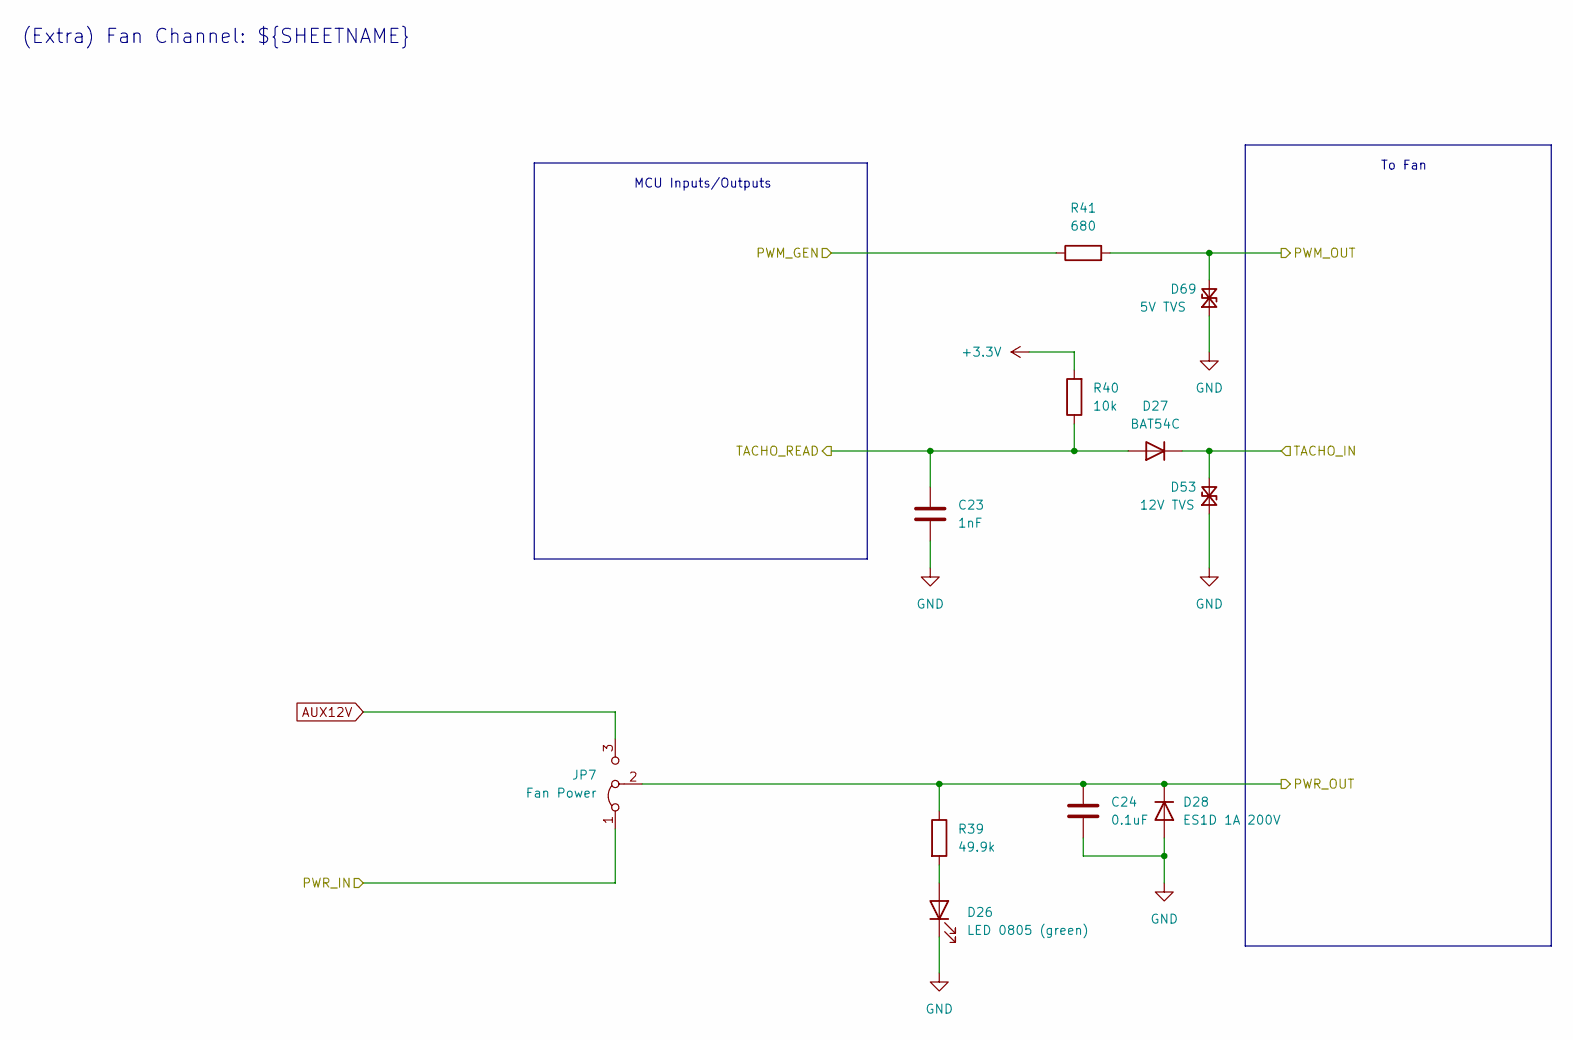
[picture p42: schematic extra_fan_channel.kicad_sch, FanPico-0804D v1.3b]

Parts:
C23: 1nF; C_0603_1608Metric_Pad1.08x0.95mm_HandSolder; LCSC Part Number C1588
C24: 0.1uF; C_0603_1608Metric_Pad1.08x0.95mm_HandSolder; LCSC Part Number C1591
D26: LED 0805 (green); LED_0805_2012Metric_Pad1.15x1.40mm_HandSolder; LCSC Part Number C434432
D27: BAT54C; D_SOT-23_ANK; LCSC Part Number C2844172
D28: ES1D 1A 200V; D_SMA_Handsoldering; LCSC Part Number C445494
D53: 12V TVS; D_SOD-323_HandSoldering; LCSC Part Number C502541 or C5199168
D69: 5V TVS; D_SOD-323_HandSoldering; LCSC Part Number C5180216
JP7: Fan Power; PinHeader_1x03_P2.54mm_Vertical
R39: 49.9k; R_0603_1608Metric_Pad0.98x0.95mm_HandSolder; LCSC Part Number C114624
R40: 10k; R_0603_1608Metric_Pad0.98x0.95mm_HandSolder; LCSC Part Number C98220
R41: 680; R_0603_1608Metric_Pad0.98x0.95mm_HandSolder; LCSC Part Number C115415

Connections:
3V3: R40.2; also elsewhere on the board
/Fan Channels/Fan6/PWM_OUT: D69.2 (A2), R41.2; also elsewhere on the board
/Fan Channels/Fan6/PWR_OUT: C24.1, D28.1 (K), JP7.2 (C), R39.1; also elsewhere on the board
/Fan Channels/Fan6/TACHO_IN: D27.1 (K), D53.2 (A2); also elsewhere on the board
AUX12V: JP7.3 (B); also elsewhere on the board
FAN2_PWR: JP7.1 (A); also elsewhere on the board
FAN6_PWM_GEN: R41.1; also elsewhere on the board
FAN6_TACHO_READ: C23.1, D27.2 (A), R40.1; also elsewhere on the board
GND: C23.2, C24.2, D26.1 (K), D28.2 (A), D53.1 (A1), D69.1 (A1); also elsewhere on the board
unnamed: D26.2 (A), R39.2

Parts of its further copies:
C21, C25, C27: 1nF; C_0603_1608Metric_Pad1.08x0.95mm_HandSolder; LCSC Part Number C1588
C22, C26, C28: 0.1uF; C_0603_1608Metric_Pad1.08x0.95mm_HandSolder; LCSC Part Number C1591
D23, D29, D32: LED 0805 (green); LED_0805_2012Metric_Pad1.15x1.40mm_HandSolder; LCSC Part Number C434432
D24, D30, D33: BAT54C; D_SOT-23_ANK; LCSC Part Number C2844172
D25, D31, D34: ES1D 1A 200V; D_SMA_Handsoldering; LCSC Part Number C445494
D52, D54, D55: 12V TVS; D_SOD-323_HandSoldering; LCSC Part Number C502541 or C5199168
D68, D70, D71: 5V TVS; D_SOD-323_HandSoldering; LCSC Part Number C5180216
JP6, JP8, JP9: Fan Power; PinHeader_1x03_P2.54mm_Vertical
R36, R42, R45: 49.9k; R_0603_1608Metric_Pad0.98x0.95mm_HandSolder; LCSC Part Number C114624
R37, R43, R46: 10k; R_0603_1608Metric_Pad0.98x0.95mm_HandSolder; LCSC Part Number C98220
R38, R44, R47: 680; R_0603_1608Metric_Pad0.98x0.95mm_HandSolder; LCSC Part Number C115415

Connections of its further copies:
3V3: R37.2, R43.2, R46.2; also elsewhere on the board
/Fan Channels/Fan5/PWM_OUT: D68.2 (A2), R38.2; also elsewhere on the board
/Fan Channels/Fan5/PWR_OUT: C22.1, D25.1 (K), JP6.2 (C), R36.1; also elsewhere on the board
/Fan Channels/Fan5/TACHO_IN: D24.1 (K), D52.2 (A2); also elsewhere on the board
/Fan Channels/Fan7/PWM_OUT: D70.2 (A2), R44.2; also elsewhere on the board
/Fan Channels/Fan7/PWR_OUT: C26.1, D31.1 (K), JP8.2 (C), R42.1; also elsewhere on the board
/Fan Channels/Fan7/TACHO_IN: D30.1 (K), D54.2 (A2); also elsewhere on the board
/Fan Channels/Fan8/PWM_OUT: D71.2 (A2), R47.2; also elsewhere on the board
/Fan Channels/Fan8/PWR_OUT: C28.1, D34.1 (K), JP9.2 (C), R45.1; also elsewhere on the board
/Fan Channels/Fan8/TACHO_IN: D33.1 (K), D55.2 (A2); also elsewhere on the board
AUX12V: JP6.3 (B), JP8.3 (B), JP9.3 (B); also elsewhere on the board
FAN1_PWR: JP6.1 (A); also elsewhere on the board
FAN3_PWR: JP8.1 (A); also elsewhere on the board
FAN4_PWR: JP9.1 (A); also elsewhere on the board
FAN5_PWM_GEN: R38.1; also elsewhere on the board
FAN5_TACHO_READ: C21.1, D24.2 (A), R37.1; also elsewhere on the board
FAN7_PWM_GEN: R44.1; also elsewhere on the board
FAN7_TACHO_READ: C25.1, D30.2 (A), R43.1; also elsewhere on the board
FAN8_PWM_GEN: R47.1; also elsewhere on the board
FAN8_TACHO_READ: C27.1, D33.2 (A), R46.1; also elsewhere on the board
GND: C21.2, C22.2, C25.2, C26.2, C27.2, C28.2, D23.1 (K), D25.2 (A), D29.1 (K), D31.2 (A), D32.1 (K), D34.2 (A), D52.1 (A1), D54.1 (A1), D55.1 (A1), D68.1 (A1), D70.1 (A1), D71.1 (A1); also elsewhere on the board
unnamed: D23.2 (A), R36.2
unnamed: D29.2 (A), R42.2
unnamed: D32.2 (A), R45.2

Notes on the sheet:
MCU Inputs/Outputs
(Extra) Fan Channel: ${SHEETNAME}
To Fan


Board: 2 copper layers, 135.0 x 81.5 mm, 213 parts (0 on the bottom side), 125 nets.

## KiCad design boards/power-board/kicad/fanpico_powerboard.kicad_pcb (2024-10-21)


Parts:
D1: LED; D_0805_2012Metric_Pad1.15x1.40mm_HandSolder; Mouser Part Number 710-150080GS75000; LCSC Part Number C434432
F1: Polyfuse 10A; Fuse_2920_7451Metric_Pad2.10x5.45mm_HandSolder; LCSC Part Number C22446882
F2: 10A; Fuseholder_Clip-5x20mm_Littelfuse_445-030_Inline_P20.50x5.2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; LCSC Part Number C717027
H1, H2, H3, H4: MountingHole_Pad; MountingHole_3.2mm_M3_Pad_Via; not fitted
J1: Power Input 2; TerminalBlock_Phoenix_MKDS-1,5-2_1x02_P5.00mm_Horizontal; LCSC Part Number C1509679
J2: Power Input 1; TE_MATE-N-LOK_350211-1_1x04_P5.08mm_Vertical_and_RightAngle; Mouser Part Number 571-3502111 / 571-1748041; LCSC Part Number C305826 or C7461144
J3: AUX Power Output; TerminalBlock_Phoenix_MKDS-1,5-2_1x02_P5.00mm_Horizontal; LCSC Part Number C1509679
J5: FAN1; FanPinHeader_1x04_P2.54mm_Vertical; Mouser Part Number 538-47053-1000; LCSC Part Number C240840
J6: FAN2; FanPinHeader_1x04_P2.54mm_Vertical; Mouser Part Number 538-47053-1000; LCSC Part Number C240840
J7: FAN3; FanPinHeader_1x04_P2.54mm_Vertical; Mouser Part Number 538-47053-1000; LCSC Part Number C240840
J8: FAN4; FanPinHeader_1x04_P2.54mm_Vertical; Mouser Part Number 538-47053-1000; LCSC Part Number C240840
J13: FANCTRL1; FanPinHeader_1x04_P2.54mm_Vertical; Mouser Part Number 538-47053-1000; LCSC Part Number C240840
J14: FANCTRL2; FanPinHeader_1x04_P2.54mm_Vertical; Mouser Part Number 538-47053-1000; LCSC Part Number C240840
J15: FANCTRL3; FanPinHeader_1x04_P2.54mm_Vertical; Mouser Part Number 538-47053-1000; LCSC Part Number C240840
J16: FANCTRL4; FanPinHeader_1x04_P2.54mm_Vertical; Mouser Part Number 538-47053-1000; LCSC Part Number C240840
R1: 49.9K; R_0603_1608Metric_Pad0.98x0.95mm_HandSolder; LCSC Part Number C114624

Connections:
12V: F1.1, F2.1, J1.1, J2.1
GND: D1.1 (K), H1.1, H2.1, H3.1, H4.1, J1.2, J2.2, J2.3, J3.2, J5.1, J6.1, J7.1, J8.1, J13.1, J14.1, J15.1, J16.1
unnamed: D1.2 (A), R1.2
PWM1: J5.4, J13.4
PWM2: J6.4, J14.4
PWM3: J7.4, J15.4
PWM4: J8.4, J16.4
PWR: F1.2, F2.2, J3.1, J5.2, J6.2, J7.2, J8.2, R1.1
TACHO1: J5.3, J13.3
TACHO2: J6.3, J14.3
TACHO3: J7.3, J15.3
TACHO4: J8.3, J16.3

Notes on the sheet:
To Fans
To Fan Controller (FanPico)


Board: 2 copper layers, 65.0 x 65.0 mm, 19 parts (0 on the bottom side), 12 nets.

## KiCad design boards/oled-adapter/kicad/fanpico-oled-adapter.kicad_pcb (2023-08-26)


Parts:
J1: To_FanPico_J3; PinHeader_1x04_P2.54mm_Vertical
J2: 1.5" OLED; PinHeader_1x04_P2.54mm_Vertical
J3: 1.3" OLED (alt pinout); PinHeader_1x04_P2.54mm_Vertical

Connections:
GND: J1.1, J2.3, J3.2
SCL: J1.3, J2.2, J3.3
SDA: J1.4, J2.1, J3.4
VCC: J1.2, J2.4, J3.1


Board: 2 copper layers, 25.0 x 14.5 mm, 3 parts (0 on the bottom side), 4 nets.

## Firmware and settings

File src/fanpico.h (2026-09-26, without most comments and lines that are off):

#define FANPICO_H 1
#include "config.h"
#include "log.h"
#include <time.h>
#include "pico/mutex.h"
#ifdef LIB_PICO_CYW43_ARCH
#define WIFI_SUPPORT 1
#include "lwip/ip_addr.h"
#include "lwip/apps/sntp.h"
#endif
#ifndef FANPICO_MODEL
#error unknown board model
#endif
#define FAN_MAX_COUNT     8
#define MBFAN_MAX_COUNT   4
#define SENSOR_MAX_COUNT  3
#define VSENSOR_MAX_COUNT 8
#define VSENSOR_SOURCE_MAX_COUNT 8
#define VSENSOR_COUNT            8
#define ONEWIRE_MAX_COUNT        8
#define SENSOR_SERIES_RESISTANCE 10000.0
#define ADC_REF_VOLTAGE 3.0
#define FAN_TACHO_HYSTERESIS 1.0
#define FAN_PWM_HYSTERESIS 1.0
#define ADC_MAX_VALUE   (1 << 12)
#define ADC_AVG_WINDOW  10
#define MAX_NAME_LEN   64
#define MAX_MAP_POINTS 32
#define MAX_GPIO_PINS  32
#define WIFI_SSID_MAX_LEN     32
#define WIFI_PASSWD_MAX_LEN   64
#define WIFI_COUNTRY_MAX_LEN  3
#define MQTT_MAX_TOPIC_LEN            48
#define MQTT_MAX_USERNAME_LEN         80
#define MQTT_MAX_PASSWORD_LEN         64
#define DEFAULT_MQTT_STATUS_INTERVAL  600
#define DEFAULT_MQTT_TEMP_INTERVAL    60
#define DEFAULT_MQTT_RPM_INTERVAL     60
#define DEFAULT_MQTT_DUTY_INTERVAL    60
#define HTTP_SERVER_DEFAULT_PORT      80
#define HTTPS_SERVER_DEFAULT_PORT     443
#define TELNET_MAX_ACL_ENTRIES 4
#define SSH_MAX_ACL_ENTRIES 4
#define SSH_MAX_PUB_KEYS  4
#define MAX_USERNAME_LEN  16
#define MAX_PWHASH_LEN    128
#ifdef NDEBUG
#define WATCHDOG_ENABLED      1
#define WATCHDOG_REBOOT_DELAY 8000
#endif
#define I2C_DEFAULT_SPEED   1000000L
#define SPI_DEFAULT_SPEED  30000000L
#define FANPICO_FS_SIZE  (256*1024)
#define FANPICO_FS_OFFSET  (PICO_FLASH_SIZE_BYTES - FANPICO_FS_SIZE)
enum pwm_source_types {
	PWM_FIXED   = 0,
	PWM_MB      = 1,
	PWM_SENSOR  = 2,
	PWM_FAN     = 3,
	PWM_VSENSOR = 4,
};
#define PWM_SOURCE_ENUM_MAX 4
enum signal_filter_types {
	FILTER_NONE      = 0,
	FILTER_LOSSYPEAK = 1,
	FILTER_SMA       = 2,
};
#define FILTER_ENUM_MAX 2
enum tacho_source_types {
	TACHO_FIXED  = 0,
	TACHO_FAN    = 1,
	TACHO_MIN    = 2,
	TACHO_MAX    = 3,
	TACHO_AVG    = 4,
};
#define TACHO_ENUM_MAX 4
enum temp_sensor_types {
	TEMP_INTERNAL = 0,
	TEMP_EXTERNAL = 1,
};
#define TEMP_ENUM_MAX 1
enum vsensor_modes {
	VSMODE_MANUAL  = 0,
	VSMODE_MAX     = 1,
	VSMODE_MIN     = 2,
	VSMODE_AVG     = 3,
	VSMODE_DELTA   = 4,
	VSMODE_ONEWIRE = 5,
	VSMODE_I2C     = 6,
};
#define VSMODE_ENUM_MAX 6
enum rpm_modes {
	RMODE_TACHO = 0,
	RMODE_LRA   = 1,
};
#define RPMMODE_ENUM_MAX 1
#ifdef WIFI_SUPPORT
typedef struct acl_entry_t {
	ip_addr_t ip;
	uint8_t prefix;
} acl_entry_t;
#endif
struct ssh_public_key {
	char username[MAX_USERNAME_LEN + 1];
	char type[32 + 1];
	char name[32 + 1];
	uint8_t pubkey[128];
	uint16_t pubkey_size;
};
struct pwm_map {
	uint8_t points;
	uint8_t pwm[MAX_MAP_POINTS][2];
};
struct tacho_map {
	uint8_t points;
	uint16_t tacho[MAX_MAP_POINTS][2];
};
struct temp_map {
	uint8_t points;
	float temp[MAX_MAP_POINTS][2];
};
struct fan_output {
	char name[MAX_NAME_LEN];
	float tacho_hyst;
	float pwm_hyst;
	uint8_t min_pwm;
	uint8_t max_pwm;
	float pwm_coefficient;
	enum pwm_source_types s_type;
	uint16_t s_id;
	struct pwm_map map;
	enum signal_filter_types filter;
	void *filter_ctx;
	uint8_t rpm_mode;
	uint8_t rpm_factor;
	uint16_t lra_low;
	uint16_t lra_high;
};
struct mb_input {
	char name[MAX_NAME_LEN];
	uint8_t rpm_mode;
	uint16_t min_rpm;
	uint16_t max_rpm;
	float rpm_coefficient;
	uint8_t rpm_factor;
	uint16_t lra_treshold;
	bool lra_invert;
	enum tacho_source_types s_type;
	uint16_t s_id;
	uint8_t sources[FAN_MAX_COUNT];
	struct tacho_map map;
	enum signal_filter_types filter;
	void *filter_ctx;
};
struct sensor_input {
	enum temp_sensor_types type;
	char name[MAX_NAME_LEN];
	float thermistor_nominal;
	float temp_nominal;
	float beta_coefficient;
	float temp_offset;
	float temp_coefficient;
	struct temp_map map;
	enum signal_filter_types filter;
	void *filter_ctx;
};
struct vsensor_input {
	char name[MAX_NAME_LEN];
	uint8_t mode;
	float default_temp;
	int32_t timeout;
	uint8_t sensors[VSENSOR_SOURCE_MAX_COUNT];
	uint64_t onewire_addr;
	uint8_t i2c_type;
	uint8_t i2c_addr;
	struct temp_map map;
	enum signal_filter_types filter;
	void *filter_ctx;
};
struct fanpico_config {
	struct sensor_input sensors[SENSOR_MAX_COUNT];
	struct vsensor_input vsensors[VSENSOR_MAX_COUNT];
	struct fan_output fans[FAN_MAX_COUNT];
	struct mb_input mbfans[MBFAN_MAX_COUNT];
	bool local_echo;
	uint8_t led_mode;
	char display_type[64];
	char display_theme[16];
	char display_logo[16];
	char display_layout_r[64];
	char name[32];
	char timezone[64];
	bool spi_active;
	bool serial_active;
	bool onewire_active;
	uint32_t i2c_speed;
	float adc_vref;
#ifdef WIFI_SUPPORT
	char wifi_ssid[WIFI_SSID_MAX_LEN + 1];
	char wifi_passwd[WIFI_PASSWD_MAX_LEN + 1];
	char wifi_country[WIFI_COUNTRY_MAX_LEN + 1];
	char wifi_auth_mode[16];
	uint8_t wifi_mode;
	char hostname[32];
	ip_addr_t dns_servers[DNS_MAX_SERVERS];
	bool syslog_active;
	ip_addr_t syslog_server;
	bool ntp_active;
	ip_addr_t ntp_servers[SNTP_MAX_SERVERS];
	ip_addr_t ip;
	ip_addr_t netmask;
	ip_addr_t gateway;
	char mqtt_server[32];
	uint16_t mqtt_port;
	bool mqtt_tls;
	bool mqtt_allow_scpi;
	char mqtt_user[MQTT_MAX_USERNAME_LEN + 1];
	char mqtt_pass[MQTT_MAX_PASSWORD_LEN + 1];
	char mqtt_status_topic[MQTT_MAX_TOPIC_LEN + 1];
	uint32_t mqtt_status_interval;
	char mqtt_cmd_topic[MQTT_MAX_TOPIC_LEN + 1];
	char mqtt_resp_topic[MQTT_MAX_TOPIC_LEN + 1];
	uint16_t mqtt_temp_mask;
	uint16_t mqtt_vtemp_mask;
	uint16_t mqtt_vhumidity_mask;
	uint16_t mqtt_vpressure_mask;
	uint16_t mqtt_fan_rpm_mask;
	uint16_t mqtt_fan_duty_mask;
	uint16_t mqtt_mbfan_rpm_mask;
	uint16_t mqtt_mbfan_duty_mask;
	char mqtt_temp_topic[MQTT_MAX_TOPIC_LEN + 1];
	char mqtt_vtemp_topic[MQTT_MAX_TOPIC_LEN + 1];
	char mqtt_vhumidity_topic[MQTT_MAX_TOPIC_LEN + 1];
	char mqtt_vpressure_topic[MQTT_MAX_TOPIC_LEN + 1];
	char mqtt_fan_rpm_topic[MQTT_MAX_TOPIC_LEN + 1];
	char mqtt_fan_duty_topic[MQTT_MAX_TOPIC_LEN + 1];
	char mqtt_mbfan_rpm_topic[MQTT_MAX_TOPIC_LEN + 1];
	char mqtt_mbfan_duty_topic[MQTT_MAX_TOPIC_LEN + 1];
	uint32_t mqtt_temp_interval;
	uint32_t mqtt_vsensor_interval;
	uint32_t mqtt_rpm_interval;
	uint32_t mqtt_duty_interval;
	char mqtt_ha_discovery_prefix[32 + 1];
	bool telnet_active;
	bool telnet_auth;
	bool telnet_raw_mode;
	uint16_t telnet_port;
	char telnet_user[MAX_USERNAME_LEN + 1];
	char telnet_pwhash[MAX_PWHASH_LEN + 1];
	acl_entry_t telnet_acls[TELNET_MAX_ACL_ENTRIES];
	bool snmp_active;
	char snmp_community[SNMP_MAX_COMMUNITY_STR_LEN + 1];
	char snmp_community_write[SNMP_MAX_COMMUNITY_STR_LEN + 1];
	char snmp_contact[32 + 1];
	char snmp_location[32 + 1];
	char snmp_community_trap[SNMP_MAX_COMMUNITY_STR_LEN + 1];
	bool snmp_auth_traps;
	ip_addr_t snmp_trap_dst;
	bool ssh_active;
	bool ssh_auth;
	uint16_t ssh_port;
	char ssh_user[MAX_USERNAME_LEN + 1];
	char ssh_pwhash[MAX_PWHASH_LEN + 1];
	struct ssh_public_key ssh_pub_keys[SSH_MAX_PUB_KEYS];
	acl_entry_t ssh_acls[SSH_MAX_ACL_ENTRIES];
	bool http_active;
	uint16_t http_port;
	uint16_t https_port;
	uint16_t http_fan_mask;
	uint16_t http_mbfan_mask;
	uint16_t http_sensor_mask;
	uint16_t http_vsensor_mask;
#endif
	float vtemp[VSENSOR_MAX_COUNT];
	float vhumidity[VSENSOR_MAX_COUNT];
	float vpressure[VSENSOR_MAX_COUNT];
	absolute_time_t vtemp_updated[VSENSOR_MAX_COUNT];
	void *i2c_context[VSENSOR_MAX_COUNT];
};
struct fanpico_fw_settings {
	bool safemode;
	int bootdelay;
	int sysclock;
};
#if WIFI_SUPPORT
struct fanpico_network_state {
	ip_addr_t ip;
	ip_addr_t netmask;
	ip_addr_t gateway;
	ip_addr_t syslog_server;
	ip_addr_t ntp_servers[SNTP_MAX_SERVERS];
	ip_addr_t dns_servers[DNS_MAX_SERVERS];
	uint8_t mac[6];
	char hostname[32];
	bool netif_up;
	int wifi_status;
	absolute_time_t wifi_status_change;
};
#endif
struct fanpico_state {
	float mbfan_duty[MBFAN_MAX_COUNT];
	float mbfan_duty_prev[MBFAN_MAX_COUNT];
	float fan_freq[FAN_MAX_COUNT];
	float fan_freq_prev[FAN_MAX_COUNT];
	float temp[SENSOR_MAX_COUNT];
	float temp_prev[SENSOR_MAX_COUNT];
	float vtemp[VSENSOR_MAX_COUNT];
	float vhumidity[VSENSOR_MAX_COUNT];
	float vpressure[VSENSOR_MAX_COUNT];
	absolute_time_t vtemp_updated[VSENSOR_MAX_COUNT];
	float vtemp_prev[VSENSOR_MAX_COUNT];
	float onewire_temp[ONEWIRE_MAX_COUNT];
	absolute_time_t onewire_temp_updated[VSENSOR_MAX_COUNT];
	float prev_onewire_temp[ONEWIRE_MAX_COUNT];
	float fan_duty[FAN_MAX_COUNT];
	float fan_duty_prev[FAN_MAX_COUNT];
	float mbfan_freq[MBFAN_MAX_COUNT];
	float mbfan_freq_prev[MBFAN_MAX_COUNT];
};
struct persistent_memory_block {
	uint32_t id;
	uint32_t len;
	struct timespec saved_time;
	uint64_t uptime;
	uint64_t prev_uptime;
	uint64_t total_uptime;
	uint32_t warmstart;
	char timezone[64];
	uint32_t crc32;
};
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

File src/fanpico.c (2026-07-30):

/* fanpico.c
   Copyright (C) 2021-2026 Timo Kokkonen <tjko@iki.fi>

   SPDX-License-Identifier: GPL-3.0-or-later

   This file is part of FanPico.

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
   You should have received a copy of the GNU General Public License
   along with FanPico. If not, see <https://www.gnu.org/licenses/>.
*/

#include <stdio.h>
#include <string.h>
#include <math.h>
#include <malloc.h>
#include <stdlib.h>
#include "pico/stdlib.h"
#include "pico/mutex.h"
#include "pico/multicore.h"
#include "pico/util/datetime.h"
#include "pico/aon_timer.h"
#ifdef LIB_PICO_CYW43_ARCH
#include "pico/cyw43_arch.h"
#endif
#include "hardware/adc.h"
#include "hardware/gpio.h"
#include "hardware/pwm.h"
#include "hardware/clocks.h"
#include "hardware/watchdog.h"
#include "hardware/vreg.h"

#include "fanpico.h"
#include "command_util.h"
#include "util_rp2.h"
#include "psram.h"


#ifdef FANPICO_PSRAM_PIN
 #if TX_PIN == 0
  /* Check for non-standard boards that may have PSRAM on pin 0 (Serial TX) */
  #if FANPICO_PSRAM_PIN == TX_PIN
   #undef TTL_SERIAL
  #endif
 #endif
#endif

static struct fanpico_state core1_state;
static struct fanpico_config core1_config;
static struct fanpico_state transfer_state;
static struct fanpico_state system_state;
const struct fanpico_state *fanpico_state = &system_state;
static struct fanpico_fw_settings system_settings;
const struct fanpico_fw_settings *fw_settings = &system_settings;

#ifdef WIFI_SUPPORT
static struct fanpico_network_state network_state;
struct fanpico_network_state *net_state = &network_state;
#endif

struct persistent_memory_block __uninitialized_ram(persistent_memory);
struct persistent_memory_block *persistent_mem = &persistent_memory;

#define PERSISTENT_MEMORY_ID 0x42c0ffee
#define PERSISTENT_MEMORY_CRC_LEN offsetof(struct persistent_memory_block, crc32)

auto_init_mutex(pmem_mutex_inst);
mutex_t *pmem_mutex = &pmem_mutex_inst;
auto_init_mutex(state_mutex_inst);
mutex_t *state_mutex = &state_mutex_inst;
bool rebooted_by_watchdog = false;

static char input_buf[1024];


static void update_persistent_memory_crc()
{
	struct persistent_memory_block *m = persistent_mem;

	m->crc32 = xcrc32((unsigned char*)m, PERSISTENT_MEMORY_CRC_LEN, 0);
}

static void init_persistent_memory()
{
	struct persistent_memory_block *m = persistent_mem;
	uint32_t crc;

	if (m->id == PERSISTENT_MEMORY_ID && m->len == sizeof(persistent_memory)) {
		crc = xcrc32((unsigned char*)m, PERSISTENT_MEMORY_CRC_LEN, 0);
		if (crc == m->crc32) {
			printf("Found persistent memory block\n");
			if (strlen(m->timezone) > 0) {
				/* Restore timezone */
				setenv("TZ", m->timezone, 1);
				tzset();
			}
			if (m->saved_time.tv_sec > 0)
				aon_timer_start(&m->saved_time);
			if (m->uptime) {
				m->prev_uptime = m->uptime;
				m->total_uptime += m->uptime;
			}
			m->warmstart++;
			update_persistent_memory_crc();
			return;
		}
		printf("Found corrupt persistent memory block"
			" (CRC-32 mismatch  %08lx != %08lx)\n", crc, m->crc32);
	}

	printf("Initializing persistent memory block...\n");
	memset(m, 0, sizeof(*m));
	m->id = PERSISTENT_MEMORY_ID;
	m->len = sizeof(persistent_memory);
	update_persistent_memory_crc();
}

void update_persistent_memory()
{
	struct persistent_memory_block *m = persistent_mem;
	struct timespec t;

	if (mutex_enter_timeout_us(pmem_mutex, 100)) {
		if (aon_timer_is_running()) {
			aon_timer_get_time(&t);
			m->saved_time = t;
		}
		m->uptime = to_us_since_boot(get_absolute_time());
		update_persistent_memory_crc();
		mutex_exit(pmem_mutex);
	} else {
		log_msg(LOG_DEBUG, "update_persistent_memory(): Failed to get pmem_mutex");
	}
}

void update_persistent_memory_tz(const char *tz)
{
	struct persistent_memory_block *m = persistent_mem;

	if (mutex_enter_timeout_us(pmem_mutex, 100)) {
		strncopy(m->timezone, tz, sizeof(m->timezone));
		update_persistent_memory_crc();
		mutex_exit(pmem_mutex);
	} else {
		log_msg(LOG_DEBUG, "update_persistent_memory_tz(): Failed to get pmem_mutex");
	}
}


void boot_reason()
{
#if PICO_RP2040
	printf("     CHIP_RESET: %08lx\n", vreg_and_chip_reset_hw->chip_reset);
#endif
	printf("WATCHDOG_REASON: %08lx\n", watchdog_hw->reason);
}


static void setup()
{
	struct persistent_memory_block *m = persistent_mem;
	char buf[32];
	int i = 0;


	if (fw_settings->sysclock > 0 && fw_settings->sysclock < 1000) {
		rp2_set_sys_clock(fw_settings->sysclock * 1000);
	}

	stdio_usb_init();
	/* Wait a while for USB Serial to connect... */
	while (i++ < 40) {
		if (stdio_usb_connected())
			break;
		sleep_ms(50);
	}

	if (fw_settings->bootdelay > 0)
		sleep_ms(fw_settings->bootdelay * 1000);

	lfs_setup(false);
	read_config(fw_settings->safemode);


#if TTL_SERIAL
	/* Initialize serial console if configured... */
	if(cfg->serial_active && (!cfg->spi_active || !SPI_SHARED)) {
		stdio_uart_init_full(TTL_SERIAL_UART,
				TTL_SERIAL_SPEED, TX_PIN, RX_PIN);
	}
#endif
	printf("\n\n");
#ifndef NDEBUG
	boot_reason();
#endif
	if (watchdog_enable_caused_reboot()) {
		printf("\n[Rebooted by watchdog]\n");
		rebooted_by_watchdog = true;
	}
	printf("\n");
	psram_setup();

	/* Run "SYStem:VERsion?" command... */
	cmd_version(NULL, NULL, 0, NULL);
	/* Run "SYStem:BOARD?" command... */
	cmd_board(NULL, NULL, 0, NULL);
	printf("\n");

	init_persistent_memory();
	printf("\n");
	if (fw_settings->safemode)
		printf("*** Booting into Safe Mode ***\n\n");

	log_msg(LOG_NOTICE, "System starting...");
	if (m->prev_uptime) {
		uptime_to_str(buf, sizeof(buf), m->prev_uptime, true);
		log_msg(LOG_NOTICE, "Uptime before last soft reset: %s", buf);
		uptime_to_str(buf, sizeof(buf), m->total_uptime, true);
		log_msg(LOG_NOTICE, "Uptime since cold boot: %s (soft reset count: %lu)",
			buf, m->warmstart);
	}

	/* Setup timezone */
	if (strlen(cfg->timezone) > 1) {
		log_msg(LOG_NOTICE, "Set timezone: %s", cfg->timezone);
		update_persistent_memory_tz(cfg->timezone);
		setenv("TZ", cfg->timezone, 1);
		tzset();
	}


	if (aon_timer_is_running()) {
		struct timespec ts;
		aon_timer_get_time(&ts);
		log_msg(LOG_NOTICE, "RTC clock time: %s",
			time_t_to_str(buf, sizeof(buf), timespec_to_time_t(&ts)));
	}

	setup_i2c_bus((struct fanpico_config *)cfg);
	display_init();
	network_init();

	/* Enable ADC */
	log_msg(LOG_NOTICE, "Initialize ADC...");
	adc_init();
	adc_set_temp_sensor_enabled(true);
	if (SENSOR1_READ_PIN > 0)
		adc_gpio_init(SENSOR1_READ_PIN);
	if (SENSOR2_READ_PIN > 0)
		adc_gpio_init(SENSOR2_READ_PIN);

	/* Setup GPIO pins... */
	log_msg(LOG_NOTICE, "Initialize GPIO...");

	/* Initialize status LED... */
	if (rp2_is_picow()) {
		/* On pico_w, LED is connected to the radio GPIO... */
#ifdef LIB_PICO_CYW43_ARCH
		cyw43_arch_lwip_begin();
		cyw43_arch_gpio_put(CYW43_WL_GPIO_LED_PIN, 0);
		cyw43_arch_lwip_end();
#endif
	} else {
#if LED_PIN > 0
		gpio_init(LED_PIN);
		gpio_set_dir(LED_PIN, GPIO_OUT);
		gpio_put(LED_PIN, 0);
#endif
	}

	/* Configure PWM pins... */
	setup_pwm_outputs();
	setup_pwm_inputs();

	for (i = 0; i < FAN_COUNT; i++) {
		set_pwm_duty_cycle(i, 0);
	}

	/* Configure Tacho pins... */
	setup_tacho_outputs();
	setup_tacho_inputs();

	/* Configure 1-Wire pins... */
	setup_onewire_bus();

	log_msg(LOG_NOTICE, "System initialization complete.");
}


static void clear_state(struct fanpico_state *s)
{
	int i;

	memset(s, 0, sizeof(struct fanpico_state));

	for (i = 0; i < MBFAN_MAX_COUNT; i++) {
		s->mbfan_duty[i] = 0.0;
		s->mbfan_duty_prev[i] = 0.0;
		s->mbfan_freq[i] = 0.0;
		s->mbfan_freq_prev[i] = 0.0;
	}
	for (i = 0; i < FAN_MAX_COUNT; i++) {
		s->fan_duty[i] = 0.0;
		s->fan_duty_prev[i] = 0.0;
		s->fan_freq[i] = 0.0;
		s->fan_freq_prev[i] = 0.0;
	}
	for (i = 0; i < SENSOR_MAX_COUNT; i++) {
		s->temp[i] = 0.0;
		s->temp_prev[i] = 0.0;
	}
	for (i = 0; i < VSENSOR_MAX_COUNT; i++) {
		s->vtemp[i] = 0.0;
		s->vtemp_prev[i] = 0.0;
		s->vtemp_updated[i] = from_us_since_boot(0);
		s->vpressure[i] = -1.0;
		s->vhumidity[i] = -1.0;
	}

}


/* update_system_state()
 *  System state gets updated by core1 periodically (using state_mutex)
 *  to intermediate buffer transfer_state.
 *  This function updates system state from that buffer.
 */

static void update_system_state()
{
	if (mutex_enter_timeout_us(state_mutex, 1000)) {
		memcpy(&system_state, &transfer_state, sizeof(system_state));
		mutex_exit(state_mutex);
	} else {
		log_msg(LOG_INFO, "update_system_state(): failed to get system_mutex");
	}
}


static void update_outputs(struct fanpico_state *state, const struct fanpico_config *config)
{
	int i;

	/* Update fan PWM signals */
	for (i = 0; i < FAN_COUNT; i++) {
		float hyst = cfg->fans[i].pwm_hyst;
		state->fan_duty[i] = calculate_pwm_duty(state, config, i);
		if (check_for_change(state->fan_duty_prev[i], state->fan_duty[i], hyst)) {
			log_msg(LOG_INFO, "fan%d: Set output PWM %.1f%% --> %.1f%%",
				i+1,
				state->fan_duty_prev[i],
				state->fan_duty[i]);
			state->fan_duty_prev[i] = state->fan_duty[i];
			set_pwm_duty_cycle(i, state->fan_duty[i]);
		}
	}

	/* Update mb tacho signals */
	for (i = 0; i < MBFAN_COUNT; i++) {
		state->mbfan_freq[i] = calculate_tacho_freq(state, config, i);
		if (check_for_change(state->mbfan_freq_prev[i], state->mbfan_freq[i], 1.0)) {
			log_msg(LOG_INFO, "mbfan%d: Set output Tacho %.2fHz --> %.2fHz",
				i+1,
				state->mbfan_freq_prev[i],
				state->mbfan_freq[i]);
			state->mbfan_freq_prev[i] = state->mbfan_freq[i];
			if (cfg->mbfans[i].rpm_mode == RMODE_TACHO) {
				set_tacho_output_freq(i, state->mbfan_freq[i]);
			} else {
				int rpm = state->mbfan_freq[i] * 60 / cfg->mbfans[i].rpm_factor;
				bool lra = (rpm < cfg->mbfans[i].lra_treshold ? true : false);
				set_lra_output(i, cfg->mbfans[i].lra_invert ? !lra : lra);
			}
		}
	}
}


static void core1_main()
{
	struct fanpico_config *config = &core1_config;
	struct fanpico_state *state = &core1_state;
	absolute_time_t ABSOLUTE_TIME_INITIALIZED_VAR(t_temp, 0);
	absolute_time_t ABSOLUTE_TIME_INITIALIZED_VAR(t_onewire_temp, 0);
	absolute_time_t ABSOLUTE_TIME_INITIALIZED_VAR(t_tacho, 0);
	absolute_time_t ABSOLUTE_TIME_INITIALIZED_VAR(t_poll_pwm, 0);
	absolute_time_t ABSOLUTE_TIME_INITIALIZED_VAR(t_set_outputs, 0);
	absolute_time_t t_last, t_now, t_config, t_state;
	int onewire_delay = 5000;
	int64_t max_delta = 0;
	int64_t delta;


	log_msg(LOG_INFO, "core1: started...");

	/* Allow core0 to pause this core... */
	multicore_lockout_victim_init();

	setup_tacho_input_interrupts();

	t_state = t_config = t_last = get_absolute_time();

	while (1) {
		t_now = get_absolute_time();
		delta = absolute_time_diff_us(t_last, t_now);
		t_last = t_now;

		if (delta > max_delta) {
			max_delta = delta;
			log_msg(LOG_INFO, "core1: max_loop_time=%lld", max_delta);
		}

		/* Tachometer inputs from Fans */
		read_tacho_inputs();
		if (time_passed(&t_tacho, 1000)) {
			/* Calculate frequencies from input tachometer signals peridocially */
			log_msg(LOG_DEBUG, "Updating tacho input signals.");
			update_tacho_input_freq(state);
		}

		/* PWM input signals (duty cycles) from "motherboard". */
		get_pwm_duty_cycles(config);
		if (time_passed(&t_poll_pwm, 200)) {
			//log_msg(LOG_DEBUG, "Read PWM inputs");
			for (int i = 0; i < MBFAN_COUNT; i++) {
				state->mbfan_duty[i] = roundf(mbfan_pwm_duty[i]);
				if (check_for_change(state->mbfan_duty_prev[i], state->mbfan_duty[i], 1.5)) {
					log_msg(LOG_INFO, "mbfan%d: Input PWM change %.1f%% --> %.1f%%",
						i+1,
						state->mbfan_duty_prev[i],
						state->mbfan_duty[i]);
					state->mbfan_duty_prev[i] = state->mbfan_duty[i];
				}
			}
		}

		/* Read temperature sensors periodically */
		if (time_passed(&t_temp, 2000)) {
			log_msg(LOG_DEBUG, "Read temperature sensors");
			for (int i = 0; i < SENSOR_COUNT; i++) {
				state->temp[i] = get_temperature(i, config);
				if (check_for_change(state->temp_prev[i], state->temp[i], 0.5)) {
					log_msg(LOG_INFO, "sensor%d: Temperature change %.1fC --> %.1fC",
						i+1,
						state->temp_prev[i],
						state->temp[i]);
					state->temp_prev[i] = state->temp[i];
				}
			}

			log_msg(LOG_DEBUG, "Update virtual sensors");
			for (int i = 0; i < VSENSOR_COUNT; i++) {
				state->vtemp[i] = get_vsensor(i, config, state);
				if (check_for_change(state->vtemp_prev[i], state->vtemp[i], 0.5)) {
					log_msg(LOG_INFO, "vsensor%d: Temperature change %.1fC --> %.1fC",
						i+1,
						state->vtemp_prev[i],
						state->vtemp[i]);
					state->vtemp_prev[i] = state->vtemp[i];
				}
			}
		}

		/* Read 1-Wire temperature sensors */
		if (config->onewire_active && onewire_delay > 0) {
			if (time_passed(&t_onewire_temp, onewire_delay)) {
				onewire_delay = onewire_read_temps(config, state);
			}
		}

		if (time_passed(&t_set_outputs, 500)) {
			log_msg(LOG_DEBUG, "Updating output signals.");
			update_outputs(state, config);
		}

		if (time_passed(&t_config, 1000)) {
			/* Attempt to update config from core0 */
			if (mutex_enter_timeout_us(config_mutex, 100)) {
				memcpy(config, cfg, sizeof(*config));
				mutex_exit(config_mutex);
			} else {
				log_msg(LOG_DEBUG, "failed to get config_mutex");
			}
		}
		if (time_passed(&t_state, 500)) {
			/* Attempt to update system state on core0 */
			if (mutex_enter_timeout_us(state_mutex, 100)) {
				memcpy(&transfer_state, state, sizeof(transfer_state));
				mutex_exit(state_mutex);
			} else {
				log_msg(LOG_DEBUG, "failed to get state_mutex");
			}
		}

	}
}


int main()
{
	absolute_time_t ABSOLUTE_TIME_INITIALIZED_VAR(t_led, 0);
	absolute_time_t ABSOLUTE_TIME_INITIALIZED_VAR(t_network, 0);
	absolute_time_t ABSOLUTE_TIME_INITIALIZED_VAR(t_watchdog, 0);
	absolute_time_t t_now, t_last, t_display, t_ram, t_i2c_temp, t_led_start;
	uint8_t led_state = 0;
	int64_t max_delta = 0;
	int64_t led_max_delta = 0;
	int64_t delta;
	int c;
	int i_ptr = 0;
	int i2c_temp_delay =  1000;

	set_binary_info(&system_settings);
	clear_state(&system_state);
	clear_state(&transfer_state);
#ifdef WIFI_SUPPORT
	memset(&network_state, 0, sizeof(network_state));
#endif

	/* Initialize MCU and other hardware... */
	if (get_debug_level() >= 2)
		print_mallinfo();
	setup();
	if (get_debug_level() >= 2)
		print_mallinfo();

	/* Start second core (core1)... */
	memcpy(&core1_config, cfg, sizeof(core1_config));
	memcpy(&core1_state, &system_state, sizeof(core1_state));
	multicore_launch_core1(core1_main);

#if WATCHDOG_ENABLED
	watchdog_enable(WATCHDOG_REBOOT_DELAY, 1);
	log_msg(LOG_NOTICE, "Watchdog enabled.");
#endif

	t_last = get_absolute_time();
	t_i2c_temp = t_ram = t_display = t_last;

	while (1) {
		t_now = get_absolute_time();
		delta = absolute_time_diff_us(t_last, t_now);
		t_last = t_now;

		if (delta > max_delta) {
			max_delta = delta;
			log_msg(LOG_INFO, "core0: max_loop_time=%lld", max_delta);
		}

		if (time_passed(&t_network, 1)) {
			network_poll();
		}
		if (time_passed(&t_ram, 1000)) {
			log_msg(LOG_DEBUG, "update persistent mem start");
			update_persistent_memory();
			//log_msg(LOG_DEBUG, "update persistent mem end");
		}

		/* Toggle LED every 1000ms */
		if (time_passed(&t_led, 1000)) {
			uint8_t old_led_state = led_state;
			if (cfg->led_mode == 0) {
				/* Slow blinking */
				led_state = (led_state > 0 ? 0 : 1);
			} else if (cfg->led_mode == 1) {
				/* Always on */
				led_state = 1;
			} else {
				/* Always off */
				led_state = 0;
			}
			if (led_state != old_led_state) {
				log_msg(LOG_DEBUG, "toggle LED start: %u", led_state);
				t_led_start = get_absolute_time();
				if (rp2_is_picow()) {
#ifdef LIB_PICO_CYW43_ARCH
					cyw43_arch_lwip_begin();
					cyw43_arch_gpio_put(CYW43_WL_GPIO_LED_PIN, led_state);
					cyw43_arch_lwip_end();
#endif
				} else {
#if LED_PIN > 0
					gpio_put(LED_PIN, led_state);
#endif
				}

				t_now = get_absolute_time();
				log_msg(LOG_DEBUG, "toggle LED end");
				delta = absolute_time_diff_us(t_led_start, t_now);
				if (delta > led_max_delta) {
					led_max_delta = delta;
					log_msg(LOG_INFO, "core0: max_led_gpio_time=%lld", led_max_delta);
				}
			}
		}

		/* Update display every 1000ms */
		if (time_passed(&t_display, 1000)) {
			log_msg(LOG_DEBUG, "update display start");
			update_system_state();
			display_status(fanpico_state, cfg);
			log_msg(LOG_DEBUG, "update display end");
		}

		/* Poll I2C Temperature Sensors */
		if (i2c_temp_delay > 0 && time_passed(&t_i2c_temp, i2c_temp_delay)) {
			//log_msg(LOG_DEBUG, "I2C sensor poll start");
			i2c_temp_delay = i2c_read_temps((struct fanpico_config*)cfg);
			//log_msg(LOG_DEBUG, "I2C sensor poll end");
		}

		/* Process any (user) input */
		while ((c = getchar_timeout_us(0)) != PICO_ERROR_TIMEOUT) {
			//log_msg(LOG_DEBUG, "character received: %02x", c);
			if (c == 0xff || c == 0x00)
				continue;
			if (c == 0x7f || c == 0x08) {
				if (i_ptr > 0) i_ptr--;
				if (cfg->local_echo) printf("\b \b");
				continue;
			}
			if (c == 10 || c == 13 || i_ptr >= sizeof(input_buf) - 1) {
				if (cfg->local_echo) printf("\r\n");
				input_buf[i_ptr] = 0;
				if (i_ptr > 0) {
					log_msg(LOG_DEBUG,"user command start");
					update_system_state();
					process_command(fanpico_state, (struct fanpico_config *)cfg, input_buf);
					log_msg(LOG_DEBUG,"user command end");
					i_ptr = 0;
				}
				continue;
			}
			input_buf[i_ptr++] = c;
			if (cfg->local_echo) printf("%c", c);
		}
		if (time_passed(&t_watchdog, 1000)) {
#if WATCHDOG_ENABLED
			log_msg(LOG_DEBUG,"watchdog update");
			watchdog_update();
#endif
		}
	}
}


/* eof :-) */

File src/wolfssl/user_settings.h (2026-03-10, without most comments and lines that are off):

#define WOLFSSL_USER_SETTINGS_H
#ifdef __cplusplus
extern "C"
{
#endif
#include <stdio.h>
#include <time.h>
#define TARGET_EMBEDDED
#define WOLFCRYPT_ONLY
#define WOLFSSL_NO_SOCK
#define WOLFSSL_WOLFSSH
#define WOLFSSL_RPIPICO
#define WOLFSSH_SMALL_STACK
#define WOLFSSH_KEYGEN
#define WOLFSSH_ALLOW_USERAUTH_NONE
#if __GNUC__ >= 15
#define WOLFSSL_HAVE_MLKEM
#define WOLFSSL_WC_MLKEM
#define WOLFSSL_NO_MAKE_KEY
#define WOLFSSL_SHAKE128
#define WOLFSSL_SHAKE256
#define WOLFSSH_NO_NISTP384_MLKEM1024_SHA384
#define WOLFSSH_NO_NISTP256_MLKEM768_SHA256
#endif
#define NO_FAILURE_ON_REJECTED
#define DEFAULT_WINDOW_SZ 4096
#define DEFAULT_MAX_PACKET_SZ 1024
#define WOLFSSL_GENERAL_ALIGNMENT 4
#define SIZEOF_LONG_LONG 8
#define SINGLE_THREADED
#define WOLFSSL_SMALL_STACK
#define WOLFSSL_USER_IO
#define SP_INT_BITS 256
#define WOLFSSL_HAVE_SP_ECC
#define WOLFSSL_SP_MATH_ALL
#undef NO_RSA
#define NO_RSA
#undef NO_DH
#define NO_DH
#undef HAVE_ECC
#define HAVE_ECC
#define ECC_SHAMIR
#define ECC_TIMING_RESISTANT
#undef NO_AES
#define HAVE_AES_CBC
#define HAVE_AESGCM
#define GCM_TABLE_4BIT
#undef NO_DES3
#define NO_DES3
#undef HAVE_CHACHA
#undef HAVE_POLY1305
#define HAVE_CHACHA
#define HAVE_POLY1305
#define HAVE_ONE_TIME_AUTH
#undef HAVE_CURVE25519
#undef HAVE_ED25519
#define HAVE_CURVE25519
#define HAVE_ED25519
#define HAVE_ED25519_KEY_IMPORT
#define HAVE_ED25519_KEY_EXPORT
#define WOLFSSL_ED25519_STREAMING_VERIFY
#undef HAVE_CURVE448
#undef HAVE_ED448
#define HAVE_CURVE448
#define HAVE_ED448
#define WOLFSSL_SHAKE256
#undef NO_SHA
#undef NO_SHA256
#undef WOLFSSL_SHA512
#define WOLFSSL_SHA512
#undef WOLFSSL_SHA384
#define WOLFSSL_SHA384
#undef WOLFSSL_SHA3
#define WOLFSSL_SHA3
#undef NO_MD5
#define NO_MD5
#undef HAVE_HKDF
#define HAVE_HKDF
#undef WOLFSSL_CMAC
#define BENCH_EMBEDDED
#define USE_CERT_BUFFERS_256
#define USE_CERT_BUFFERS_2048
#undef DEBUG_WOLFSSL
#undef NO_ERROR_STRINGS
#ifndef NDEBUG
#define DEBUG_WOLFSSL
#define DEBUG_WOLFSSH
#define DEBUG_MLKEM
#endif
#define NO_WOLFSSL_MEMORY
#undef WC_NO_HASHDRBG
#define WC_NO_HASHDRBG
#undef CUSTOM_RAND_GENERATE_BLOCK
#define CUSTOM_RAND_GENERATE_BLOCK wc_pico_rng_gen_block
#define WC_NO_HASHDRBG
#define WC_RESEED_INTERVAL (1000000)
#undef STRING_USER
#define WOLFSSL_TLS13
#define WOLFSSL_OLD_PRIME_CHECK
#define HAVE_TLS_EXTENSIONS
#define HAVE_SUPPORTED_CURVES
#define WOLFSSL_BASE64_ENCODE
#define WOLFSSL_KEY_GEN
#define NO_SESSION_CACHE
#define WOLFSSL_IGNORE_FILE_WARN
#define NO_FILESYSTEM
#define NO_WRITEV
#define NO_MAIN_DRIVER
#define NO_DEV_RANDOM
#define NO_OLD_TLS
#define NO_PSK
#define NO_DSA
#define NO_RC4
#define NO_MD4
#define NO_PWDBASED
#ifdef __cplusplus
}
#endif

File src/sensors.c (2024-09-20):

/* sensors.c
   Copyright (C) 2021-2023 Timo Kokkonen <tjko@iki.fi>

   SPDX-License-Identifier: GPL-3.0-or-later

   This file is part of FanPico.

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
   You should have received a copy of the GNU General Public License
   along with FanPico. If not, see <https://www.gnu.org/licenses/>.
*/

#include <stdio.h>
#include <string.h>
#include <math.h>
#include <assert.h>
#include "pico/stdlib.h"
#include "hardware/adc.h"

#include "fanpico.h"


/* Map of temperature sensor ADC inputs
 */
uint8_t sensor_adc_map[SENSOR_MAX_COUNT] = {
	SENSOR1_READ_ADC,
	SENSOR2_READ_ADC,
	SENSOR3_READ_ADC,
};


double get_temperature(uint8_t input, const struct fanpico_config *config)
{
	uint8_t pin;
	uint32_t raw = 0;
	uint64_t start, end;
	double t, r, volt;
	int i;
	const struct sensor_input *sensor;

	if (input >= SENSOR_COUNT)
		return 0.0;

	start = to_us_since_boot(get_absolute_time());

	sensor = &config->sensors[input];

	pin = sensor_adc_map[input];
	adc_select_input(pin);
	for (i = 0; i < ADC_AVG_WINDOW; i++) {
		raw += adc_read();
	}
	raw /= ADC_AVG_WINDOW;
	volt = raw * ((double)config->adc_vref / ADC_MAX_VALUE);

	if (sensor->type == TEMP_INTERNAL) {
		t = 27.0 - ((volt - 0.706) / 0.001721);
		t = t * sensor->temp_coefficient + sensor->temp_offset;
	} else {
		if (volt > 0.1 && volt < ADC_REF_VOLTAGE - 0.1) {
			r = SENSOR_SERIES_RESISTANCE / (((double)ADC_MAX_VALUE / raw) - 1);
			t = log(r / sensor->thermistor_nominal);
			t /= sensor->beta_coefficient;
			t += 1.0 / (sensor->temp_nominal + 273.15);
			t = 1.0 / t;
			t -= 273.15;
			t = t * sensor->temp_coefficient + sensor->temp_offset;
		} else {
			t = 0.0;
		}
	}

	/* Apply filter */
	if (sensor->filter != FILTER_NONE) {
		double t_f = filter(sensor->filter, sensor->filter_ctx, t);
		if (t_f != t) {
			log_msg(LOG_DEBUG, "filter sensor%d: %lf -> %lf\n", i+1, t, t_f);
			t = t_f;
		}
	}

	end = to_us_since_boot(get_absolute_time());

	log_msg(LOG_DEBUG, "get_temperature(%d): sensor_type=%u, raw=%u,  volt=%lf, temp=%lf (duration=%llu)",
		input, sensor->type, raw, volt, t, end - start);

	return t;
}


double sensor_get_duty(const struct temp_map *map, double temp)
{
	int i;
	double a, t;

	t = temp;

	if (t <= map->temp[0][0])
		return map->temp[0][1];

	i = 1;
	while (i < map->points-1 && map->temp[i][0] < t)
		i++;

	if (t >= map->temp[i][0])
		return map->temp[i][1];

	a = (double)(map->temp[i][1] - map->temp[i-1][1]) / (double)(map->temp[i][0] - map->temp[i-1][0]);
	return map->temp[i-1][1] + a * (t - map->temp[i-1][0]);
}
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

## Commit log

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2022-02-04 Revamped PWM and Tacho interfaces to work on fan numbers and not with pin numbers.
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2022-02-22 Fix processing relative commands.
    [command.c]
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2022-02-28 Added initial fanpico-0804 board.
    [extra_fan_channel.kicad_sch, fan_channel.kicad_sch, fan_channels.kicad_sch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]
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2022-03-07 Fix ADC pin initialization.
    [fanpico.c, fanpico.h, sensors.c]
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2022-03-10 Fix hang if no USB console connected during boot. Remove unused sensor reading code.
    [fanpico.c, sensors.c]
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2022-03-12 PCB version 1.2
    [extra_fan_channel.kicad_sch, fan_channel.kicad_sch, fanpico.kicad_pcb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]
2022-03-12 Fix delay updating output signals in response to tachometer signal change.
    [fanpico.c]
2022-03-12 Added BOM (bill of materials) for fanpico-0804.
    [bom.csv]
2022-03-19 Add new commands for configuring thermistor parameters:
    CONFigure:SENSORx:BETAcoeff
    CONFigure:SENSORx:BETAcoeff?
    CONFigure:SENSORx:THERmistor
    CONFigure:SENSORx:THERmistor?
    CONFigure:SENSORx:TEMPNominal
    CONFigure:SENSORx:TEMPNominal?
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2022-04-12 New PCB revision v1.3
    [extra_fan_channel.kicad_sch, fan_channel.kicad_sch, fan_channels.kicad_sch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]
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2022-04-23 Add new command SYStem:UPGRADE for booting Pico into BOOTSEL mode. This makes it easier to upgrade fanpico withouth having to use the pysical buttons on the board.
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2022-08-19 Cleanup schematic (no actual changes that affect PCB).
    - Add labels to sub-pages so printed schematic is more readable.
    - Rename FANx_PWM_READ to MBFANx_PWM_READ
    - Rename FANx_TACHO_GEN to MBFANx_TACHO_GEN
    - Use standard (KiCAD) footprints for the ICs (U1-U3)
    [extra_fan_channel.kicad_sch, fan_channel.kicad_sch, fan_channels.kicad_sch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]
2022-08-19 Cleanup schematic (no actual changes that affect PCB).
    [fanpico.kicad_pcb]
2022-08-31 Added initial support for multiple boards (OLED) display.
    CMake build option FANPICO_BOARD can be used to specify target board
    when building firmware. New boards can be added by adding include
    file for the board model under src/boards/.
2022-08-31 Initial status (OLED 128x64) status display working.
    - Displays all (Output) Fan RPM/PWM (duty cycle)
    - Displays all (Input) MBfan PWM (duty cycle)
    - Displays all Temperatures (C)
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2022-09-01 Add new command SYStem:DISPlay to set installed (OLED) display module type. This can be useful if auto-detection does not work, like with some SH1106 1.3" modules.
    [command.c, config.c, display.c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]
2022-09-01 Take into account that not all boards might use external temperature sensors.
2022-09-02 Place program "credits" in credits.txt that is then embedded into firmware and displayed when SYS:VER? command is issued.
    [command.c]
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2022-09-05 Add mapping for multiplexer ports when multiplexer used. Add serial console settings in board header file (0804D.h).
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2022-09-08 Add errata for the PCB v1.1
2022-09-12 Fix frequency calculation if timeout (no pulse).
    [tacho.c]
2022-09-17 Fix multiplexed tacho signal reads.
    [tacho.c]
2022-09-18 Add preliminary support for Pico W boards.
    Enable by using -DPICO_BOARD=pico_w when running cmake.
2022-09-18 Move networking (WiFi) stuff in separate network.c
    Add command SYS:WIFI? to check if board has WiFi or not.
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2022-09-25 Added CSV and JSON URLs to easilyu monitor fan statuses.
    http://x.x.x.x/status.json
    http://x.x.x.x/status.csv
    [status.csv]
2022-09-25 Fix typo in function name.
    [httpd.c]
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2022-09-26 Fix RPM display on the status page.
    [httpd.c]
2022-09-29 Switch to using "threadsafe backgroun" instead "poll" mode for networking.
    Add missing cyw43_arch_lwip_begin()/cyw43_arch_lwip_end() calls.
2022-09-29 Fix compile errors when using: -DCMAKE_BUILD_TYPE=Debug
    [fanpico.c, pulse_len.c]
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2022-09-29 Fix absolute_time_t variable initialization.
    [fanpico.c]
2022-09-30 Improve error checking when parsing commands.
    [command.c, fanpico.h]
2022-09-30 Fix measuring PWM signal duty cycle.
    Long (executing) interrupts during PWM measurement could
    result incorrect readings. Time how long measurement actually
    took to get accurate readings.
    [pwm.c]
2022-10-04 Update *RST command not to use watchdog to reset the MCU, so system won't (incorrectly) report reboot by watchdog afterwards.
    Add workaround to watchdog preventing using openocd (and picoprobe)
    to program flash, by extending watchdog timeout to 5s.
    [command.c, fanpico.c, fanpico.h]
2022-10-06 Fix Debug builds. Also disable watchdog in debug builds.
    [fanpico.c, fanpico.h, lwipopts.h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]
2022-10-07 New PCB revision v1.1 with support for direct mounting Pico or Pico W.
    [extra_fan_channel.kicad_sch, fan_channel.kicad_sch, fan_channels.kicad_sch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]
2022-10-09 Added parts list.
    [bom.csv]
2022-10-09 Update part numbers.
    [bom.csv]
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2022-10-19 Update BOMs (#11)
    * fanpico-0804/bom.csv: Add U6 (LM4040BIM3-3.0)
    ... see schematic, sheet /.
    * bom.csv files: J4 - J15 (4-pin Fan Connector): Add LCSC Part number
    https://www.lcsc.com/product-detail/Wire-To-Board-Wire-To-Wire-Connector_MOLEX-470531000_C240840.html
    * fanpico-0804/bom.csv: D9… (Schottky Diode): LCSC Part number as 0804D
    … use same data as in fanpico-0804D/bom.csv.
    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
    [bom.csv]
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2023-02-13 Fix fan tachometer reading via multiplexer.
    [tacho.c]
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2023-02-25 Hack to fix crashing on SDK 1.5.0:
    [CYW43] got unexpected packet -9
    *** PANIC ***
    sys_timeout: timeout != NULL, pool MEMP_SYS_TIMEOUT is empty
    [lwipopts.h]
2023-02-25 Fix spelling (using codespell).
    [fanpico.h, lwipopts.h, tacho.c]
2023-02-25 Display reboot and firmware upgrade information on the OLED display (if equipped).
    [command.c, display.c, fanpico.h]
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2023-03-01 Add support for specifying display brightness, inverting display, and flipping display (upside down).
    [display.c, fanpico.c]
2023-03-03 Add indicator (happy vs sad face) in web interface whether system has been rebooted by watchdog or not.
    [httpd.c]
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2023-03-12 Fix buffer overflow when input_buf fills up.
    [fanpico.c]
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2023-03-25 Fix compiling for 0804 boards.
    [display_lcd.c, display_oled.c, tacho.c]
2023-04-01 Updates to OLED display layouts and new command SYS:TIME (#32)
    * OLED (128x128): Center IP address on the screen.
    * Add new command: SYStem:TIME
    * OLED (128x64): Fix fan numbering.
    [command.c, display_oled.c, fanpico.h]
2023-04-13 Initial TLS/HTTPS tests. (#33)
    * Helper functions for reading/writing files to flash fs.
    * getstring_timeout_ms(): helper function for reading strings
    * Initial TLS/HTTPS tests.
    * Add missing tls.c
    [command.c, config.c, display_lcd.c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]
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2023-05-22 New PCB revision v1.2 for 0804D (#39)
    * Add fanpico-0804D v1.2 board revision.
    * Updated schematic and design files.
    [bom.csv, extra_fan_channel.kicad_sch, fan_channel.kicad_sch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]
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2023-08-19 Updated 0804D PCB v1.2b
    - Replace C5 with correctly derated (25V) capacitor.
    [bom.csv]
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2023-08-26 Add OLED adapter PCB.
    [fanpico-oled-adapter.kicad_pcb, fanpico-oled-adapter.kicad_sch]
2023-08-26 Fix OLED adapter PCB dimensions.
2023-10-07 Fixed bug which allowed i to be incremented past the end of the array in various functions: pwm_map(), tacho_map(), get_sensor_duty(). (#56)
    Fixed bug which allowed i to be incremented past the end of the array in various functions: pwm_map(), tacho_map(), get_sensor_duty(). This can cause fan speeds to drop to minimum when temperature of a sensor exceeds the highest value in the temperature map. For example, setting CONF:SENSOR1:TEMPMAP 25,20,50,100 would result in 0% fan speed when temperature exceeds 50C.
    [pwm.c, sensors.c, tacho.c]
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2023-12-19 Fix warning: implicit declaration of function 'setenv'
    [fanpico.c]
2023-12-28 Update SYS:MEM and add missing documentation.
    [command.c]
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2024-01-10 MQTT: fix reconnect issue and update logging. (#66)
    [fanpico.c, lwipopts.h, mqtt.c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]
2024-01-12 New 0804D PCB v1.2c (#67)
    Adds support for using either SN74AHCT125 or SN74AHCT126 as U1 and U2.
    Configured via jumpers (0 ohm resistors) on R54/R55 (for U1) and R56/R57 (for U2).
    [bom.csv, extra_fan_channel.kicad_sch, fan_channel.kicad_sch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]
2024-01-21 Add persistent RAM block and other minor fixes.
    * Add persistent RAM block to "preserve" RTC clock over soft reset
    * New command: SYS:FLASH?
    * Fix PANIC when https server responded with larger payload
    * Typo fixes.
    [command.c, fanpico.c, fanpico.h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]
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2024-03-04 Fix hang during boot if flash filesystem needed to be initialized. (#81)
    * Fix hang when no flash filesystem was found during boot.
    * Remove full path from compiler macros (like __FILE__) to slightly reduce firmware size.
    * Add new command: SYS:LFS:FORMAT
    [command.c, fanpico.c, fanpico.h]
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2024-07-26 Add new board model: 0401D (#93)
    * Add header file for new board 0401D.
    * Add initial PCB version.
    * Add new board to to workflow.
    [bom.csv, extra_fan_channel.kicad_sch, fan_channel.kicad_sch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]
2024-08-01 Add errata on 0804D v1.0 board.
    [bom.csv]
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2024-08-03 Add new "PowerBoard" PCB for using high-current fans with FanPico boards. (#97)
    [bom.csv, fanpico_powerboard.kicad_pcb, fanpico_powerboard.kicad_sch]
2024-08-10 Add ADC Vref as sensor 4 / Add timestamp to mqtt (#100)
    * Add ADC Vref as sensor 4.
    Allows the Vref to be measured and recorded as a constant for more accurate
    temperature sensor measurments.
    * Add Timestamp to mqtt messages
    for broker and consumers of the data stream to "know" how old the
    data is on the broker.
    [command.c, config.c, fanpico.h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]
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2024-08-10 Update CodeQL (#103)
    * Fix codql finding: Multiplication result converted to larger type
    * update workflow
    [sensors.c]
2024-08-12 Fix to memory leak on failed MQTT connections. (#105)
    * Fix to memory memory leak on failed MQTT connections.
    * Change MQTT topic name max length from 32 to 48 characters.
    * Update CONF:FANx:SOURCE documentation.
    [fanpico.h, lwipopts.h, mqtt.c]
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2024-08-15 Improved I2C Support and minor fixes (#110)
    * New commands:
    - SYS:I2C?
    - SYS:I2C:SCAN?
    - SYS:I2C:SPEED
    - SYS:I2C:SPEED?
    * Increase retry delay if convert emperature command fails.
    * Update uptime string layout on 128x64 displays.
    * Limit I2C bus max speed to 3.4 Mbit/s
    [command.c, config.c, display_lcd.c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]
2024-08-22 I2C Temperature Sensor Support (#111)
    * Add initial I2C Temperature Sensor support.
    * Support for new sensors:
    - ADT7410
    - DPS310
    - AHT2x (AHT21)
    - MCP9808
    - PCT2075
    - BMP180
    - BMP280
    * Update mutex logic to not wait indefinitely.
    * Update OLED display layout on 0401D
    * Update documentation.
    * Add new command: SYS:VSENSORS:SOURCES?
    * other minor fixes
    [command.c, config.c, display_oled.c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]
2024-08-24 I2C and 1-Wire Updates (#113)
    * Add support for TMP102 temperature sensor.
    * Add support for STTS22H Temperature sensor.
    * Add AS621x (AS6212/AS6214/AS6128) temperature sensor support.
    * Add AHT1x sensor support.
    * Update I2C initialization timings.
    * Skip 1-wire initialization if any device using phantom power.
    [fanpico.c, i2c.c]
2024-08-25 Add new 0401D v1.1 PCB (#116)
    [bom.csv, extra_fan_channel.kicad_sch, fan_channel.kicad_sch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]
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2024-09-20 Updates to I2C Sensor Support (#122)
    * Add support for SHTC3 Temperature and Humidity sensor.
    * Add LPS25 and LPS22 pressure sensor support.
    * Report RP2350 correctly during boot.
    * Add humidity/pressure measurement support in web interface.
    * Add support for VSENSOR in MQTT Client.
    - MEASure:VSENSORS?
    - MEASure:VSENSORx:HUMidity?
    - MEASure:VSENSORx:PREssure?
    - SYS:MQTT:INT:VSENSOR
    - SYS:MQTT:INT:VSENSOR?
    - SYS:MQTT:MASK:VTEMP
    - SYS:MQTT:MASK:VTEMP?
    - SYS:MQTT:MASK:VHUM
    - SYS:MQTT:MASK:VHUM?
    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
    [command.c, config.c, fanpico.c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]
2024-09-28 I2C Updates (#126)
    * Add support for skipping OLED panel initialization.
    * Add support for SHT4x series temperature and humidity sensors.
    * Add support for SHT3x series temperature and humidity sensors.
    * Add support for MS8607 Temperature, Pressure, and Humidity sensor.
    [display_oled.c, i2c.c]
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2024-10-21 New version of powerboard PCB. (#130)
    * Updated PCB v1.1
    [fanpico_powerboard.kicad_pcb]
2024-11-14 New FanPico-0804D PCB v1.3 (#132)
    [bom.csv, extra_fan_channel.kicad_sch, fan_channel.kicad_sch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]
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2024-12-06 Fix OLED initialization hanging on SDK 2.1.0 (#134)
    * Fix OLED initialization hanging on SDK 2.1.0
    * Disable WiFi Power Management
    [display_oled.c]
2024-12-07 WiFi updates. (#135)
    * Fix hang if no SSID configured.
    * Updates to Wifi initialization.
    * Update to latest pico-sensor-lib version.
    [i2c.c]
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2024-12-27 Fix "datetime" display on web interface. (#137)
    [httpd.c]
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2025-03-28 SNMP Trap support and minor fixes. (#147)
    * Add initial support for SNMP Traps.
    * Preserve timezone (from DHCP) over soft reset.
    * Fix clock jumping +/- 1hour randomly when certain timezones were in effect.
    [command.c, config.c, fanpico.c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]
2025-04-02 Keep track of total uptime since cold boot. (#148)
    * Keep track of total uptime since cold boot.
    * Update SYS:UPTIME? to return total uptime since last cold reset.
    [command.c, fanpico.c, fanpico.h]
2025-06-13 Updates to WiFi support (#153)
    * Automatically attempt re-joining to WiFi network on connection failure.
    * New command to manually rejoin to WiFi network: SYS:WIFI:REJOIN
    * Minor fixes and updates on network code.
    [command.c, config.c, fanpico.c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]
2025-06-17 Telnet server updates. (#155)
    * Updated to latest pico-telnetd lib version:
    - Add delay (increasing) after failed login attempts
    - Disconnect after too may failed login attempts
    * Add command ("exit") for terminating remote (telnet) connections.
    * Support for displaying active (telnet) connection status information.
    - EXIT
    - WHO?
    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
    [command.c, fanpico.h]
2025-06-19 Fix panic on boot if SNMP community string was too long. (#157)
    [config.c, fanpico.h, lwipopts.h]
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2025-07-05 Fix removing SSH password. (#165)
    [command.c]
2025-07-08 Minor updates to SSH and TLS (#166)
    * Update mbedTLS settings.
    * Log failure to load TLS certificate.
    * Remove references to wolfSSL headers (use only wolfCrypt).
    [user_settings.h]
2025-07-10 Misc updates (#167)
    - SYS:LFS:COPY
    - SYS:LFS:DEL
    - SYS:LFS:REN
    * Update libraries: pico-lfs, wolfSSH, wolfSSL
    * Minor fixes
    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
    [command.c, fanpico.h]
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2025-07-17 Fix internal temperature readings on RP2350B. (#172)
    [0401D.h, 0804.h, 0804D.h]
2025-07-22 Minor updates (#173)
    * Add SYS:BOARD? command.
    * Update network event logging priorities.
    * Fix issue where rejoin was not attempted if link state was "Link Down".
    * Clean up command processing.
    * Fix building on Pico-SDK "2.1.2-develop" branch.
    [command.c, fanpico.c, fanpico.h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]
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2025-08-02 Misc updates. (#182)
    * Fix SSH server issues on connection resets.
    * Cleanup config generation and parsing.
    * Update libraries: wolfSSH, pico-sshd, pico-telnetd
    [config.c, fanpico.h, user_settings.h]
2025-08-08 SSH and HTTP server updates. (#183)
    * Reject SSH connections after 6 failed authentication attempts.
    * Add commands to configure HTTP server settings.
    - SYStem:HTTP:SERVer
    - SYStem:HTTP:SERVer?
    - SYStem:HTTP:PORT
    - SYStem:HTTP:PORT?
    - SYStem:HTTP:TLSPORT
    - SYStem:HTTP:TLSPORT?
    - SYStem:HTTP:MASK:FAN
    - SYStem:HTTP:MASK:FAN?
    - SYStem:HTTP:MASK:MBFAN
    - SYStem:HTTP:MASK:MBFAN?
    - SYStem:HTTP:MASK:SENSOR
    - SYStem:HTTP:MASK:SENSOR?
    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
    [command.c, config.c, fanpico.c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]
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2025-11-15 FanPico-0200 support updates. (#190)
    * Add FanPico-0200 schematic and PCB kerber files.
    * Add support for boards without MBFAN ports.
    * Add support for OLED display on FanPico-0200
    [bom.csv]
2025-12-11 New PCB v1.1 for FanPico-0200 (#192)
    [bom.csv, extra_fan_channel.kicad_sch, fan_channels.kicad_sch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]
2026-02-21 Add manufacturer part numbers.
    [bom.csv]
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2026-09-16 Fix compiling on old GCC (10.3.1)
    [display_lcd.c, snmp.c]
2026-09-16 Fix buffer overflow in temp/tacho/pwm map parsing.
    [command.c]
2026-09-19 Prevent payload unknown MQTT topic getting processed.
    [mqtt.c]
2026-09-19 Fix reading past the end of buffer in CONF:x:FILTER commands.
    [command.c]
2026-09-19 Fix potential crash on upload of corrupt JSON config.
    [config.c]
2026-09-19 Stop logging full commands to avoid leaking sensitive information.
    [command.c]
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

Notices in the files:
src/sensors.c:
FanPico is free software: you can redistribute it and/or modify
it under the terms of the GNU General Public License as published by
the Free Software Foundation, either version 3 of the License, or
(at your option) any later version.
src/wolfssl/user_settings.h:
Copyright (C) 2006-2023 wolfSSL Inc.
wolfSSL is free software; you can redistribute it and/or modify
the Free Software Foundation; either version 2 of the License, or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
